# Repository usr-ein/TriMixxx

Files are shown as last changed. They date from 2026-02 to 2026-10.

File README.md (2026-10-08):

# TriMixxx

A custom DJ media player — a CDJ-style deck — built from scratch around a Raspberry Pi, designed to run [Mixxx](https://mixxx.org/) DJ software. It reuses an original Pioneer CDJ's buttons and jog wheel behind custom PCBs and a 3D-printed chassis for an authentic DJ feel, and reads Rekordbox-formatted USB sticks — no laptop required.

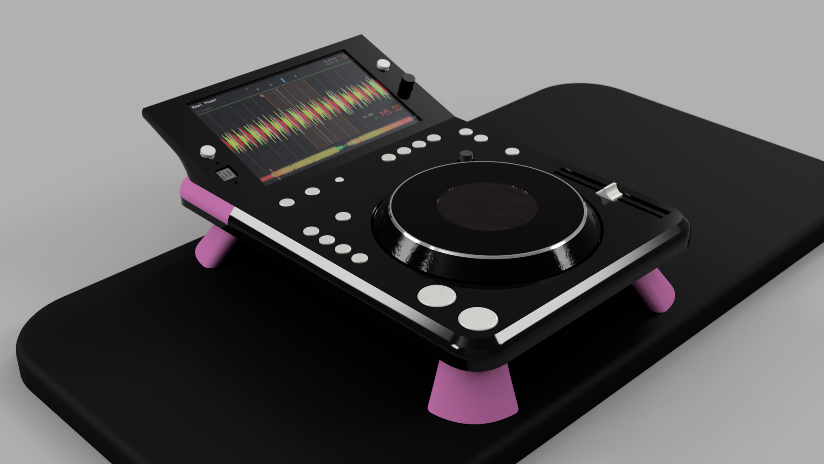
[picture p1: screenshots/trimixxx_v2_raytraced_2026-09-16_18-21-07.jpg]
TriMixxx V2 — raytraced render of the chassis

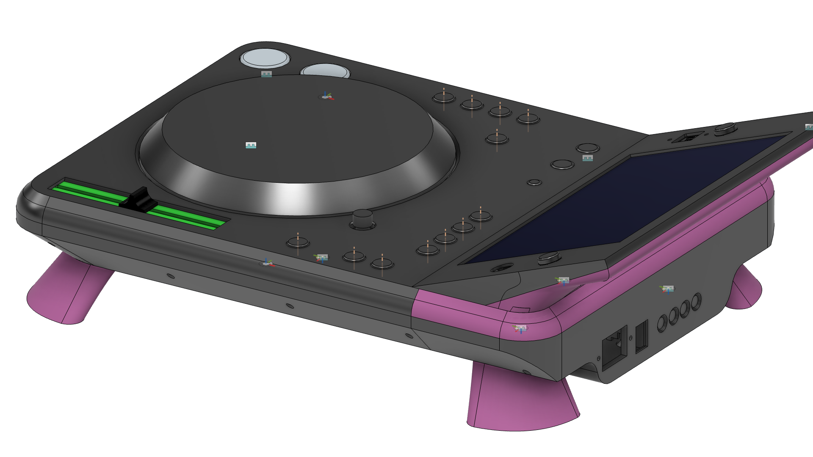
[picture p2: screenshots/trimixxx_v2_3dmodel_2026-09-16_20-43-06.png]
TriMixxx V2 — the Fusion 360 model behind it

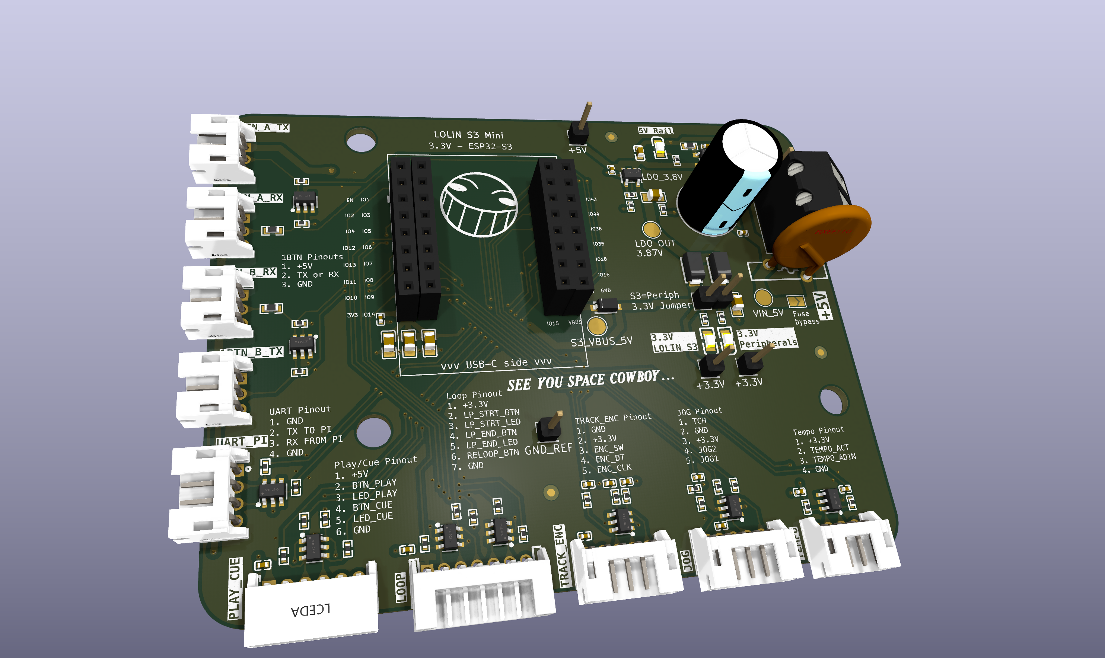
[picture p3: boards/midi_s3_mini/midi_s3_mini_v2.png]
midi_s3_mini v2 — the controller board inside


### The screen

The 1024×600 touchscreen runs a purpose-built Mixxx skin (`mixxx_config/TriMixxx_skin`). There is no mouse and no laptop: every control is either on the deck or under a thumb, so the UI is built around big targets and the browse encoder rather than around pointer precision.

| Playing | Browsing |
|---|---|
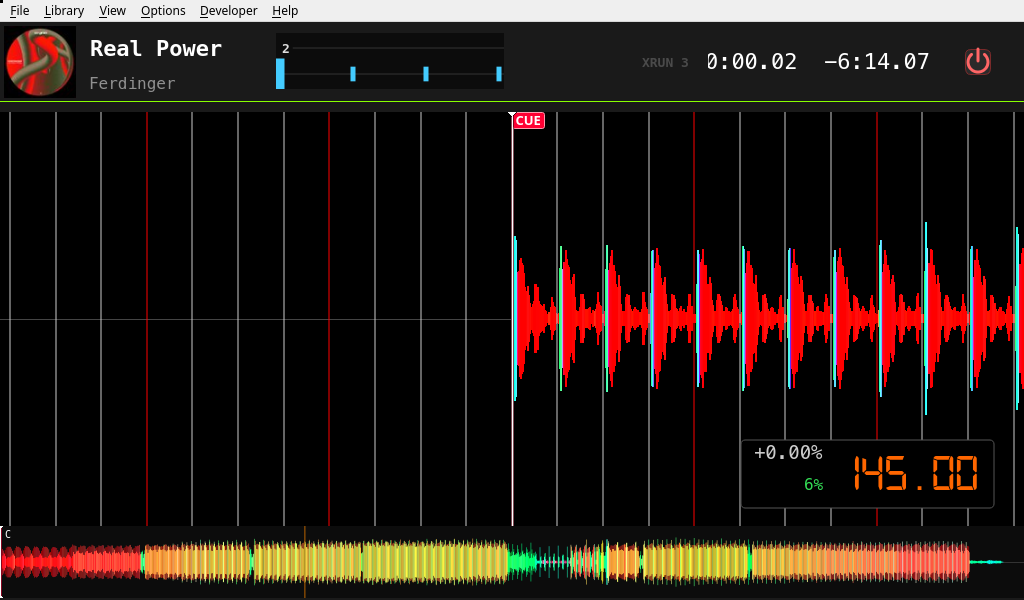
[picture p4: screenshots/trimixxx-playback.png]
Playback view
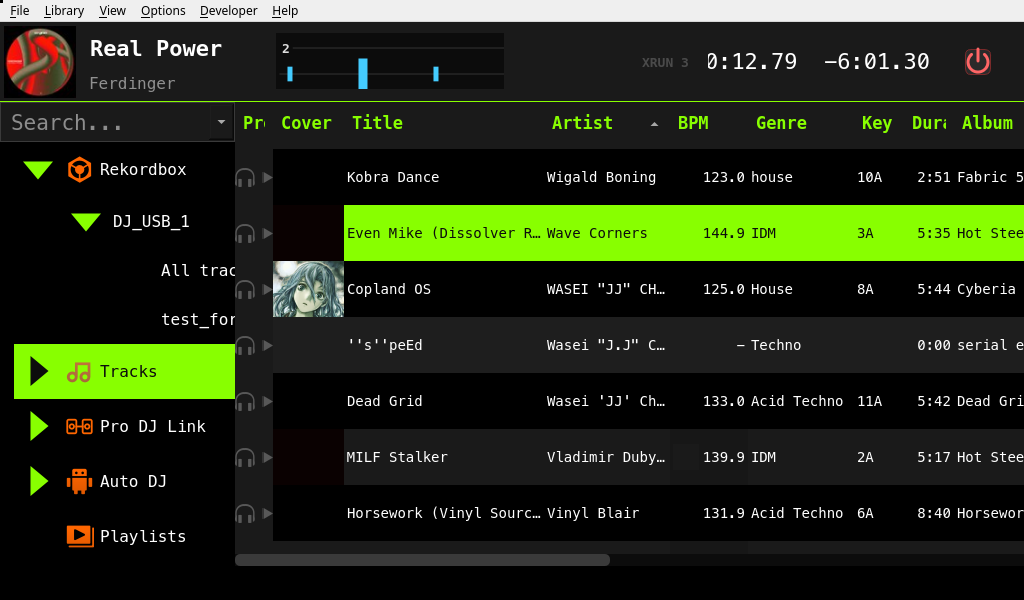
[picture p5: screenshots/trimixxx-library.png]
Library view
|  |  |
| Scrolling waveform with the beat grid, red downbeats anchored on the intro cue, and the whole-track overview underneath. Tempo and pitch sit bottom-right; the header carries artwork, title/artist, the phase meter, elapsed/remaining and the underrun counter. | Rekordbox USBs, the local collection and the Pro DJ Link players lead the menu — the three a deck actually reaches for. The left column sizes itself to its content and follows the selection, and neither pane has a scrollbar: the encoder scrolls them. |

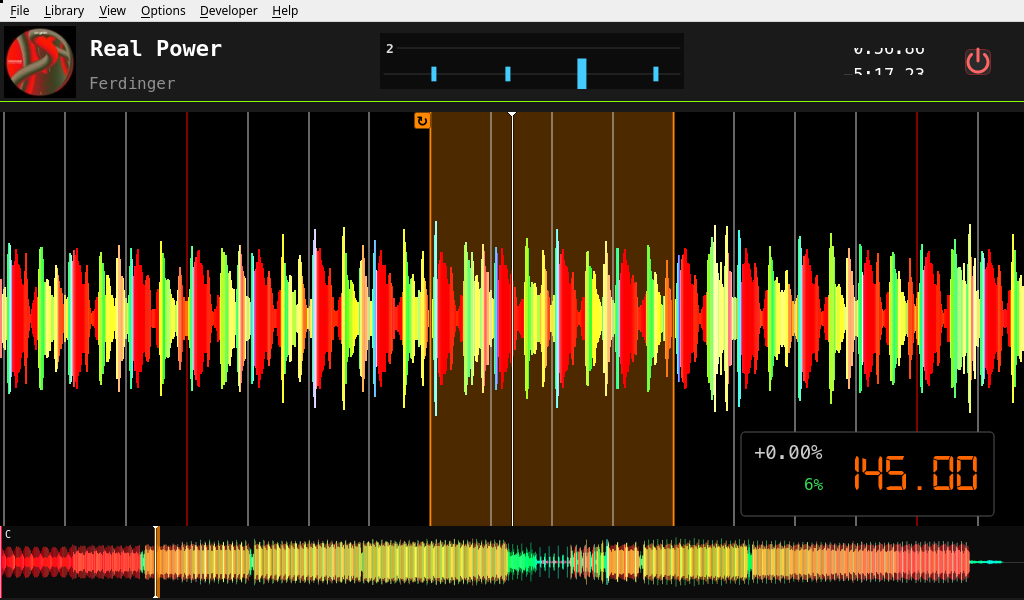
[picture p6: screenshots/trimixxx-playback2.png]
Loop over the waveform


An active loop, set from the deck's hardware loop-in/out buttons, drawn as an amber window over the waveform. Nothing sits below it — the transport, hotcues, loop sizing and tempo range are all physical controls, so the screen gives that space back to the waveform.

## What is this?

TriMixxx replaces the internals of a Pioneer CDJ with modern, open-source-friendly hardware while keeping the physical controls that DJs know and love. Plug in a Rekordbox-formatted USB stick, and you're ready to mix.

Where the CDJ's original main board did everything, TriMixxx today is a **small distributed system**: a Raspberry Pi runs a patched Mixxx behind a custom CDJ-style skin, an ESP32-S3 acts as the controller brain that reads every physical control and speaks MIDI, and a swarm of tiny satellite boards handle the buttons and the LED rings. They all talk over plain TTL UART.

It is a working deck, not a plan: the Pi boots straight into Mixxx, the USB stick automounts, the S3's controls drive it, and Mixxx's feedback drives the LEDs back. Alongside that, `prolinks-compat/` has reverse-engineered Pioneer's ProLink protocol far enough that a real CDJ-2000NXS browses and plays tracks served by this project.

## How we got here (a short history)

This project has been through several complete redesigns. It's worth keeping the lineage straight:

1. **One board to rule them all.** The first idea was a single monolithic PCB carrying *everything*: a Raspberry Pi CM5, a TI PCM5242 I²S DAC with RCA + headphone outputs, USB-C PD power (CH224K + SY8368AQQC buck), dual micro-HDMI, the USB stick ports, and an **ATmega32U4** presenting the CDJ's buttons/jog/fader to the Pi as a USB-MIDI device — all on one board. It was fully routed (`screenshots/CDJ-MainBoard-v1_fully_routed.png`, and the `*_2026-02-17.png` schematic captures) but never became the working unit; cramming compute, audio, power, and a controller onto one board made every revision expensive and every mistake fatal.

2. **Breaking it apart.** The controller was split out onto its own board. `boards/midi-laser-pcb` was the first standalone MIDI-controller PCB — it was fabricated, then abandoned in favour of a cleaner design.

3. **Where it is now.** `boards/midi_s3_mini` is the current controller board (fabricated), hosting a **LOLIN S3 Mini (ESP32-S3)**. The audio DAC and power delivery are no longer TriMixxx's job — a Raspberry Pi handles Mixxx and audio directly, and the S3 is purely the controller brain. The controls are spread across small purpose-built satellite boards, all of them already fabricated.

The old monolithic design is preserved in this README's history and in `screenshots/` as a record of the road not taken.

## Current architecture

```mermaid
flowchart LR
    subgraph PiBox["Raspberry Pi (deck)"]
        Mixxx["Mixxx (patched fork)<br/>+ TriMixxx skin"]
        Tty["ttymidi<br/>trimixxx-bridge.service"]
        Daemon["trimixxx-launchd<br/>(launch manager +<br/>SysEx to the OS)"]
        Usb["dj-usb automount<br/>/media/DJ_USB_*"]
        Doom["Doom (1993)<br/>hold PLAY at boot"]
        Keys["trimixxx-deckkeys<br/>MIDI -> /dev/uinput"]
    end

    S3["midi_s3_mini<br/>LOLIN S3 Mini / ESP32-S3<br/>(controller brain)"]
    RingA["OneButton ring A<br/>CH32V003 nodes<br/>button + 2xWS2812 each"]
    RingB["OneButton ring B<br/>CH32V003 nodes"]
    PlayCue["play_cue_btn<br/>Play / Cue + LEDs"]
    Loop["loop_btn<br/>Loop In/Out/Reloop + LEDs"]
    Jog["Jog wheel<br/>quadrature + touch"]
    CDJ["Real CDJs<br/>(ProLink, Ethernet)"]

    Mixxx <--> Tty
    Mixxx <-->|SysEx| Daemon
    Usb --> Daemon
    Daemon -->|"picks the boot mode"| Mixxx
    Daemon -->|"picks the boot mode"| Doom
    Daemon --> Keys
    Tty -->|"deck buttons"| Daemon
    Tty -->|"deck buttons"| Keys
    Keys -->|"virtual keyboard + mouse"| Doom
    Tty <-->|"UART - raw MIDI - 3.3V"| S3
    S3 <-->|"UART1 - OneButton ring - 5V"| RingA
    S3 <-->|"UART2 - OneButton ring - 5V"| RingB
    S3 --> PlayCue
    S3 --> Loop
    Jog --> S3
    Mixxx -.->|"prolinks-compat (research)"| CDJ
```

- **Raspberry Pi 4B (4 GB)** runs Mixxx — specifically [our own fork](https://github.com/usr-ein/mixxx) (the `mixxx/` submodule), branched off the 2.5.6 tag and carrying deck-specific patches. [`ttymidi`](https://github.com/usr-ein/ttymidi) turns the UART link into an ALSA MIDI device, so Mixxx sees TriMixxx as a standard MIDI controller. That link is 3.3 V on both ends (Pi GPIO ↔ S3), so no level shifting is needed.
- **midi_s3_mini (ESP32-S3)** is the controller brain. It reads every physical control, translates it to MIDI for the Pi, and drives LEDs from the MIDI feedback Mixxx sends back. It runs `firmwares/trimixxx-midi`.
- **Two OneButton rings** hang off the S3, one per UART (A on UART1, B on UART2). Each is a daisy chain of up to 50 CH32V003 nodes, every node carrying one button and two WS2812 LEDs. Nodes enumerate themselves at boot, so a ring self-sizes to however many boards are actually populated (7 and 6 today). See [The OneButton Protocol](#the-onebutton-protocol) below.
- **play_cue_btn** and **loop_btn** are dumb button+LED satellite boards (no MCU) wired to the S3.
- The **jog wheel** (optical quadrature encoder + capacitive touch) wires directly into the S3, decoded by the ESP32's hardware pulse counter (PCNT).

### Signal chain: pressing Play

A worked example of what happens end-to-end, from copper to Mixxx. Every other button on the deck follows the same path.

**Press.** The switch closes and shorts the on-board 100 nF debounce cap to ground, so the GPIO (held high by the S3's internal pull-up) falls low over the RC's time constant — the buttons are active-low. `buttonPollTask` on core 1 samples the pin every `BTN_POLL_MS` = 2 ms and needs `DEBOUNCE` = 3 consecutive stable samples before it accepts the edge, so the RC's slow ramp and any contact bounce are both ignored (~6 ms to accept). Polling is deliberate here rather than an edge interrupt, which slow RC edges tend to upset on the ESP32. On accepting the edge, `poll()` updates the debounced `level` and sets a **sticky press latch**, so the press can't be missed even if the main loop stalls. The main loop (`CTRL_POLL_MS` = 2 ms) calls `playCue.pressed()`, which consumes the latch, and `btnToNote()` hands it to `PiLink`, which writes a Note-On (note `0x3C`, velocity 127) to UART0 at 115200 baud. `ttymidi` on the Pi turns those raw MIDI bytes into an ALSA MIDI event; Mixxx matches `0x3C` in `TriMixxx.midi.xml` and calls `TriMixxx.play`, which toggles the deck's `play` control.

**Held.** Nothing repeats. The sticky latch fires exactly once per press; `btnToNote` keeps a `pending` flag so it knows a Note-Off is still owed. Meanwhile Mixxx sends `play_indicator` back on the same note `0x3C` — `pi.poll()` runs every main-loop pass (no 2 ms gate, for the lowest LED latency) and drives the button's LED from that feedback, so the LED reflects Mixxx's actual state rather than the button's.

**Release.** The switch opens, the pull-up recharges the cap through the RC, and the pin rises. The poll task sees 3 stable high samples, clears `level`, and the next main-loop pass sees `pending && !held` and sends the Note-Off. Mixxx's `TriMixxx.play` ignores value 0, so the release is a no-op there — it just keeps the On/Off pairing well-formed on the wire.

### MIDI map

All MIDI addresses live in one place — `firmwares/trimixxx-midi/lib/PiLink/MidiMap.hpp` — and the Mixxx mapping (`mixxx_config/TriMixxx.midi.xml`) matches them exactly. One deck (v1) → MIDI channel 1.

| Control | MIDI | Mixxx |
|---|---|---|
| Ring A pads (node *i*) | Note `0x00 + i` | Tempo range, keylock, 8/4-beat loops, loop double/halve, back |
| Ring B pads (node *i*) | Note `0x43 + i` | Hotcues 1–4, slip, key-sync indicator |
| Play / Cue | Notes `0x3C` / `0x3D` | `play` (toggle) / `cue_default` |
| Loop In / Out / Reloop | Notes `0x3E` / `0x3F` / `0x40` | `loop_in` / `loop_out` / `reloop_toggle` |
| Track encoder | Note `0x41` (press) + CC `0x10` (relative: 1=up, 127=down) | Browse + load |
| Jog wheel | Note `0x42` (touch/scratch) + CC `0x11` (relative ticks) | Scratch when touched, pitch bend otherwise |
| Tempo fader | CC `0x12` MSB + CC `0x32` LSB (14-bit absolute 0..16383, 8192 = center) | `rate` |

Both pad ranges reserve 50 notes even though fewer nodes are populated today, so growing a ring never renumbers anything.

The tempo fader follows the standard MIDI 14-bit convention — the LSB rides on `MSB + 32` (18 + 32 = 50 = `0x32`) — and Mixxx binds the pair to `[Channel1] rate` with `<fourteen-bit-msb/>` / `<fourteen-bit-lsb/>`. The extra resolution is worth the second CC: a single 7-bit CC would quantise the whole pitch range to 128 steps. The fader is read ratiometrically (wiper minus a live center-tap reference) so the center detent lands on 8192 without calibration.

LED feedback comes back on the same notes. A Note-On velocity only sets *white* brightness, so full RGB travels as SysEx instead — `F0 7D <cmd> <node> <colour nibbles> F7`, with each 8-bit channel split into two data bytes so a 7-bit SysEx payload can still express 0..255 per channel (`0x01` = ring A, `0x03` = ring B). `0x02` reboots the S3, and requires the magic `"RST"` so a stray SysEx can't reset the deck mid-set.

## Boards

All KiCad projects live under `boards/`. Every board below has been fabricated.

| Board | Role | MCU | Status |
|---|---|---|---|
| `midi_s3_mini` | Controller brain: reads all controls, MIDI bridge to the Pi, drives LEDs, jog-wheel input | LOLIN S3 Mini (ESP32-S3) | **Current** |
| `one_button` | Ring node: one button + 2× WS2812, cut-through UART relay. Every node is identical. | CH32V003F4U6 | **Current** |
| `play_cue_btn` | Play + Cue buttons with LEDs (driven by the S3) | none | **Current** |
| `loop_btn` | Loop In/Out/Reloop buttons with LEDs (driven by the S3) | none | **Current** |
| `midi-laser-pcb` | First standalone MIDI-controller board | — | Fabricated, **abandoned** (superseded by `midi_s3_mini`) |

## Firmwares

| Firmware | Runs on | What it is |
|---|---|---|
| `trimixxx-midi` | midi_s3_mini (ESP32-S3) | The master. PlatformIO/Arduino. Reads both OneButton rings + jog wheel + deck controls and bridges them to the Pi as MIDI. Master of both rings. |
| `onebutton` | one_button ring nodes (CH32V003) | Bare-metal [ch32fun](https://github.com/cnlohr/ch32fun). `onebutton_node` (the identical binary every ring node runs) and `onebutton_selftest` (single-board bring-up). |
| `swio-adapter` | A spare Pro Micro | Turns an Arduino into a `minichlink` SWIO programmer for flashing the CH32V003 nodes — no dedicated programmer needed. Git submodule. |
| `ArduinoMIDI` | (historical) | Early ATmega-based MIDI + jog-wheel test sketches from the monolithic-board era. |

Every driver in `trimixxx-midi` is written and live: both rings, jog wheel, tempo fader, track encoder, play/cue board and loop board. A single `DECK_DEBUG` switch at the top of `main.cpp` swaps the MIDI loop for each module's own self-test.

## The OneButton Protocol

The button rings run a purpose-built **cut-through UART ring protocol**. A single fixed-length frame, authored by the S3 master, circulates once around the ring and returns carrying every node's button state; LED colours travel outward on the same frame. Each node forwards bytes as they arrive, editing only the bytes in its own slot, so latency scales as `frame_time + N·byte_time` rather than `N·frame_time`. Node addresses are assigned positionally at boot, so all nodes run an identical binary with no per-unit configuration.

Full wire format, timing, and failure model: **[`firmwares/onebutton/onebutton-protocol.md`](firmwares/onebutton/onebutton-protocol.md)**.

## The Pi side

The deck's software is split into four pieces, each with its own README:

| Piece | What it is |
|---|---|
| `mixxx/` (submodule) | **Our Mixxx fork.** Forked at 2.5.6, carrying deck patches: downbeat highlighting in the waveform (`DownbeatColor` skin node), Rekordbox beat-grid phase preserved via the intro cue, and a `[Rekordbox], refresh` control so a stick mounted mid-set can be picked up from a script. Built for arm64 in Docker and installed over SSH. |
| `mixxx_config/` | Everything under `~/.mixxx`: the controller mapping (`TriMixxx.midi.xml` + `.scripts.js`), the `PiMidiDaemon` mapping, `soundconfig.xml`, and `TriMixxx_skin/` — a single-deck CDJ-style skin for the 1024×600 touchscreen. Its deploy step, `pi-qemu/deploy/005_config.sh`, validates every XML *before* anything leaves the machine, because Qt silently falls back to the default skin on a malformed one. |
| `pi_config/` | The system side: `trimixxx-bridge.service` (ttymidi, ordered before Mixxx so the MIDI port exists when Mixxx enumerates devices), `cpu-governor.service` (the `performance` governor — `ondemand` was the measured cause of xruns while scratching), the session entry points (`bash_profile`, `xinitrc`) that start whichever app the launch manager chose, and `dj-usb/` (udev + systemd read-only automount of DJ sticks). |
| `trimixxx-launcher/` | Two small Go daemons. **`trimixxx-launchd`** does the things Mixxx cannot — its script engine has no file, process or network access, so **MIDI is the only channel out**, and the daemon takes SysEx commands (shutdown, reboot, switch mode) and reports events back (a DJ stick was mounted). It is also the **launch manager**: it reads the deck's own buttons at boot and decides what the deck becomes. **`trimixxx-deckkeys`** replays the deck's MIDI into `/dev/uinput` as a virtual keyboard and mouse. Both ship as fully static musl binaries, so there is nothing to install on the Pi. |
| `doom/` | **The deck plays DOOM (1993).** Hold PLAY while it boots. The jog wheel turns, the tempo fader is the throttle, ring A is the seven weapons. Doom itself is a stock `chocolate-doom` — the controls arrive as a virtual keyboard and mouse, so there is no engine fork here to maintain. |

## ProLink compatibility

`prolinks-compat/` reverse-engineers Pioneer's proprietary **CDJ ProLink** Ethernet protocol so TriMixxx can share libraries with real CDJs on the same network. It is a substantial subproject in its own right — a Python proof-of-concept plus a written specification — and both directions now work against real hardware (two CDJ-2000NXS):

- **Consume:** discover players passively, then pull a deck's `export.pdb` over NFS and list its tracks. The fetched database is byte-identical to the same file read off the physically ejected stick.
- **Serve:** a real CDJ-2000NXS sees us on its LINK screen, browses all eleven categories with drill-downs, sorting, search and harmonic key matching, and **loads and plays tracks** (MP3, AAC, WAV, AIFF) with artwork, hot cues and both waveforms. The last browse session was 568 requests with zero errors.

The protocol as observed is written up in [`prolinks-compat/docs/PROTOCOL.md`](prolinks-compat/docs/PROTOCOL.md), with the evidence behind every claim in `docs/FINDINGS.md` and current state in `STATUS.md`. The end goal is to port the validated approach into Mixxx (C++/Qt) and upstream it.

## Chassis

Designed in Fusion 360 to fit the original CDJ form factor — a custom top panel with cutouts for the jog wheel, buttons, and connectors, plus a bottom tray. `ref_sizes/` holds the measured references (CDJ-1000MK3 / 2000NXS2 / 3000 dimensions, jog wheel, screen) the design is built from.

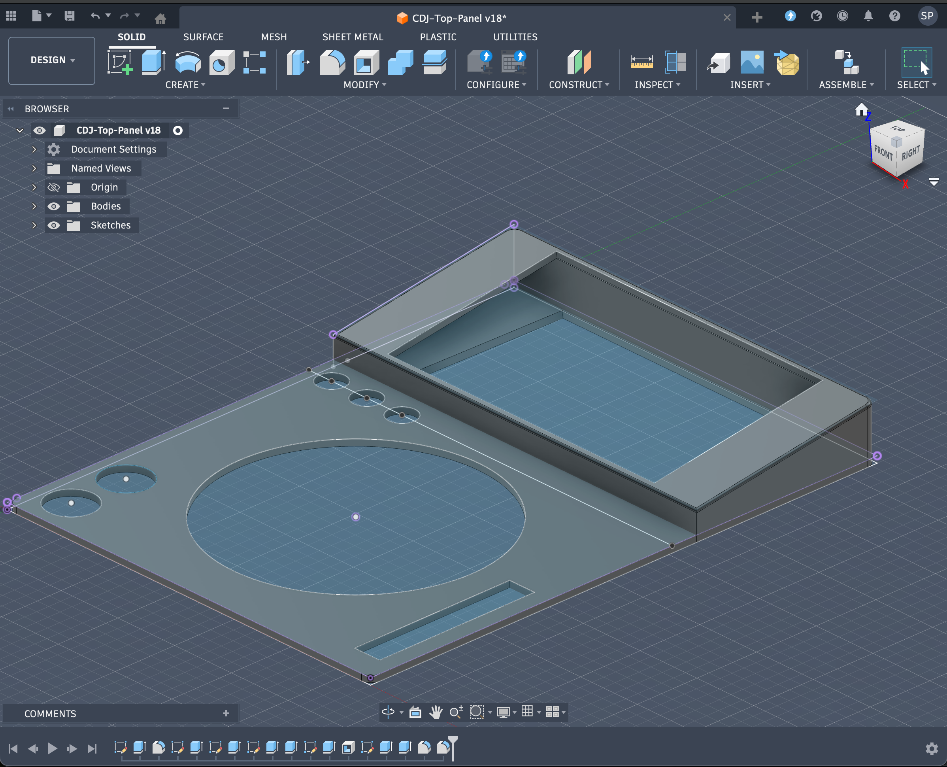
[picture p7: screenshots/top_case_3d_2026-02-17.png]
Top case 3D render


## Repository structure

```
boards/                     KiCad PCB projects
├── midi_s3_mini/               Current controller board (ESP32-S3)
├── one_button/                 OneButton ring node (CH32V003)
├── play_cue_btn/               Play + Cue buttons
├── loop_btn/                   Loop buttons
└── midi-laser-pcb/             Abandoned first controller board

firmwares/                  Embedded firmware
├── trimixxx-midi/              S3 master (PlatformIO / Arduino)
├── onebutton/                  Ring node + selftest (ch32fun)
├── swio-adapter/               CH32V003 SWIO programmer (submodule)
└── ArduinoMIDI/                Historical ATmega sketches

mixxx/                      Our Mixxx fork -- the build the deck runs (submodule)
mixxx_config/               ~/.mixxx: mapping, scripts, skin, sound config
pi_config/                  Pi system config: systemd units, udev, USB automount
trimixxx-launcher/          Go daemons: boot-mode launch manager, SysEx <-> OS,
                            and the MIDI -> virtual keyboard/mouse bridge
doom/                       DOOM (1993) on the deck: WAD, engine config, wrapper

prolinks-compat/            Pioneer ProLink protocol research + Python PoC
ch32fun/                    ch32fun toolkit (submodule)
handmade_pcb/               Hand-etched PCB experiments
datasheet/                  Datasheets for the parts used
ref_sizes/                  Measured CDJ dimensions the chassis is built from
screenshots/                Renders + schematics (incl. the monolithic-board history)
```

## Tools used

- **KiCad** — schematic capture and PCB layout
- **PlatformIO** + **Arduino** — ESP32-S3 firmware
- **ch32fun** — bare-metal CH32V003 firmware and `minichlink` flashing
- **Fusion 360** — mechanical design
- **JLCPCB** — PCB fabrication and assembly
- **Go**, **Python** (`uv`) — Pi daemon and ProLink proof-of-concept

## Trademarks and affiliation

TriMixxx is an independent project with **no affiliation with, sponsorship by, or endorsement from AlphaTheta Corporation** (formerly Pioneer DJ) or the Mixxx project.

**CDJ**, **rekordbox**, **Pro DJ Link**, **DJM**, **NXS/nexus** and **Pioneer DJ** are trademarks of AlphaTheta Corporation. They appear here only to refer to that company's own products — which hardware this project interoperates with, which protocol it speaks, and which units the chassis was measured against. **Mixxx** is the name of the independent open-source project at [mixxx.org](https://mixxx.org/); "TriMixxx" is this project's own name and is not a Mixxx project product.

The ProLink work in `prolinks-compat/` is reverse engineering for **interoperability**, from observation of network traffic between devices the author owns. Protocol facts are not copyrightable, and no code from any reference implementation is copied — see `prolinks-compat/research/10` for the working discipline.

## License

Copyright (C) 2026 Samuel Prevost and contributors.

TriMixxx is free software: you can redistribute it and/or modify it under the terms of the **GNU General Public License version 3** or (at your option) any later version. The full text is in [`LICENSE`](LICENSE). This covers everything in the repository — firmware, host software, hardware sources and documentation alike — except:

- **`prolinks-compat/`**, which is **GPLv2-or-later** on purpose, so it stays compatible with Mixxx and can be upstreamed. GPLv2-or-later code may be used under GPLv3, so this is compatible with the rest of the project; see `prolinks-compat/LICENSE`.
- **Submodules** (`mixxx/`, `ch32fun/`, `firmwares/swio-adapter/`, `mixxx_config/ttymidi/`, the Keebio libraries), which keep their own upstream licenses.

---

## Appendix: the monolithic board (historical)

The original single-board design is no longer built, but its details are recorded here for posterity. It centred on a **Raspberry Pi CM5** (dual DF40 100-pin connectors), a **TI PCM5242** I²S DAC feeding RCA + 6.35 mm + 3.5 mm outputs, an **ATmega32U4** USB-MIDI controller reading all the CDJ controls, USB-C PD power (**CH224K** negotiating 20 V @ 3 A, **SY8368AQQC** buck to 5 V, **AP2112K** LDOs), dual micro-HDMI, gigabit Ethernet, and the USB stick ports (**HD3SS3220**/**HD3SS3212** muxing, **USBLC6-2SC6** ESD protection) — roughly 160 components on one PCB.

### Schematics

| Sheet | File |
|---|---|
| Audio outputs (DAC, RCA, headphones) | `screenshots/audio_2026-02-17.png` |
| MIDI / ATmega controller | `screenshots/midi_arduino_2026-02-17.png` |
| Power delivery (USB-C PD, buck, LDOs) | `screenshots/power_delivery_2026-02-17.png` |
| USB ports (mux, ESD) | `screenshots/usb_2026-02-17.png` |
| Fully routed PCB | `screenshots/CDJ-MainBoard-v1_fully_routed.png` |

### SPICE simulations

- DAC output (PCM5242): `screenshots/dac_spice.png`
- Buck converter (SY8368AQQC): `screenshots/buck_converter_spice.png`

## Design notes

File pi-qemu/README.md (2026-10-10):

# pi-qemu: the TriMixxx tool

`pi-qemu` is the one tool for TriMixxx decks, emulated and real:

- **Emulated decks.** It runs a deck's SD card on an emulated Raspberry Pi 4
  (QEMU's `raspi4b`, accelerated by Apple's Hypervisor framework), booting the
  real Raspberry Pi OS card with the real deck software: Mixxx, ttymidi, the
  launcher and the panel session. You get the Pi's 1280x800 screen in a window
  (click and drag like the touchscreen), and a control panel standing in for
  the deck's S3 board. The panel sends MIDI to the Pi's UART exactly as the
  real S3 does.
- **Any deck.** It drives a deck from the command line, emulated or real: its
  controls, its touchscreen, its screen, Mixxx's recorder, a shell. Scripts
  and AI agents use the same commands.
- **Deploying.** It puts the repo's code onto a deck, step by numbered step
  (`deploy/NNN_*.sh`).
- **Cards and releases.** It builds a deck's card from stock Raspberry Pi OS,
  and the locked A/B release card with its updates over the air.

The emulated deck is called **trimixxx0**: a virtual trimixxx2, wired by
`mixxx_config/units/trimixxx0.json`. Why things are built the way they are is
in [PLAN.md](PLAN.md).

```sh
pi-qemu help                  # the groups: deck, link, image, release, worktree
pi-qemu deck                  # a group's verbs
pi-qemu deck up --help        # one verb, in full
```

Every verb that acts on a deck names it, as its **TARGET**: an emulated
deck's NAME (`pi-qemu deck list`), or `--host ALIAS` for a real deck by its
ssh alias. There is no default deck: nothing reaches a real deck unless it is
named.

A real deck on the Mac's switch is reached over Ethernet too, much faster
than over Wi-Fi: `pi-qemu deck alias --host trimixxx-pi` writes
`trimixxx-pi-eth` into `~/.ssh/config`, by its eth0's IPv6 link-local
address through the Mac's wired interface, and `--host trimixxx-pi-eth`
then takes that link.

## What is in here

| Path | What it is |
|---|---|
| `build.sh` | builds the pinned, patched QEMU and `pi-qemu`, and puts `pi-qemu` on PATH |
| `app/` | `pi-qemu` itself (C++/Qt), one directory per part under `app/src/`: `board/` (the emulated Pi: the firmware step, QEMU, USB sticks, its link, its control socket), `s3/` (the deck's controller: MIDI both ways, the wiring), `ui/` (the windows), `decks/` (a deck to act on, emulated or real), `pipeline/` (deploying, image builds, releases), `cdj/` (emulated CDJs), `worktree/`, `cli/` (the command line), `util/`; and `tests/` (ctest) |
| `app/icons/` | its icon: `trimixxx.svg`, and the `.ico` compiled in, made from it by `make-ico.py` |
| `qemu/trimixxx-patches.py` | our patches to QEMU, applied by `build.sh` |
| `deploy/` | the deploy steps, `NNN_name.sh` and `NNN_name.pi.sh`, and their contract, `lib.sh` |
| `image/` | the stock card's pin (`stock.env`), its first-boot seed (`user-data.in`, `network-config`), and `secrets.env` (gitignored; `secrets.example.env` is the template) |
| `release/` | the release container (`Dockerfile`, `container.sh`) and the release card's parts |
| `.cache/` (gitignored) | images, built cards, the golden snapshot, decks' identities, USB stick images |

## Setting up a laptop

On an Apple Silicon Mac:

```sh
brew install qemu mtools cmake ninja qt python@3.12 dtc   # QEMU's deps, mtools for FAT, Qt for the app
pi-qemu/build.sh             # ~10 min the first time: QEMU 11.1.0 + patches, dtmerge, then pi-qemu
cp pi-qemu/image/secrets.example.env pi-qemu/image/secrets.env   # then set SAM1902_PASSWORD
```

`build.sh` puts `pi-qemu` on PATH as `~/.local/bin/pi-qemu` (from the main
checkout; a worktree's own build is run by its path). `build.sh app` builds
`pi-qemu` alone, with its tests.

You also need Docker Desktop running (the deck's arm64 binaries are Docker
builds) and the ssh key the cards trust: `~/.ssh/no_pass/rsa_sam`, else
`~/.ssh/with_pass/rsa_sam` (in the agent: `ssh-add`), or `SSH_KEY=` pointing
at another one. Its public half goes onto the card at build time.

Then build the card. Most of the time goes to apt and the Docker builds of
the deck's binaries; the base stage is cached for later runs:

```sh
pi-qemu image build              # -> pi-qemu/.cache/build/trimixxx0.img (+ the golden snapshot)
```

A window shows the build as it goes: its steps, a progress bar and the log
(`pi-qemu build-log pi-qemu/.cache/build/trimixxx0.log`, the log it writes).
`release build` opens one too, for the whole release. `--no-window` (or
`BUILD_WINDOW=0`) opens none.

## Running your deck

Your own deck is an emulated deck like any other, with windows:

```sh
pi-qemu deck up sam --window     # restored from the golden snapshot in ~3 s
pi-qemu deck ssh sam
```

Two windows open: the Pi's screen and the control panel. Log in on the
console as `sam1902` with the password from `image/secrets.env`, or use
`deck ssh`. `deck up sam --from CARD` boots a card of your own instead.

**Sound is off unless you ask for it.** `pi-qemu deck up sam --window --
--audio speakers` plays the deck's output on the Mac. `-- --audio
wav:/abs/path/out.wav` records it to a file instead, which is how to check
audio without hearing it. Whatever follows `--` goes to `pi-qemu run`, the
board itself (`pi-qemu run --help` lists its options):

| Option | |
|---|---|
| `--audio none\|speakers\|wav:FILE` | the deck's sound output (default none: silent) |
| `--display window\|vnc\|none` | the Pi's screen; screenshots work in every mode |
| `--stick FILE.img` | a USB stick image plugged in from power-on |
| `--deck NAME` | whose wiring the panel follows (`mixxx_config/units/NAME.json`) |
| `--ssh PORT` | the Pi's ssh on 127.0.0.1:PORT (default: a free port) |
| `--link NET` | eth0 on the link NET, shared with other boards (`deck up --link` sets it, and `--name`, `--mac`) |

### The panel

- **Controls tab**: the deck's controls, laid out as on trimixxx2.
  - **Pads:** loop and loop-length pads across the top; SLIP, SORT and the four
    hot cues left of the platter; CUE and PLAY / PAUSE under them.
  - **Right of the platter:** BACK, the browse encoder (drag up or down to turn,
    click to push), TEMPO RANGE, MASTER TEMPO and the tempo fader.
  - **Jog wheel:** drag the inner disc to scratch (touch), drag the rim to
    bend, or scroll on it to nudge.
  - **Pad behaviour:** shift-click a pad to latch it down. The lamps and pads
    light from what Mixxx sends back.
- **S3, power, USB sticks tab**:
  - the S3 link light;
  - Power on, and Pull the plug (no shutdown, like the mains switch);
  - the sound mode;
  - every USB storage device on the Mac, and every image and `.stick` file
    in `.cache/sticks/`, each with Insert / Unplug (two slots, read-only).

### Driving it from the command line

Everything the panel does, `pi-qemu deck` does too, on any deck: an emulated
one through its virtual S3, a real one (`--host ALIAS`) straight into the MIDI
port Mixxx opened for the deck's controller. The bytes are the same either
way, on the deck's wiring, so they run the real mapping and scripts.

```sh
pi-qemu deck press sam play          # press and release (80 ms; `press sam cue 500` holds it)
pi-qemu deck down sam cue; pi-qemu deck up sam cue
pi-qemu deck jog sam 3240            # a quarter turn clockwise (12960 ticks per turn)
pi-qemu deck touch sam on            # the platter's touch sensor, for scratching
pi-qemu deck browse sam -3           # the track encoder; + is up
pi-qemu deck tempo sam center        # the fader, 0..16383; 8192 (center) is the middle
pi-qemu deck midi sam 90 3C 7F       # raw bytes, as the S3's
pi-qemu deck shot sam shot.png       # the screen: QEMU's own (emulated), scrot (real)
pi-qemu deck tap sam 640 400         # the touchscreen, with xdotool: also longpress, swipe, flick, key, where
pi-qemu deck record sam 10 mix.wav   # Mixxx's own recording of its main mix, fetched
```

Control names: `tempo-range keylock loop8 loop4 loop-double loop-halve back
hotcue1..4 slip sort play cue loop-in loop-out reloop push jog-touch`. They
follow the deck's wiring, so `press sam hotcue1` sends whatever note
trimixxx0's hot cue 1 is on.

An emulated deck also has its board:

```sh
pi-qemu deck leds sam                # what the deck's lights show now, as JSON
pi-qemu deck stick sam list          # stick sam insert SAM3 | stick sam unplug SAM3
pi-qemu deck status sam              # the Pi, the S3 link, its wiring, its ports
pi-qemu deck power sam off           # pull the plug; power sam on
pi-qemu deck save sam FILE           # the whole machine to FILE, then off
pi-qemu deck console sam 'ip -br a'  # over the serial console, when ssh is down
```

### Where things are

An emulated deck lives in `~/.pi-qemu/instances/NAME/` (kept short on
purpose: macOS caps unix socket paths at 104 bytes): `card.img`, `state`
while it is suspended, `ssh_config` and `bin/` (plain `ssh`/`scp` reaching it
as NAME and as `deck`: `eval "$(pi-qemu deck env NAME)"`), `pi-qemu.log`, and
the board's run directory, `card.run/`:
- `qemu.cmd`: the exact QEMU command, to rerun by hand;
- `qemu.log`, and `qemu.pid` while it runs;
- `console.log`: the Pi's serial console, from the first kernel line;
- `ssh.port`;
- the sockets `control.sock` (what `pi-qemu deck` talks to), `console.sock`
  (the Pi's console: `nc -U console.sock`), `qmp.sock` and `qmp-fd.sock`
  (QEMU's monitor) and `s3.sock` (the S3's UART).

A deck on a link also has `link` in its directory (the link's name), and its
socket on the link is `~/.pi-qemu/links/NET/NAME.sock`.

Inside the Pi:
- Mixxx logs to `/tmp/mixxx/mixxx.log` and `/tmp/mixxx/stderr.log`; the
  previous run's are kept as `.1`;
- its settings are in `~/.mixxx/`;
- the launcher's log is `journalctl -u trimixxx-launchd`.

## Several decks at once

Emulated decks run side by side, for people, agents and tests. Each one has
its own copy of the card, ssh port, ssh alias and control socket. They are
headless and silent unless asked.

```sh
pi-qemu deck up mine                 # restored from the golden snapshot in ~3 s
pi-qemu deck ssh mine 'pgrep -a mixxx'
pi-qemu deck deploy mine config      # this checkout's code onto it; waits for the new Mixxx
pi-qemu deck ready mine              # wait until Mixxx runs, its sound and controller open
pi-qemu deck stop mine               # suspend: saved, next `up` ~3 s
pi-qemu deck rm mine                 # gone, card and all
pi-qemu deck list
```

`up --window` shows its screen and panel. `up --boot` boots it instead of
restoring it (~7 s to ssh). `up --fresh` starts again from the golden
snapshot, and `up --from CARD` boots a card of your own, of any size: the
instance's copy is rounded up to the power of two QEMU's SD card needs, and
stays sparse. `down` powers it off cleanly, `kill` pulls the plug (its QEMU
too, even if pi-qemu was killed outright).

The emulated board starts as a Pi 4 does, measured on a real one
(PLAN.md, phase 1):
- **The boot partition.** `autoboot.txt` picks it, with `[tryboot]` on a
  trial. With no `autoboot.txt`, it's the first FAT partition holding a
  `start.elf`. A guest's `reboot N` asks for a partition.
- **A trial (tryboot).** It's armed by
  `sudo systemctl reboot --reboot-argument="0 tryboot"` or
  `sudo vcmailbox 0x00038064 4 0 1`, used once, and forgotten at a power-off.
  A guest reboot pauses QEMU so pi-qemu can read it.
- **`config.txt`.** It takes `[boot_partition=N]`, `[partition=N]` and
  `[tryboot]`.
- **`/proc/device-tree/chosen/bootloader`** has the real firmware's values:
  `partition`, `tryboot`, and the rest.
- **`kernel_watchdog_timeout`** leaves the watchdog running, so a start that
  hangs before systemd resets the board.

Each emulated deck takes 2 GB of RAM; four at once is about the limit on a
16 GB Mac.

## Decks on one network: Pro DJ Link

Decks started on the same **link** have their eth0s on one network, as the
players in a booth share a switch. They see each other over Pro DJ Link,
browse each other's media, and load and play each other's tracks. A deck on
no link (the default) has its eth0 on a cable to an empty switch, so other
people's and agents' decks never meet yours.

```sh
pi-qemu deck up a --link booth --window    # a: player 4 on link booth
pi-qemu deck up b --link booth --window    # b: player 3 (it saw a holding 4)
pi-qemu deck stick a insert SANDISK-E02C   # a rekordbox stick into deck a...
pi-qemu deck press b push                  # ...is a source in b's library: "4 <its label>"
pi-qemu link devices booth                 # who announces what, heard from the Mac
```

- **On a link, each deck is a device of its own.** Its eth0 MAC comes from
  its NAME (`02:54:4d:..`), so it gets its own link-local address and claims
  its own player number, as a real deck does. `up` waits for that number and
  says it: `b: player 3 at 169.254.237.243, 02:54:4d:f0:62:70 on link booth`.
- **A restored deck is a clone until then.** Every deck wakes from the golden
  snapshot with the same MAC, address and player number. So it wakes with its
  cable out, takes its own MAC, waits for Mixxx to let go of the golden
  deck's address, and only then is plugged in: nothing on the link ever hears
  the clone. A booted deck (`--boot`, `--from`) has its own MAC from the start,
  through the device tree, and after every reboot.
- **The link stays with the deck** through `stop` and `up`, until
  `up NAME --link OTHER` (or `--link none`) on a stopped deck.
- **Decks can start together** (`deck up a --link booth & deck up b --link booth &`).
  Restored decks take turns on a link: each is plugged in and claims its
  number only once the one before it has (`b: waiting for the deck before
  it...`). A Mixxx whose Pro DJ Link library is new enough also settles two
  players claiming one number at the same moment by address (lib/prolink).
- **A deck that comes up unbrowsable gets its Mixxx restarted once.** An
  observer (a player number outside 1-4, as 7) can be neither browsed nor
  browse; a Pro DJ Link library from before its rebind fix could end up one
  when its address changed. `up` says so when it happens.
- `deck link NAME` says what the deck announces and who else is on its
  link. `deck link NAME unplug` pulls its cable (frames stop, and the Pi sees
  its link go down), and `plug` puts it back.

From the Mac, without touching any deck:

```sh
pi-qemu link list                       # every link, and the decks on it
pi-qemu link devices booth              # the players announcing themselves: number, name, address, MAC, deck
pi-qemu link capture booth booth.pcap   # every frame into a pcap until ^C, for Wireshark or `prolink pcap`
```

**How it works** (`app/src/board/link.*`). A link is a directory,
`~/.pi-qemu/links/NET/`, with one Unix datagram socket per deck on it,
`NAME.sock`. Each deck's QEMU gets one end of a socketpair as GENET's network
(`-netdev dgram,local.type=fd`); the deck's `pi-qemu run` holds the other end
and forwards: the frames its Pi sends go to the other decks' sockets, and
theirs to its Pi. It learns which deck has which MAC, as a switch does, and
floods broadcasts and unknown MACs. A deck never hears its own frames back,
and nothing leaves the Mac: the sockets are files, not ports. QEMU's own
multicast hub (`-netdev dgram` to a group) cannot send on macOS: it binds the
group's address, which BSD refuses to send from.

## Emulated CDJs

A CDJ-2000NXS on Pioneer's own firmware (1.44), emulated by the
`cdj2000-emulator` submodule and joining the decks' links. ProLink can then
be debugged without the booth: a TriMixxx deck with "real" CDJs, and the
CDJs with each other. `docs/cdj-emulator.md` says why it is built this way.

Once per Mac, and once per checkout:

```sh
pi-qemu cdj build                              # this checkout's emulator: ~1.5 min the first time
pi-qemu cdj firmware ~/Downloads/C2KNXS.UPD    # Pioneer's updater, extracted outside every checkout
```

- **The firmware** is Pioneer's, given to the NXS's owners: never in a
  repository. `firmware` checks every CRC and checksum, and writes what the
  emulator boots into `~/.pi-qemu/cdj/firmware/nxs/`.
- **`build`** fetches QEMU once, at the revision the emulator's patches
  take, into `~/.pi-qemu/cdj/`, and builds it into the submodule's ignored
  `build/`. It also builds the GUI core and a venv for the emulator's tools.
  In a worktree, the submodule is the main checkout's, which
  `pi-qemu worktree prepare` borrows.

A CDJ, and a booth:

```sh
pi-qemu deck up d --link booth
pi-qemu cdj up a --link booth          # ~25 s: "a: player 1 at 169.254.x.y, 02:43:44:.. on link booth"
pi-qemu cdj up b --link booth          # player 2: the NXS numbers itself AUTO
pi-qemu link devices booth 10          # 1 a, 2 b, 4 d
pi-qemu cdj shot a a.png               # its 480x234 screen
pi-qemu cdj press a link               # a panel key: play, cue, link, usb, sd, enter, back, menu, ...
pi-qemu cdj rotary a 2                 # the browse encoder
pi-qemu cdj window a                   # its screen and panel, lit as its firmware lights it
pi-qemu cdj lamps a                    # those lamps, by name: {"PLAY_PAUSE": "blink", "MASTER": "3", ...}
pi-qemu cdj status a                   # the emulator's own: the browser's last reply, the frame, ...
pi-qemu cdj rm a
```

- **A CDJ is booted, never restored.** Its player screen is up in about
  8 s, and `up` waits for it, then on a link for its first keep-alive. One
  with no player screen in 120 s is stopped, its logs left in
  `~/.pi-qemu/cdj/NAME/` until `cdj rm`.
- **On a link it is a member of its own,** as a deck is. Its MAC comes from
  its name, `02:43:44:..`, and the NXS takes its link-local address from
  the MAC's last two bytes.
- **Give `link devices` 10 s with a CDJ on the link.** A CDJ re-claims its
  number every few seconds with a TriMixxx deck present, as a real one did
  in `mixxx/lib/prolink/captures/S10-serve-to-cdj`, so its keep-alives come
  up to ~5 s apart.
- **Media:** `--sd IMG` / `--usb IMG` mount a FAT32 image, and its writes are
  thrown away. `--test-track` makes a card with a 10 s WAV on it. To make
  an image from a rekordbox stick, copy the stick to a folder first (never
  hand the emulator the stick itself: a CDJ writes its history to it), then
  `python -m tools.cdj_main.make_sd_image FOLDER IMG --size 4G` in
  `cdj2000-emulator/` with its venv (`.venv/bin/python`): a few seconds.
- **Playing a track: `--dsp-model`.** By default the CDJ runs Pioneer's DSP
  code, interpreted, which cannot decode in real time: a loaded track does
  not play. `--dsp-model` runs the emulator's behavioural DSP instead. It
  executes none of the DSP's code and makes no sound, and keeps the track's
  position on the CDJ's clock, so a track plays in real time and its beat
  packets come at its tempo.
- **Its window** (`cdj window NAME`, or `cdj up NAME --window`): its
  screen, live, in a schematic of the NXS's top panel, in the deck panel's
  look.
  - **Every key `cdj press` knows is a pad** in its place. A click holds it
    for as long as the mouse is down, and at least as long as a `press`.
    Shift-click latches it.
  - **The selector:** drag or scroll it to turn it, click it to push.
    Keyboard: space is PLAY, C CUE, up and down turn the selector, return
    pushes it, backspace is BACK.
  - **The TEMPO fader:** drag it; minus is at the top, as on the deck, and
    a double-click puts it back on its centre. The CDJ's own screen shows
    the tempo it took.
  - **The DIRECTION lever and the SD lid** are switches: a click flips them.
    They, and the fader, start as the CDJ has them.
  - **The pads light as the CDJ's firmware lights its lamps:** what MAIN
    sends the panel, which the emulator decodes (`cdj lamps`). The sources,
    the browse keys, SYNC, MASTER and LOOP MODE glow dimly while available.
  - **Not here:** the jog, which is not emulated (only its touch is).
  - **Closing it leaves the CDJ running.** The CDJ stopped, it closes, and
    it lets go of any key it held down.
  - **A key left down** (a window that crashed, or was killed with -9):
    open the window again and click the key once.
  - **A window and the command line share the CDJ:** the emulator's control
    channel takes several connections at once.
- **Its state** is in `~/.pi-qemu/cdj/NAME/`: `cdj.json`, the `cdj run`
  behind it (`pid`, `pi-qemu.log`), its socket on the link (`link.sock`),
  the emulator's run directory (`run/`, the last one kept as `run.prev`),
  and its window's `window.pid` and `window.log` while one is open.
- **Real time.** A CDJ runs at a real one's speed by the wall clock: its
  start-up, keep-alives (every 2.0 s) and status packets keep a real NXS's
  timing (`docs/cdj-emulator.md`, "Real time"). With every core of the Mac
  busy, its keep-alives slip to 2.1-3.2 s while that lasts.
- **Limits.** A CDJ takes about two cores (one with `--dsp-model`). Two
  CDJs and a deck take about five of a twelve-core Mac. There is no audio
  and no jog, and a CDJ stops after a day.

**How it joins a link** (`app/src/board/streamport.*`). `cdj up` starts
`pi-qemu cdj run` detached; it is the emulator's parent.
- It holds the CDJ's member on the link, through the same `Link` as a
  deck's.
- It listens on `link.sock` for the emulator's NIC: a QEMU stream netdev,
  `nxs_vm --link-hub unix:...`, whose frames are each a 32-bit length and
  then the frame.
- It moves them between that stream and `Link`'s datagram end.
- When the emulator exits, `cdj run` leaves the link.

## Deploying

`pi-qemu deck deploy TARGET [STEP...]` puts this checkout's code onto a deck,
emulated or real, by the numbered steps in `deploy/`, all of them in order
when none are named:

| Step | What |
|---|---|
| `000_base.pi.sh` | pi_config/fresh-install.md 1–2: boot flags, ssh, background load, packages, autologin |
| `001_ttymidi.sh` | the serial<->MIDI bridge (`mixxx_config/ttymidi`), built in Docker |
| `002_system.sh` | `pi_config`: systemd units, session, splash, eth0, the Wi-Fi fallback, dj-usb |
| `003_launcher.sh` | `trimixxx-launcher`: boot modes, SysEx daemon, deck keys, built in Docker |
| `004_mixxx.sh` | the Mixxx fork, built in Docker, over apt's binary |
| `005_config.sh` | `mixxx_config`: mapping, skin, fonts, mixxx.cfg, this deck's wiring |
| `006_library.sh` | Mixxx's music library directory, once |
| `007_doom.sh` | Doom |

A step is named as `mixxx`, `004` or `004_mixxx`, and a new step is the next
number. `deploy/lib.sh` has their contract:
- a `.sh` step runs on the Mac and reaches the deck as `ssh deck`; a `.pi.sh`
  step runs on the deck, as root;
- each is idempotent: run again, it changes nothing where nothing changed
  (a binary that is the same is left alone);
- its exit status says what follows: a step that changed the boot flags has
  the deck reboot before the next one; one that restarted the MIDI bridge or
  the launcher has the session restarted at the end, since Mixxx opens their
  ports only at its start. After a session restart, `deploy` waits until
  Mixxx is ready.

Steps that build in Docker need ~6 GB free on its disk: `deploy` checks
first, and leaves freeing space to you.

## Cards and releases

`pi-qemu image build [DECK]` makes a deck's card from the stock image
(`image/stock.env`):
1. seeds cloud-init: user, key, password hash, hostname (`image/user-data.in`,
   `network-config`);
2. boots it as an emulated deck of its own, `build-DECK` (`deck ssh build-DECK`
   reaches it while it builds);
3. runs every deploy step over it;
4. seals it into `.cache/build/DECK.img`, and for trimixxx0 refreshes the
   golden snapshot.

Everything up to and including `000_base` is cached in `.cache/base/` while
its inputs stay the same (`--rebuild-base` forces it).

The cards the decks run from, read-only and updated A/B over the network,
come from such a build (PLAN.md Part 1, and [rauc-pi-4-setup.md](rauc-pi-4-setup.md)):

```sh
pi-qemu release build                # HEAD's pi/vX.Y.Z tag -> release/out/X.Y.Z/: the card, the bundle
pi-qemu release card trimixxx2       # trimixxx2's card: the release card with its identity on p7
pi-qemu deck ship --host trimixxx-pi-2   # the update onto a deck running a release card
pi-qemu deck prepare --host trimixxx-pi-2 trimixxx2   # before a deck's first release card
```

## Git worktrees

Several agents (or people) can work at once, each in a git worktree of the
repo, each deploying its own code to its own emulated deck. The root
`CLAUDE.md` is the workflow agents follow. Behind it:

- **`pi-qemu worktree prepare`** sets up the worktree's submodules, which
  start as empty directories. `mixxx/` (and its `lib/prolink`) and
  `mixxx_config/ttymidi` become linked worktrees of your main checkout's
  submodule repositories, detached at the commits the worktree's branch
  records. So does `cdj2000-emulator/`, the emulated CDJs', when the branch
  records it and the main checkout has it
  (`git submodule update --init cdj2000-emulator` there gives it one). It takes seconds and downloads nothing. A branch made in a
  worktree's `mixxx/` is a branch of your main `mixxx/` at once, so merging it
  there is enough. `git submodule update` would instead clone a private copy
  that is deleted with the worktree.
- **Every checkout builds Mixxx in its own Docker build tree** (keyed by
  `mixxx/checkout-id.sh`). A tree builds from its own copy of the sources,
  which `mixxx/tree-sync.sh` updates by content before each build. ninja then
  recompiles exactly what changed since that tree's last build, whatever git
  did to the files' dates. A worktree's first build starts from a copy of the
  main checkout's tree.
  - A worktree's first Mixxx deploy takes about 75 s, later ones about 45 s.
  - Builds queue on the shared compiler cache, so only one Mixxx compiles at a
    time: two agents deploying at once measured 87 s and 138 s.
  - Each tree takes about 4 GB of Docker's disk.
- **`pi-qemu worktree release`**, before removing a worktree, empties its
  Docker build trees and removes its submodule worktrees. Until then git
  refuses to remove a worktree with checked-out submodules, short of
  `--force`, which leaves the build trees behind. `release` refuses itself if
  they hold uncommitted changes, or commits no branch has.
  - A submodule that is a clone of its own, as `git submodule update` makes,
    is taken back too, once its origin has all of its commits and it holds
    no stash.
  - Its git directory is in the worktree's `modules/`, which `release`
    removes, since git will not remove a worktree with it.
  - `release` also refuses while a CDJ runs from the worktree's emulator:
    `cdj rm` it first.
  `pi-qemu worktree status` shows what a worktree has checked out.

pi-qemu acts on the checkout it runs in: `deck deploy` from a worktree
deploys that worktree's code, and runs `prepare` itself. The built QEMU, the
caches, the golden snapshot and the releases are the main checkout's,
whichever checkout pi-qemu runs in.

## Snapshots

`pi-qemu deck save NAME FILE` pauses the Pi, writes the whole machine (RAM and
every device) to FILE, and stops it. `pi-qemu run --restore FILE CARD` brings
that machine back in about 3 seconds, Mixxx already running. Rules:

- **The card must be the one it was saved with, unchanged.** After the
  restore, the card moves on and the snapshot no longer fits it.
  `deck up` and `deck stop` do this for you: a saved machine is used once,
  and is gone the moment it starts.
- **The same devices.** No USB sticks inserted when saving (`save` refuses),
  and the same `--net` mode. `--audio` and `--display` may differ.
- **Same Mac architecture.** Some devices are saved in host byte order.
- The Pi wakes up with the clock it was saved with. `deck up` sets it to
  now; by hand, use `ssh ... "sudo date -u -s @$(date -u +%s)"`.

The **golden snapshot** (`.cache/golden/trimixxx0.img` + `.state`) is the
built card, booted until Mixxx has its sound device open, then saved. Every
new emulated deck starts from it. `image build trimixxx0` refreshes it at the
end of the build; `deck golden [CARD]` makes it from any card.

Making QEMU's `raspi4b` savable took patches 8–13 in
`qemu/trimixxx-patches.py`. The USB sound card and USB network adapter had no
saved state. The PCIe root port and GENET silently had none, so a restored Pi
lost its USB controller. USB devices forgot their configuration, and xHCI
without MSI-X could not be loaded. Each patch says why.

Patches 14–16 made the emulated SD card fast. It moved one byte per call
through the card model and one 512-byte block per image access, which gave
about 4 MB/s. It now reads at ~800 MB/s and writes at ~400 MB/s, which is
what took a boot from ~50 s to ~5 s. No real card is that fast. The emulator
is for testing the software, not the deck's timing.

## Workflows

### Test a Mixxx change on the emulated deck

```sh
pi-qemu deck up mix
pi-qemu deck deploy mix mixxx         # Docker arm64 build, swaps /usr/bin/mixxx, waits for the new Mixxx
pi-qemu deck ssh mix 'tail -50 /tmp/mixxx/mixxx.log'
pi-qemu deck shot mix /tmp/after.png
```

The build goes by content. Every checkout has its own build tree in Docker's
cache, with its own copy of the sources, and recompiles exactly the files
whose content changed since that tree's last build. `tree-sync: N change(s)`
in the output says how many. A changed file or two deploys in about 45 s.
The main checkout's first build in this layout compiles everything (~25 min
at the 4 jobs Docker's memory allows); after that, builds only redo what
changed.

### Test a config, skin or mapping change

```sh
pi-qemu deck deploy mix config        # mapping, skin, fonts, mixxx.cfg; ~10 s with the restart
pi-qemu deck press mix hotcue1
pi-qemu deck leds mix
pi-qemu deck ssh mix 'sudo grep ^0: /proc/tty/driver/ttyAMA'   # rx: bytes the S3 sent
```

`deploy mix system` (pi_config: systemd units, session, splash),
`launcher` and `ttymidi` work the same way, on a real deck too
(`--host ALIAS`).

### Play a track from a USB stick

```sh
pi-qemu deck stick mix list          # images in .cache/sticks/ and the Mac's USB disks
pi-qemu deck stick mix insert SAM3   # SAM3.img: a rekordbox export, read-only
pi-qemu deck press mix push          # the encoder push opens the library...
pi-qemu deck browse mix 2; pi-qemu deck press mix push   # ...then moves and activates
pi-qemu deck shot mix pick.png       # see where you are
pi-qemu deck press mix play; pi-qemu deck leds mix       # "play": true
```

An image of a real stick, with the same layout as the original (MBR, FAT32),
as `.cache/sticks/SAM3.img` was made:

```sh
cd pi-qemu/.cache/sticks
hdiutil create -srcfolder /Volumes/SAM3 -volname SAM3 -fs FAT32 -layout MBRSPUD -format UDTO -size 256m SAM3
mv SAM3.cdr SAM3.img
```

### A folder as a stick, with nothing copied

A folder on the Mac goes in as a FAT32 stick made up on the fly: a copy of
a DJ's stick on an external drive, say, however big. Nothing is copied and
the folder is only ever read. pi-qemu builds the stick's directories and FATs
in memory when it goes in, then hands the Pi each file's bytes as it reads
them, through QEMU's NBD client (`app/src/board/fatvolume.*`, `nbdserver.*`).
The Pi sees a real USB disk, so udev, dj-usb and Mixxx's own checks all run
as they would on the deck.

```sh
pi-qemu deck stick mix insert /Volumes/Drive/DJ-stick-copy   # a folder: MBR, FAT32, sized to fit
pi-qemu deck stick mix insert SANDISK                        # .cache/sticks/SANDISK.stick
```

A `.stick` file (JSON) says how the stick was laid out. Every key but
`folder` is optional, and relative paths are from the `.stick` file:

```json
{
  "folder": "/Volumes/BIGBOY2/TriMixxx-USB-dumps/SanDisk-E02C-5D1B/files",
  "superfloppy": true,
  "size": 123048296448,
  "volumeStart": "/Volumes/BIGBOY2/TriMixxx-USB-dumps/SanDisk-E02C-5D1B/sda-first-31MiB-bootsector-and-FATs.raw",
  "bytesPerSecond": 3700000
}
```

| Key | What it does |
|---|---|
| `superfloppy` | no partition table: the filesystem starts at sector 0, as some sticks have it |
| `partitionStart` | where the FAT32 partition starts, in sectors (default 2048) |
| `size` | the disk's size in bytes (default: what the files need, plus a quarter) |
| `volumeStart` | a raw copy of a real stick's filesystem start (`{"file": F, "offset": N}`, or just `F`): its reserved sectors are served as they were (boot code, serial, label, dirty flag), and the FATs, FSInfo and directories are laid out to match |
| `mbr` | a real stick's first sector, partition table included |
| `label`, `serial` | the volume label, and the serial blkid reports as the UUID (`"E02C-5D1B"`) |
| `clusterKiB` | the cluster size (default: mkfs.fat's for the size) |
| `bytesPerSecond` | reads no faster than this, like a slow stick (a USB 2 Cruzer Blade: `3700000`); see "A slow stick" |
| `readsPerSecond` | and no more reads a second than this, small or large (what makes a cheap stick's small reads slow too) |

Names go onto the stick NFC, as rekordbox's sticks have them: macOS hands a
folder's accented names back decomposed, and serving those as they come would
make a stick no deck has ever seen. A file of 4 GiB or more, or two names that
differ only in case, cannot be on a FAT32 stick, and the insert says so.

### A slow stick, and what the deck reads off it

Every stick reads through a QEMU throttle group of its own, so any stick --
a folder, an image, the Mac's own -- can be made as slow as a real one, and
its speed changed while it is in:

```sh
pi-qemu deck stick mix speed SANDISK 4M        # 4 MB/s, a cheap USB 2 stick
pi-qemu deck stick mix speed SANDISK 4M/300    # ...and 300 reads a second
pi-qemu deck stick mix speed SANDISK full      # as fast as it goes
pi-qemu deck stick mix list                    # an inserted stick shows its speed
```

A speed set before the stick goes in applies from its first read; one set
while it is in takes effect at once (QMP `qom-set` on its group's `limits`).
Sticks really do vary that much: a Cruzer Blade gave 3.7 MB/s, a SanDisk 3.2
on USB 3 well over 100.

For a folder stick, pi-qemu also counts what the Pi reads, file by file:
what a browse reads, what a load reads, and what was read that nobody asked
for:

```sh
pi-qemu deck stick mix reads SANDISK           # since it went in, or the last reset
pi-qemu deck stick mix reads SANDISK reset     # the same, then start counting again
```

```text
139.3 MB in 3612 reads over 46.4 s (3.0 MB/s on average), from 1102 files and regions
   80.4 MB     643 reads  /Contents/Zoe/UnknownAlbum/Zoe - Transient Shift.wav
   58.3 MB     466 reads  /Contents/FAÏG/South West EP/FAÏG - South West EP - 03 Deep Within.aiff
    0.3 MB     598 reads  FAT
```

### Check the audio without hearing it

```sh
pi-qemu deck record mix 10 /tmp/mix.wav    # Mixxx's main mix, recorded by Mixxx; make it play first
pi-qemu deck up snd -- --audio wav:/tmp/out.wav    # or everything the sound card plays, for a new deck
python3 - <<'EOF'
import wave, struct
w = wave.open('/tmp/out.wav'); n = w.getnframes(); d = w.readframes(n)
s = struct.unpack('<%dh' % (n * w.getnchannels()), d)
print('seconds', n / w.getframerate(), 'peak', max(map(abs, s)))
EOF
```

A tone that does not need Mixxx: stop the session with
`sudo systemctl stop getty@tty1` (that also frees the sound card), then run
`timeout 3 speaker-test -D plughw:0,0 -c 1 -r 44100 -t sine -f 440`. That is
one tone on both channels; `-c 2` plays left, then right. To bring Mixxx back:
`sudo systemctl start getty@tty1`.

### The deck will not come up

```sh
cat ~/.pi-qemu/instances/NAME/card.run/console.log    # the boot, from the first kernel line
pi-qemu deck console NAME 'systemctl --failed' 'journalctl -b -p err | tail'
pi-qemu deck shot NAME now.png
```

If ssh hangs as soon as QEMU starts, a Mac firewall (Little Snitch, or macOS's
own with stealth mode) may be holding QEMU's network sockets. Allow
`qemu-system-aarch64`.

### Rebuild the card after changing the deck's setup

```sh
pi-qemu image build                   # reuses the cached base; refreshes the golden snapshot
```

Running decks keep their own cards; `deck up NAME --fresh` takes the new one.

## Troubleshooting

- **`... has a passphrase and is not in the ssh agent`**: `ssh-add` the key
  pi-qemu names (after every reboot of the Mac).
- **`QLocalServer::listen: Name error`**: a unix socket path longer than 104
  bytes. Use a shorter card path; instances live in `~/.pi-qemu` for this reason.
- **The window does not take your keys**: click into it. A window opened from a
  background process may not get focus.
- **Docker "no space left"**: check with `docker run --rm --pull never debian:trixie df -h /`.
  `docker buildx prune -f --all --filter type=regular --filter until=90m` frees
  space and keeps the compile caches.
- **A restore fails with "Unknown section" or similar**: the snapshot was made
  by a QEMU built from different patches. Remake it with `pi-qemu deck golden`.
- **`deploy` says Docker's disk is full**: see `docker system df`. Unused
  images (`docker image prune -a`) are usually most of it.

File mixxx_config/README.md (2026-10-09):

# TriMixxx S3 — Mixxx controller mapping

Everything that lives under `~/.mixxx` on the deck. The S3 firmware sends raw MIDI
over UART → `ttymidi` on the Pi → ALSA → Mixxx sees a standard MIDI device. These
files map that device to Mixxx controls. Addresses match the firmware's
[`lib/PiLink/MidiMap.hpp`](../firmwares/trimixxx-midi/lib/PiLink/MidiMap.hpp) exactly — **change both together.**

The system side (systemd units, udev, USB automount) is in
[`../pi_config`](../pi_config); the config deploy step
([`../pi-qemu/deploy/005_config.sh`](../pi-qemu/deploy/005_config.sh)) touches
only `~/.mixxx`, the per-user font directory `~/.local/share/fonts` and every
deck's rendering for a release card (`/usr/share/trimixxx/decks`), and restarts
Mixxx, so a mapping tweak can never disturb the deck's system config.

## Files
- `TriMixxx.midi.xml` — the deck mapping (inputs, LED outputs).
- `TriMixxx.scripts.js` — scripting for the jog (scratch/bend), the browse
  encoder, play toggle, the ring buttons and their RGB LED indicators, and the
  startup rainbow-wave animation.
- `PiMidiDaemon.midi.xml` / `PiMidiDaemon.scripts.js` — the mapping for
  [`../trimixxx-launcher`](../trimixxx-launcher), a second MIDI device. Turns the
  skin's POWER menu into a shutdown SysEx, Diagnostics' RESTART INTO (a release
  card's other A/B slot, as a trial) into a slot-switch SysEx, and the daemon's
  USB-mount events into a Rekordbox device rescan. The **device is still named
  `pi-midi-daemon`** even though the daemon behind it was renamed: `mixxx.cfg`
  binds mappings by device name, so renaming the port would orphan this one.
- `TriMixxx_skin/` — single-deck CDJ-style skin for the 1024×600 touchscreen.
- `fonts/` — MesloLGL Nerd Font (Regular + Bold), installed to the deck's
  `~/.local/share/fonts` by the config step. Both `mixxx.cfg` (`[Library] Font`) and
  the skin's stylesheet name this family, and Qt resolves families through
  fontconfig *by name*, so a missing font is never an error — it just silently
  falls back and the deck comes up looking subtly wrong. Only the two weights the
  skin uses are shipped; italic is synthesised. See the note in `style.qss`
  before swapping it: **every** Meslo variant is monospace, the `Mono`/`Propo`
  suffix only spaces the icon glyphs, so no Nerd Font spelling will make titles
  narrower — that needs a different family.

  Meslo is a *terminal* font (~13k codepoints), so it has no CJK, Arabic, Hebrew,
  Indic scripts or emoji. Those are handled by the Noto fallback chain in
  [`../pi_config/60-trimixxx-fonts.conf`](../pi_config), which is also what
  installs them — the deck needs **both** deploy steps, `config` and `system`,
  for a track title in Japanese to render.
- `soundconfig.xml` — audio device + buffer size. Mixxx keeps sound hardware in
  its own file, *not* `mixxx.cfg`. Deployed by the config step; see the buffer
  note below.
- `mixxx.cfg` — the rest of the Mixxx preferences as deployed. The fork never
  writes it back (no save on exit, nor from Preferences), so this file *is* the
  deck's settings: a change made in Preferences on the deck lasts until Mixxx
  exits, and a lasting one is made here and uploaded. Keep its `[Config]
  Version` at the fork's (2.5.6): an older one makes Mixxx treat every start as
  an upgrade, since the bumped version is never saved.
- `../pi-qemu/deploy/005_config.sh` — the config deploy step, which puts all of
  the above on the deck (`pi-qemu deck deploy TARGET config`). **Validates every
  XML before anything leaves this machine**: Qt rejects a malformed skin silently
  and boots the default one instead, with nothing in the log.
- `serial_midi_bridge.py` — bridge/monitor the S3's UART on a Mac (or over SSH on
  the Pi) without ttymidi. `led_test.py` — send the LED feedback Mixxx would send,
  straight down the serial line, to test the return path with Mixxx out of the way.
- `ttymidi/` — our ttymidi fork (submodule); the binary `trimixxx-bridge.service`
  runs.

## Install
Copy the mappings into Mixxx's controller mapping folder, then pick **TriMixxx S3**
under Preferences → Controllers for the MIDI device (and `pi-midi-daemon` for its
own port, if that daemon is running).
- Linux: `~/.mixxx/controllers/`
- macOS: `~/Library/Containers/org.mixxx.mixxx/Data/Library/Application Support/Mixxx/controllers/`
- Windows: `%USERPROFILE%\Mixxx\controllers\`

On the deck itself, the config step does all of this:
`pi-qemu deck deploy --host trimixxx-pi config`, or
`pi-qemu deck deploy NAME config` on an emulated deck. Requires Mixxx **2.4+**
(the deck runs [our 2.5.6 fork](../mixxx)). One deck = `[Channel1]`.

## Control map
| Control | MIDI | Mixxx |
|---|---|---|
| Play | note `0x3C` | `play` (toggle); LED ← `play_indicator` |
| Cue | note `0x3D` | `cue_default` (momentary); LED ← `cue_indicator` |
| Loop in / out | notes `0x3E` / `0x3F` | `loop_in` / `loop_out`; both LEDs ← `loop_enabled` |
| Reloop | note `0x40` | `reloop_toggle` (no LED) |
| Track encoder | CC `0x10` + note `0x41` | browse library; push = open / `GoToItem` / `LoadSelectedTrack` (see below) |
| Jog | CC `0x11` + note `0x42` | scratch when touched, pitch bend otherwise |
| Tempo | CC `0x12`/`0x32` (14-bit) | `rate` |

### Ring A (notes `0x00`…, 7 buttons populated)
| # | Note | Mixxx |
|---|---|---|
| A1 | `0x00` | `TriMixxx.tempoRange` — cycle ±6 / ±10 / ±16 / Wide; LED colour keyed to the range |
| A2 | `0x01` | `TriMixxx.keylock` — master tempo |
| A3 | `0x02` | `beatloop_8_toggle` |
| A4 | `0x03` | `beatloop_4_toggle` |
| A5 | `0x04` | `loop_double` |
| A6 | `0x05` | `loop_halve` |
| A7 | `0x06` | `TriMixxx.back` — library view / focus |

### Ring B (notes `0x43`…, 6 buttons populated)
| # | Note | Mixxx |
|---|---|---|
| B1–B4 | `0x43`–`0x46` | `hotcue_1..4_activate`, on both edges (release ends the preview when paused) |
| B5 | `0x47` | `TriMixxx.slip` — flashes while slip is on |
| B6 | `0x48` | `TriMixxx.sortKey` — SORT over the library, KEY SYNC over the deck (see below) |

Both pad ranges reserve 50 notes in `MidiMap.hpp` even though fewer nodes are
populated, so adding a board never renumbers anything. `TriMixxx.RING_A_N` /
`RING_B_N` at the top of the script are the counts actually wired today.

### KEY SYNC (B6, over the deck)
Pitches this deck into a key compatible with the **track** the CDJ holding
tempo master has loaded, as rekordbox analysed it -- not as that CDJ is heard:
its own pitch fader and master tempo are not on the wire, and are ignored. The
key this deck plays is `[Channel1],key` in the header, beside the artist.

The rules are Mixxx's, in [`keysync.h`](../mixxx/src/network/prolink/keysync.h),
and the pad only mirrors them:

- **Dark and dead** unless another player holds tempo master *and* we can resolve
  what key its track is in. That key is not on the wire — a status packet gives a
  player, a slot and a rekordbox id, and the key comes from this deck's own copy
  of that medium's database, ingested when the medium appeared.
- **Dim purple** once both hold: pressing it now engages.
- **Bright** while engaged. What it captured is a *key*, not a deck, so the master
  moving, loading something else or going away changes nothing — and it never
  releases itself, because dropping the sync under a playing track would re-pitch
  it mid-mix. Pressing it again releases it, always. A new key needs off, then on.

Engaging turns master tempo (A2, keylock) on: a latched key would otherwise
move with every tempo change from the moment it was set. Turning master tempo
off afterwards keeps the semitone shift, and the key then also moves with the
tempo fader, as it does with master tempo off; turning it back on keeps it too.
The shift is an offset (`pitch_adjust`), so releasing leaves nothing behind
whatever the fader is doing.

Only a rekordbox-analysed track has a key here: an unanalysed file on the
master is not looked up, and KEY SYNC stays dark rather than guess.

The shift lands on the tonic, the fourth or the fifth (`shortestStepsToCompatibleKey`,
the same as Mixxx's own `sync_key`), so it never asks for more than two semitones,
and it is re-applied from the new track's own key on every load.

`mixxx.cfg` has `[Controls] SpeedAutoReset 0`. Mixxx's default (1) resets the
pitch on every load, after the new key is set; the fork re-applies the shift
after that reset, so either setting works, but at 0 nothing undoes it even for
a moment, and nothing else on this deck moves `pitch_adjust`.

### SYNC's phase trim (`[ProLink] phase_trim_ms`)
SYNC, the phase meter and the beats this deck sends compare phases *as heard*:
the fork moves the engine's position to the sample the DAC is playing, using
the latency Mixxx knows about. What it cannot know -- the USB codec, and a
CDJ's own gap between its beat packet and its sound -- is this trim, in
milliseconds, positive when this deck is heard later than the CDJ. It is a
persistent control read from `mixxx.cfg`, 0 when absent:

```
[ProLink]
phase_trim_ms 0
```

To measure it: CDJ master playing a track with a hard kick, this deck playing
the same or a similar track with SYNC lit, both outputs recorded on the two
channels of one interface. The gap between the two kicks, TriMixxx's minus
the CDJ's, is the trim to add to the current value. One measurement per rig
(deck hardware, sound card and buffer size); re-measure after changing the
buffer in `soundconfig.xml`.

## The screen has no buttons except POWER
Everything the skin used to put under the waveform — LIBRARY/DECK, the ±6/±10/±16/
WIDE tempo-range pads, LOOP ÷2 / ×2 — is on the hardware (ring A1, A5, A6 and the
encoder push), so the bar is gone and the waveform takes its 130 px. The jog TOUCH
indicator went with it; it was a bring-up aid for "did note `0x42` reach Mixxx",
and the waveform answers that now. POWER moved into the header, because it is the
**only** way to shut the deck down from the UI — there is no hardware equivalent.

### Library menu
Menu order is `Library::Library()` in [our fork](../mixxx/src/library/library.cpp),
not the skin: `SidebarModel` renders features in `addFeature()` order. Rekordbox,
Tracks and Players lead; everything else follows. iTunes and Serato are switched
off in `mixxx.cfg` (`ShowITunesLibrary` / `ShowSeratoLibrary`), which needs no
rebuild. Startup selection is pinned to Tracks so a boot doesn't open on
Rekordbox's "plug in a prepared device" page.

Encoder push in the left pane sends `[Library],GoToItem`, which expands an entry
that has children (Rekordbox → its USBs, Players → the CDJs on the network) and
keeps focus there, and only jumps to the track list on a leaf or on Tracks. The
bottom 56 px of the library view is a dead strip: the panel's last row sits behind
the bezel, so the last menu entry and last track row were untappable without it.

### Ring LEDs are SysEx, not `<output>`
A Mixxx `<output>` can only emit a 3-byte message, and a Note-On velocity sets
white brightness only. Colour therefore goes out as SysEx from the script —
`F0 7D <cmd> <node> <colour nibbles> F7`, `0x01` for ring A and `0x03` for ring B,
each 8-bit channel split into two data bytes so a 7-bit payload still carries
0..255. `TriMixxx.ringLed()` is the one place that formats it; `TriMixxx.led()` /
`dim()` normalise the palette so entries only need correct hue *ratios*.

### A deck wired in a different order (`units/`)
Ring pads are numbered by their place in the daisy chain, and PLAY/CUE by the
GPIO they land on, so a deck wired differently sends the right MIDI for the
wrong button. Such a deck gets a `units/<hostname>.json`: `buttons` says which
note each control actually arrives on, `lights` which note — or ring node — its
LED actually answers to, both keyed by the canonical note from `MidiMap.hpp`;
`jogReversed` flips a jog encoder wired the other way round (scratch and bend
both); `"bezel": false` is a panel that sits flush, with no lip to keep clear;
`"accent": "#rrggbb"` is the deck's own accent colour.

`bezel` is the skin's `[TriMixxx],bezel` attribute (default 1), which
`apply.py` writes into a staged copy of the skin. With it off, the deck view's
`DeckBezelPad`/`BevelPad` strips go, and so does the browser's own
(`deckbezel.h` in the fork, read when it is built). The skin's minimum sizes
are the 1024×600 layout and its maximum heights are open, so a taller logical
screen is filled rather than letterboxed — on trimixxx2 (1024×640 at 1.25) the
waveform takes the difference.

`accent` is the colour of whatever is selected, where you are and what is live:
the selected row, the breadcrumb, the header rule, the key, BPM and remaining
time, SYNC, the Diagnostics headings. The skin ships Trimixxx1's lime,
`#88ff00`, and a deck with no `accent` keeps it. With one, `apply.py` replaces
every `#88ff00` in the staged `style.qss` and SVGs, and sets the skin's
`[TriMixxx],accent` attribute — the colour as an integer, `8978176` for the
lime — which the fork's self-painting widgets read through `deckaccent.h`.
So in those files the accent is spelled exactly `#88ff00`, and nothing else
may be. `skin.xml`'s own colours are not touched: the waveform's three bands
(blue, yellow, white) are the same on every deck. A deck uploaded with a Mixxx
build from before `deckaccent.h` gets the new stylesheet but keeps a lime
selection and breadcrumb until the fork is rebuilt.
The config step looks the deck's hostname up, and if there is a file, runs
`units/apply.py` on the way out: it renumbers the XML's note bindings and
outputs (nothing else in the file changes), and fills the script's
`// @unit-wiring` line, which `ringLed()` and the hot-cue handler consult. The
files here stay canonical; a deck with no unit file gets them untouched.
`pi-qemu deck press` (and `down`, `up`) reads the same file, so its named
controls still press the control they name.

The remap is Mixxx's alone. The launcher's boot gestures and Doom
(`trimixxx-deckkeys`) read the same MIDI with the canonical table, so on a
remapped deck they see its wiring as it is.

`trimixxx2.json` is the first: an eighth pad sits third in ring A — unbound,
no function yet — pushing the loop pads and BACK one node down, hot cues 1–4
arrive reversed, the jog turns the other way, the panel is flush, and its
accent is pink, `#FF7092`.

Overall ring brightness is `TriMixxx.RING_LEVEL` (0.8), applied in `ringLed()`
to every level the script sets — indicators, SORT/KEY SYNC, hot cues, the boot
sweep — so dimming the rings is one number. It is *perceived* brightness: the
LEDs are linear in duty and nothing on the way corrects for gamma, so it goes
out as `RING_LEVEL ^ 2.2` (0.8 → 61 % duty). Plain 0.8 of the duty cycle looked
like no change at all. `BRIGHTNESS` is only the plain indicators' level relative
to full.

## Decisions you may want to change
- **Ring button assignments** are just the tables above — repurpose freely
  (hotcues, beatjump, …); the pads are physically identical.
- **Tempo direction:** the fader is inverted in firmware; if pitch runs the wrong
  way, flip `[Channel1] rate_dir` in Mixxx (or `invert` in the firmware ctor).
- **Jog feel:** `JOG_TICKS_REV` (12960) mirrors `JogWheel::TICKS_PER_REV`;
  `JOG_BEND_SENSITIVITY` (0.3) damps pitch bend only — scratch stays 1:1. The
  scratch `alpha`/`beta`/`rpm` in `jogTouch()` are the usual starting values.
- **Loudness normalization is off** (`[ReplayGain] ReplayGainEnabled 0`), so every
  track plays at the level it was mastered at, like a CDJ. It used to be on with
  the analyser off (`ReplayGainAnalyserEnabled 0`), and that combination
  normalizes nothing: a track with no ReplayGain value gets
  `InitialDefaultBoost` (−6 dB) in `EnginePregain::process()`, and with no
  analyser only files carrying ReplayGain tags ever have one — rekordbox exports
  generally do not. So every track played at half amplitude, which is why the
  line level read low. The UCA222's line out tops out at 2 dBV (≈1.26 V RMS),
  already ~4 dB under a typical CD player's 2 V, so the deck has no level to
  spare; make up the rest with the mixer's channel trim, not with gain past unity
  in Mixxx, which only clips loud masters. Turning it back on is only worth it
  with the analyser on too. The deck's own trim is **Diagnostics → Adjust →
  Output** (±6 dB, `[Master],gain`): below unity it is free, above it is exactly
  that gain past unity, and the Clipping row under it says when it bites. It
  lives in `~/.mixxx/trimixxx-levels`, so this script's `mixxx.cfg` copy does not
  reset it.
- **The waveform's height follows the track's gain, so `[Waveform] VisualGain_0`
  is 0.5.** The RGB renderer (`WaveformType 10`) scales by `total_gain` × 2 ×
  `VisualGain_0` (the ×2 is Mixxx's own "compensation",
  `WaveformWidgetRenderer::getGain`). With normalization on, an untagged track
  had a `total_gain` of 0.5 (the −6 dB default boost), so full scale landed
  exactly on the waveform's edge. Turning it off made that 1.0 and drew every
  track twice as tall, loud parts off the screen; 0.5 puts full scale back on
  the edge. The deck's Output trim is `[Master],gain` and does not move it.
  That is the stock, mixed view; the stacked one below sets its own scale.
- **Both waveforms are three bands as stacked bars.** Highs white at the
  centre, mids yellow on top of them, bass blue outermost, each as thick as
  there is of it, so all three always show. The scrolling waveform is the
  fork's `<SignalStacked>` mode of that RGB renderer (colours from the skin's
  `SignalRGB*Color` nodes): smoothed across a few pixels, and scaled to the
  track's own deepest stack, which fills 90 % of the height, so it never
  clips whatever the master's level — the gains above do not apply to it. The
  overview under it is Mixxx's Filtered overview (`WaveformOverviewType 0`;
  2.5 ignores a skin `Type` node) with the same `<SignalStacked>`, its colours
  the `Signal*Color` nodes, normalized by `OverviewNormalized`. Beat and
  downbeat lines are 3 px wide (the fork's `<BeatWidth>`; stock draws a
  one-pixel hairline).
- **Audio buffer — `latency="3"` in `soundconfig.xml` can cause crackling.**
  It's set low on purpose, for responsiveness. **If crackling is really a
  problem, put it back to `4`** — that's the known-good value and the only
  change needed.

  `latency` is an index, not milliseconds: `frames = bit_ceil(samplerate_khz)
  << (latency-1)`, so at 44.1 kHz `3` = 256 frames = 5.8 ms and `4` = 512 =
  11.6 ms. It's worth more than plain output latency because Mixxx filters the
  `jog` pitch-bend control through a 25-tap moving average whose taps are
  *buffers*, not ms (`ratecontrol.cpp`) — so bend smear is 25 × buffer: ~145 ms
  at `3` vs ~290 ms at `4`. **Scratch does not go through that filter** and
  barely notices the buffer, so this only buys bend responsiveness.

  The trade is real and measured: `3` produced 12 genuine DAC underruns
  (`underflowHappened code: 6`) during 13 s of scratching, where `4` produced
  none under identical conditions. Scratching is the load that breaks it — idle
  is always clean. Two gotchas when checking this yourself: Mixxx only logs
  underruns when launched with `--developer` (`~/.xinitrc`), and that flag locks
  inside the audio callback so it can *cause* dropouts — take it back off
  afterwards. The skin's XRUN readout won't settle it either: it counts every
  underflow source, including the harmless network device (codes 24/25), and it
  read "low" at `3` while PortAudio was dropping buffers. Only code `6` means
  the DAC.

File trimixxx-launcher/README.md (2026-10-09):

# trimixxx-launcher

**Decides what the deck is at boot, and does the system-level things Mixxx
cannot do itself.**

```
boot ─▶ ttymidi ─▶ trimixxx-launchd ─▶ /run/trimixxx/mode ─▶ getty@tty1 ─┬─▶ Mixxx
             │            │                                             ├─▶ Doom
        deck MIDI ────────┤                                             └─▶ debug console
                          │
                          └─▶ trimixxx-deckkeys ─▶ /dev/uinput ─▶ a keyboard + a mouse
```

Two binaries:

| | |
| --- | --- |
| **`trimixxx-launchd`** | the launch manager and the SysEx daemon. Root, systemd, one instance. |
| **`trimixxx-deckkeys`** | turns the deck's MIDI into a virtual keyboard and mouse. Started by `launchd`, only for the modes that need it. |

> Previously `pi-midi-daemon`. The binary and the unit were renamed; the
> **virtual MIDI port is still called `pi-midi-daemon`**, because Mixxx keys its
> controller bindings off the device name (`mixxx_config/mixxx.cfg`) and
> renaming it would silently orphan the mapping.

## Why one daemon does both

Mixxx has no way to touch the operating system. Its controller scripts run in a
bare `QJSEngine` whose entire API is control values, timers and MIDI I/O — no
file, process, shell or network access — and skins are only XML/QSS. **MIDI is
the one channel out of Mixxx**, and SysEx is the only MIDI message that carries
an arbitrary payload. So this daemon opens a virtual MIDI port, Mixxx enables it
as an ordinary controller, and asks for system actions by sending SysEx to it.

The launch-manager half arrived almost for free. Choosing the boot mode means
*reading a button on the deck*, which is MIDI; acting on it means starting things
as root; and this unit's readiness gate is already what releases `getty@tty1`,
hence the session, hence the app. It was one step away from being the launch
manager, so it is.

## Modes

| Mode | Boot gesture | What runs |
| --- | --- | --- |
| `mixxx` | *nothing* — the default | X → Mixxx, as always |
| `doom` | **hold PLAY** from power-on | X → `trimixxx-doom` ([`../doom`](../doom)) |
| `debug` | **hold CUE** from power-on | a text console on tty1, **no X** |

**Hold the button from power-on and let go when the play/cue LEDs start
blinking.** The blinking is the window opening — on a unit whose screen is still
black, it is the only feedback there is. The chosen button then flashes to
acknowledge.

### Why it watches for the *release*

The obvious implementation — "is the button down?" — cannot work, and the reason
is worth writing down.

The firmware sends a Note-On when a button becomes held, *including* one already
held when the S3 boots (its debounced level starts `false`, so a button held at
power-on reads as a fresh press). But the S3 is up about half a second after
power-on and this daemon about twenty seconds after that. **That Note-On is long
gone**: ttymidi did not exist to carry it, nothing retransmits, and the firmware
has no "report current button state" SysEx to ask with.

What survives is the **release**. A button held through the whole boot sends its
Note-Off the moment the finger lifts — and a Note-Off with no Note-On before it
means exactly one thing: *this was already down when I started listening*. So
either edge selects: a lone Note-Off is the hold, a Note-On is someone pressing
during the window. Nobody touches the deck at boot otherwise, so nothing is
ambiguous.

Cost: `--select-window` (3 s) on every boot. Adding a state-report command to the
firmware would remove it — that is the upgrade path, and it needs a reflash.

### `/run/trimixxx/mode`

One file, one meaning: *the mode the deck should be in*. It is the state **and**
the request channel, for anything that can write a file:

```sh
ssh trimixxx-pi 'echo doom  | sudo tee /run/trimixxx/mode'   # switch now
ssh trimixxx-pi 'echo mixxx | sudo tee /run/trimixxx/mode'   # and back
```

`launchd` polls it once a second and makes reality match: it starts or stops
`deckkeys`, and restarts `getty@tty1` **only if something is definitely running
the wrong app**. "Nothing is running" means a session is already in flight — the
normal case when Doom has just exited and handed the mode back — and restarting
on top of that would kill the session that is already doing the right thing.

It lives on **tmpfs on purpose**: a wedged Doom, a debug screen someone walked
away from, a botched experiment — none of them survive a power cycle. There is no
persistent default mode, and there should not be one.

## Ways out, in order of increasing desperation

The deck has no keyboard. Every one of these works from the deck itself, and each
is independent of the ones above it.

1. **Quit the app normally.** Doom: Esc → Quit Game → y, all on the ring pads.
2. **Panic chord — hold LOOP IN + LOOP OUT together for 2 s.** Strafe left and
   strafe right at once: the one combination nobody holds by accident, because
   they cancel out. `launchd` sees it straight off the MIDI, whatever is on
   screen, and puts the deck back into Mixxx. Ignored in Mixxx mode, where those
   are real loop buttons.
3. **ssh**, and write the mode file. Which is why —
4. **Power cycle.** tmpfs. You get Mixxx.

### ssh and wifi come up first, always

`trimixxx-launchd.service` is ordered `After=` `NetworkManager.service`,
`network-online.target` and `ssh.service`. By the time anything in the launcher
can go wrong, **the deck is already reachable**, and it stays reachable whatever
the launcher then does.

Ordering *only* — deliberately no `Requires=`/`BindsTo=` and no
`Wants=network-online.target`. At a gig there is no wifi, and a deck that will
not boot without one is a deck that does not boot. Nothing blocks on the network
either: measured on the deck, `NetworkManager-wait-online` reaches
`network-online.target` in ~8 s and `ssh.service` is listening in ~213 ms, both
well before this unit's own dependencies (ttymidi, sound) are done — so the
ordering is free and waiting on top of it would buy nothing.

The other half of the same promise is the **failsafe default**: if `launchd`
fails outright, its readiness gates give up (bounded at 30 s and 25 s) and
`getty@tty1` is released anyway; with no mode file, `~/.bash_profile` and
`~/.xinitrc` both fall through to Mixxx. A launch manager that cannot answer must
not be able to stop the deck from being a deck.

## Wire format

```
F0 7D <opcode> [args] F7
```

- `7D` is the SysEx manufacturer ID the MIDI spec **reserves for non-commercial /
  educational use**, so it can never collide with a real vendor's messages.
- Messages with any other manufacturer ID are ignored, as are unknown opcodes.
- The `F0`/`F7` framing is optional — the daemon accepts the body either way,
  since drivers differ on whether they hand it over.

Opcodes are blocked by direction and by kind, so a MIDI dump reads unambiguously.

**`0x0x` — commands, Mixxx → daemon** (do this to the machine):

| Opcode | Action | Runs |
| --- | --- | --- |
| `0x00` | `ping` | nothing (logs only) |
| `0x01` | `shutdown` | `systemctl poweroff` |
| `0x02` | `reboot` | `systemctl reboot` |
| `0x03` + `"SLOT"` | `switch-slot` | `rauc status mark-active other`, then `systemctl reboot` |

`ping` exists to prove the whole Mixxx→daemon path works without powering the
deck off.

`switch-slot` is Diagnostics' RESTART on a release card: the deck restarts
into its other A/B slot as a trial (`F0 7D 03 53 4C 4F 54 F7`). RAUC has the
backend arm the firmware's tryboot for that slot
(`pi_config/rauc/rpi-tryboot set-primary`), and the health check
(`pi_config/trimixxx-health`) keeps it if the deck comes up with a network and
ssh, or falls back to the slot committed before. A step that fails ends the
action, so on a dev card, which has no RAUC, nothing reboots. It carries magic,
as the mode commands below do, because it changes what the deck boots.

**`0x1x` — events, daemon → Mixxx** (this happened):

| Opcode | Event | Meaning |
| --- | --- | --- |
| `0x10` | `usb-mounted` | a DJ stick appeared at `/media/DJ_USB_*` |
| `0x11` | `usb-unmounted`| one went away (unmounted, or yanked) |

Events carry **no payload** — which slot it was is not something Mixxx needs; it
just rescans. Both must match `PiMidiDaemon.scripts.js`.

**`0x2x` — mode commands, Mixxx → daemon** (be something else):

| Message | Mode |
| --- | --- |
| `F0 7D 20 4D 49 58 F7` (`"MIX"`) | back to Mixxx |
| `F0 7D 21 44 4F 4F 4D F7` (`"DOOM"`) | Doom |
| `F0 7D 22 44 42 47 F7` (`"DBG"`) | the debug console |

Each carries **magic**, following the firmware's own precedent for its reset
command (`F0 7D 02 52 53 54 F7`, `"RST"`): a stray or corrupt SysEx must not be
able to drop a live set into Doom. A bare `F0 7D 21 F7` does nothing.

### Security

The daemon runs as **root**, because performing privileged system actions is its
entire purpose; doing it directly avoids a `sudoers` rule.

What keeps that safe is that **the opcode only selects an entry from a fixed
table in `sysex.go`**. No byte from the MIDI stream is ever interpolated into a
command, and nothing is passed through a shell (`exec.Command`, not `sh -c`);
argument bytes are only ever compared against a constant. There is deliberately
no "run this string" opcode, and there must never be one.

**The trust boundary is the MIDI port itself**: anything that can send SysEx to
`pi-midi-daemon` can power the machine off. On a single-user appliance that is
acceptable — it is equivalent to having a power button.

## trimixxx-deckkeys

Reads the deck's MIDI and replays it into the kernel through `/dev/uinput` as a
**virtual USB keyboard and mouse**. Everything above the kernel — X, the console,
SDL — then sees ordinary input, which is what lets an **unmodified** Doom be
played on a DJ deck. See [`../doom`](../doom) for the full story and the control
chart.

```sh
trimixxx-deckkeys --map doom --print-map      # the chart, from the real table
trimixxx-deckkeys --map doom --dry-run        # log the keys instead of typing
```

| Flag | |
| --- | --- |
| `--map doom\|console` | which table to run |
| `--jog-scale 1.8` | mouse pixels per jog tick — the turn speed (tuned on the deck, 6 → 3.6 → 1.8) |
| `--jog-invert` | on by default: the wheel's quadrature counts the opposite way round from mouse X, so without it left turns right |
| `--fader-deadzone 0.15` | fader travel around centre that means "stand still" |
| `--fader-run 0.60` | travel past which walking becomes running |
| `--fader-invert` | swap which end of the fader walks forward |
| `--lights` | on by default: colour the deck's buttons to show what they do |
| `--dry-run` | no `/dev/uinput`, no root; prints what it would press |

`--dry-run` is also the way to see what the deck is sending on a *live* deck: it
creates no input devices, so a second instance can be run alongside the real one
as a passive probe without touching the game.

`launchd` starts exactly one instance, only for `doom` and `debug`, and stops it
with SIGTERM so it can release every held key on the way out — a stuck Ctrl would
outlive the process and there is no keyboard on the deck to undo it with.
**Never in Mixxx mode**: Mixxx speaks MIDI itself, and a virtual keyboard typing
Doom keys at a live set would be a disaster.

The mapping tables live in `internal/keymap/` and have tests: every bound note
must be a control the firmware actually sends, and every emittable key must be
declared to the uinput device (the kernel silently drops undeclared codes, which
looks exactly like a broken mapping).

## Watching for DJ sticks

`../pi_config/dj-usb` mounts sticks read-only at `/media/DJ_USB_1` / `DJ_USB_2`.
The daemon polls that glob (`--usb-glob`, `--usb-poll`) and reports each
mountpoint appearing and disappearing exactly once.

**Why polling and not inotify/udev**, which looks like the obvious answer:
`dj-usb` does `mkdir` and only *then* `mount`, so inotify's `IN_CREATE` fires on
an empty, not-yet-mounted directory — Mixxx would rescan nothing and miss the
stick. inotify cannot see the mount itself at all. So instead of watching the
directory, the daemon tests whether the path is *really a mounted filesystem*
(comparing its `st_dev` against its parent's) on a timer. That is true regardless
of how the mount got there, needs no extra dependency, and a couple of seconds of
latency is nothing for a library refresh.

Mounts that already exist at startup are treated as the baseline and reported to
nobody: this unit starts before Mixxx, so an event fired then would go nowhere.

## Layout

```
cmd/launchd/      the daemon: mode selection, mode switching, SysEx, USB events
cmd/deckkeys/     the MIDI -> uinput bridge
internal/midimap  transcription of the firmware's MidiMap.hpp -- the addresses
internal/deck     the link to ttymidi's ALSA port: events out, LEDs in
internal/uinput   virtual input devices; raw ioctls, no cgo
internal/keymap   what each control does in each mode (doom.go, console.go)
```

Listening to the deck *alongside Mixxx* works because ttymidi creates its ports
`SND_SEQ_PORT_CAP_SUBS_READ`/`SUBS_WRITE` — subscribable, not exclusive. Neither
side knows the other is there.

## Build

**Ship builds are fully static** — the same trick as the `ttymidi` fork: Alpine +
musl inside Docker, linked static (musl + ALSA + libstdc++), so the binaries run
on Raspberry Pi OS with **no runtime dependencies at all**.

```bash
make docker-arm      # -> dist/trimixxx-launchd, dist/trimixxx-deckkeys
```

```
dist/trimixxx-launchd:  ELF 64-bit LSB executable, ARM aarch64, statically linked, stripped
dist/trimixxx-deckkeys: ELF 64-bit LSB executable, ARM aarch64, statically linked, stripped
```

Three things this build has to get right:

- **Alpine ships no static `libasound.a`** (same trap ttymidi hit), so alsa-lib
  is compiled from source with `--enable-static`.
- **cgo must be told to link statically** (`-linkmode external -extldflags
  "-static"`); a plain `go build` with cgo is dynamic.
- **rtmidi is C++** — it's vendored inside gomidi, so `librtmidi-dev` is never
  needed, but the image does need `g++` and a static `libstdc++`.

`uinput` adds nothing to any of that: it is raw ioctls against `/dev/uinput`, so
the bridge needs no library at all — which is why the syscall numbers are
precomputed in `internal/uinput` rather than pulled in through cgo.

The Dockerfile asserts `readelf -d` finds no `NEEDED` entries in either binary,
so a build that would need a runtime loader fails rather than shipping.

Target arch defaults to `linux/arm64`; for a 32-bit Pi OS use
`make docker-arm ARM_PLATFORM=linux/arm/v7`.

For hacking on this machine, `make all` does native **dynamic** builds, which do
need cgo + ALSA headers (`libasound2-dev`, build-time only). `make test` runs the
protocol, mapping and gesture tests and needs neither. `make chart` prints both
control charts.

## Install

```bash
pi-qemu deck deploy TARGET launcher   # docker-arm + scp + enable/restart the service
```

TARGET is an emulated deck's name, or `--host ALIAS` for a real one. The step is
[`../pi-qemu/deploy/003_launcher.sh`](../pi-qemu/deploy/003_launcher.sh).
This also **removes the old `pi-midi-daemon` service** if it is still installed —
two daemons fighting over the same virtual port name would be a confusing way to
spend an evening.

The session side (`~/.bash_profile`, `~/.xinitrc`, the debug console stub) is
installed by the `system` deploy step
([`../pi-qemu/deploy/002_system.sh`](../pi-qemu/deploy/002_system.sh)); Doom
itself by the `doom` step (see [`../doom`](../doom)).

The unit is ordered `Before=getty@tty1.service` and holds it back through two
gates: the ALSA port really existing, and the mode having been chosen. The first
is the same gate `trimixxx-bridge.service` uses, for the same reason — **Mixxx
enumerates MIDI devices once at startup**, so a port that appears late is one
Mixxx never lists. The second is what makes the boot gesture work at all.

## Mixxx side

In **Preferences → Controllers**, `pi-midi-daemon` appears as a MIDI device.
Enable it and load its mapping. That mapping is what turns a Mixxx control into a
SysEx command — an `<output>` can only emit 3-byte messages, so the SysEx is sent
from a small script via `midi.sendSysexMsg()`, which is legal there because the
script is bound to *this* controller's port. (A controller script can only send
to its own device's port, which is exactly why this daemon gets its own mapping
rather than being driven from `TriMixxx.scripts.js`.)

Adding a **DOOM button** to the skin is the same shape as the existing power
menu: a skin control, a `makeConnection`, and `midi.sendSysexMsg([0xF0, 0x7D,
0x21, 0x44, 0x4F, 0x4F, 0x4D, 0xF7])`. Not wired up — the boot gesture and the
mode file are enough to use it.

## Testing

Run it without touching the machine:

```bash
./trimixxx-launchd --dry-run             # logs actions instead of running them
./trimixxx-launchd --mode doom           # skip the gesture, force a mode
./trimixxx-launchd --select-window 10s   # a longer window to fumble in
./trimixxx-launchd --usb-glob '/tmp/usbtest/DJ_USB_*' --usb-poll 500ms
```

The USB one is how to exercise the events without a stick: point the glob at a
scratch directory and mount anything there (`hdiutil attach` on macOS, `mount -o
loop` on Linux). Creating the directory alone must *not* fire an event — only a
real mount does.

Then send it a command by hand (alsa-utils):

```bash
aseqsend -p pi-midi-daemon F0 7D 00 F7                # ping
aseqsend -p pi-midi-daemon F0 7D 01 F7                # shutdown
aseqsend -p pi-midi-daemon F0 7D 21 44 4F 4F 4D F7    # go to Doom
```

And to watch what the deck itself is sending — which is what the boot gesture
reads:

```bash
aseqdump -p TriMixxx
```

`journalctl -u trimixxx-launchd -f` shows the decision, the mode, and everything
`deckkeys` logs.

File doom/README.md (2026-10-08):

# doom — the deck plays DOOM (1993)

**Hold PLAY while the deck boots, and it comes up as Doom instead of Mixxx.**

The jog wheel turns. The tempo fader is the throttle. The seven pads of ring A
are the seven weapons. Ring B is the menu. Play is fire.

```
hold PLAY at power-on ──▶ launchd ──▶ /run/trimixxx/mode = doom ──▶ ~/.xinitrc ──▶ chocolate-doom
                                          │
                                          └─▶ trimixxx-deckkeys --map doom
                                                    │
                          deck MIDI ────────────────┴──▶ /dev/uinput ──▶ a keyboard + a mouse
```

## How this works at all

Doom is **unmodified** — a stock, packaged `chocolate-doom`. There is no engine
fork in this repo, no MIDI support in the game, no patched input layer.

The trick is one level down: [`trimixxx-deckkeys`](../trimixxx-launcher) reads
the deck's MIDI (the same ALSA stream Mixxx normally uses) and replays it into
the kernel through `/dev/uinput` as a **virtual USB keyboard and mouse**. From
Doom's point of view, somebody is playing on ordinary hardware.

Three things fall out of that, all of them the reason it was done this way:

- **Nothing to maintain.** The engine is `apt install`. The mapping is a Go
  table ([`internal/keymap/doom.go`](../trimixxx-launcher/internal/keymap/doom.go)),
  so changing what a pad does is a table edit, not a port.
- **The jog wheel can be an analogue turn axis.** No keyboard can express "turn
  seven degrees"; a mouse can, and a jog wheel *is* a rotary control. This is
  the one input on the deck that is better than a real keyboard.
- **The same device serves the rescue console.** The deck has no keyboard port.
  A virtual keyboard driven from its own buttons is what makes a debug screen
  usable at all — see `--map console`.

## Controls

`trimixxx-deckkeys --map doom --print-map` prints this from the actual table, so
it can never quietly drift from what the deck does:

| Deck control | Sends | Light | Does |
| --- | --- | --- | --- |
| **jog wheel — touch it** | ctrl | — | **fire** |
| **jog wheel — turn it** | mouse X | — | **turn** |
| **tempo fader** | ↑ / ↓ / +shift | — | stand still, walk, run — forward and back |
| **play** | `]` | lit | next weapon |
| **cue** | space | lit | use / open door |
| loop in / loop out | `,` / `.` | lit | strafe left / right |
| reloop | shift | *no LED* | run (hold) |
| track encoder | ↑ / ↓ | — | menu up / down |
| encoder press | enter | — | select |
| ring A, pads 1–7 | 1–7 | 7 colours | fist, pistol, shotgun, chaingun, rockets, plasma, BFG |
| **ring B, pad 1** | ↓ | **red** | **walk backward** / menu down |
| **ring B, pad 2** | ↑ | **green** | **walk forward** / menu up |
| ring B, pad 3 | esc | yellow | menu / back |
| ring B, pads 4–5 | ← → | blue / cyan | menu left / right, turn |
| ring B, pad 6 | y | white | confirm quit |

**Fire is the jog wheel's touch sensor.** Rest a hand on the platter and the gun
goes off — the same hand that aims is the one that shoots, which means you
cannot turn without firing. That is the point, not an oversight.

**Red walks backward, green walks forward**, on two adjacent ring B pads,
because that is what those colours mean everywhere else. It costs nothing to
honour: Doom's walk-forward/back and its menu cursor are the *same two keys*, so
one pad is both "walk forward" and "menu up" with no ambiguity.

Ring A has exactly seven populated nodes and Doom has exactly seven weapons.
Ring B has six, and a menu needs exactly Esc, four cursors and a confirm. That
is a coincidence, and it was too good to waste.

**The tempo fader as a throttle** is the other one worth explaining: a
centre-detented linear fader is already a forward/back speed lever. Past the
deadzone it walks, past 60 % of travel it runs. The deadzone is not optional —
the fader is a bare pot on an ADC and its centre wanders by a few counts, which
without it would mean drifting into a wall while standing still.

**Weapon cycling is PLAY, and it taps `]` rather than a digit.** That is a fix
rather than a preference: a digit selects one specific weapon, and selecting a
weapon you do not own does nothing at all — so at the start of E1M1, where five
of the seven are missing, cycling the digits produced no visible change and the
control felt dead. (A passive `--dry-run` probe on the live deck confirmed the
MIDI was arriving and the digits were being pressed correctly the whole time;
the game was simply ignoring them.) Doom's own weapon cycling skips what you are
not carrying, so every press does something. It is the one binding here that
Chocolate Doom leaves unbound by default, which is why `default.cfg` sets
`key_prevweapon` / `key_nextweapon`.

## Lights

The deck paints itself when it becomes a Doom controller, and goes dark again
when it stops. `trimixxx-deckkeys` does it from the same table the keys come
from, repainting every few seconds.

**Why repainting, and not once at startup.** Switching modes starts the key
bridge while the *outgoing* Mixxx is still being SIGTERMed — and Mixxx's
controller script blanks every ring LED on its way out (`TriMixxx.shutdown`,
"Clear every ring button LED"). A single paint lands a second or two before
that and gets wiped, which looks exactly like a deck that never lit up. It was
this bug, and the first theory (that a 143-byte burst of SysEx was overrunning
the S3's UART) was wrong: measured on the deck, a burst lights it exactly as
well as the same messages spaced 25 ms apart. Repainting also heals an S3 that
has been reset mid-game, and costs ~155 bytes every few seconds on a link that
carries more than that from one flick of the jog wheel.

**Ring A — the weapons.** Ramped by how much they hurt, except the last three,
which take the colours the game itself uses:

| Pad | Weapon | Colour | |
| --- | --- | --- | --- |
| 1 | fist / chainsaw | white | `#FFFFFF` |
| 2 | pistol | yellow | `#FFBE00` |
| 3 | shotgun | orange | `#FF5000` |
| 4 | chaingun | red | `#FF0000` |
| 5 | rocket launcher | violet | `#A000FF` |
| 6 | plasma rifle | cyan | `#00B4FF` |
| 7 | BFG 9000 | green | `#00FF00` |

**Ring B — the menu.** One colour per direction, so a cursor key can be picked
out without counting round the ring:

| Pad | Function | Colour | |
| --- | --- | --- | --- |
| 1 | **walk backward** / menu down | red | `#FF0000` |
| 2 | **walk forward** / menu up | green | `#00FF00` |
| 3 | esc / back | yellow | `#FFBE00` |
| 4 | left / turn | blue | `#003CFF` |
| 5 | right / turn | cyan | `#00FFB4` |
| 6 | confirm quit (`y`) | white | `#FFFFFF` |

The two rings repeat white, red and green between them. They are physically
separate rings on opposite sides of the deck, so there is nothing to confuse;
*within* a ring every colour is unique, and a test enforces that.

**The single-colour lamps** — play, cue, loop in, loop out — can only be
switched on, not coloured, so they simply light to say "this one does
something". **Reloop stays dark whatever you do**: it has a button and a note
but no LED behind it on the loop board. Nothing to fix in software.

Colour travels as SysEx (`F0 7D 01 <node> …` for ring A, `03` for ring B), with
each 8-bit channel split into two nibbles because SysEx payload bytes must be
7-bit — a single byte would cap every channel at half brightness.
`trimixxx-deckkeys --lights=false` turns the whole thing off.

### Getting out

Everything below works from the deck alone, no keyboard:

- **Esc → Quit Game → y** — ring B pad 1, cursor down, encoder press, ring B pad 6.
- **Panic chord: hold LOOP IN + LOOP OUT together for 2 s.** Strafe left and
  strafe right at once — the one combination nobody holds by accident, because
  they cancel out. The launch manager sees it directly off the MIDI and puts the
  deck back into Mixxx.
- **Power cycle.** The mode lives on tmpfs, so a reboot is always Mixxx.

When Doom exits normally, `~/.xinitrc` starts Mixxx in the same session — Doom
is a one-shot, and cannot loop.

## Install

```sh
./fetch-wad.sh                                # downloads doom1.wad (shareware) into ./wad/
pi-qemu deck deploy --host trimixxx-pi doom   # engine + WAD + launcher + configs, onto trimixxx-pi
pi-qemu deck deploy NAME doom                 # onto an emulated deck instead
```

Then, from anywhere:

```sh
ssh trimixxx-pi 'echo doom | sudo tee /run/trimixxx/mode'   # switch now
ssh trimixxx-pi 'DISPLAY=:0 trimixxx-doom'                  # just look at it
```

### The WAD

`doom1.wad`, the **shareware episode** — which is what "can it run Doom?" has
always meant, and what everyone plays: E1M1, Hangar, that riff. It is not
committed here (4 MB of someone else's game), and `fetch-wad.sh` verifies what
it downloads: the `IWAD` magic always, and the published v1.9 hashes as a
warning if they do not match, since any of the six shareware releases plays.

| | |
| --- | --- |
| size | 4 196 020 bytes |
| md5 | `f0cefca49926d00903cf57551d901abe` |
| sha256 | `1d7d43be501e67d927e415e0b8f3e29c3bf33075e859721816f652a526cac771` |

The shareware episode has been freely redistributable since 1993 — that was the
entire point of shareware. The **full** `doom.wad` is not; if you own it:

```sh
./fetch-wad.sh --from ~/games/doom.wad
```

Chocolate Doom takes any IWAD, so Doom II and Ultimate Doom work the same way.

### Sound

SFX work out of the box, into the UCA222 (Mixxx is not running in this mode, so
the card is free). **Music ships off**, deliberately: the config value that
selects OPL emulation versus native MIDI has moved between Chocolate Doom
builds, and guessing wrong is either silence or an error at startup. One command
fixes it properly, and writes the right number into the same file:

```sh
chocolate-doom-setup     # Configure Sound -> Music: OPL (Adlib)
```

OPL is the authentic 1993 sound and needs no soundfont or extra packages.

## Files

| File | What |
| --- | --- |
| `fetch-wad.sh` | downloads and verifies `doom1.wad` into `wad/` (gitignored) |
| `../pi-qemu/deploy/007_doom.sh` | the `doom` deploy step: engine + WAD + launcher + configs onto the Pi |
| `trimixxx-doom` | the wrapper `~/.xinitrc` runs; finds the WAD, sets SDL up, execs the engine |
| `default.cfg` | Chocolate Doom's vanilla settings — **no `key_*` lines, on purpose** |
| `chocolate-doom.cfg` | fullscreen, aspect, mouse grab, no joystick |

**Why `default.cfg` binds no keys.** The deck's virtual keyboard is mapped onto
the keys Doom *already* binds by default. Key values in that file are Doom's own
internal codes — not Linux key codes, not ASCII — so hand-authoring them is the
easiest way in this whole feature to end up with a deck that presses nothing.
Bind to the defaults and there is nothing to get wrong; the mapping lives in
`doom.go`, which has tests.

## Status

Confirmed on the deck: Chocolate Doom **3.1.0** from apt, the WAD, the boot
gesture, the virtual keyboard and mouse under X, the jog wheel as the turn axis,
sound levels into the UCA222, and the lights — all 13 pads in colour and the 4
lamps. Tuned there too — `--jog-scale` is **1.8** px/tick (6 was far too fast to
aim with, and 3.6 still was) and `--jog-invert` is **on**, because the wheel's
quadrature counts the opposite way round from mouse X and without it left turns
right.

Still untested on hardware:

- `key_nextweapon` actually cycling from PLAY.
- Fire on the jog touch sensor.
- Which end of the tempo fader feels like "forward" (`--fader-invert` swaps it).

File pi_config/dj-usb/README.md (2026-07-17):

# DJ USB
This is installed on the Pi and lets us plug and yank USB sticks freely, safely, with no corruption of the stick's memory ever.

Mounts DJ sticks READ-ONLY at /media/DJ_USB_1 / /media/DJ_USB_2. Driven by
99-dj-usb.rules -> dj-usb@.service; not meant to be run by hand except to
debug.

Read-only is the whole safety model: with no writes there are no dirty pages,
so a stick can be yanked mid-set without corrupting a DJ's library. Mixxx
tolerates this -- its Rekordbox importer opens export.pdb and the ANLZ files
with std::ifstream::binary and parks everything it reads in Mixxx's own
database, never on the device.

The slot path matters and is not cosmetic. Mixxx's RekordboxFeature scans
/media, /media/$USER and /run/media/$USER, takes their IMMEDIATE children
only, and tests <child>/PIONEER/rekordbox/export.pdb. So /media/DJ_USB_1 is
found and /media/usb/DJ_USB_1 would not be.

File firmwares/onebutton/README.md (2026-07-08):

# OneButton firmware (CH32V003)

Two firmwares for the OneButton ring board (`../../boards/one_button/`):

| Project | What it is |
|---|---|
| `onebutton_node/` | Ring node: cut-through UART relay + 2× WS2812 + button. Every node runs this identical binary. |
| `onebutton_selftest/` | Single-board bring-up test. Flash this first to prove a board (LEDs, button, SWIO). |

Both are bare-metal [ch32fun](https://github.com/cnlohr/ch32fun) projects. ch32fun
is a **git submodule** at the repo root (`../../ch32fun`), pinned to a known commit —
the stock ch32fun tree is not committed into this repo, only a pointer to it.

## One-time setup on a new machine

1. **Get the submodules** (ch32fun + the SWIO adapter). Either clone with
   `git clone --recursive`, or in an existing clone run:
   ```sh
   git submodule update --init
   ```
   (If you forget, `make` auto-runs `git submodule update --init ch32fun` for you.)

2. **Install the RISC-V toolchain** — the xPack `riscv-none-elf-gcc` (bundles
   newlib; ch32fun auto-detects it). On macOS (Apple Silicon):
   ```sh
   ver=15.2.0-1
   curl -fL "https://github.com/xpack-dev-tools/riscv-none-elf-gcc-xpack/releases/download/v$ver/xpack-riscv-none-elf-gcc-$ver-darwin-arm64.tar.gz" \
     | tar -xz -C "$HOME/opt"
   # add to PATH (put this in your shell config):
   export PATH="$HOME/opt/xpack-riscv-none-elf-gcc-$ver/bin:$PATH"
   ```
   Linux/Windows: grab the matching asset from the
   [xPack releases](https://github.com/xpack-dev-tools/riscv-none-elf-gcc-xpack/releases).
   > Homebrew's `riscv64-elf-gcc` will **not** work — it ships no C library.

## Build

```sh
cd onebutton_node        # or onebutton_selftest
make                     # -> onebutton_node.bin  (build only, no flash)
make clean
```

## Flash (Pro Micro + Ardulink, no dedicated programmer)

The SWIO adapter firmware lives in `../swio-adapter/` (flash it onto a Pro Micro
first — see that folder's README). Then wire adapter → target and flash:

```
Pro Micro pin 8 (PB4) --[1k]--> CH32V003 SWIO
Pro Micro pin 9 (PB5) ---------> CH32V003 VDD
GND -------> GND
```
```sh
cd onebutton_node
../../../ch32fun/minichlink/minichlink -c /dev/cu.usbmodemXXXX -w onebutton_node.bin flash -b
```
`ls /dev/cu.*` to find the port. `minichlink` builds itself on first use. Every
ring node gets the same `onebutton_node.bin`.

## Notes

- `-march=rv32ec_zicsr` in both Makefiles: the node uses CSR instructions
  (`csrci/csrsi mstatus`), which modern GCC gates behind the `zicsr` extension.
  Kept in both Makefiles so the build pipelines are identical.
- The watchdog (`iwdg_init()`) resets the chip if you pause on a SWIO
  breakpoint — comment it out for single-step debugging.

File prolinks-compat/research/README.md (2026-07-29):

# ProLink protocol research

> **These are pre-hardware documents.** They are the literature review that
> started the project, written from published reverse-engineering work before a
> single packet had been captured from the author's own CDJs. They remain useful
> for context and for the many claims we have never tested — but a great deal
> has since been confirmed, and a good deal corrected, on real hardware.
>
> | | |
> |---|---|
> | **`docs/PROTOCOL.md`** | The current specification. **Implement from this.** |
> | `docs/FINDINGS.md` | How we know: every finding with its evidence, in the order learned, including the ones that turned out wrong. |
> | `research/00`–`09` (here) | The literature review. Where it disagrees with `PROTOCOL.md`, it is wrong. |
> | `research/10` | The approved Mixxx build plan (Phase B), still current. |

Research documentation for **prolinks-compat** — making the TriMiXxX unit (Mixxx
on a Raspberry Pi) interoperate with Pioneer CDJs over the Pro DJ Link / ProLink
Ethernet protocol. See `../CLAUDE.md` for the mission.

These docs synthesize the open-source reverse-engineering literature (chiefly
Deep-Symmetry/dysentery, plus prolink-connect and python-prodj-link) into a single
implementation-ready spec. Source repos live, git-ignored, in `ref-repos/`.

## Read in order

| Doc | Topic | Serves objective |
|---|---|---|
| [00-references.md](00-references.md) | The reference projects, what each is good for, and how the literature is biased toward *clients*. | — |
| [01-protocol-overview.md](01-protocol-overview.md) | Architecture, network topology (auto-IP), the full **port map**, the `Qspt1WmJOL` magic header, device-number conventions. | both |
| [02-device-discovery-and-keepalive.md](02-device-discovery-and-keepalive.md) | UDP 50000: announcement, the **device-number claim handshake**, keep-alive cadence, impersonation fields. | be seen |
| [03-status-and-beat-sync.md](03-status-and-beat-sync.md) | UDP 50002 status + 50001 beat: play state, tempo, sync/master handoff, on-air, mixer integration. | be seen / see others |
| [04-metadata-dbserver-protocol.md](04-metadata-dbserver-protocol.md) | TCP **remotedb/dbserver**: port discovery (12523), message wire format, menu requests, binary responses (art/waveform/cues). | **see + serve libraries** |
| [05-rekordbox-pdb-and-analysis.md](05-rekordbox-pdb-and-analysis.md) | The on-media **`export.pdb` (DeviceSQL)** and **ANLZ** analysis file formats. | see + serve libraries |
| [06-nfs-file-access.md](06-nfs-file-access.md) | The **NFS/RPC** path: portmap/mount/nfs to pull `export.pdb`, ANLZ, art, audio directly. | see + serve libraries |
| [07-appearing-as-a-legit-cdj.md](07-appearing-as-a-legit-cdj.md) | **Synthesis & strategy**: the Virtual CDJ approach, the device-number tradeoff, the consume-vs-serve asymmetry, a prioritized capability checklist, and the open questions to resolve with hardware captures. | both |
| [08-python-poc-plan.md](08-python-poc-plan.md) | Phase-2 build plan: package layout + testable milestones M0–M5. *(superseded by doc 10)* | both |
| [09-mixxx-integration-notes.md](09-mixxx-integration-notes.md) | Phase-3 notes for porting into Mixxx and upstreaming. *(licensing section corrected by doc 10)* | both |
| **[10-mixxx-prolink-implementation-plan.md](10-mixxx-prolink-implementation-plan.md)** | **The approved build plan.** Decisions taken, licensing rules, the Python PoC milestones M0–M11 and their hardware experiments, and the full Mixxx C++ design (module layout, threading, sidebar tree, track caching, registration touchpoints, risks). | both |

## TL;DR for the impatient

- **The network**: link-local Ethernet (169.254.x.x auto-IP). Every DJ Link packet
  starts with the 10-byte magic `51 73 70 74 31 57 6d 4a 4f 4c` ("Qspt1WmJOL").
- **Ports**: UDP **50000** discovery/keep-alive, **50001** beat, **50002** status;
  TCP **12523** to discover the dynamic **dbserver** port; UDP **111** portmap →
  dynamic **mount/NFS** ports. (Doc 01 has the full table.)
- **Being accepted is cheap**: there is no authentication. Broadcast a CDJ-style
  keep-alive every ~1.5 s after winning the device-number claim handshake.
- **Consuming libraries (objective 1) is well-trodden** — clone what
  python-prodj-link/prolink-connect already do: query dbserver and/or download &
  parse `export.pdb` over NFS.
- **Serving our library (objective 2) is greenfield** — no open-source project
  implements the CDJ-impersonating *server*. It requires standing up dbserver
  and/or NFS-v2 servers and generating a valid `export.pdb`/ANLZ from Mixxx's
  library, and must be validated with packet captures from the two CDJ-2000NXS.

## Conventions in these docs

- Facts are tagged **(confirmed)** (verified against hardware per the sources),
  **(inferred)** (deduced from client code/captures), or
  **(untested-needs-capture)** (must be checked on the real NXS units).
- Non-obvious facts cite their source inline, e.g. `(startup.adoc)` or
  `(prolink-connect remotedb/index.ts)`.

## Top open questions to resolve with hardware captures

1. ~~**Does an NXS LINK-browse drive the dbserver menu protocol, pull `export.pdb`
   over NFS, or both?**~~ **Answered from the literature.** dysentery
   `menus.adoc:19`: requesting the root menu "is what a player will do when you use
   the *Link* button to connect to media mounted on another player." Corroborated by
   `missing.adoc:14-18` (a booting CDJ opens two TCP connections to its peer: 12523
   for port discovery, then 1051 for the Link Info track data). **LINK-browse is
   dbserver.** NFS is a parallel surface that no CDJ *client* is known to use — it is
   how open-source tools bypass the dbserver's player-number limits.
   **Reframed, and now the more important question:** *how do the audio bytes travel
   when a CDJ actually loads and plays a track off another player's USB?* dbserver
   serves metadata, waveforms and cues, not audio. NFS is the only file-transfer
   surface the CDJs expose, so it is the strong candidate — but no source here states
   it. This gates whether TriMiXxX can be *played from*, not merely *browsed*.
2. **Does a CDJ-2000NXS serve NFS at all?** Doc 06 §1's "confirmed" rests on an
   **XDJ** capture, not an NXS (a 2012 unit). This is the go/no-go gate for the whole
   chosen transport — see doc 10, experiment E4.
3. Byte-faithful NXS keep-alive/status fields — exact name casing (`CDJ-2000nexus`
   is inferred), packet sizes.
4. What advertisement makes an NXS offer *us* as a LINK source.
5. Whether an NXS accepts a foreign-generated pdb/ANLZ tree over NFS.

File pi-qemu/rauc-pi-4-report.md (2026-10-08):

# TriMixxx A/B updates: the report, for builders

The Markdown form of the visual report (`rauc-pi-4-report.html`). It's written
for an agent that builds the system: every diagram is here as text (Mermaid),
with the rendered figure beside it for people.

| File | Role |
|---|---|
| `PLAN.md` | **What to do, in order**: phases, tasks, tests, stop points. Start there |
| this file | **How the system works**: the report's ten sections, in text |
| `rauc-pi-4-setup.md` | **Design and evidence**: every configuration file, the research, the sources |
| `rauc-pi-4-report.html`, `rauc-pi-4-figures/` | The visual report and its figures |

Built and tested through phase 5 (2026-10-08): the card, the updates, and the
fault table, on the emulated deck and on trimixxx3, the bench Pi. The decks
come next.
Where this file and `PLAN.md` differ, `PLAN.md` wins.

---

## Vocabulary

| Term | Meaning |
|---|---|
| **Slot A / slot B** | One complete copy of the system: a FAT boot partition plus a SquashFS system partition. A = p2 + p5, B = p3 + p6 |
| **bootsel** | p1, a small FAT partition holding only `autoboot.txt`, the file that picks the slot. No firmware may live there: then a damaged `autoboot.txt` still starts A (measured) |
| **Committed slot** | The slot named by `[all] boot_partition` in `autoboot.txt`; it starts by default |
| **Trial start** | One start of the other slot, made by the firmware's one-shot **tryboot** flag |
| **Commit** | Rewriting `autoboot.txt` so the slot that passed its trial becomes the default |
| **RAUC** | The A/B updater (Debian `rauc` + `rauc-service`, 1.13). Installs bundles into the idle slot |
| **Bundle** | `trimixxx-<v>.raucb`: a signed file holding `boot.vfat` and `rootfs.squashfs` |
| **rpi-tryboot** | Our RAUC custom bootloader backend (~100 lines of shell, adapted from Rtone's) |
| **Health check** | Our systemd unit that, on a trial start, runs `rauc status mark-good` if the deck can take the next release (it's on a network and sshd runs), or `mark-bad` |
| **Identity unit** | Our systemd unit that applies the deck's name, wiring and accent from `/data` |
| **Dev deck** | The writable emulated deck (`pi-qemu image build`'s card) used for feature work, as today |
| **A/B deck** | An emulated deck booted from a release card image, used for update work |
| **trimixxx3** | The spare Pi 4, used as the bench deck |

---

## 1. The card

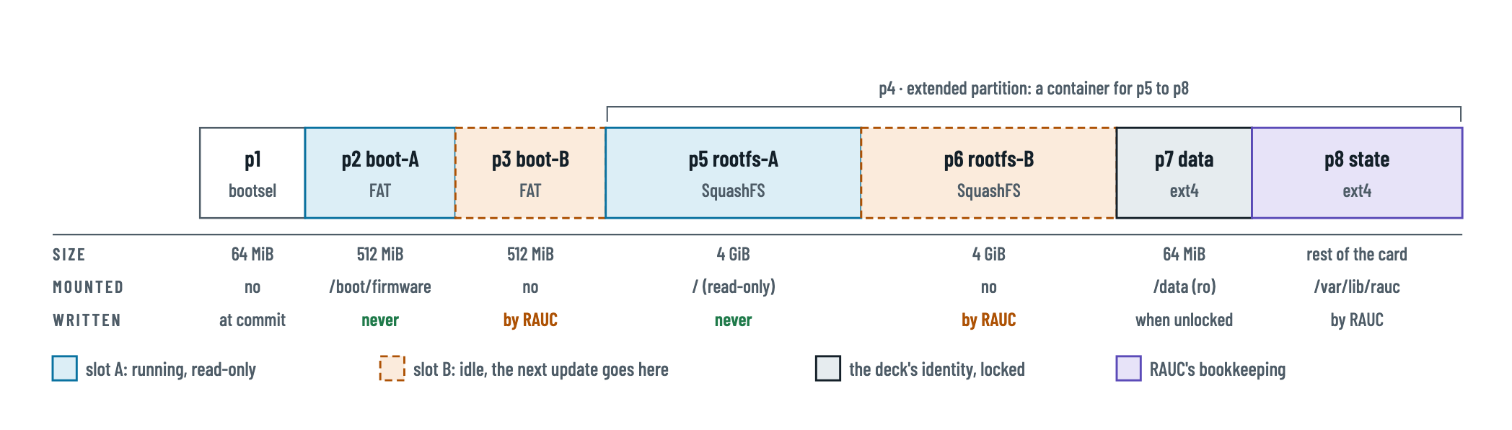
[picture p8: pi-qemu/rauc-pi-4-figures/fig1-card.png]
Figure 1: the card


```text
MBR, fixed disk signature 0x5d0bc1ec (<id> = 5d0bc1ec)
| p1 bootsel | p2 boot-A | p3 boot-B | p4 extended ───────────────────────────────────────────── |
| FAT32      | FAT32     | FAT32     | p5 rootfs-A  | p6 rootfs-B  | p7 data     | p8 state       |
| 64 MiB     | 512 MiB   | 512 MiB   | SquashFS 4G  | SquashFS 4G  | ext4 64 MiB | ext4, the rest |
```

| # | Holds | Mounted (slot A running) | Written |
|---|---|---|---|
| p1 bootsel | `autoboot.txt` | no | only at commit, by the backend |
| p2 boot-A | firmware, kernel, initramfs, DTBs, overlays, `config.txt`, `cmdline-a.txt`, `cmdline-b.txt` | `/boot/firmware`, read-only | **never** while A runs |
| p3 boot-B | the same files | no | by RAUC (idle slot) |
| p5 rootfs-A | the system, SquashFS | `/`, under the RAM layer | **never** while A runs |
| p6 rootfs-B | the next system | no | by RAUC (idle slot) |
| p7 data | deck name, Wi-Fi keyfiles, ssh host keys | `/data`, read-only | only when unlocked by hand |
| p8 state | RAUC's data directory, bundles | `/var/lib/rauc`, read-write | by RAUC |

- The image ends at about 13 GiB, so it fits any card of 16 GB or more; the
  rest of a bigger card stays unused.
- Only the **emulator's** card file must be a power of two; it is rounded up
  as a sparse file.

---
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

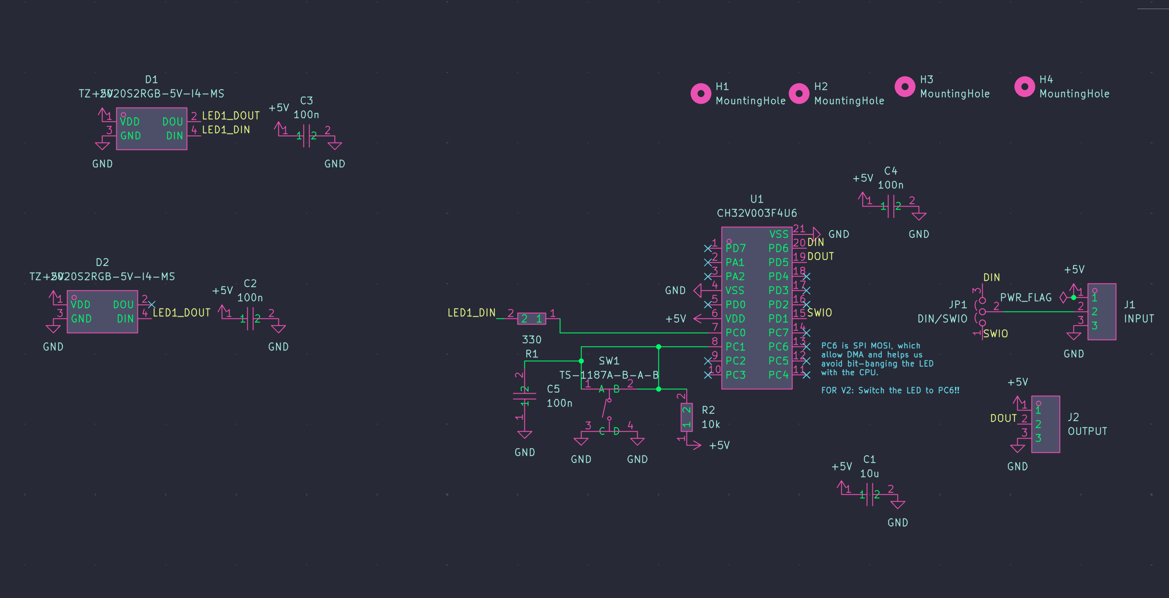
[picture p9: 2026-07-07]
boards/one_button/v1_schematic.png

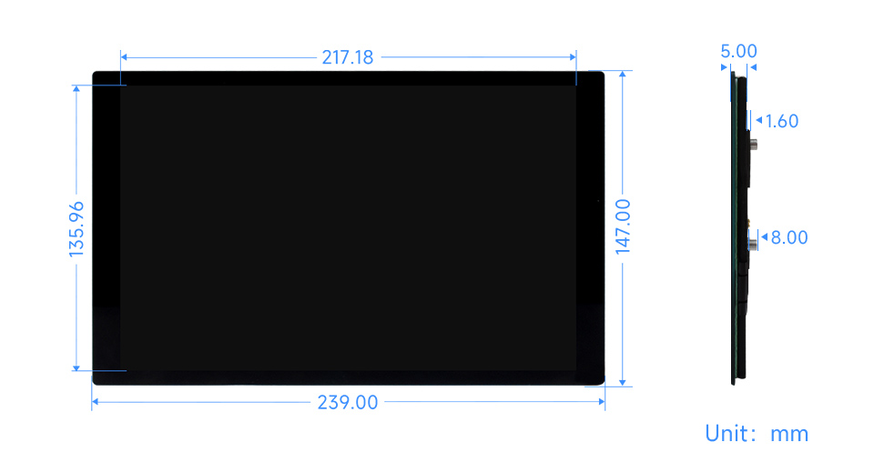
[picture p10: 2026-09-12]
ref_sizes/10.1inch-DSI-LCD-C-details-size.jpg

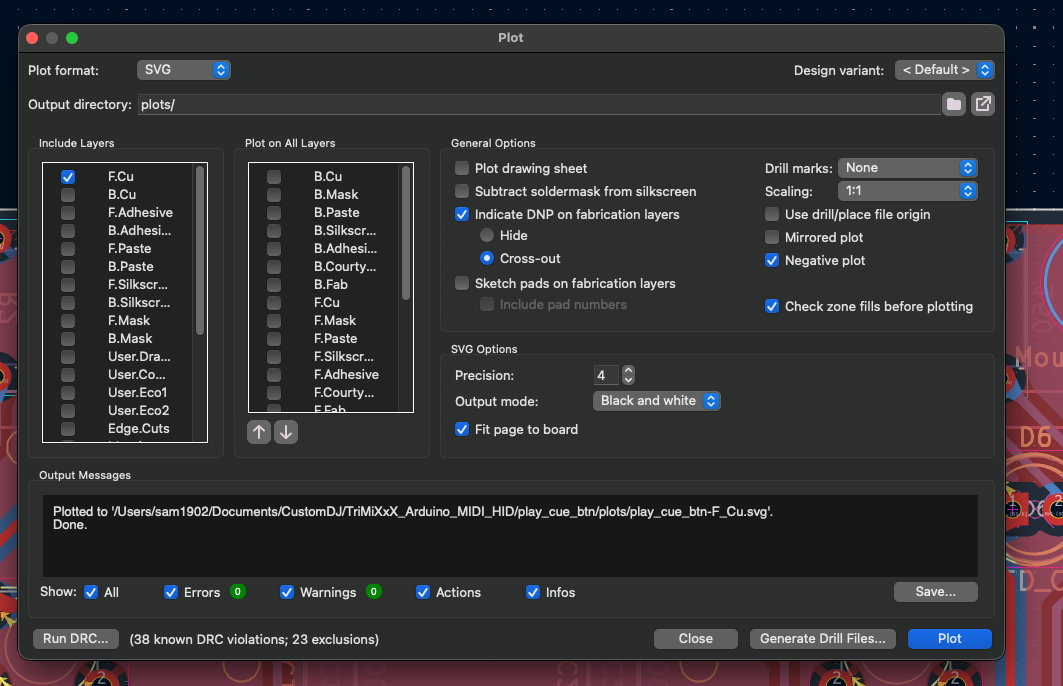
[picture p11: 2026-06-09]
handmade_pcb/export_kicad10_f_cu.png

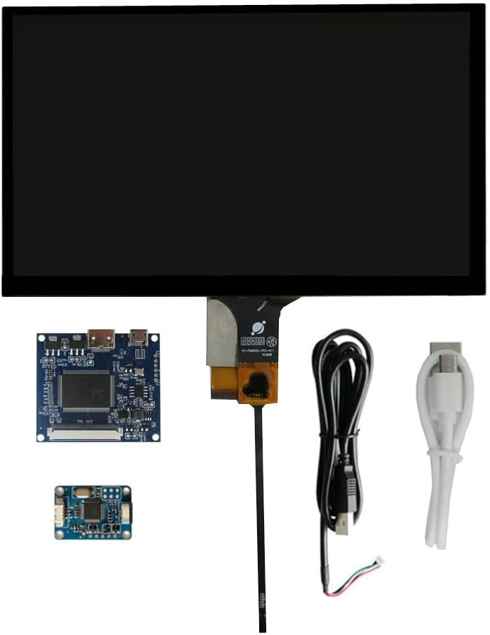
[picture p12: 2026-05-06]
ref_sizes/screen.raw.jpg

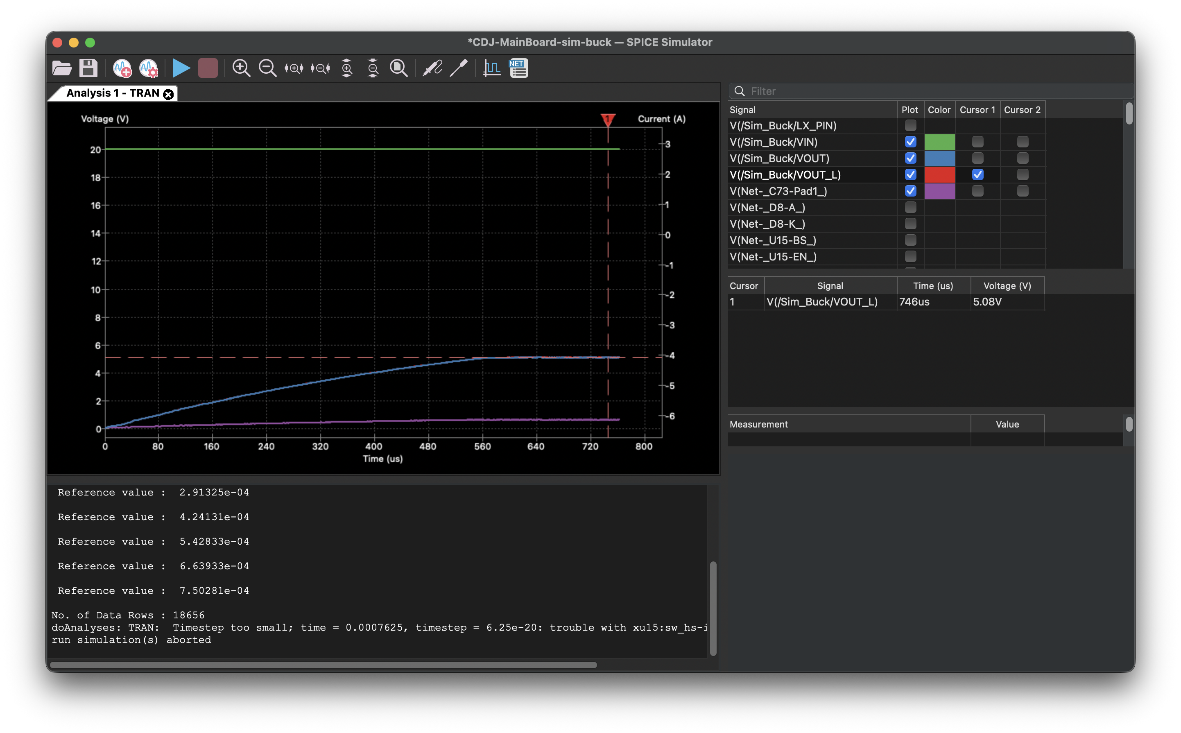
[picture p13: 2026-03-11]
screenshots/buck_converter_spice.png

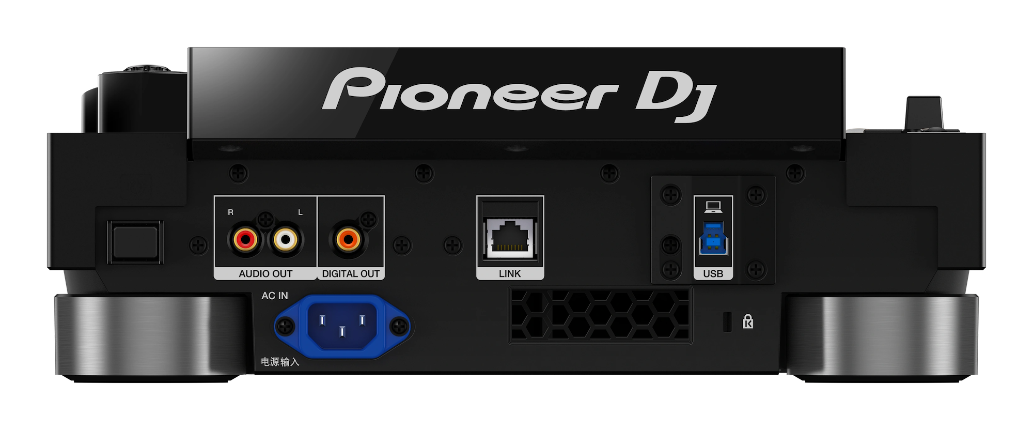
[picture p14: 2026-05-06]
ref_sizes/CDJ-3000_rear.png

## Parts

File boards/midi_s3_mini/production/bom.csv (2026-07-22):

Designator | Footprint | Quantity | Value | LCSC Part #
C1, C10, C13, C15, C19, C2, C21, C4, C5, C6, C7, C8, C9 | C0402 | 13 | 100n | C307331
C16, C17, C18 | C0805 | 3 | 22uF 25V | C45783
C20 | C0805 | 1 | 4.7uF ±10% 25V | C1779
C3 | C0402 | 1 | 10nF ±10% 50V | C15195
C_LDO_IN1 | C0603 | 1 | 1uF ±10% 50V | C15849
C_LDO_OUT1 | C0805 | 1 | 2.2uF ±10% 50V | C377773
D1 | SMB_L4.6-W3.6-LS5.3-BI | 1 | P6SMB6.8CA | C78395
D2 | SOD-123_L2.7-W1.6-LS3.7-RD-1 | 1 | B5819W_C8598 | C8598
D3, D4 | SMA_L4.2-W2.6-LS5.0-RD_1 | 2 | SS14 | C2480
LED_3V3_PERI1 | LED0805-R-RD | 1 | Yellow | C2296
LED_3V3_S1 | LED0805-R-RD | 1 | Green | C2297
LED_5V1 | LED0805-RD | 1 | Red | C84256
Q1 | SOT-23_L2.9-W1.3-P1.90-LS2.4-BR | 1 | AO3401A | C15127
R1, R10, R11, R12, R13, R14, R15, R16, R18, R19, R2, R20, R21, R22, R23, R24, R25, R26, R7, R8, R9 | R0402 | 21 | 1KΩ ±1% | C11702
R17 | R0402 | 1 | 10KΩ ±1% | C25744
R3, R5 | R0603 | 2 | 1.8KΩ ±1% | C4177
R30, R4, R6 | R0402 | 3 | 3.3KΩ ±1% | C25890
R31 | R0603 | 1 | 100KΩ ±1% | C25803
R32 | R0402 | 1 | 47KΩ ±1% | C25792
R33 | R0402 | 1 | 1Ω ±1% | C25086
R34 | R0402 | 1 | 22KΩ ±1% | C25768
R35 | R0402 | 1 | 470Ω ±1% | C25117
R36 | R0402 | 1 | 1.5KΩ ±1% | C25867
TVS1, TVS2, TVS3, TVS4, TVS5, TVS6, TVS7, TVS8, TVS9 | SOT-23-6_L2.9-W1.6-P0.95-LS2.8-BL | 9 | SRV05-4 | C558418
U2 | SOT-23-5_L3.0-W1.7-P0.95-LS2.8-TL | 1 | SPX3819M5-L/TR | C9056

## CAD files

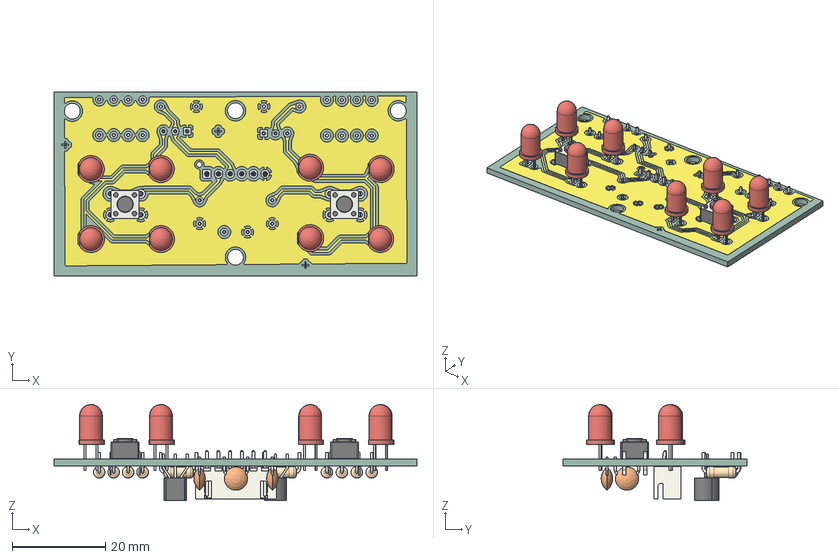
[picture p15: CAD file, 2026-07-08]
boards/loop_btn/.step
77.8 x 39.4 x 20.6 mm
LED_D5.0mm x 8
SW_PUSH_6mm_H4.3mm x 2
R_Axial_DIN0207_L6.3mm_D2.5mm_P7.62mm_Horizontal x 10
TO-92_Inline_Wide x 2
C_Disc_D5.0mm_W2.5mm_P5.00mm x 3
JST_XH_B6B-XH-A_1x06_P2.50mm_Vertical
play_cue_btn_copper
play_cue_btn_pad
play_cue_btn_PCB

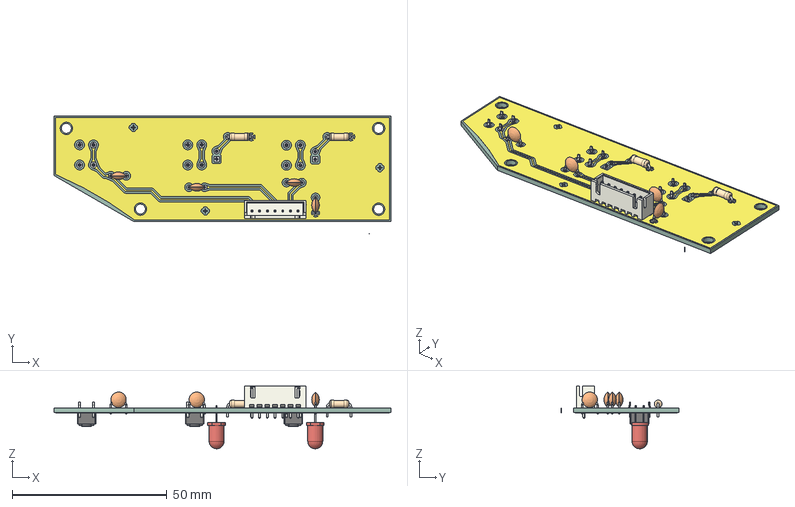
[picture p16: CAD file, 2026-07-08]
boards/loop_btn/plots/loop_btn.step
109.0 x 38.1 x 20.3 mm
C_Disc_D5.0mm_W2.5mm_P5.00mm x 4
R_Axial_DIN0207_L6.3mm_D2.5mm_P7.62mm_Horizontal x 2
JST_XH_B7B-XH-A_1x07_P2.50mm_Vertical
SW_PUSH_6mm_H4.3mm x 3
LED_D5.0mm x 2
loop_btn_copper
loop_btn_pad
loop_btn_PCB_1
loop_btn_PCB_2

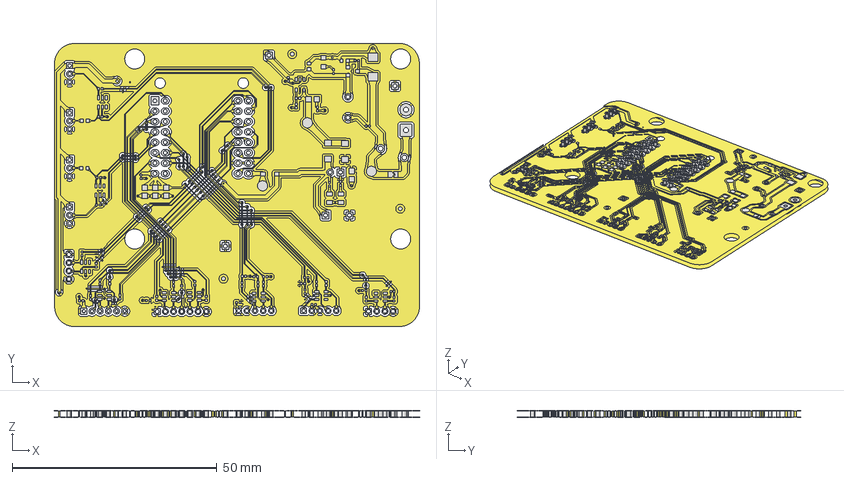
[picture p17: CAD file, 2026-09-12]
boards/midi_s3_mini/midi_s3_mini_v2.step
89.2 x 69.2 x 1.59 mm
midi_s3_mini_copper
midi_s3_mini_pad
midi_s3_mini_via

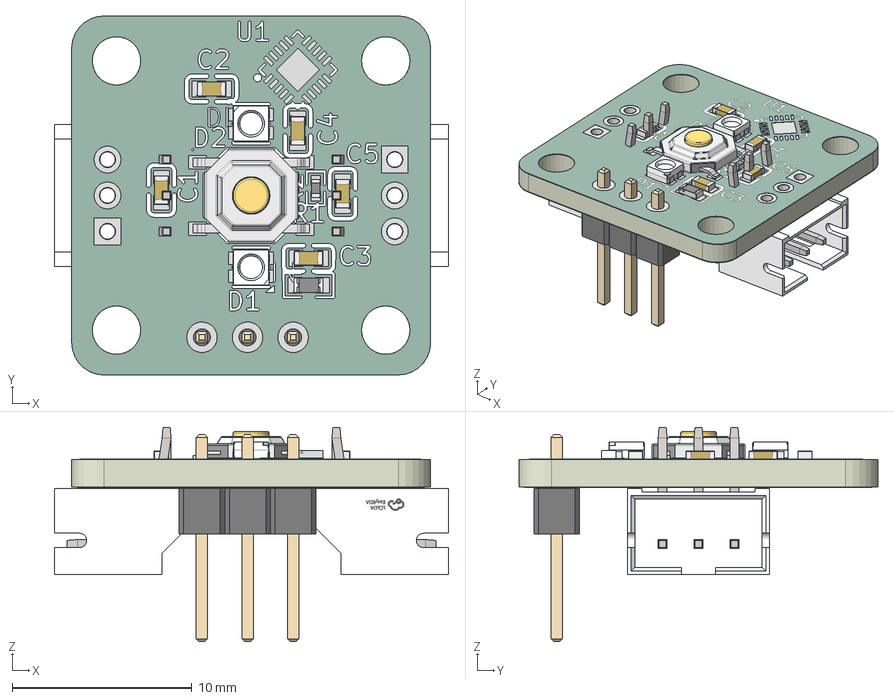
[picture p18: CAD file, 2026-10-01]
boards/one_button/OneButtonV1_angled.step
22.0 x 20.0 x 11.9 mm
C0603_L1.6-W0.8-H0.8 x 5
SW-SMD_4P-L5.1-W5.1-P3.70-LS6.5-TL_H1.5
LED-SMD_4P-L2.0-W2.0_FZ_2020 x 2
R0402_L1.0-W0.5-H0.4
R0603
CONN-TH_3P-P2.00_S3B-PH-K-S-LF-SN x 2
PinHeader_1x03_P2.54mm_Vertical
OneButton_copper
OneButton_pad
OneButton_via
OneButton_silkscreen x 2
OneButton_soldermask x 2
OneButton_PCB

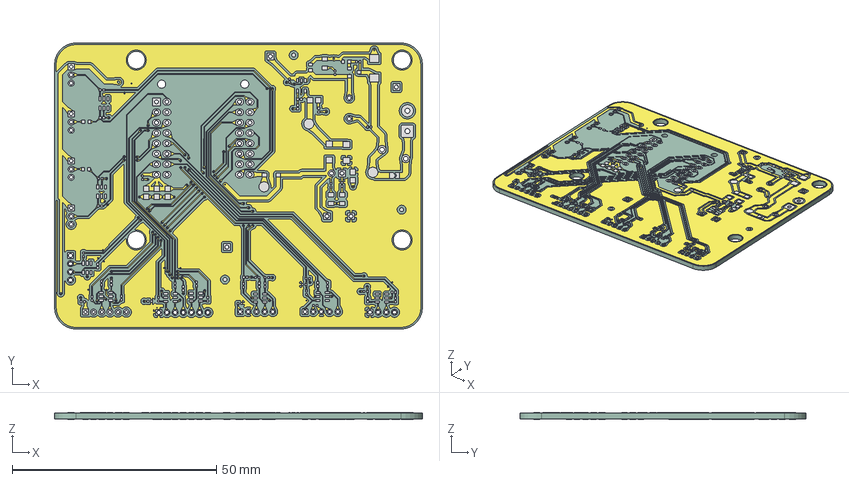
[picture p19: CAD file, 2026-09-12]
boards/midi_s3_mini/midi_s3_mini_v2_board_only.step
90.0 x 70.0 x 1.59 mm
midi_s3_mini_copper
midi_s3_mini_pad
midi_s3_mini_via
midi_s3_mini_PCB

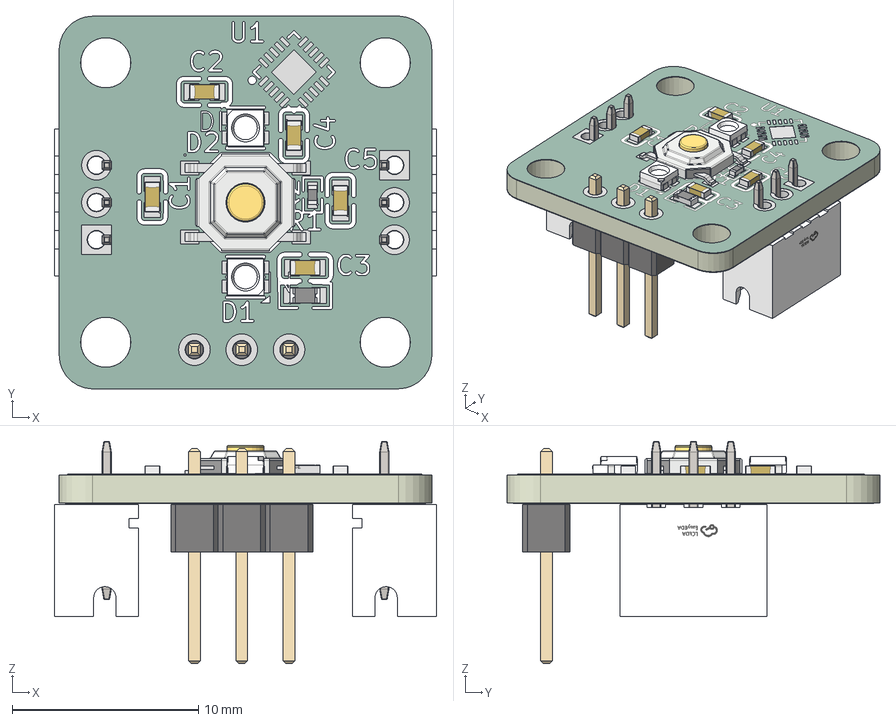
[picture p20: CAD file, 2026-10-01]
boards/one_button/OneButtonV1.step
20.5 x 20.0 x 11.9 mm
C0603_L1.6-W0.8-H0.8 x 5
SW-SMD_4P-L5.1-W5.1-P3.70-LS6.5-TL_H1.5
LED-SMD_4P-L2.0-W2.0_FZ_2020 x 2
R0402_L1.0-W0.5-H0.4
R0603
CONN-TH_B3B-PH-K-S x 2
PinHeader_1x03_P2.54mm_Vertical
OneButton_copper
OneButton_pad
OneButton_via
OneButton_silkscreen x 2
OneButton_soldermask x 2
OneButton_PCB

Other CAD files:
boards/play_cue_btn/play_cue_btn.step
CDJ-Bottom-Tray.f3d
CDJ-Top-Panel_v17.f3d

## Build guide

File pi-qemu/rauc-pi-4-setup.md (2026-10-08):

# TriMixxx updates: RAUC and tryboot on the Pi 4

The plan for how the decks run a locked system and take updates over the air,
and how that is developed and rehearsed on the emulated deck. Written on
2026-10-07, and built since: `PLAN.md` has each phase's results.

- **Decisions are settled** (§1).
- **The design is §2 to §9.** Appendices A to C hold the research behind it,
  and sources are at the end. Anything not checked yet is marked
  **unverified**.
- **The work itself** (tasks, files, tests, stop points) is in `PLAN.md`.
  `rauc-pi-4-report.md` explains the system with diagrams.
- Where this differs from `PLAN.md` (D7, D8, §7, §9 and phases P4–P6), this
  file wins.

---

## 1. Decisions

| Decision | Why (details) |
|---|---|
| **RAUC installs updates** | The standard embedded Linux A/B updater, packaged in Debian. It handles checking, writing and bookkeeping, so we don't reinvent them (App. B) |
| **The Pi firmware's own tryboot chooses the slot, not U-Boot** | Firmware, device tree and `config.txt` get A/B protection too. No writes at every boot, the watchdog covers start-up, nothing added to boot time, stock Pi OS boot chain (App. C.2) |
| **System slots are SquashFS** | Can't be modified while running, even by root |
| **The dev card in pi-qemu stays writable** | ext4, today's 2-partition card, for experiments |
| **One image for every deck** | At least four decks: trimixxx1, trimixxx2, trimixxx3 (the spare Pi 4, used as the bench), and more later |
| **Per-deck identity lives on a separate partition** | Name, Wi-Fi and ssh host keys. Written once, read-only until deliberately unlocked |
| **Writes are discarded at every start** | Their RAM use is bounded (§3.3) |
| **Updates are signed** | RAUC requires it. It costs one self-signed key, made once (App. B.6) |

---

## 2. The system at a glance

1. **Two copies of the system on the SD card.** Each copy is a slot: a FAT
   boot partition (firmware, kernel, initramfs, `config.txt`) plus a SquashFS
   system partition.
2. **The Pi firmware picks the slot** through `autoboot.txt` on a small first
   partition. A new slot is started once on trial with the firmware's one-shot
   tryboot flag. Any restart after a failed trial goes back to the old slot.
3. **One boot image serves both slots.** Its `config.txt` picks the right
   kernel command line with Raspberry Pi's `[boot_partition=N]` filter.
4. **RAUC installs updates** (`apt install rauc rauc-service`, 1.13 in trixie).
   It checks the bundle, writes the idle slot and records what it installed.
5. **A health check commits.** Once the deck is up, a systemd unit runs `rauc
   status mark-good` if the deck can take the next release: it's on a network
   and sshd runs. That makes the new slot the default.
6. **The running system is read-only.** SquashFS cannot be written, and
   Debian's `overlayroot` puts a RAM layer on top that is gone at the next
   start.
7. **Per-deck identity** (name, Wi-Fi, ssh host keys) lives on a small
   read-only `/data` partition that updates never touch.
8. **pi-qemu learns tryboot.** It already plays the Pi firmware's part, so the
   same card and bundle are rehearsed on an emulated deck before trimixxx3,
   then the real decks.

**What we write ourselves** (§6 has the full table):

| Custom piece | Why no standard part covers it |
|---|---|
| RAUC bootloader backend for tryboot, ~100 lines of shell adapted from Rtone's LGPL script | RAUC 1.13 has no Raspberry Pi firmware backend. The upstream one (rauc PR #1599) isn't merged. RAUC's documented custom-backend interface is the intended extension point |
| Health check unit that calls `rauc status mark-good` | RAUC documents this pattern; what counts as healthy is deck-specific |
| Identity unit: hostname and per-deck Mixxx config | No standard tool selects per-device application config |
| Tryboot in pi-qemu: C++ firmware step, one QEMU mailbox patch | QEMU runs no Pi firmware. pi-qemu is the firmware, so it implements tryboot |
| One `pi-qemu release build`: a Dockerfile, `genimage.cfg`, a RAUC manifest | Declarative files that drive standard image tools |

---

## 3. Design

### 3.1 Card layout

MBR with a fixed disk signature, `0x5d0bc1ec` (the first 32 bits of
sha256("trimixxx"), set in `release/container.sh`), so `<id>` below is `5d0bc1ec`:

| # | Label | FS | Size | Holds | Mounted | Written |
|---|---|---|---|---|---|---|
| p1 | bootsel | FAT32 | 64 MiB | `autoboot.txt` only, and never any `start*.elf`: then a missing, empty or garbled `autoboot.txt` starts p2 (measured, PLAN.md T6c and T7) | not mounted (the backend mounts it to commit) | at commit: one small file |
| p2 | boot-A | FAT32 | 512 MiB | firmware, kernel, initramfs, DTBs, overlays, `config.txt`, `cmdline-a.txt`, `cmdline-b.txt` | the running slot read-only at `/boot/firmware` | by RAUC, idle slot only |
| p3 | boot-B | FAT32 | 512 MiB | the same files | | |
| p4 | (extended) | | | container for 5–8 | | |
| p5 | rootfs-A | SquashFS (raw) | 4 GiB | the whole system, zstd-compressed (about 1–1.5 GB today, estimated) | `/`, underneath the RAM layer | by RAUC, idle slot only |
| p6 | rootfs-B | SquashFS (raw) | 4 GiB | | | |
| p7 | data | ext4 | 64 MiB | identity: deck name, Wi-Fi (NetworkManager keyfiles), ssh host keys | `/data`, read-only | when unlocked by hand (`mount -o remount,rw /data`) |
| p8 | state | ext4 | 4 GiB: a bundle (about 1.1 GB) and RAUC's status. The card image ends here, at about 13 GiB, so it flashes in minutes; a bigger card's rest stays unused | RAUC's data directory, downloaded bundles | `/var/lib/rauc`, read-write | by RAUC only |

**Why each partition exists:**
- **p1 on its own:** the file that decides which slot starts is never written
  by an install. Raspberry Pi's own example uses the same arrangement.
- **p8:** RAUC needs a writable directory outside the slots (App. B.7). Keeping
  RAUC's bookkeeping apart from `/data` lets `/data` stay read-only. It's also
  where bundles land.
- **Card size:** real cards can be any size of 16 GB or more: the image ends
  at about 13 GiB, and the rest of a bigger card stays unused. The decks'
  32 GB cards and trimixxx3's 64 GB one take the same image. **The
  power-of-two rule is only for the emulator's card file.**
  pi-qemu rounds the file up as a sparse file (§4.2), which costs no disk
  space.

### 3.2 Boot: one boot image for both slots

`config.txt` is the deck's current file, plus:

```
[boot_partition=2]
cmdline=cmdline-a.txt
[boot_partition=3]
cmdline=cmdline-b.txt
[all]
# The firmware arms the hardware watchdog, and Pi OS's initramfs then keeps
# it armed (App. A.4): a trial that hangs anywhere resets. Value to tune.
kernel_watchdog_timeout=60
```

`cmdline-a.txt` is one line. `cmdline-b.txt` is the same with `-06`,
`rauc.slot=B` and `-03`:

```
console=tty1 root=PARTUUID=<id>-05 rootfstype=squashfs rootwait panic=10 cfg80211.ieee80211_regdom=NL overlayroot=tmpfs:recurse=0 rauc.slot=A systemd.mount-extra=PARTUUID=<id>-02:/boot/firmware:vfat:ro
```

Each part of that line comes from a standard component:
- `root=PARTUUID=…`: the kernel.
- `panic=10`: the kernel, and initramfs-tools, which mounts the root on Pi
  OS. On a failure either one reboots after 10 s, instead of hanging or
  opening a shell, and a reboot ends the trial. initramfs-tools waits up to
  30 s for a missing root by itself. No `rootdelay=`: initramfs-tools sleeps
  that long on every start before it looks for the root (phase 4 found 20 s
  added to each boot). `rootwait` is stock Pi OS's, and only applies when the
  kernel mounts the root itself.
- `cfg80211.ieee80211_regdom=NL`: the Wi-Fi country, the Netherlands (Sam,
  2026-10-08), set the way raspi-config sets it on Pi OS. Without one, Wi-Fi
  runs on the restrictive world default.
- `overlayroot=…`: Debian's overlayroot (§3.3). With `recurse=0` it rewrites
  only `/` and leaves `/data` and `/var/lib/rauc` as plain mounts (its
  script, and the release card in pi-qemu: phase 3).
- `rauc.slot=`: RAUC (App. B.4).
- `systemd.mount-extra=`: systemd ≥ 254 (trixie has 257) mounts the slot's own
  boot partition, by PARTUUID like `root=`, with no fstab logic. Checked on
  phase 1's card in pi-qemu.

`autoboot.txt` on p1 is Raspberry Pi's documented example (App. A.2). The
backend always writes it whole, never edits it:

```
[all]
tryboot_a_b=1
boot_partition=2
[tryboot]
boot_partition=3
```

Committing slot B means writing it again with 2 and 3 swapped.

### 3.3 Read-only system, and a bounded RAM layer

**The read-only system**
- The system slot is SquashFS: read-only by construction, even for root.
- Debian's `overlayroot` puts a tmpfs on top. It's the same package and flag
  `raspi-config` uses for its overlay mode on trixie. Everything written lands
  in RAM and is gone at the next start.
- `/etc/initramfs-tools/modules` lists `squashfs` and `overlay`.

**The RAM layer is bounded** with no extra work:
- **The kernel caps it.** overlayroot mounts its tmpfs without a size, and the
  kernel caps such a tmpfs at **half the RAM** (overlayroot's docs: "can grow
  to 1/2 available memory"). That's 2 GB on a 4 GB deck. Beyond that, writes
  fail with "no space"; nothing crashes.
- **zram swap** (2 GiB, already set up by `pi_config/trimixxx-swap-sizes.conf`)
  can compress cold pages from that tmpfs. The release keeps zram only: a swap
  file can't live on a read-only root.

**The writers that would fill it:**

| Writer | Cap |
|---|---|
| Mixxx logs | `/tmp/mixxx`, 2 × 32 MiB |
| journald | Volatile already, capped at 10 % of `/run` by default |
| Core dumps | None: Pi OS lite has no `systemd-coredump`, and the core size limit is 0 |
| Mixxx library and analysis (`~/.mixxx`) | **Measured** (phase 3): about 130 KiB per analysed track, so about 10 MB over a 4-hour set of 80 tracks |
| Mixxx's track cache, tier 1 (`/tmp/trimixxx/cache`) | Copies of the loaded tracks, in `/tmp`'s own tmpfs, not this layer. Bounded by the fork: two thirds of a budget it measures from `/tmp`'s free space (371 MB on the 2 GB emulated board). Evicting drops a copy whose stick is still plugged in |
| Its tier 2 (`~/.cache/Mixxx/trimixxx/tracks`) | In this layer on a release card. Only a copy whose stick was pulled spills there, so at most what tier 1 held; wiped at every start |

**Measured on the emulated release deck** (2 GB board, 10 tracks of five
minutes): the layer grew from 3.7 MB to 5.0 MB, tier 1 to 70 MB, and nothing
spilled. Half the RAM is a generous bound: no tighter cap is needed.

**Only if the measurement calls for it:**
- Set a tighter cap with one `remount,size=` mount option.
- Or move the layer to disk with overlayroot's documented `crypt:` mode. It
  formats a partition afresh at every start, so it uses no RAM, but costs a
  few seconds per start.

### 3.4 One image for every deck

There is nothing per-deck in the system slots. A deck learns who it is as it
starts:

| What | Where | Mechanism |
|---|---|---|
| Wi-Fi | `/data/NetworkManager/` | Standard NetworkManager keyfiles. The identity unit copies them into `/run/NetworkManager/system-connections/`, NetworkManager's own volatile directory, so NetworkManager isn't reconfigured and the dev card (no `/data`) keeps its network. Keyfiles, not netplan: Pi OS's NetworkManager rewrites netplan's profiles into ones that match every NIC (phase 1, PLAN.md §2.1). Changing Wi-Fi means unlocking `/data` |
| ssh host keys | `/data/ssh/` | Standard OpenSSH host keys, copied by the identity unit into `/etc/ssh/` (in RAM) before sshd starts. The deck's own, taken from its system before its first card (`pi-qemu deck prepare`, §5.1), else made on the Mac with its card; kept either way, so `known_hosts` survives reflashing |
| Deck name → hostname, wiring, accent | `/data/trimixxx.conf`, one line: the deck's name | The identity unit (§6) sets the hostname and links that deck's pre-rendered Mixxx files into place. `units/apply.py` runs at build time for every deck, instead of at deploy time for one |
| The deck's screen (DSI panel or HDMI) | `config.txt` | `[0x<serial>]` sections built from each deck's `units/<deck>.json`, which gains a `serial` (`release/boot/deck-sections.py`). Checked on trimixxx3: the firmware reads its own section and skips another board's (PLAN.md §7). Alternative: the board's own EEPROM `[config.txt]` section (App. A.3) |
| machine-id | none | systemd's standard behaviour on a read-only root: a new one at each start. NetworkManager uses `dhcp-client-id=mac`, so the router keeps giving the same address |

### 3.5 RAUC configuration, the backend and the health check

`/etc/rauc/system.conf`, the same on every deck:

```ini
[system]
compatible=trimixxx-pi4
bootloader=custom
data-directory=/var/lib/rauc

[keyring]
path=/etc/rauc/keyring.pem

[handlers]
bootloader-custom-backend=/usr/lib/rauc/rpi-tryboot

[slot.rootfs.0]
device=/dev/mmcblk0p5
type=raw
bootname=A

[slot.boot.0]
device=/dev/mmcblk0p2
type=vfat
parent=rootfs.0

[slot.rootfs.1]
device=/dev/mmcblk0p6
type=raw
bootname=B

[slot.boot.1]
device=/dev/mmcblk0p3
type=vfat
parent=rootfs.1
```

The bundle manifest:

```ini
[update]
compatible=trimixxx-pi4
version=1.0.1
build=<git describe>

[bundle]
format=plain

[image.rootfs]
filename=rootfs.squashfs

[image.boot]
filename=boot.vfat
```

**Why `plain` bundles first:**
- They work with RAUC 1.13 on any kernel (App. B.4).
- They need neither NBD nor a Range-capable server. The bundle is copied to
  `/var/lib/rauc` and installed from there.

Moving to `verity` (streaming, and later adaptive updates that download only
what changed) is one manifest line, once RAUC ≥ 1.15.1 is in the image.

**The backend, `/usr/lib/rauc/rpi-tryboot`**, starts from Rtone's script, with
these changes:
- `autoboot.txt` lives on p1, not on the boot slot. The script mounts p1 to
  write it.
- It writes the whole file, as the rauc #1599 reviewers asked, then `fsync`,
  rename, and a sync of the directory. A copy goes first to the state
  partition, whose ext4 has a journal.
- On a normal (non-trial) start, the health unit has it check `autoboot.txt`
  (`rpi-tryboot repair`), as Raspberry Pi's engineer recommends. An invalid
  file is rewritten from the copy, and if that commits B, the deck reboots
  into B. A file edited by hand to commit the slot running is kept: that's
  the fix for a committed slot that keeps restarting (PLAN.md §5.4, F10).

| RAUC calls | When | The backend |
|---|---|---|
| `get-primary` | `rauc status` | prints the bootname of `[all] boot_partition` (2 → A, 3 → B) |
| `set-state X bad` | start of `rauc install` | nothing to undo: `[all]` still names the old slot |
| `set-primary X` | end of `rauc install`, or `mark-active` | writes `autoboot.txt` with `[tryboot] boot_partition=` X's boot partition, then arms the flag (`vcmailbox 0x00038064 4 0 1`), so **the next reboot is X's trial** |
| `set-state X good` | `rauc status mark-good` | if X is running on trial, commits: `[all]` becomes X, `[tryboot]` the other slot. Otherwise nothing |
| `get-state X` | `rauc status` | `good` for the running slot, `bad` for the other, as in Rtone's script |
| `get-current` | 1.13 never calls it, since `rauc.slot=` is on the cmdline | bootname from `/chosen/bootloader/partition` |

**The health check, `trimixxx-health.service`**
- Runs at every start of a release card. On a trial (the device tree's
  `tryboot` is 1, as Home Assistant OS checks it), it decides the trial. On a
  normal start it runs `rpi-tryboot repair`, and the reconcile after a
  boot-watchdog fallback (PLAN.md §5.2).
- Starts after NetworkManager and ssh, per the never-lock-the-deck-out rule.
- On a trial it asks one thing (Sam, 2026-10-08): can the deck take the next
  release? Within 150 s (counted on `/proc/uptime`, since NTP jumps the clock
  at start):
  - NetworkManager is in any connected state: `connected` on home Wi-Fi,
    `connected (local only)` on the Ethernet cable's link-local profile or
    the deck's own hotspot;
  - `ssh.service` is active.

  Mixxx, the MIDI bridge, the sound and the S3 aren't checked: whatever else
  a release breaks, the next one fixes over the air.
- On success it runs `rauc status mark-good`. If RAUC can't, the trial fails
  too: RAUC is what installs the next release.
- Every decision also goes to `/var/lib/rauc/trimixxx-health.log`, so the
  reason a trial failed survives the reboot that ends it.
- On failure it runs `rauc status mark-bad` and exits 1, and
  `FailureAction=reboot` brings back the committed slot. `TimeoutStartSec=180`
  is the backstop.

**Covered without code:**
- Kernel panics, and an initramfs that gives up: `panic=10`.
- Hangs: the firmware and kernel watchdog, plus the `RuntimeWatchdogSec=1min`
  that Raspberry Pi OS already sets (checked on the release).
- Power cuts: the trial flag dies with the power.

---

## 4. Local development in QEMU

### 4.1 Two emulated decks, one build

| Emulated deck | Card | Use |
|---|---|---|
| **Dev deck** (today's trimixxx0) | `pi-qemu image build` card: 2 partitions, ext4, writable | Feature work: `pi-qemu deck deploy NAME mixxx\|config\|system…` in seconds. Unchanged |
| **A/B deck** (new) | `trimixxx-<v>.img` from `pi-qemu release build`: the 8-partition card, locked | Update work: RAUC, the backend, the health check, rollback, fault injection |

**They run the same system.** Everything the release needs is installed by
the normal build, so the dev deck carries it too:
- overlayroot;
- RAUC and its configuration;
- the backend;
- the health and identity units;
- the fstab entries for `/data` and `/var/lib/rauc` (`nofail`).

All of it stays idle on the dev card, for three reasons:
- the command line has no `overlayroot=`;
- `/data` and `/var/lib/rauc` don't exist there;
- `rauc.service` is D-Bus activated and nothing calls it.

The release only seals the system: it leaves out trimixxx0's identity. **What
you test is what ships.**

### 4.2 What pi-qemu needs

pi-qemu is the Pi firmware for the emulated deck. Each change below copies a
documented firmware behaviour, so nothing invented reaches the card.

1. **Understand `[boot_partition=N]` and `[partition=N]` in `config.txt`.**
   `filterMatches()` knows only `[all]`, `[pi4]`, `[board-type]` and
   `[tryboot]` today.
2. **Honour tryboot:**
   - a one-shot flag, cleared after use;
   - it selects `autoboot.txt`'s `[tryboot]` section, and `[tryboot]` in
     `config.txt`;
   - without `tryboot_a_b=1`, read `tryboot.txt` instead of `config.txt`;
   - honour `reboot N`, the partition the kernel writes to the watchdog's
     `PM_RSTS` register.

   Today `Machine::powerOn()` always passes `tryboot = false`.
3. **Add a QEMU patch** in `trimixxx-patches.py`:
   - Implement the firmware messages SET_REBOOT_FLAGS (`0x00038064`) and
     GET_REBOOT_FLAGS (`0x00030064`). Today they fall through to
     "unimplemented".
   - The flags survive the guest's reset, and are readable over QMP with
     `PM_RSTS`.
   - pi-qemu then runs QEMU with `-action reboot=shutdown,shutdown=pause`
     instead of `-no-reboot`, reads both values at each reboot, and starts the
     board again.

   This is `PLAN.md`'s Q2. It makes `vcmailbox` and a reboot to `"0 tryboot"`
   behave as on a Pi. On trixie that reboot is
   `systemctl reboot --reboot-argument="0 tryboot"`.
4. **Write `/chosen/bootloader/{tryboot,partition,boot-mode,pm_rsts,capabilities}`**
   into the device tree, as the firmware does. The backend and the health
   check read them. Today pi-qemu writes none, and
   `/proc/device-tree/chosen/bootloader` doesn't exist on trimixxx0.
5. **Fall back like `PARTITION_WALK`.** If `autoboot.txt` is missing or
   invalid, boot the first FAT partition that holds `start4.elf`. Today it
   boots the first FAT partition.
6. **Accept cards of any size.** Round the card up to the next power of two as
   a sparse copy (an APFS clone, then `truncate`), so a release card boots as
   it is.

`pi-qemu deck up NAME --from trimixxx-<v>.img` already boots any card. A golden
snapshot of the A/B card can come later, if quick restores matter there.

### 4.3 The update-work loop

```
git tag -m "TriMixxx 1.0.0" pi/v1.0.0 && pi-qemu release build   # card + bundle (§5.2), version 1.0.0
pi-qemu release card trimixxx0 --version 1.0.0    # the emulated deck's identity
pi-qemu deck up ab --from pi-qemu/release/out/1.0.0/trimixxx0-1.0.0.img
pi-qemu release build --rehearsal 1.0.1           # the change under test, untagged
pi-qemu deck ship ab --version 1.0.1              # install, then a trial start of B;
                                                  # B committed once the health check passed
```

`pi-qemu deck ship` streams the bundle into the deck's `/var/lib/rauc` over
ssh, installs it, reboots, and prints what the deck then runs. It takes an
emulated deck by its name, `ab` here, and a real one as `--host ALIAS`.

The fault matrix to run before the bench or any deck sees a change.
`pi-qemu release faults --version 1.0.1` builds its broken releases from the
release under test. All of it passed on 2026-10-08 (PLAN.md §5.4, F1 to F11):

| Fault | How, in the emulator | Expected |
|---|---|---|
| Plug pulled during the install | power off without a sync, from the deck, while RAUC copies the root image | A starts; RAUC records B's write as `pending`, and B as bad |
| Plug pulled after install, before reboot | `pi-qemu deck kill`, then `deck up` | A starts: the flag dies with the power |
| The trial can't take the next release | `-nonet` (NetworkManager masked) and `-nossh` (sshd masked) | trial → mark-bad → restart → A |
| Kernel panic on the trial | `-noinitramfs` | `panic=10` → restart → A |
| The initramfs gives up | `-panic`: `break=premount` | initramfs-tools' `panic=10` → restart → A |
| Hang on the trial | `-hang`: `break=premount` without `panic=10` | watchdog → restart → A |
| Plug pulled during the commit | a damaged `autoboot.txt` | A damaged `autoboot.txt` starts A (measured, PLAN.md T6c and T7). The backend's `repair` restores its copy, and reboots into B if B was committed (PLAN.md §5.2) |
| Rollback | `rauc status mark-active other`, then reboot | trial of the old version → commit |
| The committed slot hangs | the `-hang` command line on the committed slot | it keeps restarting (T9). Fixed on the Mac by committing the other slot in `autoboot.txt`, which `repair` keeps |

### 4.4 What QEMU cannot prove

Anything that depends on the real `start4.elf`, EEPROM or SD card:
- that a Pi 4's firmware honours `[boot_partition=N]`;
- what it does with a corrupt `autoboot.txt`;
- EEPROM versions and settings;
- real watchdog timing;
- an SD card losing power mid-write.

**That's what trimixxx3 is for** (§7). pi-qemu's tryboot is checked against
what trimixxx3 shows, not the other way round.

---

## 5. Shipping to units

### 5.1 Once per deck: commissioning

1. **Prepare it, on the system it runs today:**
   `pi-qemu deck prepare --host <ssh alias> <deck> --eeprom` (PLAN.md §7).
   - The bootloader must be from 2022-12 or later. `--eeprom` updates it to
     the newest image the deck's `rpi-eeprom` has, with the boot watchdog
     (`BOOT_WATCHDOG_TIMEOUT=45`, `BOOT_WATCHDOG_PARTITION=2`), and checks
     both after the reboot that flashes it.
   - The board's serial goes into `units/<deck>.json`, for its own section of
     the release's `config.txt` (§3.4).
   - Its ssh host keys become its identity's, and its boot files, EEPROM
     config and network profiles are kept on the Mac for reference.
2. **Build the release** after that, from a commit tagged `pi/vX.Y.Z`: the
   serials are written into its `config.txt`.
3. **Make the deck's card:** `pi-qemu release card <deck>`. That's the
   release's card image with this deck's `/data` filled in:
   - its name;
   - the home Wi-Fi (from `image/secrets.env`) and its own hotspot, as
     NetworkManager keyfiles;
   - its ssh host keys: the deck's own, kept by step 1, else new ones made on
     the Mac.

   The secrets stay on the Mac in a gitignored directory. Only this file
   carries them; bundles never do.
4. **Flash it once**, with Raspberry Pi Imager ("Use custom") or `dd`
   (PLAN.md §2.2), and start the deck. It runs slot A, committed.

### 5.2 Every release

1. **Tag the commit** `pi/v1.0.1`, then run `pi-qemu release build`: the
   version is the tag's. It refuses a dirty tree, and runs:
   - `pi-qemu image build trimixxx-release`, the dev card's own build, at that
     commit, giving the writable card with everything installed;
   - **one Docker container**, pinned by a `Dockerfile`: debian:trixie with
     genimage, rauc, squashfs-tools, dosfstools, mtools and e2fsprogs. It runs
     privileged to loop-mount that card read-only, then runs `genimage` with
     **one `genimage.cfg`**.

   genimage produces:
   - `rootfs.squashfs`: the system tree minus a checked-in exclude list (the
     emulated deck's hostname, host keys and `pi-qemu-home` network profile);
   - `boot.vfat`: the boot files plus `config.txt`, `cmdline-a.txt` and
     `cmdline-b.txt`, all checked in;
   - `bootsel.vfat`: `autoboot.txt`;
   - `trimixxx-<v>.img`: the 8-partition card with its fixed disk signature.
     B and `/data` are left empty; `pi-qemu release card` fills `/data` per
     deck;
   - `trimixxx-<v>.raucb`: built with genimage's `rauc` image type, or
     `rauc bundle`, from the manifest in §3.5 and the self-signed key.

   Everything lands in `out/<v>/` with a manifest (commit, checksums,
   `dpkg -l`). Every release is kept.
2. **Rehearse in QEMU:** §4.3, against the previous release's card.
3. **Bench:** the same commands against trimixxx3, watching the bootloader on
   its serial line.
4. **Ship:** the same commands against each deck. `pi-qemu deck ship --host
   trimixxx2 --version 1.0.1` runs these:
   ```
   ssh trimixxx2 'sudo sh -c "cat > /var/lib/rauc/trimixxx-1.0.1.raucb"' < out/1.0.1/trimixxx-1.0.1.raucb
   ssh trimixxx2 sudo rauc install /var/lib/rauc/trimixxx-1.0.1.raucb   # then deletes the bundle
   ssh trimixxx2 sudo reboot
   ssh trimixxx2 rauc status          # once it's back: the new slot on trial, then committed
   ```
   The bundle goes straight to the state partition, through `sudo`: `/tmp`
   is RAM, and a bundle is over a gigabyte.
5. **Roll back** with `ssh <deck> sudo rauc status mark-active other` and a
   reboot. The previous version gets a trial like any update. Older versions
   are just older bundles.

**What makes it repeatable:**
- Releases come only from a clean, tagged commit.
- The inputs are pinned: the Pi OS image by checksum, QEMU, the Docker images.
- apt moves, so the manifest records every installed package.
- Every version's files are kept.

**What makes it safe:**
- The running slot is never written.
- A new slot becomes the default only after it has started and passed the
  health check.
- Every failure path (§4.3) ends on the old slot, without anyone touching the
  deck.

---

## 6. Standard parts, and why each custom one exists

| Job | Standard part | Custom? | Why, and how it goes away |
|---|---|---|---|
| Choose the slot, trial start, fall back | Pi firmware: `autoboot.txt`, tryboot (Raspberry Pi docs) | no | — |
| Command line per slot | `config.txt` `[boot_partition=N]` (Raspberry Pi docs) | no | Removes the install hook other setups need |
| Check, install and record updates | RAUC 1.13 (Debian) | no | — |
| Connect RAUC to the Pi firmware | RAUC's custom backend interface | **yes, ~100 lines, adapted from Rtone (LGPL)** | RAUC 1.13 has no Pi firmware backend. Deleted once RAUC with `bootloader=raspberrypi` (PR #1599, aimed at 1.17) is in the image |
| Confirm a boot | `rauc status mark-good` from a systemd unit (RAUC's documented pattern) | **the checks only** | What "healthy" means is deck-specific: the checks `pi-qemu deck ready` makes today |
| Read-only system, RAM layer | SquashFS + Debian `overlayroot` (what `raspi-config` uses) + `/etc/initramfs-tools/modules` | no | — |
| Resets on hangs and panics | Firmware `kernel_watchdog_timeout`, systemd `RuntimeWatchdogSec`, kernel `panic=` | no (settings) | — |
| Mount the running boot slot | systemd `systemd.mount-extra=` | no (setting) | — |
| Wi-Fi, ssh keys, the `/data` lock | Standard NetworkManager keyfiles and OpenSSH host keys (copied into RAM by the identity unit), an fstab `ro` mount, `mount -o remount` | no (formats and settings) | — |
| Who this deck is | — | **yes, one small unit** | Choosing per-device app config (hostname, wiring, accent) has no standard tool. It's the one TriMixxx-specific step at start |
| Build card images and bundles | genimage + mksquashfs + `rauc bundle` (Debian) | **one `genimage.cfg`, one `Dockerfile`, one manifest, `pi-qemu release build`** | Declarative files. The script that runs them is `release/container.sh`, in the release container |
| Build the system itself | `pi-qemu image build` + the deploy steps (`deploy/NNN_*.sh`) | existing | Unchanged: it already builds the dev card |
| A/B in the emulator | pi-qemu (our firmware emulation) + QEMU | **yes, C++ and one QEMU patch** | QEMU has no Pi firmware, and pi-qemu exists to be it. Everything it does copies documented firmware behaviour |
| Ship | `ssh`, `rauc install`, `reboot` | no | `pi-qemu deck ship` only runs those commands |

**New files, in all**
- On the deck:
  - `/etc/rauc/system.conf`;
  - the backend;
  - the health unit and its check;
  - the identity unit;
  - a few drop-ins and settings (`coredump.conf`, initramfs modules, swap,
    the fstab lines for `/data` and `/var/lib/rauc`);
  - two command lines and an `autoboot.txt`.
- On the Mac:
  - a `Dockerfile`;
  - `genimage.cfg`;
  - a manifest template;
  - an exclude list;
  - three pi-qemu commands, `release build`, `release card` and `deck ship`,
    with their container half, `release/container.sh`.
- In pi-qemu: the changes in §4.2.

No deploy steps are added. The existing ones stay the dev loop's tools.

---

## 7. The bench deck: trimixxx3

trimixxx3 is a bare Pi 4 with an SD card, standing in for a future deck.

**Hardware**
- **A USB-serial adapter** on GPIO 14/15 and GND, with the EEPROM's
  `BOOT_UART=1`. It shows every decision the bootloader makes, which is what
  to watch when A/B misbehaves. There is no S3 sharing the UART.
- **An HDMI screen.** Its `config.txt` section picks HDMI instead of the DSI
  panel, which also tests the per-deck screen mechanism.
- **Wi-Fi** comes from its `/data` (§5.1). On the decks, eth0 is the CDJ port,
  link-local only.

**First, check the firmware facts, before any RAUC work.** A small card with
three FAT partitions, Pi OS boot files and `autoboot.txt` is enough. It takes
an afternoon and settles every unverified point the design rests on:

| Check | Expected |
|---|---|
| `[boot_partition=N]` picks the command line on a Pi 4 | p2 → `cmdline-a.txt`, p3 → `cmdline-b.txt` |
| `reboot '0 tryboot'` and `vcmailbox 0x00038064 4 0 1` | next start on p3; `/proc/device-tree/chosen/bootloader/tryboot` = 1; any later reboot → p2 |
| Power-off after arming | p2 |
| `autoboot.txt` deleted, then truncated | p2. **Measured:** p2, because partition 0 is the first FAT partition with firmware, not because of the partition walk. So p1 must hold none (T6b, T6c, T7) |
| `kernel_watchdog_timeout` and a hang in the initramfs | reset, then p2 |
| `kernel_watchdog_partition` or EEPROM `BOOT_WATCHDOG_PARTITION`, then a hang on the **committed** slot | Does the reset start the other slot? If it does, tryboot covers U-Boot's one real advantage (App. C.2). **Measured:** not for a hang in Linux (T9); the EEPROM's does for a failure before Linux, to a fixed partition (T10) |

The results go back into this file and into pi-qemu's emulation (§4.2).

---

## 8. Phases

The tasks, commands, tests and stop points for each phase are in `PLAN.md`.

| # | Phase | Delivers | Done when |
|---|---|---|---|
| 1 | Firmware checks on trimixxx3 (§7) | The results table above, filled in | Every **unverified** firmware point in App. A has a measured answer |
| 2 | Tryboot in pi-qemu (§4.2) | QEMU reboot-flags patch; firmware step: filters, tryboot, `/chosen/bootloader`, partition walk, any-size cards | Phase 1's card boots in pi-qemu, and the same checks give the same results as on trimixxx3 |
| 3 | A locked card (§3, §5) | overlayroot, initramfs modules, `/data` and state mounts, the identity unit, the boot splash's slot label (`A`/`B`, `trial`, the version); `Dockerfile`, `genimage.cfg`, exclude list, `pi-qemu release build` and `release card` | A tag produces a card that boots locked in QEMU, and the RAM layer's growth over a set's worth of tracks is measured (§3.3) |
| 4 | RAUC on the deck (§3.5) | Signing key, `system.conf`, the backend, the health check, the bundle in `release build`, `deck ship` | The whole fault matrix (§4.3) passes in QEMU |
| 5 | trimixxx3 end to end | Its card, two shipped releases | The fault matrix passes on hardware |
| 6 | The decks | Each deck commissioned and reflashed once (§5.1) | Every deck has taken one release over the air |

---

## 9. Open questions

- **Where per-deck screen settings live:**
  - `[0x<serial>]` sections in `config.txt`: in git, recommended;
  - or each board's EEPROM `[config.txt]` section: kept with the hardware,
    outside git.
- **When to move to verity bundles and streaming.** That needs RAUC ≥ 1.15.1
  in the image, from Debian forky, a backport, or waiting for 1.17, which may
  also bring the native Pi backend.
- **Can a privileged Docker container on macOS loop-mount the card?** If not,
  the build VM streams its sealed root out as a tar over ssh, and `mksquashfs
  -tar` reads it.
- **Must `autoboot.txt` still fit in 512 bytes?** That limit was dropped from
  the docs in 2026-09. Ours is about 60 bytes either way.
- **Should the dev card boot from SquashFS later?** Not for now: Sam wants it
  writable.
- **Should the decks set the EEPROM's boot watchdog?** **Decided: yes** (Sam,
  2026-10-08), with `BOOT_WATCHDOG_TIMEOUT=45` and `BOOT_WATCHDOG_PARTITION=2`,
  and a reconcile step in the backend for the fallback (PLAN.md §5.2). On trimixxx3,
  `BOOT_WATCHDOG_TIMEOUT=45` with `BOOT_WATCHDOG_PARTITION=3` turned a
  corrupt `start4.elf` on p2 into a start of p3 (PLAN.md T10). But the
  partition is fixed, so it only helps while A is the committed slot.
  **Unverified:** whether a conditional EEPROM section can point it at the
  other slot. The kernel-stage equivalent, `kernel_watchdog_partition`,
  didn't switch slots (T9).

---

## Appendix A. How a Pi 4 does A/B natively (research)

### A.1 The start-up chain
The Boot ROM starts the bootloader in the SPI EEPROM on the board, which then:
1. reads `autoboot.txt` from the first FAT partition;
2. loads `start4.elf` from the chosen boot partition.

`start4.elf` reads `config.txt`, then loads the kernel, device tree, overlays,
initramfs and command line.

There is no BIOS and no GRUB. `config.txt` does the job of `grub.cfg`, and
`cmdline.txt` holds the kernel line.

### A.2 The pieces Raspberry Pi documents for A/B

**`autoboot.txt`**, on the first FAT partition
- Holds `boot_partition=N`, `tryboot_a_b=1` and a `[tryboot]` section. Only the
  `[all]`, `[none]` and `[tryboot]` filters are allowed.
- With `tryboot_a_b=1`, the tryboot partition starts with its normal
  `config.txt`; without it, `tryboot.txt` is read.
- Raspberry Pi's example is the file in §3.2. If the trial passes, swapping
  the two numbers commits it. If it fails, "a standard reboot clears the
  tryboot flag, reverting to the default partition".

**The tryboot flag**
- Set by `sudo reboot '0 tryboot'`, which on trixie is
  `sudo systemctl reboot --reboot-argument="0 tryboot"` (measured). "All
  Raspberry Pi models support tryboot".
  On a Pi 4 rev 1.0/1.1 "the EEPROM must not be write protected".
- The kernel can also arm it without restarting: `vcmailbox 0x00038064 4 0 1`,
  the SET_REBOOT_FLAGS firmware message, sent through `/dev/vcio`.
- It survives a reboot but **not a power-off**. A power cut always returns to
  the committed slot.

**`[boot_partition=N]` in `config.txt`**
- It "can be used to select alternate OS files (for example, `cmdline.txt`) to
  be loaded, depending on which partition `config.txt` was loaded from".
- Raspberry Pi's example is the A/B case:
  `[boot_partition=2] cmdline=cmdline_rootfs_a.txt`, and the same for B.
- So one boot image works in either slot.

**What the OS can read.** The result is under
`/proc/device-tree/chosen/bootloader/`, as 32-bit big-endian values:
- `tryboot`: 1 during a trial;
- `partition`: the boot partition used;
- `boot-mode` and `pm_rsts`;
- `capabilities`: bit 2 is TRYBOOT_A_B, bit 3 is TRYBOOT.

**`sudo reboot N`** starts partition N once. The `[partition=N]` filter
matches it.

### A.3 Bootloader (EEPROM) versions for the Pi 4

| Feature | Since |
|---|---|
| tryboot | 2020-10-28 (beta) |
| `[tryboot]` filter and `tryboot_a_b` | 2022-10-18 beta, default since 2022-12-01 |
| Fix: tryboot flag lost with secure boot | 2024-04-15 |
| `[boot_partition=N]` in `config.txt` | start4.elf from about 2025-03 (rpi-update); trixie's firmware is newer. **Verified on a Pi 4** (trimixxx3, 2026-10-08): p2 → `cmdline-a.txt`, p3 → `cmdline-b.txt` |
| `PARTITION_WALK` (missing or invalid boot partition → try the next) | 2025-02-11, on by default since 2025-08-13 |
| `BOOT_WATCHDOG_TIMEOUT` / `BOOT_WATCHDOG_PARTITION` | 2025-07-03 |
| Current default release | 2026-09-23 |

One meta-rauc contributor saw the tryboot flag fail with a 2021-04 bootloader
and work with a 2023-01 one. That's why every deck gets the current bootloader
before its first flash (§5.1).

**Measured on trimixxx3** (PLAN.md §2.3, 2026-10-08):
- **A hung trial falls back.** With `kernel_watchdog_timeout=60`, the firmware
  passes `watchdog.open_timeout=60`, Pi OS's `rpi_wd` keeps the watchdog
  armed, and a trial stuck in the initramfs was reset to A (T8). After a
  commit, the same hang just restarts the committed slot (T9).
- **A 2021-04-29 bootloader starts slot B.** It reads `autoboot.txt` but not
  its sections, so the last `boot_partition=` (3, from `[tryboot]`) wins. A
  release card on such a board would start its empty slot B. Updating the
  bootloader first (§5.1) is a hard requirement, not a precaution.
- **Updated to 2026-05-17**, every A/B rule behaved as documented: `[all]`
  gives p2, `[tryboot]` gives p3 for one start, and the device tree's
  `partition` and `tryboot` say which.
- **Arming:** `vcmailbox 0x00038064 4 0 1` works, and `0x00030064` reads it
  back. On trixie, systemd 257 refuses `reboot '0 tryboot'` ("Too many
  arguments"). The form is `systemctl reboot --reboot-argument="0 tryboot"`.

**EEPROM settings for development**
- `BOOT_UART=1` logs the bootloader's decisions on GPIO 14/15.
- `uart_2ndstage=1` in `config.txt` makes `start4.elf` log too.
- An EEPROM `[config.txt]` section is appended in memory to every
  `config.txt`, which gives per-board settings independent of the slots.
  **Unverified** on our boards.

### A.4 Pitfalls others hit

- **The commit is a FAT write**, and FAT has no journal.
  - Raspberry Pi's engineer recommends keeping a journal on the data
    partition, and checking `autoboot.txt` at start.
  - Others write a new file, `fsync` it, then rename.
  - If `autoboot.txt` is missing or invalid, the firmware uses partition 0,
    the first FAT partition holding a `start.elf`. With no firmware on p1,
    that's p2, so the deck still starts (measured, PLAN.md T6c and T7).
    `PARTITION_WALK` isn't involved; it only applies to a requested partition.
    With firmware files on p1 but no `start4.elf`, the deck stays dark (T6b).
  - It starts p2 whichever slot was committed, which is why the backend
    keeps a copy of `autoboot.txt` on the state partition (PLAN.md §5.2).
  - If `autoboot.txt` is **valid** but names an unbootable partition, nothing
    recovers it. So only a slot that has already started is ever committed.
- **GPT on a Pi 4.** Choosing a boot partition other than the first "never
  worked with GPT on Pi4" until a February 2025 fix, and one project still saw
  it fail in June 2026. **Use MBR**, with the FAT partitions first and
  contiguous.
- **`rpi-eeprom-update`** stages files on `/boot/firmware`, which is now the
  active slot. A `recovery.bin` on p2 broke booting (rpi-eeprom #499). Mask the
  service in the release image and update EEPROMs deliberately (§5.1).
  - The Pi 4's ROM runs `recovery.bin` from p1.
  - On an A/B card, stage the update there:
    `mount /dev/mmcblk0p1 /mnt; BOOTFS=/mnt rpi-eeprom-update -a`.
    That's measured on trimixxx3.
  - Then `BOOTFS=/mnt rpi-eeprom-update -r` clears the leftovers.
- **Pi OS's initramfs disarms the hardware watchdog** (`rpi_wd`) unless
  `kernel_watchdog_timeout` is set in `config.txt`. Set it, so that a trial
  that hangs early still resets.
- **A SquashFS root on Pi OS needs the initramfs to load `squashfs`**, which
  the Pi kernel builds as a module. List it in `/etc/initramfs-tools/modules`,
  the documented place.
- **Pi OS's first boot rewrites the disk ID** (`set_partuuid`, triggered by
  `resize` on the command line), which breaks `PARTUUID=` roots. The release
  command line must not carry `resize`, and the card image uses a fixed disk
  signature.
- **`config.txt` filters of different kinds are ANDed.** End each block with
  `[all]`.

---

## Appendix B. RAUC (research)

### B.1 What it is
RAUC is a client on the device plus a host tool. On the device it:
- receives a signed **bundle**;
- checks it;
- writes the images into the **inactive slot group**;
- records what it installed;
- asks a **bootloader backend** to boot the new group next.

`rauc status mark-good` then confirms the boot. RAUC is maintained by
Pengutronix, packaged by Debian, and used by Home Assistant OS, among others.

### B.2 Debian trixie packaging
- **`rauc` 1.13-3+deb13u1** contains `/usr/bin/rauc`, built with GPT and HTTP
  streaming support.
- **`rauc-service`** contains `rauc.service`
  (`ExecStart=/usr/bin/rauc --mount=/run/rauc/mnt service`). It is D-Bus
  activated, not enabled, and ships with its D-Bus activation and policy
  files.
- **No mark-good unit ships**, from Debian or upstream. Upstream only
  documents an example.
- **No `system.conf` ships.** We provide `/etc/rauc/system.conf`. The search
  path is `/etc/rauc`, then `/run/rauc`, then `/usr/lib/rauc`.
- Debian sid/forky have 1.15.2. There is no trixie backport.

### B.3 Kernel support
The Pi OS kernel (`bcm2711_defconfig`, rpi-6.18.y) has:
- `BLK_DEV_LOOP=y`;
- `SQUASHFS=m`, with XZ, ZSTD and LZO but not LZ4;
- `MD=y`, `BLK_DEV_DM=m`, `DM_VERITY=m`, `DM_CRYPT=m`;
- `BLK_DEV_NBD=m`;
- `OVERLAY_FS=m`, `ZRAM=m`, `BCM2835_WDT=y`.

That covers every RAUC bundle format (plain, verity, crypt), and HTTP
streaming, which needs NBD. Whether `nbd` loads on its own is **unverified**;
list it in `/etc/modules-load.d/` if streaming is used.

### B.4 Version traps in 1.13
- **Detecting the booted slot.** 1.13 uses `rauc.slot=` on the kernel command
  line first, then `root=`, and only then the backend's `get-current`. 1.15
  puts the backend first. So each slot's command line carries `rauc.slot=A`
  or `B`, which wins in every version.
- **dm-verity on Linux 6.19+.** RAUC 1.13 expects a status string that Linux
  6.19 changed, so verity installs fail; 1.15.1 fixed it. Pi OS ships 6.18
  today. Plain bundles don't use dm-verity.

### B.5 What the custom backend sees
RAUC 1.13 runs the backend executable with:
- `get-primary`
- `set-primary <bootname>`
- `get-state <bootname>`
- `set-state <bootname> good|bad`
- `get-current`

The `get-*` calls print their answer to stdout; the `set-*` calls are judged
on their exit code.

| RAUC action | Backend calls |
|---|---|
| `rauc install` | `set-state <target> bad` before writing, `set-primary <target>` after |
| `rauc status mark-good` | `set-state <booted> good` |
| `rauc status mark-bad` | `set-state <booted> bad` |
| `rauc status mark-active <slot>` | `set-primary <slot>` |
| `rauc status` | `get-primary`, plus `get-state` for every slot with a bootname |

- **Where bootnames go.** Only slots **without** `parent=` may have a
  bootname. So the rootfs slots carry `bootname=A|B`, and the FAT boot slots
  are their children (`parent=rootfs.N`); RAUC writes each pair together.
- **One-shot trial bootloaders aren't covered by the docs.** The closest model
  is the EFI backend: "primary" means boot next time only (`BootNext`), and
  "good" makes it permanent. That is exactly tryboot plus a commit.

### B.6 Bundles and signing
- **Manifest sections:**
  - `[update]`: `compatible=`, `version=`, `build=`;
  - `[bundle]`: `format=plain|verity|crypt`;
  - `[image.<class>]`: `filename=`.
- **Signing is mandatory.** "For development purpose a self-signed certificate
  might be sufficient". One `openssl req -x509` key pair, made once, is a
  documented setup.
- **`rauc bundle --cert --key <dir> <out.raucb>` runs unprivileged.** It needs
  only `mksquashfs`, its own dm-verity code and OpenSSL, so it works in a plain
  Docker container. Two limits:
  - in 1.13 the input directory may hold only plain files, no
    subdirectories;
  - RAUC hard-links files into a work directory, so stage them inside the
    container rather than on a macOS bind mount.
- **The file extension picks how an image is written** (1.13):
  - `.squashfs` → `type=raw` slot: block copy;
  - `.vfat` or `.img` → `type=vfat` slot: block copy, size-checked;
  - `.tar*` → vfat or ext4 slot: mkfs, then unpack.
- Identical images are skipped (`install-same=true` by default).

### B.7 Status and data directory
- RAUC records installs in `<data-directory>/central.raucs`. It must be
  **writable during an install**, or "the installation will be aborted".
- At service start RAUC also writes the boot ID; if that fails, it only warns.
- The data directory "must be located on a non-redundant filesystem which is
  not overwritten during updates". It also holds the data for adaptive
  updates.
- For read-only slots, RAUC's FAQ says to "use `type=raw` … and use a shared
  data directory on a separate non-redundant partition".

### B.8 Streaming, or installing from a file
- **Streaming** (`rauc install https://…`) needs:
  - verity bundles;
  - NBD in the kernel;
  - a server that supports HTTP Range requests (Python's `http.server`
    doesn't).

  Debian's build streams every http(s) URL; there is no download fallback.
- **From a file:** copy the bundle to the deck and run `rauc install
  /path/x.raucb`. The bundle is loop-mounted, not unpacked, so it needs only
  its own size in space.

---

## Appendix C. Other integrations, and U-Boot vs tryboot (research)

### C.1 How others do it

| Project | Bootloader | Layout | Notes |
|---|---|---|---|
| **meta-rauc-raspberrypi** (Yocto, RAUC's community layer) | U-Boot, "for demo purpose only" | p1 shared FAT, p2/p3 ext4 rootfs, data | Boot counting in `boot.scr`. Draft **PR #181** moves it to tryboot with our layout: p1 `autoboot.txt`, p2/p3 boot, p5/p6 rootfs, `[boot_partition=N] cmdline=…` |
| **Rtone/raspberrypi-firmware-rauc-bootloader-backend** | Pi firmware tryboot | boot slots are children of rootfs slots | Bash, LGPL-2.1, used "on several dozens remote devices". `set-primary` arms the flag with `vcmailbox`; mark-good swaps `autoboot.txt`; it detects a trial from the device tree. **The basis of our backend** |
| **rauc PR #1599** (native `bootloader=raspberrypi`) | Pi firmware tryboot | — | Open, milestone v1.17. Reviewers asked for fixes, among them generating `autoboot.txt` from scratch. **When it ships, our backend is deleted** |
| **geekdojo/rasputin-os** (Buildroot, AGPL) | Pi firmware tryboot | MBR: p1 selector, p2/p3 FAT boot, p4 extended, p5/p6 SquashFS raw slots, p7 persistent | Nearly our layout: fixed disk signature, `rauc.slot=` on the cmdline, a data directory |
| **Home Assistant OS** | U-Boot on Pi 4, tryboot on Pi 5 | — | Arms the trial with `echo "0 tryboot" > /run/systemd/reboot-param`, so any `systemctl reboot` becomes a trial. Detects it with `cmp -s -n 4 …/chosen/bootloader/tryboot /dev/zero` |
| **rpi-image-gen `image-rota`** (Raspberry Pi's own) | Pi firmware tryboot | GPT: autoboot, boot_a/b, system_a/b (erofs), persistent | A slot mapper (udev + initramfs) gives a slot-agnostic `root=`. The updater is Raspberry Pi Connect OTA (experimental), **not RAUC**. Uses GPT, which App. A.4 advises against on a Pi 4 |

### C.2 U-Boot or the Pi's own tryboot? → tryboot

**What U-Boot would look like on the decks**, based on RAUC's demo layer
(meta-rauc-raspberrypi):
- U-Boot replaces no Pi boot stage. The firmware still runs, reads
  `config.txt` and loads U-Boot as if it were the kernel
  (`kernel=u-boot.bin`).
- One shared FAT partition holds the firmware, `config.txt`, the device tree,
  U-Boot, its boot script and its environment (`uboot.env`).
- The boot script counts attempts per slot (`BOOT_A_LEFT=3`). On **every
  boot** it decrements the count and runs `saveenv`, then loads the kernel
  from the chosen rootfs, using the device tree the firmware already loaded
  (`${fdt_addr}`).
- RAUC drives it with its built-in `bootloader=uboot` backend, through
  `fw_setenv`.
- U-Boot itself is packaged in Debian trixie (`u-boot-rpi` 2025.01, with an
  `rpi_4` build).

| | Pi firmware tryboot | U-Boot | What it means for the decks |
|---|---|---|---|
| **What updates A/B** | Everything: firmware, kernel, device tree and overlays, `config.txt`, cmdline, initramfs, rootfs | Rootfs and kernel. Firmware, device tree, overlays, `config.txt` and U-Boot stay single-copy | The deck's risky boot settings (the S3's UART, the DSI panel, the watchdog) live in `config.txt` and overlays. With U-Boot they'd be updated **without** a fallback |
| **Attempts** | One per trial; a power-off cancels it | Several (3 in the demo), counted across power cycles | Minor: a cancelled trial only means installing again |
| **Fallback after commit** | None: "The firmware cannot fallback to the other slot if the primary slot gets unbootable" (Rtone) | Yes: the counters keep running, so a slot that breaks later falls back | **U-Boot's real advantage.** It matters if a committed slot breaks later, from SD corruption or a fault that only shows on a later boot |
| **Writes at every boot** | None; one FAT write per commit | `saveenv` to a non-redundant `uboot.env` on FAT at every boot. A redundant environment on a raw partition fixes that, with more setup | The decks were hardened to stop routine card writes |
| **Watchdog during boot** | The firmware arms it (`kernel_watchdog_timeout`; EEPROM boot watchdog on Pi 4 since 2025-07) | "U-Boot does not currently support the watchdog timer for the Raspberry Pi family … must boot … in less than apx. 16 seconds" (br2rauc) | With tryboot, a hang during start-up resets |
| **Boot time** | Nothing added | A stage after the firmware: about +0.5–1.5 s tuned, +3–5 s with defaults, 10–15 s in a known countdown bug (forum and IPFire reports; no controlled Pi 4 benchmark found) | The decks count seconds (splash at ~8 s) |
| **Pi OS fit** | Stock boot chain | Adds U-Boot, its script, environment and tools, none of which Pi OS uses | Sam prefers stock Pi OS |
| **RAUC integration** | Custom backend (~100 lines) now; native backend in review (rauc #1599) | Built-in backend, plus a ~45-line U-Boot boot script and `fw_env.config` | About the same amount of our own code |
| **pi-qemu** | Already plays the firmware; tryboot is our own C++ (§4.2) | U-Boot would have to run on QEMU's raspi4b. **Unverified** | Only tryboot is sure to be testable in the emulator |
| **Direction** | Raspberry Pi docs ("for fail-safe OS updates"), rpi-image-gen, Ubuntu 25.10, HAOS on Pi 5 since 2024, meta-rauc PR #181, RAUC #1599 | HAOS on Pi 2/3/4 (one boot flow across all its boards), br2rauc, meta-rauc today (a "demo") | HAOS's reason doesn't apply: the decks are one board type |

**Device tree experience.** edi-pi (Matthias Lüscher) used U-Boot first. The
firmware "loads the device tree binary and modifies it", which made a robust
kernel and device tree update hard. After moving to tryboot, they update the
kernel, the device tree with its overlays, `start4.elf`, `config.txt` and
`cmdline.txt` safely: "the boot happens without U-Boot".

**What tryboot costs us.** If a committed slot later becomes unbootable, the
deck doesn't heal itself. The mitigations:
- commit only once a real start has shown the deck can take the next release
  (§3.5), so a release that breaks something else is fixed by the next one;
- the firmware's watchdog-partition options don't send a reset to the other
  slot (measured, PLAN.md T9). The EEPROM's boot watchdog does, for a failure
  before Linux starts (T10), and the health check then commits A;
- otherwise, a hand on a Mac: commit the other slot in `autoboot.txt`, which
  the deck keeps (PLAN.md §5.4, F10).

**Reconsider U-Boot if:**
- decks must heal themselves unattended from a slot that breaks after commit,
  and the firmware's watchdog options don't do it;
- or several board types need one boot flow, as for HAOS.

---

## Sources

**Raspberry Pi**
- `config.txt` (autoboot.txt, `[tryboot]`, `[boot_partition=N]`, `[partition=N]`, `cmdline`): https://www.raspberrypi.com/documentation/computers/config_txt.html
- Bootloader, tryboot, models, EEPROM write-protect: https://www.raspberrypi.com/documentation/computers/raspberry-pi.html
- EEPROM release notes (Pi 4): https://github.com/raspberrypi/rpi-eeprom/blob/master/firmware-2711/release-notes.md
- GPT and boot partitions on a Pi 4: https://github.com/raspberrypi/rpi-eeprom/issues/654
- `recovery.bin` on a boot slot: https://github.com/raspberrypi/rpi-eeprom/issues/499
- `boot_partition` in start4.elf: https://github.com/raspberrypi/firmware/issues/1940
- Pi OS kernel config: https://github.com/raspberrypi/linux/blob/rpi-6.18.y/arch/arm64/configs/bcm2711_defconfig
- rpi-image-gen (`image-rota`): https://github.com/raspberrypi/rpi-image-gen

**RAUC**
- Docs: https://rauc.readthedocs.io/en/latest/ and https://rauc.readthedocs.io/en/v1.13/. The pages used:
  - basic: bundles, signing, streaming;
  - integration: system.conf, slot detection, custom backend, systemd, kernel
    options;
  - reference: system.conf keys, slot types, manifest, handlers, slot status;
  - advanced: PKI, adaptive updates;
  - faq;
  - changes.
- Native Pi backend (open): https://github.com/rauc/rauc/pull/1599
- meta-rauc-raspberrypi: https://github.com/rauc/meta-rauc-community/tree/master/meta-rauc-raspberrypi
- Its tryboot draft: https://github.com/rauc/meta-rauc-community/pull/181

**Integrations**
- Rtone backend: https://github.com/Rtone/raspberrypi-firmware-rauc-bootloader-backend
- rasputin-os: https://github.com/geekdojo/rasputin-os
- Home Assistant OS, Pi 5 tryboot: https://github.com/home-assistant/operating-system/blob/dev/buildroot-external/board/raspberrypi/rpi5-64/rootfs-overlay/usr/lib/rauc/rpi-tryboot.sh
- Bootlin, RAUC on a Pi 5: https://bootlin.com/blog/safe-updates-using-rauc-on-raspberry-pi-5/

**U-Boot or tryboot**
- br2rauc (U-Boot; no Pi watchdog in U-Boot): https://github.com/cdsteinkuehler/br2rauc
- meta-rauc's U-Boot boot script: https://github.com/rauc/meta-rauc-community/blob/master/meta-rauc-raspberrypi/recipes-bsp/rpi-u-boot-scr/files/boot.cmd.in
- edi-pi, from U-Boot to tryboot:
  - https://github.com/lueschem/edi-pi/issues/23
  - https://www.get-edi.io/Debian-Bullseye-Upgrade-for-the-Raspberry-Pi/
- Ubuntu 25.10, A/B boot with tryboot: https://discourse.ubuntu.com/t/call-for-testing-a-b-boot-on-raspberry-pi/64173
- Home Assistant OS, Pi 5:
  - https://github.com/home-assistant/operating-system/pull/2914
  - https://github.com/home-assistant/operating-system/discussions/2844
  - https://github.com/home-assistant/operating-system/pull/3842 (a stuck-bootloader bug)
- U-Boot boot time on a Pi 4 (reports, not benchmarks):
  - https://forums.raspberrypi.com/viewtopic.php?t=277010
  - https://community.ipfire.org/t/raspberry-pi-4-2s-u-boot-timeout-takes-15s/10822
- U-Boot in Debian: https://packages.debian.org/trixie/u-boot-rpi

**Debian**
- https://packages.debian.org/trixie/rauc
- https://packages.debian.org/trixie/arm64/rauc-service/filelist

**Checked in this repo and on the emulated deck** (trixie, 2026-09-15 image)
- `raspi-config`'s overlay code (`overlayroot=tmpfs`) and its Pi 5-only "AB
  Firmware" option.
- `overlayroot.conf`: tmpfs, `device:` and `crypt:` modes.
- Package versions available: overlayroot 0.18, rauc 1.13.
- The hardware watchdog (`RuntimeWatchdogSec=1min`), the `/tmp` and `/run`
  sizes, and `~/.mixxx` at 964 KB.
- `pi-qemu/app/src/firmware.cpp` and `machine.cpp`: no tryboot, and the
  filters they handle.
- QEMU's `bcm2835_property.c` (no reboot-flags message) and
  `bcm2835_powermgt.c` (keeps `RSTS`).

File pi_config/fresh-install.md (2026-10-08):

# Fresh install — from Raspberry Pi OS Lite to a working deck

The order to bring a deck Pi up from a freshly flashed card, written while doing
it for **trimixxx2** (started 2026-10-01). Trimixxx1 was away and unreachable,
so everything here comes from this repo and from the new unit itself — which is
also how the state that only ever lived on Trimixxx1 was found. It is listed at
the end.

Generic Raspberry Pi setup first, TriMixxx after. Each step records what was
done on trimixxx2 and what it showed.

`[x]` done on trimixxx2 · `[ ]` to do · `[~]` skipped or deferred, with why

> **There is no default deck.** Every `pi-qemu` command here names its deck: a
> real one is `--host` and its ssh alias, `--host trimixxx-pi-2` for trimixxx2
> and `--host trimixxx-pi` for Trimixxx1. The commands below say
> `trimixxx-pi-2`, the deck this was written on. On a new deck, use its own
> alias. `pi-qemu help` lists the commands.
>
> `pi-qemu deck deploy --host ALIAS` runs every deploy step, in this document's
> order: `base` (most of §1–2), `ttymidi` (§3.1), `system` (§3.2), `launcher`
> (§3.3), `mixxx`, `config` and `library` (§3.4), then `doom` (§3.5). Naming
> steps after the alias runs only those. Passwordless sudo (§1.1) comes first,
> by hand. trimixxx2 was set up with the scripts these steps replaced; §6 names
> them.

## Where it stands

Hardware finished and the case closed (panel, touch and the S3 all wired).
**The deck runs**: the TriMixxx skin on the panel, the controller live over the
UART both ways, the UCA222 at full output. Done: §1, §2, §3.0–3.6 (bar the
UCA222's MONITOR switch, hardware). The deploy-script fixes it took are in §6.
Since 2026-10-01 the splash comes up much sooner after power-on (§1.4) and the
button lights go off at shutdown (`trimixxx-lights-off`, see the README).

Since then: normalization is off (+6 dB on every track, §3.6), and this deck's
different button wiring is remapped in Mixxx (§3.4).

**Left:**
1. Pad-by-pad check of the remap, by hand (§3.4).
2. Reseed the effects rack, which is empty (§3.4).
3. The final check (§4); several of its items need hands on the deck.

## 0. Starting point

Raspberry Pi OS Lite, trixie, flashed with Raspberry Pi Imager (user `sam1902`,
hostname `trimixxx2`, home wifi, ssh key), then `apt update && apt upgrade`.
Nothing else. What the fresh image looked like:

| | |
|---|---|
| Board | Pi 4 Model B **Rev 1.5**, 4 GB |
| OS / kernel | Debian 13 trixie, `6.18.50+rpt-rpi-v8` aarch64 |
| Card | 29 GB root (Trimixxx1: 58 GB) |
| `/tmp` | tmpfs, 1.9 GB — stock, same as Trimixxx1 |
| Swap | 2 GB zram via `rpi-swap` — stock, same as Trimixxx1 |
| Boot | 49.5 s to the end of userspace, **26 s of it cloud-init** |
| Sound cards | 0 bcm2835 Headphones · 1–2 vc4hdmi · **3 UCA222** (`CODEC`, PCM2902) |
| UART | no `/dev/serial0`; serial console still on the kernel command line |
| sudo | **not** passwordless: `(ALL : ALL) ALL` |
| ssh | key login works (Imager); password login still on |
| Wi-Fi power save | on |

## 1. Generic Raspberry Pi setup

### 1.1 Access
- [x] **ssh key login.** Done at flash time; `ssh trimixxx-pi-2` works with the
      key `~/.ssh/config` names.
- [x] **Passwordless sudo.** Every deploy step runs `sudo` on the deck over ssh
      with no terminal, so a password prompt is a hard failure, and Raspberry
      Pi OS no longer ships the old `010_pi-nopasswd`. Installed
      `/etc/sudoers.d/010_sam1902-nopasswd` (`sam1902 ALL=(ALL) NOPASSWD: ALL`),
      checked with `visudo -cf` before it went in. The same line was also added
      to `/etc/sudoers` (line 48) by hand; either one alone is enough.
- [ ] **`PasswordAuthentication no` for sshd** — no longer optional once the
      Wi-Fi fallback is in (§3.8): its password is in the repo, so anyone at a
      venue can join the deck's hotspot, and with password logins on, the
      login password is all that stands between them and a passwordless sudo.
      `authorized_keys` holds two keys, and key login works. A drop-in,
      `/etc/ssh/sshd_config.d/100-custom-sshd.conf`, was written by hand on
      2026-10-01 but says `PasswordAuthentication yes`, so nothing changed and
      sshd was not restarted. When it says `no`, it wins: sshd keeps the first
      value it reads, and `100-…` sorts before cloud-init's `50-…`, which also
      says `yes`. Validate with `sudo sshd -t`, check `sudo sshd -T | grep
      passwordauthentication`, restart, and prove a NEW key login works before
      closing the old session. The base step now writes `05-trimixxx.conf`
      saying `no`, which sorts before both; it applies from sshd's next start.

### 1.2 Firmware
- [x] **Bootloader EEPROM: network install off** (and with it, the update to
      2026-09-23; the 2026-01-09 image was no longer on disk to keep). Stock Pi 4
      EEPROMs set `NET_INSTALL_AT_POWER_ON=1`, which on every **cold** boot
      shows a "hold SHIFT for network install" screen — on HDMI only, so the
      panel just stays black — and it was most of the black screen at power-on:
      the SD card was first touched **8.15 s** after power came up. Done with:
      ```sh
      sudo rpi-eeprom-config > /tmp/boot.conf    # then edit it to read:
      # NET_INSTALL_AT_POWER_ON=0
      # NET_INSTALL_ENABLED=0     <- also skips the ~1 s USB keyboard probe
      sudo rpi-eeprom-config --apply /tmp/boot.conf && sudo reboot
      ```
      The other lines (`BOOT_UART=0`, `WAKE_ON_GPIO=1`, `POWER_OFF_ON_HALT=0`)
      stay as they were. The flash happens on that reboot, from `recovery.bin` on
      the boot partition, which stays there until the flash succeeds — a power cut
      mid-flash just means it flashes again on the next boot. Keyboard detection
      at boot is also known to leave some already-connected USB devices stuck
      ([rpi-eeprom#834](https://github.com/raspberrypi/rpi-eeprom/issues/834));
      the UCA222 is one of those. Check: `vcgencmd bootloader_config`.

### 1.3 Boot flags — `/boot/firmware/config.txt`, `cmdline.txt`
Originals kept as `config.txt.pre-trimixxx` and `cmdline.txt.pre-trimixxx`
next to them. Three stock lines changed in place, and one block appended at the
end of `config.txt`:

```
dtparam=audio=on          ->  dtparam=audio=off
display_auto_detect=1     ->  display_auto_detect=0
dtoverlay=vc4-kms-v3d     ->  dtoverlay=vc4-kms-v3d,noaudio
camera_auto_detect=1      ->  camera_auto_detect=0     (§1.4, boot speed)

[all]
enable_uart=1
dtoverlay=disable-bt
dtoverlay=vc4-kms-dsi-waveshare-panel,10_1_inch
disable_splash=1
```

and in `cmdline.txt`, `console=serial0,115200 ` removed (it stays one line).
- [x] **UART for ttymidi:** `enable_uart=1` + `dtoverlay=disable-bt`, so
      `/dev/serial0` is the full PL011 (`ttyAMA0`) on GPIO14/15, whose baud does
      not drift with the core clock. Bluetooth goes; the deck has no use for it.
- [x] **Serial console off:** `console=serial0,115200` removed from
      `cmdline.txt`, which would otherwise fight ttymidi for the port.
- [x] **One sound card:** `dtparam=audio=off` and `dtoverlay=vc4-kms-v3d,noaudio`
      (HDMI *video* stays). The UCA222 becomes card 0, as on Trimixxx1 —
      `soundconfig.xml` says `hw:0,0`, although Mixxx matches on the device name
      when only one device has it.
- [x] **The panel:** `dtoverlay=vc4-kms-dsi-waveshare-panel,10_1_inch` — Waveshare
      10.1" DSI LCD (C), 1280×800, Goodix touch over I2C0 *through the DSI
      ribbon*; the GPIO header only powers it (5V/GND). Wiring the panel's
      SDA/SCL to GPIO2/3 instead needs `,i2c1` on the overlay.
      `display_auto_detect=0`: Waveshare panels answer on the official Touch
      Display's I2C address, and auto-detect would load the wrong overlay on top.
- [x] `disable_splash=1` — no rainbow square; the deck's own splash follows.
- [x] Console blanking: `consoleblank` is already 0 on this kernel. Nothing to add.
- [x] Verified on the first boot with the panel: `/dev/serial0` → `ttyAMA0`;
      `aplay -l` lists only `CODEC`, as card 0; `DSI-1` connected, HDMI not;
      `/dev/fb0` 1280×800, 16 bpp, stride 2560; backlight `10-0045` at 255/255;
      `Goodix-TS 10-0014: ID 9271` registered as an input device.

### 1.4 Boot time and background load
- [x] **cloud-init off**, now that Imager's first boot is done:
      `sudo touch /etc/cloud/cloud-init.disabled`. The 26 s was first-boot
      provisioning; on later boots it was ~2 s, and it orders itself before
      `systemd-user-sessions`, which the tty1 autologin — hence Mixxx — waits on.
      Wifi is unaffected: the connections live in `/etc/netplan` (NetworkManager's
      own `90-NM-*.yaml`). `cloud-init status` → `disabled`; ssh came back.
- [x] `sudo systemctl disable --now bluetooth` — no controller left after
      `disable-bt`.
- [x] `sudo systemctl disable --now apt-daily.timer apt-daily-upgrade.timer
      man-db.timer` — no background apt or man-db runs mid-set competing with
      the audio thread for CPU and card IO. Update by hand instead.
- [x] **Wi-Fi power save off:** `/etc/NetworkManager/conf.d/wifi-powersave-off.conf`
      with `[connection]` / `wifi.powersave = 2`, and live with
      `sudo iw dev wlan0 set power_save off` (no reconnect). Still off after the
      reboot.
- [x] Reboot: whole boot **15.3 s** (22.9 s before this section, 49.5 s fresh).
      `getty@tty1` starts at 13.0 s, behind `NetworkManager.service`, which takes
      7.8 s to start — where most of what is left goes.

#### Splash as soon as possible after power-on
The panel used to stay black for ~20 s after power-on before the TriMixxx logo.
Where that went, and what was done (times from power-on unless said otherwise):

| Stage | Was | Fix |
|---|---|---|
| Bootloader's network-install screen, cold boots only | 8.15 s | EEPROM, §1.2 |
| Firmware reads the 12.5 MB initramfs (SD at ~10.6 MB/s) | 1.18 s | kept — see below |
| Firmware reads and un-gzips the kernel | ~2.3 s | — (an uncompressed one reads no faster) |
| systemd generators: `rpi-swap` runs Perl (`ack`) twice | 1.37 s | swap sizes pinned |
| vc4 waits for the panel's drivers from the root fs; panel up at 6.15 s kernel time | | panel drivers in the initramfs |

- [x] **Panel drivers in the initramfs.** Raspberry Pi's initramfs already
      carries vc4 and starts the display there, but vc4 binds the panel and both
      HDMI ports as one unit, and the DSI panel's driver and the I2C mux in front
      of it were not in it — so the panel waited for the root filesystem.
      The system step adds `i2c_mux_pinctrl` and `panel_waveshare_dsi` to
      `/etc/initramfs-tools/modules`, the standard place, which every kernel
      update re-reads, and rebuilds with `sudo update-initramfs -u -k "$(uname -r)"`
      (that also copies it to `/boot/firmware/initramfs8`). The panel now comes
      up at **1.66 s** kernel time, showing the boot log until the logo.
- [x] **The initramfs stays.** Booting without one (`auto_initramfs=0`) was tried
      and works — this kernel has the SD and ext4 drivers built in — and is
      ~1.5 s faster to the logo, but it was **reverted**: with the kernel mounting
      root itself, root shows as `/dev/root`, and `update-initramfs` (with
      `MODULES=dep`) then fails with *failed to determine device for /*. Every
      kernel update runs it, so the next `apt upgrade` would have ended in a
      dpkg error; and Raspberry Pi OS ships with the initramfs on, so nothing
      stops a future kernel from moving those drivers into modules, which would
      leave a deck without one unbootable. Not worth a second.
- [x] `camera_auto_detect=0` — no camera; spares the firmware probing for one.
- [x] **Swap sizes pinned:** the system step installs `trimixxx-swap-sizes.conf`
      into `/etc/rpi/swap.conf.d/` (2048 MiB zram, 2048 MiB file — what
      rpi-swap was computing anyway). Checked: the generator writes
      byte-identical units. Generators 1.37 s → 0.70 s, and no unit starts
      before they finish.
- [x] Result, cold boot (2026-10-02, `rsts` 0x1000), firmware clock from
      power-on: SD card first read at **2.8 s** (8.15 s before), kernel starts at
      **8.2 s** (14.0 s), panel shows the boot log at ~9.9 s (kernel 1.66 s; was
      ~20 s) and the logo at ~13.1 s (kernel 4.84 s; was ~20.5 s). The logo waits
      for systemd, because the splash is a systemd service. Counted by hand from
      the power going on: ~8 s to the splash.
- **Trying a boot change safely** on a deck you cannot get a keyboard into — how
  all of the above was tested: put the candidate in `/boot/firmware/tryboot.txt`
  (an initramfs as `initramfs <file> followkernel` with `auto_initramfs=0`; and
  `cmdline=cmdline.tryboot.txt` pointing at a copy of `cmdline.txt` that adds
  `rootwait=20 panic=10`, so a root that never mounts reboots by itself), then
  `sudo reboot '0 tryboot'`. Only that one boot uses it; any reboot or power
  cycle after returns to `config.txt`. `/proc/device-tree/chosen/bootloader/tryboot`
  reads 1 during the test.
- Measuring: `sudo vclog --msg` is the firmware's own log, stamped in ms from
  power-on (`arasan_emmc_open` = SD first touched, `Starting ARM` = kernel
  starts). After that, use `dmesg` — the splash writes
  `trimixxx-splash: up on vt7` there. Do **not** use journal times this early:
  journald is not up yet and stamps lines when it reads them, seconds late.
  `rsts` in `/proc/device-tree/chosen/bootloader/` says which kind of boot it
  was: `0x1000` power-on, `0x20` reboot.

### 1.5 Card wear
- [x] **log2ram:** `sudo apt install log2ram` — Debian trixie packages it now
      (1.7.2), no third-party repo, no other packages pulled in. `/var/log` (576 K
      at the time) moves to a 128 M tmpfs and syncs to the card daily
      (`log2ram-daily.timer`) and at shutdown. Trimixxx1 ran it. Active after the
      reboot: `findmnt /var/log` → `log2ram tmpfs`.
- [~] Cap journald to fit in log2ram's RAM disk — not needed here: this image
      has no `/var/log/journal`, so the journal is volatile and already lives in
      `/run`, not in `/var/log`.
- [x] **Mixxx's logs off the card** (2026-10-02). They were the card's one
      steady writer, not `/var/log`: with Mixxx idle, 33 writes a minute, and
      112,546 of the 113,212 lines in a session's `mixxx.log` were a single
      `--developer` message. log2ram does not cover `~/.mixxx`. `xinitrc` now
      runs Mixxx without `--developer` and puts both logs in `/tmp/mixxx`
      (tmpfs) — `mixxx.log` through the fork's `--log-path`. They no longer
      survive a reboot.
- [x] **Mixxx never writes `mixxx.cfg`** (fork, 2026-10-02): it used to save
      it on exit by deleting the old file and renaming the new one in, with no
      fsync, so a power cut within ~30 s of quitting could leave it empty.
      The config step is now the only thing that writes it.

### 1.6 Real-time audio — only if needed
- [ ] If the first Mixxx run logs that it could not get real-time priority:
      `/etc/security/limits.d/95-audio.conf` with `@audio - rtprio 95` and
      `@audio - memlock unlimited`. Not known whether Trimixxx1 had it.

## 2. Display, touch, X

- [x] **Packages**, run in a transient systemd unit so a dropped ssh cannot
      leave dpkg half-done: `xserver-xorg xinit x11-xserver-utils xinput
      libgl1-mesa-dri mesa-utils unclutter picom matchbox-window-manager scrot
      xdotool evtest libinput-tools mixxx`. That is 337 packages with recommends,
      and no PipeWire, PulseAudio or display manager among them (any of those
      would take the UCA222 away from Mixxx). Recommends also brought
      `gnome-keyring` and `gcr-ssh-agent`: socket-activated user units that
      `startx` never wakes. `scrot` / `xdotool` are for `pi-qemu deck shot` and
      its touch verbs (`deck tap`, `swipe`, ...); `evtest` / `libinput-tools` /
      `mesa-utils` are for checking the panel.
- [x] **`xinitrc`, two fixes** (this repo, §6): the DSI panel is the primary
      output, an HDMI monitor mirrors it scaled to fit (debugging), and the
      touchscreen is pinned to the panel; and `mkdir -p ~/.mixxx` before the
      Mixxx loop. Its `awk` parsing was checked against sample `xrandr` /
      `xinput` output under the Pi's own `mawk`.
- [x] Session files onto the Pi: `~/.xinitrc`, `~/.bash_profile`,
      `/usr/local/bin/trimixxx-debug` — the session part of what was then
      `pi_config/upload.sh`, run on its own so the panel could be tested before
      the rest of the deck existed. The system step installs them now.
      There was no previous `~/.bash_profile`, and `~/.profile` has no `startx`.
- [x] **Console autologin on tty1:** `sudo raspi-config nonint do_boot_behaviour B2`
      — writes `getty@tty1.service.d/autologin.conf`
      (`agetty --autologin sam1902`). The base step does this now; Trimixxx1
      had it done by hand. Until the rest of the deck is installed, the session
      starts stock Mixxx 2.5.0 with its first-run dialogs — enough to test touch.
- [x] Powered off to wire the panel (2026-10-01).
- [x] Verified with the panel attached: `xrandr` shows `DSI-1` 1280×800 at
      60 Hz, primary; the touchscreen's coordinate matrix is the identity (the X
      screen is exactly the panel); touch confirmed working by hand; `glxinfo -B`
      → `V3D 4.2.14.0`, direct rendering, OpenGL 3.1 Mesa 26.2.2. Stock Mixxx came
      up on it, showing its first-run "Choose music library directory" dialog.
- [ ] **Orientation**, once it is in the chassis: if it mounts upside down,
      `rotation=180` on the panel overlay, plus the touch `invx`/`invy` the
      overlay README describes — re-check after.
- [x] **DECIDED — scale Mixxx to fit the panel** (`xinitrc`, §6). The skin is
      pinned to 1024×600: every top-level group in `skin.xml` has Minimum =
      Maximum `1024,600`, so on this panel it would sit top-left with a 256 px
      band to the right and 200 px below. `xinitrc` now exports
      `QT_SCALE_FACTOR` = the smaller of panel-width/1024 and panel-height/600,
      only when that is not 1: **1.25** here, giving a 1024×640 logical screen —
      the skin fills the width and leaves 40 logical (50 real) px at the bottom.
      Nothing changes on a 1024×600 panel. The variable overrides `mixxx.cfg`'s
      `ScaleFactor` (`adjustScaleFactor()` in `mixxx/src/main.cpp`), so one
      shared `mixxx.cfg` still serves both decks. Text stays sharp, bitmap art is
      resampled, and the GL waveforms draw ~56 % more pixels — watch the frame
      rate and temperature. Options not taken: also letting the skin's height
      stretch into the last 40 px (a skin change, possible later); scaling in X
      (`xrandr --scale-from 1024x600`: a 6.7 % vertical stretch, soft, a GPU
      transform every frame); a native 1280×800 layout (the most work).

## 3. TriMixxx

### 3.0 On the Mac
`pi-qemu` on PATH (`pi-qemu/build.sh` puts it there), Docker Desktop running
(all Pi binaries are arm64 builds in Docker), `uv`, and `rsvg-convert`
(`brew install librsvg`) for the splash.
- [x] Built while the Pi was off, so the deploys below hit a warm cache:
      `ttymidi`, `trimixxx-launchd` and `trimixxx-deckkeys` (static arm64), and
      the Mixxx fork at HEAD `08174e6` (12 min). The `mixxx/dist/mixxx` on disk
      predated that commit. Each deploy rebuilds anyway, from that cache.

### 3.1 ttymidi — before the system step
- [x] `pi-qemu deck deploy --host trimixxx-pi-2 ttymidi`
      → `/usr/local/bin/ttymidi`, `ttymidi --version` → `42175e8`.

  First because the system step enables and *restarts*
  `trimixxx-bridge.service`, which needs this binary. The system step checks
  for it and stops before changing anything if it is missing (§6). On trimixxx2
  this was ttymidi's `make install-remote`, which needed `SERVICE=` (empty) on
  a fresh unit: it ended with `systemctl try-restart trimixxx-bridge.service`,
  which exits 5 for a unit that does not exist yet, so `make` reported a
  failure after the binary was in fact installed. The ttymidi step restarts the
  bridge only if it runs.

### 3.2 The deck's system (`pi_config/`)
- [x] `pi-qemu deck deploy --host trimixxx-pi-2 system`. On trimixxx2 this was
      `pi_config/upload.sh`: exit 0, end to end, its first complete run since
      2026-08-01. Fixed before first use here (§6):
  - **It did not parse.** An apostrophe in an `echo` inside a single-quoted
    `ssh '…'` block closed the quote, so every run since that line went in died
    after `~/.xinitrc` — the `.bash_profile`, getty drop-in, splash, eth0 and
    dj-usb sections never ran from it.
  - **eth0 with no cable** no longer fails the run: the profile is still set to
    link-local, and NetworkManager brings it up when something is plugged in.

  What it did: governor `performance` (1.8 GHz, §3.7); `trimixxx-bridge` active
  with the `TriMixxx` ALSA client; `ip_unprivileged_port_start` = 111; the Noto
  chain resolves (Noto Sans → CJK JP → Symbols 2 → Color Emoji → DejaVu); the
  session files, now with the scale factor; the getty stop drop-in; the splash;
  eth0 `auto` → `link-local` (no cable yet, wlan0 untouched); dj-usb.
- [x] **The splash is rendered for whatever `/dev/fb0` is at the time** — with an
      HDMI monitor attached, the monitor's geometry, which the boot-time check
      then refuses (by design). Rendered here with only the panel attached:
      1280×800, 16 bpp, stride 2560, 2 048 000 bytes, matching. Deploy the
      system step again if the panel or its mode changes.
- [x] **The UART link to the S3, both ways.** Pi → S3: three Note On/Off pairs
      for the PLAY LED went out — `tx` in `/proc/tty/driver/ttyAMA` went 0 → 18
      bytes — and after the move the PLAY LED was seen blinking at boot, which
      is the launch manager opening its boot-gesture window over the same path.
      S3 → Pi: `aseqdump -p TriMixxx` showed PLAY (note 60, `0x3C`), CUE (61,
      `0x3D`) and the jog (CC 17, relative ±1) while they were pressed; `rx`
      went 6 → 647 bytes. Note that ttymidi has *two* ports named `TriMixxx`:
      port 0 is read-only, so `aseqsend -p TriMixxx` goes nowhere; the writable
      one is `128:1` (`aseqsend -p 128:1 90 3C 7F`). `aseqdump -p TriMixxx`
      listens on port 0, which is the right one.

### 3.3 Launch manager
- [x] `pi-qemu deck deploy --host trimixxx-pi-2 launcher` — active, both
      readiness gates passed (`pi-midi-daemon` port, mode file), mode `mixxx`.

### 3.4 Mixxx
- [x] `apt install mixxx` (2.5.0+dfsg, trixie) — for its libraries and
      `/usr/share/mixxx`. Only the binary gets replaced.
- [x] `pi-qemu deck deploy --host trimixxx-pi-2 mixxx` — builds the fork and
      swaps `/usr/bin/mixxx` (24 MB), keeping apt's as `/usr/bin/mixxx.apt`
      (17 MB). The `ldd` check found nothing missing. The running Mixxx has
      `QT_SCALE_FACTOR=1.25` in its environment, from `xinitrc`.
- [x] **Once, before the first config deploy:**
      `ssh trimixxx-pi-2 'sudo systemctl stop getty@tty1 && rm -f ~/.mixxx/effects.xml && mkdir -p ~/Music'`.
      Stock Mixxx ran at the first boots and writes its own `effects.xml` *on
      exit* — so stop the session first, or it writes it straight back.
      `mixxx_config/upload.sh` then seeded the TriMixxx chain only when the
      deck had none, so it would otherwise have kept the stock rack, and the
      effect-pedal return would have been silent. `~/Music` is for the next
      point. On trimixxx2 there turned out to be no `effects.xml` to remove:
      Mixxx had never got past its first-run dialog, so it never wrote one.
      Keep the step anyway — it costs nothing.
- [x] `pi-qemu deck deploy --host trimixxx-pi-2 config` — now creates
      `~/.mixxx/skins` and `~/.mixxx/controllers` itself (§6). Every XML
      validated; the shipped `effects.xml` was seeded.
- [x] **Answer "Choose music library directory" once, by touch: Choose → `Music`.**
      Done by hand; the `directories` table now holds `/home/sam1902/Music`.
      Mixxx then came up with the TriMixxx skin, scaled to the panel's width; the
      TriMixxx controller opened for input and output with its script; the
      UCA222 opened as `hw:0,0` at 44.1 kHz, 256 frames (5.8 ms).
      Mixxx shows that dialog at every start for as long as its database has no
      music directory (`loadRootDirs().isEmpty()` in `coreservices.cpp`) —
      Cancel just brings it back next boot. It is database state, not
      `mixxx.cfg`, which is why Trimixxx1 never shows it. On the fresh image
      `~/Music` did not exist, which is why "Choose" was greyed out. The library
      step now does both (`pi-qemu deck deploy --host trimixxx-pi-2 library`):
      it makes `~/Music`, and puts it in the `directories` table if that is
      empty.
- [ ] Check Preferences → Controllers: **TriMixxx** and **pi-midi-daemon** both
      enabled with their mappings. `mixxx.cfg` binds them by device name, so the
      config step should already have done it.
- [x] **This deck's button wiring** (`mixxx_config/units/trimixxx2.json`). BACK
      seemed dead: pressing every control in order with `aseqdump -p TriMixxx`
      running showed ring A has an **eighth pad, third in its chain** (note
      `0x02`, no function yet), which pushes 8-beat, 4-beat, ×2, ÷2 and BACK one
      node down (`0x03`–`0x07`) — so ÷2 was opening the library and BACK sent a
      note nothing listened to — and **hot cues 1–4 arrive reversed**
      (`0x46`…`0x43`). Tempo range, keylock, slip, sort, loop in/out, reloop and
      the encoder are standard; PLAY/CUE too (the capture had them the other way
      round — taken as pressed in the other order). Fixed in Mixxx, not the S3:
      the config step renumbers the mapping from that file for this deck alone
      (`units/apply.py`, see `mixxx_config/README.md`), the ring LEDs follow,
      and Mixxx logs `TriMixxx: buttons and lights remapped for trimixxx2`.
      BACK on its new note opens the library. Note the encoder push over the
      deck is the FX mute, by design — BACK opens the library.
- [ ] By hand on the deck, now remapped: BACK opens the library and a hold
      (0.6 s) returns to the deck; 8/4-beat loops, ×2/÷2 and hot cues 1–4 do
      what they say (needs a track loaded); each pad's light sits on its own
      pad; the eighth pad does nothing.
- [x] **The jog is wired the other way round** on this deck: `"jogReversed":
      true` in the same unit file; `TriMixxx.jog` flips the tick before scratch
      and bend alike. Checked in node (one tick: −0.3 standard, +0.3 here) and
      deployed.
- [x] **Ring LEDs 20 % dimmer** — `TriMixxx.RING_LEVEL = 0.8`, applied in
      `ringLed()`/`ringLedPair()` to everything, so SORT/KEY SYNC (which set
      their own levels, up to 1.0) and the boot sweep dim with the rest and the
      tuned ratios hold. First as 0.8 of the duty cycle, which looked like no
      change: the WS2812s are linear and nothing between Mixxx and them corrects
      for gamma, so 80 % duty reads as ~10 % dimmer. Now gamma-corrected, 0.8²·²
      = 61 % duty (full white 255 → 156). Shared: Trimixxx1 gets it on its next
      config deploy.
- [x] **No bezel strips on this deck** — `"bezel": false` in the unit file. The
      panel sits flush, so the strips Trimixxx1 needs (deck view 36 px top /
      14 px bottom; browser 36 top, 56 bottom, 16 left; rack 56 bottom) were
      dead bands here, plus 20 px of letterbox top and bottom because the skin
      was pinned to 600 high in a 640-high screen. Skin: a `[TriMixxx],bezel`
      attribute the strips follow, and open maximum heights (minimums kept, so a
      600-high screen lays out as before). Fork: `deckbezel.h`, read by
      `WDeckBrowser` and `WDeckRack` when built. Checked by screenshot: deck
      view, browser and Effects page all edge to edge; the waveform grew from
      414 to 488 logical px. Needs the fork rebuilt — `mixxx/dist/mixxx`
      `760d69ef…`, from uncommitted fork sources as of this writing.
- [ ] **Docker's disk is full.** `mixxx/upload.sh`'s rebuild of that same
      binary failed with `No space left on device`; it was installed by hand
      from the earlier, identical build instead (the post-build half of
      `upload.sh`: `ldd` check, swap, session restart). `docker system df`: 28 GB
      of build cache (19 GB reclaimable), 11 GB of images (10 GB reclaimable).
      Pruning the build cache costs the next Mixxx build its ccache — one cold
      ~12 min build.
- [~] **Known limit of a Mixxx-only remap:** the launch manager and Doom
      (`trimixxx-deckkeys`) read the same MIDI with the canonical table. PLAY,
      CUE and LOOP IN/OUT are standard here, so the boot gestures and the panic
      chord work; in Doom, ring A's pads from the third on and ring B's hot-cue
      pads land as wired, and the jog turns the other way.
- [ ] **The effects rack is empty.** The seeded `effects.xml` carries a reverb
      on the pedal bus (EffectUnit2, WET), but the deck's file now holds an
      empty WET chain, and the Effects page shows "EMPTY RACK". Most likely
      emptied by the button test — BACK re-opened the library on the Effects
      page, where pads and the encoder edit the rack. To reseed:
      `ssh trimixxx-pi-2 'sudo systemctl stop getty@tty1 && rm ~/.mixxx/effects.xml'`
      then `pi-qemu deck deploy --host trimixxx-pi-2 config`.

### 3.5 Doom
- [x] `pi-qemu deck deploy --host trimixxx-pi-2 doom` (the WAD is already in
      `doom/wad/`) — Chocolate Doom 3.1.0, 17 packages. Among them are
      `libpulse0` and `libpipewire-0.3`, the client libraries SDL2 links
      against; the PulseAudio and PipeWire *servers* are only suggested and are
      not installed.

### 3.6 Audio levels
- [x] **UCA222 output to 0 dB.** It came up at −20 dB (108/128). Anything under
      unity throws away 16-bit resolution:
      `amixer -c CODEC sset PCM 0dB && sudo alsactl store` → 128/128, 0.00 dB,
      saved in `/var/lib/alsa/asound.state`, which is not versioned (see
      README, "Not yet versioned here").
- [ ] **UCA222 MONITOR switch OFF** — hardware. Left on, it feeds the input
      straight back into the output (`worklog/effect-pedal`).
- [x] **DECIDED — normalization off** (`ReplayGainEnabled 0` in the shared
      `mixxx.cfg`, live on trimixxx2, and on Trimixxx1 since its config upload
      of 2026-10-03). Why, from the investigation:
- **Every track played 6 dB down, on both decks.** Trimixxx1's
      line level was reported as "a bit low". The hardware is already at its
      ceiling: `PCM` 128/128 is the codec's maximum (0 dB, no positive gain),
      Mixxx opens `hw:0,0` with no ALSA software volume in between, and the
      UCA222's line out tops out at **2 dBV (≈1.26 V RMS)** per its manual
      (`datasheet/UCA222-User-Manual.pdf`) — a CD player's line out is
      typically ~2 V RMS (+6 dBV), so ~4 dB more. But `mixxx.cfg` has
      `[ReplayGain] ReplayGainEnabled 1` with `ReplayGainAnalyserEnabled 0` and
      `InitialDefaultBoost -6`: in `EnginePregain::process()` a track with no
      ReplayGain value gets `[ReplayGain],DefaultBoost`, i.e. −6 dB, and with the
      analyser off no track ever gets a value unless its file carries ReplayGain
      tags (rekordbox exports generally do not). So everything plays at half
      amplitude, and nothing is actually being normalised. Options:
  - `ReplayGainEnabled 0` — every track at unity, like a CDJ: +6 dB across the
    board. A loud master's own peaks then reach the DAC as mastered; EQ boosts
    can clip, as on any player at unity.
  - `InitialDefaultBoost 0` — the same for untagged files, but files that carry
    ReplayGain tags would still be normalised down (typically 6–10 dB for modern
    masters), so tagged and untagged tracks would play at different levels.
  - The remaining ~4 dB below a CD player is the UCA222's analog ceiling: the
    mixer's channel trim, or a hotter DAC. Software gain past unity (pregain or
    main gain) only clips loud masters.
- [x] **Diagnostics → Adjust** (fork, `DeckLevels`), the page's first section:
      the output trim — `[Master],gain`, ±6 dB in 0.5 dB steps, with a
      Clipping row beside it for when above unity starts to bite — and the
      panel's brightness, 10–100 % in 5 % steps through
      `/sys/class/backlight/10-0045/brightness`. That file is group `video`
      (Raspberry Pi OS's `60-backlight.rules`) and `sam1902` is in `video`, so
      there is nothing to install. Both are kept in `~/.mixxx/trimixxx-levels`
      and put back when the skin loads. Seen on trimixxx2's panel 2026-10-03
      through `deck-poke` / `deck-shot`: press to adjust, turn, press on to
      brightness, BACK out of adjusting, BACK held mid-adjust, and a restart
      restoring both. Left at 0 dB / 100 % with no levels file.

### 3.7 Per-unit differences
- **CPU clock.** A Rev 1.5 board with `arm_boost=1` runs to 1.8 GHz, so the
  `performance` governor pins 1.8 GHz — measured, `scaling_cur_freq` 1800000 —
  not the 1.5 GHz that `cpu-governor.service`'s comment measured on Trimixxx1.
  In the closed case: 47 °C idle on `ondemand`, 53.5 °C minutes after the
  switch. Trimixxx1 idled at 71 °C in its chassis. Check `vcgencmd
  measure_temp` and `get_throttled` under a real set; `arm_boost=0` is the
  fallback.
- **Pro DJ Link.** The fork claims a free player number by watching the network
  (`virtual_cdj.rs`), so two decks on one network do not need different
  settings.
- **Panel.** See the skin decision in §2.

### 3.8 Reaching the deck at a venue
No home Wi-Fi there, and last-minute fixes still have to be possible.
- [x] **ssh over Ethernet already works.** sshd listens on every interface
      (`0.0.0.0:22`, `[::]:22`), eth0 included. On the CDJs' switch eth0 holds a
      169.254 link-local address; a laptop on the same switch gives itself one
      too, then `ssh sam1902@trimixxx2.local` (avahi answers on every
      interface) or the address the Diagnostics page shows.
- [x] **Diagnostics → Network** (fork, `WDeckDiagnostics`), right under
      Identity: host and the ssh line to type; eth0's live address, or "no
      cable" / "linked, no address yet"; Wi-Fi as home network + address, or
      HOTSPOT + name + password + address, from `/run/trimixxx/wifi`. Built cold
      after the Docker prune and deployed with `mixxx/upload.sh`. Seen on the
      panel: `trimixxx2  ssh sam1902@trimixxx2.local`, `Ethernet: no cable`,
      `Wi-Fi: Odildo-3F96AC · 192.168.1.118`. The eth0-address and hotspot
      lines are still to be seen with a cable / during a fallback.
- [x] **Wi-Fi fallback** (`pi_config/wifi-fallback/`, see its README): if wlan0
      has not joined a network 45 s into a boot (30 s more if mid-connection),
      the deck brings up its own access point — SSID = hostname, password
      `trimixxx-debug-Kmj3Df` (`wifi-fallback/hotspot.env`), 2.4 GHz channel
      from the deck's unit file, `hotspotChannel` (Trimixxx1 6, the default;
      trimixxx2 7), the deck at 10.42.0.1. Once per boot, never undone; a
      reboot retries home. shellcheck clean. Installed inert (`autoconnect=no`
      profile, unit enabled not started, wlan0 and the default route checked
      unchanged). Tested:
      - at home it does nothing but record `mode=client` (started by hand, then
        on a real boot): 39 ms to start, not on Mixxx's critical chain — getty
        at 16.4 s is NetworkManager's 7.8 s plus the launcher's 3.3 s gesture
        window, as before;
      - the one-off test boot (`echo 300 | sudo tee
        /var/lib/trimixxx/wifi-fallback-test`, reboot): `trimixxx2` appeared,
        a phone joined with the password, and ssh over it worked. Rebooted by
        hand mid-hold: a normal boot, flag gone, home Wi-Fi back, wlan0's
        runtime autoconnect back on.
      The test boot's own log is gone — journald is volatile on this image (no
      `/var/log/journal`), so nothing survives a reboot. Make the journal
      persistent first if a fallback ever needs post-mortem reading.
- [x] The rescue console (hold CUE at boot) prints `/run/trimixxx/wifi` too, so
      the hotspot's name and password are on screen when Mixxx is what broke.
- [x] **A USB keyboard gets a shell, two ways, no network needed.**
  - Any time: Ctrl+Alt+F2 → a password login on tty2 (logind's on-demand
    gettys, `NAutoVTs` default 6; X allows VT switching). Ctrl+Alt+F1 back to
    Mixxx. If X is hung, Alt+SysRq+R first (`kernel.sysrq` 438 allows it;
    Alt+SysRq+B reboots on the spot). `sam1902` has a password, set at flash.
  - The rescue console: a shell already logged in, no X. **It could not have
    worked before this**: it opened `bash --login`, which re-reads
    `~/.bash_profile`, which on tty1 with the mode still `debug` ran the console
    again — inside itself, without end, until sam1902 ran out of processes (and
    then even ssh as sam1902 cannot fork). Now `bash -i`, plus a
    `TRIMIXXX_RESCUE` guard in `~/.bash_profile`. Tested by writing the mode
    file (`echo debug | sudo tee /run/trimixxx/mode`, the launcher restarts the
    session) with a root timer as backstop: exactly one level (login shell →
    `trimixxx-debug` → `bash -i`), the banner and a prompt on tty1; hanging the
    shell up ran the real hand-back — mode `mixxx`, X and Mixxx back, the
    deck-keys bridge stopped. The CUE gesture itself is still to be tried by
    hand.
  - **No keyboard at all: the touchscreen.** The rescue console starts X with
    the shell in an `xterm` on the left half and `matchbox-keyboard` on the
    right (`rescue-session`, `rescue-keyboard.xml`; `xterm` +
    `matchbox-keyboard`, no recommends: 5 small packages). Focus is pinned to
    the terminal, since with no window manager X would hand it to whatever the
    finger last touched; the keyboard types through XTEST. If X does not come
    up, the bare console takes over (a marker file tells "left" from "never
    started"; seen working when the keyboard was failing). What it took:
    this build segfaults on *any* layout argument, so ours is
    `~/.matchbox/keyboard.xml`, the default name; the stock layouts have no
    digits, Tab, Ctrl or arrows; its labels need DejaVu Sans (one font, no
    fallback — boxes otherwise) and two-unit keys for words; its colours are
    compiled in, so picom (xrender) inverts the window to dark; and it keeps a
    2:1 shape, 640×320 at the top of the right half, which is fine. Typing by
    touch confirmed on the deck.
  - **Pads at half brightness in the rescue console**: `trimixxx-deckkeys`'s
    console map lit every pad at the Doom map's levels, the whole deck at
    once. Now `RGB.Scaled(0.5)` on every ring pad of that map — half the duty
    cycle, half the current — and Doom unchanged (`trimixxx-launcher`,
    `internal/keymap`). The lamps (play, cue, loop) are on/off only.

## 4. Final check, after a cold boot
- [ ] `systemctl --failed` is empty; `systemd-analyze critical-chain getty@tty1.service`
- [ ] `grep -E 'TriMixxx|pi-midi-daemon' /proc/asound/seq/clients` — both ports
- [ ] `cat /run/trimixxx/mode` → `mixxx`
- [ ] Mixxx: the UCA222 opened, both controllers loaded (`/tmp/mixxx/mixxx.log`)
- [ ] `pi-qemu deck shot --host trimixxx-pi-2 deck.png` shows the TriMixxx skin;
      `deck tap` and `deck press` (the same `--host`) move it
- [ ] A rekordbox stick mounts at `/media/DJ_USB_1` and shows in the library
- [ ] `ip -4 addr show eth0` → `169.254.x.x` with a CDJ attached; players appear
- [ ] Boot gestures: hold PLAY → Doom, hold CUE → debug console; the panic chord
- [ ] POWER menu shuts the deck down cleanly
- [ ] Temperature after half an hour of playing

## 5. State that only existed on Trimixxx1
Not in the repo, so not copied. Recreate it or accept the loss:
- **Its `config.txt`.** Probably a DSI overlay for its 1024×600 panel: the splash
  notes record a 720×576 firmware framebuffer before vc4 takes over, which is
  what the firmware falls back to with no HDMI display.
- `/var/lib/alsa/asound.state` (§3.6).
- `~/.mixxx/mixxxdb.sqlite`: library, analysis, playlists — and any tracks
  stored on its card under `~/Music`.
- Its `effects.xml` as last left at the mixer; trimixxx2 starts from the shipped
  seed.
- Anything installed or scheduled by hand. No systemd timers or cron jobs are
  versioned anywhere in the repo, so any it had lived only on that card.

## 6. Repo fixes made during this install
Found by running the deploy path against a blank unit. Uncommitted as of this
writing.
- `pi_config/upload.sh` — **did not parse** (the apostrophe in §3.2); and a
  preflight that stops before changing anything if ttymidi is not installed.
- `pi_config/prolink-eth0.sh` — no cable in eth0 sets the profile and reports
  "comes up when plugged in" instead of failing.
- `mixxx_config/upload.sh` — creates `~/.mixxx/skins` and `~/.mixxx/controllers`
  before copying into them.
- `pi_config/xinitrc` — DSI panel primary, HDMI mirrored, touch pinned to the
  panel; `QT_SCALE_FACTOR` fitted to the panel (1.25 on 1280×800, nothing on
  1024×600, §2); `mkdir -p ~/.mixxx` before the Mixxx loop, without which a
  fresh unit never starts Mixxx: the shell opens the `2>>~/.mixxx/stderr.log`
  redirect before `mixxx` and fails on the missing directory.
- Not changed, worked around: `mixxx_config/ttymidi/Makefile`'s
  `install-remote` fails on a unit without the bridge unit yet — pass
  `SERVICE=` (§3.1). The fix belongs in the ttymidi submodule. The target has
  gone since, and the ttymidi step restarts the bridge only if it runs.
- `mixxx_config/mixxx.cfg` — `ReplayGainEnabled 0` (§3.6); the reason is in
  `mixxx_config/README.md`, since Mixxx rewrites `mixxx.cfg` and drops comments.
- Per-deck wiring (§3.4): `mixxx_config/units/trimixxx2.json` and
  `units/apply.py`; `mixxx_config/upload.sh` stages the mapping through it;
  `TriMixxx.scripts.js` gains the `// @unit-wiring` table, `ringLed()` /
  `ringLedPair()` address the physical node, and the hot-cue handler reads the
  canonical note; `pi_config/deck-poke`'s named verbs send what the deck's own
  S3 would. `mixxx_config/README.md` documents it, and its encoder row now says
  push over the deck is the FX mute. Later the same evening: `jogReversed` in
  the unit file, read by `TriMixxx.jog`; `TriMixxx.RING_LEVEL` (0.8, gamma
  corrected), the rings' overall brightness; and `"bezel"` in the unit file —
  `[TriMixxx],bezel` in `skin.xml` with open maximum heights, `apply.py` and
  `upload.sh` staging the skin, and in the `mixxx/` submodule
  `src/widget/deck/deckbezel.h` plus `WDeckBrowser`/`WDeckRack` reading it.
- Reaching the deck at a venue (§3.8): `pi_config/wifi-fallback/` (script,
  unit, installer, README), hooked into `pi_config/upload.sh`;
  `pi_config/trimixxx-debug` prints the fallback's decision; in the `mixxx/`
  submodule, `WDeckDiagnostics` gains the Network section.
- The rescue console's shell (§3.8): `pi_config/trimixxx-debug` opens `bash -i`
  instead of `bash --login`, which recursed without end, and `pi_config/bash_profile`
  stands down under `TRIMIXXX_RESCUE`.
- The touch rescue console (§3.8): `pi_config/rescue-session` and
  `pi_config/rescue-keyboard.xml`, `trimixxx-debug` trying them first, and
  `pi_config/upload.sh` installing them with their two packages; in
  `trimixxx-launcher`, the console map's pads at half brightness.

Since then, `pi-qemu` has replaced the scripts named here and in §3:

| Then | Now |
|---|---|
| `pi_config/upload.sh`, with `prolink-eth0.sh`, `splash-install.sh`, `wifi-fallback/install.sh` and `dj-usb/install.sh` | the system step, `pi-qemu/deploy/002_system.sh` |
| ttymidi's and the launcher's `make install-remote` | the ttymidi and launcher steps (`001`, `003`) |
| `mixxx/upload.sh` | the mixxx step (`004`) |
| `mixxx_config/upload.sh` | the config step (`005`) |
| `doom/install.sh` | the doom step (`007`) |
| `pi_config/deck-shot`, `deck-poke`, `deck-record` | `pi-qemu deck shot`; `deck tap`, `swipe`, `press`, `browse`, `midi`; `deck record` |

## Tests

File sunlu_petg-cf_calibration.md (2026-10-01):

# SUNLU PETG-CF Calibration on H2D

## Nozzle 0.4mm

temp: 250 to 255C. Pick 255C

27.26mm first defect --> max vol flow of 18.61 mm3/s

-10% safety max vol flow is `0.9*18.61 = 16.75` mm3/s

Flow Dynamics Calibration factor (K factor) is 0.023

Flow ratio calibration #1 --> 0.95
Flow ratio calibration #2 --> 0.95

## Nozzle 0.8mm

255C as well (not retested)

- First kinda defects at >8mm3/s flow, but even at 14mm3/s it was still very good, so I'm redoing a test up to 40mm3/s
- Second test, from 12 to 40mm3/s: even 40.7mm3/s is perfect.

Flow Dynamics Calibration factor (K factor) is 0.01

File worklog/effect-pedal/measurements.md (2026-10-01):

# Phase 0 measurements

> **The pedal bus these were taken for was removed on 2026-10-01.** The numbers
> are the deck's codec and the round trip through the Xone, and still hold for
> that hardware.

Everything measured on the deck itself, at the ALSA layer, so none of it depends
on Mixxx's config being right. Recorded 2026-08-11.

Reproduce any of these with:

```sh
arecord -D hw:0,0 -c2 -f S16_LE -r44100 -d10 /tmp/x.wav
```

and the analysis snippets below. All figures are dBFS relative to 16-bit full
scale; the card is a **TI PCM2902** (`08bb:2902`), fixed-gain ADC, no capture
volume control anywhere in ALSA.

## Rig

```
CDJ ──> Xone:92 CH n ──(AUX 2, PRE-fade)──> TriMixxx codec IN
TriMixxx codec OUT ──> Xone:92 CH m        (that channel's AUX 2 send at zero)
```

Both machines on the same mains. 50 Hz country.

## 1. Converter baseline — nothing connected

The control for everything below.

| | L | R |
|---|---|---|
| Peak | −78.3 dBFS | −78.3 dBFS |
| RMS | −90.7 dBFS | −90.7 dBFS |
| Non-zero samples | 59% | 59% |

−90.7 dBFS RMS is essentially the theoretical dither floor of a 16-bit
converter, so the ADC is working and clean rather than muted. This is the number
every later noise measurement is compared against.

## 2. Signal level — CDJ playing, AUX 2 send up

| | L | R |
|---|---|---|
| Peak | −15.2 dBFS | −15.3 dBFS |
| RMS | −26.1 dBFS | −26.2 dBFS |
| DC offset | −0.6 LSB | −0.6 LSB |

- **Crest factor 10.9 dB** — normal for a mastered club track.
- **Channel balance within 0.1 dB** — both legs of the cable are good.
- **DC offset is nil**, so the codec's input coupling is fine.
- **L/R correlation 0.603.** The discriminating number: a mono source duplicated
  to both channels would read 1.000 and a dead channel near 0. The Xone's aux
  bus is stereo end to end and nothing is collapsing it.

### Calibration, settled

Three positions of the same send pot, one CDJ playing:

| Send pot | Peak | RMS | Crest |
|---|---|---|---|
| Middle | −15.2 dBFS | −26.1 dBFS | 10.9 dB |
| Fully clockwise (+6 dB) | **−0.33 dBFS** | −8.9 dBFS | 8.6 dB |
| ~1 o'clock | **−12.8 dBFS** | −21.2 dBFS | 8.5 dB |

**Settled at ~1 o'clock, −12.8 dBFS peak.** Fully clockwise was 0.33 dB from
full scale — not clipping (zero samples at FS, no flat-topped runs) but with no
headroom whatsoever, and a track mastered a decibel louder would have clipped
into a converter that has no gain control to save it.

−12.8 dBFS looks conservative for one source and is not, because **the aux bus
sums**. Two channels sending at this level peak near −7 dBFS and four could
reach full scale in the worst case, so a single channel calibrated to −9 would
leave nothing for the rest of the bus. −12.8 still gives ~77 dB SNR against the
−89.6 dBFS floor.

The crest factor briefly looked like evidence that something in the analogue
path was squashing peaks — it fell from 10.9 to 8.6 dB as the level went up, and
the RMS rose further than the peak did. It was not: the figure stayed at 8.5 dB
after backing the send off by 12.4 dB, so it tracks the passage of music in the
10-second window and nothing else. **Nothing in the path is compressing.**

Note for future calibration: the **channel VU meter is no guide here**. It shows
the pre-fader channel signal, upstream of the send pot, so it does not move when
the send does. Meter the bus with the master section's **AUX 2 switch**, which
puts the aux on the monitor meters.

## 3. Hum — everything connected and powered, all sends off, decks paused

The realistic worst case for a ground loop: both cables in place, both machines
powered from the same mains, no signal to mask anything.

| | Unconnected (control) | Connected | Δ |
|---|---|---|---|
| Broadband RMS | −90.7 dBFS | −89.6 dBFS | **+1.1 dB** |
| Peak | −78.3 dBFS | −76.3 dBFS | +2.0 dB |
| 50 Hz | −104.6 dBFS | −102.2 dBFS | +2.4 dB |
| 100 Hz | −114.5 dBFS | −105.8 dBFS | **+8.7 dB** |
| 150 Hz | −113.8 dBFS | −115.3 dBFS | −1.5 dB |
| L/R correlation | +0.246 | +0.400 | +0.154 |

Harmonic levels are Goertzel magnitudes, peak-picked over ±0.6 Hz in 0.2 Hz
steps across four one-second windows — the sweep is there because mains drifts
either side of 50 Hz and a fixed bin would under-read it.

### Reading it

**There is a mains-coupled component, and it is negligible.**

It is real: connecting the cable raised 100 Hz by 8.7 dB, and the L/R
correlation went from 0.246 to 0.400, which is what a *common-mode* source added
to both channels looks like. Independent converter noise would not correlate.

That 100 Hz is the second harmonic, and it rose far more than the 50 Hz
fundamental — the signature of full-wave rectifier ripple coupling through a
ground path, rather than magnetic pickup from a transformer, which would be
dominated by 50 Hz instead.

But the absolute levels make it a non-issue:

- Worst affected bin, 100 Hz at −105.8 dBFS, is **16 dB below the broadband
  noise floor** and would sit ~98 dB under music peaking at −8 dBFS.
- The broadband floor rose by **1.1 dB**, so the connected system is within
  about a decibel of the converter's own noise.

For scale: if the noise floor were white, a single ~1 Hz analysis bin would read
around −133 dBFS (−89.6 minus 10·log₁₀(22050)). The 100 Hz reading sits ~27 dB
above that, so it is genuinely tonal rather than noise — it is simply a tone at
a level nothing will ever hear.

**Verdict: no action. Do not chase this.** Recorded so that if hum ever does
appear — a different venue, different mains, another device sharing the earth —
there is a number to compare against rather than a guess.

### Caveats

- CDJ was *paused*, not powered off. A CDJ's own supply could contribute more
  when transports are running.
- The monitoring amplifier's state during this capture was not controlled, and
  amps are a common ground-loop partner.
- Measured at one location on one mains supply. Ground loops are a property of
  the installation, not of the equipment, so this does not transfer to a club.

## 4. Round-trip latency — 32 ms

Measured with `alsabat --roundtriplatency`, which opens playback and capture
together so the two streams share a clock — the part that makes this hard to do
with separate `aplay`/`arecord` processes. Buffer and period set to match
Mixxx's own (`-B 512 -E 256`, i.e. `latency="3"` = 256 frames) so the figure
reflects the deck's real configuration:

```sh
sudo systemctl stop getty@tty1.service
alsabat -D hw:0,0 -f S16_LE -c 2 -r 44100 -B 512 -E 256 --roundtriplatency
sudo systemctl restart getty@tty1.service
```

Path: TriMixxx codec out → Xone CH m → AUX 2 → TriMixxx codec in, with the CDJ's
send off so the bus carried only the deck. Safe to close that loop for this test
because alsabat never replays what it captures.

| Run | Result |
|---|---|
| 1 | 32 ms |
| 2 | 33 ms |
| 3 | 32 ms |

Individual probes within each run alternated between 28 ms and 34 ms. That ±3 ms
spread is one period (256 frames = 5.8 ms) of quantisation — it depends where
the impulse lands inside a buffer — so the honest figure is **32 ms ± 3**, or
about 1400 frames at 44.1 kHz.

### Where it goes, and why the 20 ms estimate was wrong

The estimate counted one buffer each way. The measurement says both directions
cost a full buffer, not a period: 512 frames out (11.6 ms) plus 512 frames in
(11.6 ms) is already 23 ms, and USB full-speed transfer plus the PCM2902's
converter group delays plus alsabat's own onset-detection bias account for the
rest. **The device is USB 1.1 full speed**, which sets a floor that no config
change reaches.

### What 32 ms changes

- **Reverb: nothing.** 32 ms reads as pre-delay, and a pre-delay that long is a
  deliberate choice in a studio, not a defect. Arguably flattering for dub-techno
  space.
- **Comb filtering is worse than estimated.** Notch spacing is `1/τ` = **31 Hz**,
  not the 50 Hz that 20 ms implied — denser and more audibly hollow. This is
  about transformative effects only (crush, filter, distortion, pitch), whose
  output stays correlated with the dry. Reverb and echo decorrelate and are
  immune.
- **Delay compensation gets harder, and has a floor.** At 128 BPM a beat is
  469 ms, so 32 ms is 6.8% of a beat — plainly audible as a late delay. Phase 4
  must subtract it. But a 1/16 note at that tempo is 29 ms, *shorter than the
  latency itself*, so short delay divisions cannot be compensated by subtraction
  at all; they would have to wrap to the following beat.

### Worth revisiting later, not now

- `latency="3"` → `2` would halve Mixxx's share (~6 ms) and, per the note in
  `mixxx_config/upload.sh`, would also cut jog-bend smear since that filter's 25
  taps are buffers rather than milliseconds. Costs xrun headroom on USB audio.
- This is alsabat's latency at Mixxx's buffer settings, not Mixxx's own. The
  definitive measurement is available once the aux input is live: close the loop
  at low gain so Mixxx regenerates, and the spacing between successive echoes in
  a capture *is* the round trip, with no synchronisation needed.

## Still outstanding
- **Sustained duplex** — 20 minutes, watching the header's underrun counter.
- **Thermals under load.** 71 °C at idle in a closed chassis, throttling around
  80–85 °C. Heat is the constraint here, not CPU, which sits at 18% of one core.

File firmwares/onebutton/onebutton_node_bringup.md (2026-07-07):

# OneButton Node Bring-Up — CH32V003 first light, Pro Micro flashing, and the all-white WS2812 saga

Validation log for a single **OneButton** ring node: a pre-assembled CH32V003F4P6
board carrying two WS2812 LEDs (data on **PC0**) and one button (**PC1**), destined
to be one of ~50 nodes in a UART cut-through ring for the TriMixxx CDJ project.

This entry covers proving **one** board end-to-end — before any ring, any second
node, or the real protocol. The goal was to remove every single-board unknown so
that the first two-board ring test only has to debug the *protocol*, not the
hardware or the LED timing.

---

## What was validated

| Item | Result | How |
|---|---|---|
| Board accepts a flash | ✅ | Full write cycle over SWIO; proves the SWIO pad, MCU solder joints, and the whole programmer chain |
| Both WS2812 LEDs light | ✅ | Colour cycle test; LED1 lighting proves data passes *through* LED0 down the chain |
| Individual addressing | ✅ | LED0 and LED1 shown different colours simultaneously |
| GRB colour order | ✅ | Red/green/blue render as intended after the RGB→GRB reorder in `ws2812_send` |
| Per-LED brightness | ✅ | Dim-grey phase (0x08) renders dim, not off, not full |
| Button reads | ✅ | PC1 as floating input; external 10k + 100nF + the pin's Schmitt trigger debounce in hardware |
| WS2812 bit timing centred | ✅ | Swept the timing to find the working window, sat in it with margin |
| Timing thermally robust | ✅ | Held glitch-free at **150 °C for 1 minute** on the mostly-zeros pattern |
| printf-over-SWIO debug link | ✅ | Works through the Pro Micro / Ardulink programmer — became the key debug tool |

**Bottom line:** the entire single-node signal chain is proven on real hardware.
The final tuned WS2812 constant is `WS0_HIGH = 8`.

---

## Setup

- **Target:** CH32V003F4P6 (48 MHz QingKe RV32EC, 16 KB flash, 2 KB RAM), whole
  ring runs at **5 V**. The '003's GPIO is 5 V-tolerant, so no level shifting on
  the SWIO or LED lines.
- **Firmware framework:** ch32fun (bare-metal, no HAL).
- **Toolchain (macOS):** `riscv-none-elf-gcc` (xPack), `libusb` (Homebrew), and
  `minichlink` built from the ch32fun repo. Firmware builds to a raw `.bin` —
  minichlink flashes `.bin`, **not** elf/hex.
- **Programmer:** no WCH-LinkE on hand yet, so an **Arduino Pro Micro** was used
  as a SWIO programmer via ch32fun's **Ardulink** backend (see struggles below).
- **Flash command:**
  ```
  minichlink -c /dev/cu.usbmodemXXXX -w firmware.bin flash -b
  ```
- **Debug channel:** `minichlink -c /dev/cu.usbmodemXXXX -T` — printf-over-SWIO,
  which (verified in the minichlink source) rides on the generic register
  read/write that Ardulink implements, so it works through the Pro Micro.

---

## Struggles (the actual story)

### 1. Flashing with a Pro Micro instead of a WCH-LinkE

The WCH-LinkE was ordered but not yet delivered, so the Pro Micro filled in. This
was not plug-and-play:

- The Ardulink **firmware** isn't in ch32fun — it lives in a separate repo
  (`gitlab.com/BlueSyncLine/arduino-ch32v003-swio`), and it's written for an
  Arduino **Uno** (ATmega328P). `ardulink.c` in ch32fun is only the *host* side.
- On the Uno, SWIO is hardcoded to **PB0**, which happens to be pin D8. But on
  the Pro Micro (ATmega32U4), **PB0 is the RX-LED / SS pin and isn't broken out**
  to a header — so the stock firmware can't drive it.
- The fix (a Pro Micro fork) changed several things:
  - SWIO moved **PB0 → PB4** (Pro Micro pin 8).
  - Host protocol moved onto **USB CDC serial** (the 32U4 has native USB) instead
    of the hardware USART.
  - **Power-control instead of reset-control**: the 32U4 doesn't auto-reset on
    DTR the way the Uno does, so the target is power-cycled via a GPIO (PB5/pin 9)
    rather than a DTR-driven RESET line.
  - It also fixed a **real latent bug** in `swio.c`: `DDR &= ~SWIO_BIT` should be
    `DDR &= ~_BV(SWIO_BIT)`. On the Uno's bit 0 this was harmless by accident; on
    any non-zero bit (like PB4) the original would have cleared the wrong pin and
    never released the line. This bug fix is *why* flashing is reliable.
- A **1 kΩ series resistor** on the SWIO line was needed for stability (a known
  Ardulink gotcha).
- **Power:** flash the board from a real 5 V rail, **not** the programmer's GPIO
  power pin — two WS2812s at full white draw ~120 mA, well over a GPIO's ~20 mA.

A successful flash was the first real win: it proves the SWIO pad, the MCU's hand
solder joints, and the entire Pro-Micro→minichlink chain all work.

### 2. The lone board "does nothing"

The **ring firmware** (`onebutton_node.c`) waits for UART frames and relays them,
so on a single board with nothing driving the ring it looks completely dead — no
LED activity. That's expected, not a fault. To make progress on a single board, a
standalone **self-test** was written (LED colour cycle + button), independent of
the ring.

### 3. All-white LEDs, and a button that "did nothing"

The self-test came up showing **constant full white** on both LEDs, and the button
appeared to do nothing. Two hypotheses:

1. **Timing** — the WS2812 bit timing is wrong (zeros read as ones).
2. **Data** — the code is actually sending 0xFF everywhere (a logic bug).

These need completely different fixes, so guessing would waste time.

**printf-over-SWIO settled it.** First, a button-only printf firmware confirmed the
button reads fine on its own — clearing it as a suspect entirely. Then the
self-test was instrumented to print the exact bytes it shifts out. The printout
showed **correct data** (`00 FF 00` for red, `08 08 08` for dim, etc.) while the
LEDs were still white. Correct data + white LEDs = **purely a timing problem**:
the "0" bits were being read as "1".

That single fact also explained the "dead" button: pressing sends magenta
(`FF 00 FF`), which differs from white only in the *green* channel being 0 — so
with zeros-read-as-ones, magenta rendered as white too. The press *was*
registering; white-to-white just isn't visible. **One root cause, both symptoms.**

### 4. The delay loop was lying — optimization-dependent timing

The original bit-timing delay was a C loop (`while (n--) nop;`). Under the build's
`-Os -flto`, the compiler is free to reshape or unroll that loop, so the actual
pulse widths bore **no relation** to the intended counts. Sub-microsecond bit-bang
delays cannot be done with a loop the optimizer is allowed to touch.

Fix, in two steps:
1. Replaced it with a **hand-written asm delay** (deterministic across builds).
2. Then with an **`.rept` nop-sled** for single-cycle (~21 ns) resolution:
   ```c
   #define NOPS_(n) __asm__ volatile (".rept " #n "\n\t nop\n\t .endr\n\t")
   #define NOPS(n)  NOPS_(n)
   ```
   The assembler's `.rept` emits exactly *n* nops at *assembly* time, so `-Os`/
   `-flto` can't retime it, and each step is one CPU cycle.

### 5. Coarse resolution → couldn't centre

With the loop, each iteration was ~3–4 cycles (~65–85 ns), but the WS2812 "0"
tolerance window is only ~150 ns wide — so a single step was nearly the whole
window. Only **two** loop values worked (`1` and `2`), both hugging the edge; there
was no reachable middle.

The nop-sled's 1-cycle steps fixed that. Sweeping `WS0_HIGH`:

- **0 … 16 → clean colour.**
- **17 → white** (the "0" crosses into being read as a "1").
- Going below 0 was impossible (0 is the floor), and 0 still worked — because
  `NOPS(0)` still leaves the pin high for the ~40–60 ns it takes the *next*
  instruction (the store that pulls it low) to run. So the low edge was never
  reached; there's enormous margin on that side.

### 6. Tuning to the safe middle (which isn't the geometric middle)

The window is **asymmetric**: the only reachable failure is the **high cliff at 17**.
And the enemy is **RC-oscillator drift** — the '003's internal oscillator slows as
it warms, which *lengthens* every pulse, pushing the effective value *up* toward
that cliff. So the right place to sit is **well below 17**, not at the midpoint of
`[0, 16]`.

Chosen: **`WS0_HIGH = 8`** — ~9 steps (~190 ns) of headroom under the cliff, while
still a clearly-long-enough "0". `WS1_HIGH` was kept generous at 30; a "1" only
fails by being too *short* (LEDs go dark) and has a huge window up to the ~50 µs
latch gap, so it needs no trimming.

### 7. Heat test — proving the margin

With `WS0_HIGH = 8` on the mostly-zeros pattern (the case nearest the cliff), the
chip was held at **150 °C for one minute** — no glitches, no stray white pixels.
That decisively proves thermal margin: 150 °C is far beyond the enclosure's
expected 40–60 °C, and it's near the chip's absolute-max junction temperature, so
it was a hard stress. Chip-to-chip RC spread across the 50 boards is expected to be
smaller than that thermal swing, so `WS0_HIGH = 8` should absorb part-to-part
variation without per-board tuning.

---

## Key learnings (transferable)

- **Never time a bit-bang with a C loop under `-O`/`-flto`.** The optimizer will
  reshape it and the timing becomes meaningless. Use an `.rept` nop-sled — it's
  resolved at assembly time, immune to the optimizer, and gives 1-cycle resolution.
- **printf-over-SWIO is the debugging keystone.** Printing the exact bytes on the
  wire instantly separated "data wrong" from "timing wrong" and pointed straight
  at the real cause. It works through the Ardulink/Pro-Micro programmer, no
  WCH-LinkE needed.
- **Tune to margin, not to "it works."** Characterise the full window, find which
  edge can actually bite (here: only the high cliff, worsened by thermal drift),
  and sit far from it — not at the geometric middle of a lopsided window.
- **One symptom, one cause.** "All white" *and* "button dead" turned out to be a
  single timing bug (magenta differs from white only in a zero channel). Look for
  the unifying cause before debugging two things.
- **Prove one board before scaling.** The standalone self-test isolated single-node
  behaviour (LEDs, button, timing) from all ring/protocol complexity, so the timing
  was nailed with nothing else in the way.
- **Ardulink on a Pro Micro needs work:** the stock firmware is Uno-only. The
  32U4 needs SWIO on PB4, USB-CDC transport, power-control instead of DTR-reset,
  and a 1 kΩ series resistor on SWIO.

---

## Final validated timing

```c
#define WS0_HIGH  8    // "0" high  -- window 0..16, cliff at 17, sit at 8 (150 C ok)
#define WS1_HIGH  30   // "1" high  -- wide margin, kept generous
#define WS0_LOW   24   // low times are non-critical
#define WS1_LOW   18

#define NOPS_(n) __asm__ volatile (".rept " #n "\n\t nop\n\t .endr\n\t")
#define NOPS(n)  NOPS_(n)
```

These constants, the `NOPS` macro, and `ws2812_send` are now ported verbatim into
`onebutton_node.c`. The **one** difference in the ring firmware: the send runs with
interrupts masked (`irq_off()/irq_on()` in `main`), because the cut-through relay
ISR is live and an interrupt mid-send would stretch a pulse. The pulse timing
itself is identical.

---

## What's next

1. **(done)** Port the validated timing into `onebutton_node.c`, keeping the
   interrupt-masking around the send.
2. **Flash two nodes** with the ring firmware.
3. **Chain them** and drive the ring with the USB-serial adapter as a stand-in
   master — send an ENUM frame, then a DATA frame.
4. **Watch the first relay hop** on the logic analyzer.

That two-board test is where the actual protocol — cut-through relay, positional
enumeration, and the circulating summation frame — finally gets exercised. The
hard, instrument-free part (proving the board and nailing the WS2812 timing by
eye) is now behind us.

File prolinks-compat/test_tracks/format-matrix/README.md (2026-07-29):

# Format coverage matrix

40 renderings of one source track — `6 SENSE - Mechanical Mania.mp3`, 7:05,
48 kHz stereo — spanning every audio format a CDJ-2000NXS claims to support.

**Each file's title tag and filename are its format**, so a track can be
identified from the deck's display alone. That is the point: two metadata
fields are still unattributed (`docs/FINDINGS.md` F31, F32) and reading them
requires knowing which file produced them.

Artist is `FORMAT TEST` on all 40 so they group together when browsing.

| Family | Variants | Rates |
|---|---|---|
| MP3 MPEG-1 | 32, 64, 128, 192, 256, 320 kbps | 44.1, 48 kHz |
| MP3 MPEG-2 | 16, 32, 64, 96, 128, 160 kbps | 22.05, 24 kHz |
| AAC (`.m4a`) | 16k/8k mono → 320k/44.1k stereo | 8–44.1 kHz |
| WAV | 16-bit, 24-bit | 44.1, 48 kHz |
| AIFF | 16-bit, 24-bit | 44.1, 48 kHz |

**MPEG-2 is at 22.05/24 kHz, not 44.1/48.** Layer III's 16–160 kbps range only
exists in the low-sampling-frequency extension; 44.1 and 48 kHz are MPEG-1 by
definition, so a "MPEG-2 at 48 kHz" file cannot be made.

AIFF needs `-write_id3v2 1`. Without it ffmpeg writes only AIFF's native
NAME/ANNO chunks, which carry the title but drop artist, BPM and key — the
files would then analyse differently from every other row purely because of the
container.

Regenerate with `tools/make-format-matrix.sh`. 1.0 GB total; the four 24-bit
lossless files are ~120 MB each.

## What to look for once rekordbox has analysed these

1. **`GET_TRACK_INFO` item 6, type `0x2f`** — carried `1` for the one MP3 we
   have ever seen. If it is a codec identifier it should differ across MP3 /
   AAC / WAV / AIFF. This is the field that most plausibly drives the
   "CDJ DOES NOT DECODE THIS FORMAT" message (F31).
2. **`GET_TRACK_INFO` item 1, type `0x04`** — also `1`, and `disc_number` was
   the only field of that track equal to 1. Every file here is disc 1, so this
   matrix cannot settle it; a track tagged disc 2 would.
3. **`PVBR`** — our `GET_VBR_INDEX` reply serves this tag, and it gates
   playback. Does rekordbox write it for CBR MP3? For AAC? For WAV and AIFF,
   which have no bitrate variation at all? If it is absent, we serve an empty
   blob and playback may fail for those formats.
4. **The metadata `bitrate` item (`0x10`)** — what does it report for 24-bit
   lossless?

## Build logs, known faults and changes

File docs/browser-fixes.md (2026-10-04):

# The Browser — fixing what the first run found

Against [`browser-status.md`](browser-status.md), from testing on the deck. Nine
items: four are bugs with a diagnosed root cause, three are missing behaviour,
two are new requirements.

Ordered by what hurts most.

---

## 1. Reading a stick takes 15 seconds and freezes the GUI

**Two causes, one fix for both.**

### The ingest never opens a transaction

`pdbingest.cpp` contains no `ScopedTransaction` — grep says zero. So SQLite
runs **every INSERT as its own transaction**: 651 tracks, plus a playlist row
each, plus one entry per playlist membership, is well over a thousand
autocommits. Each one is a journal write and an fsync to the SD card, at
roughly 10–20 ms. That is the 15 seconds, almost exactly.

Upstream's Rekordbox feature wrapped its writes in a `ScopedTransaction`; my
rewrite dropped it.

### And that is also the freeze

The database is in **rollback-journal mode** — nothing in the tree sets
`journal_mode=WAL`. In that mode a writer takes an exclusive lock and **readers
block**. A thousand short write transactions on a pooled thread means the GUI
thread's own queries — the counts on the medium menu, the model's `select()` —
are locked out over and over for the whole 15 seconds. The work is off the GUI
thread; the *lock contention* is not.

**Fix**

1. Wrap the whole of `writeMedium()` in one `ScopedTransaction`, committed at
   the end. This is the entire fix for the slowness: one transaction, one fsync.
2. Prepare the three statements once and rebind per row — already done for
   tracks, not for the per-playlist cover query in `playlistsIn()`.
3. Then measure again. If the GUI still stutters, enable
   `PRAGMA journal_mode=WAL` on the collection database, which lets readers
   carry on while the writer works. Worth doing on its own merits for a deck
   that reads a stick mid-set, but do it **second**, so the transaction fix is
   measured on its own.

**Verify:** time from insert to `Ready` in the log (`DeckIngest - wrote N
tracks`), expect well under a second for 651 tracks; and scroll the source list
while a second stick reads.

---

## 2. Sorting by Key produces nonsense (11A → 6A → 1A)

**Root cause.** The sort menu's `Key` field sorts on the `key_id` column, and
`key_id` is Mixxx's `ChromaticKey` enum — **chromatic order** (C, C♯, D, …), not
Camelot order. 11A → 6A → 1A is exactly what chromatic order looks like when
read as Camelot.

The *category* list is right, because `keyCategory()` sorts in C++ through
`camelotOrder()`. Only the track-model sort is wrong, because SQL has no idea
what a Camelot wheel is.

**Fix**

1. Move `camelotNumber()` / `camelotOrder()` out of `deckqueries.cpp`'s
   anonymous namespace into a shared `camelot.h`.
2. Add **`camelot_order INTEGER`** to `deck_library` and populate it at ingest
   from the same function. One integer per track, computed once.
3. Point the sort menu's `Key` field at `camelot_order`.
4. **The sorted column and the displayed column now differ for Key** — the info
   layout must show the `key` *text* beside each title, not the order number. So
   `WDeckSortMenu::Field` needs a `displayColumn` alongside `column`, defaulting
   to the same thing and differing only here.

**Verify:** sort by Key and read down the list — 1A, 1B, 2A … 12B. Cross-check
against the Key category list, which was already right.

---

## 3. The info panel never appears

**Not a bug — it was never built.** `browser-status.md` §3 lists it as absent.
Long-pressing SORT toggles the *row layout* to one line, which is only half of
§8.2; the panel on the right does not exist, so the visible effect is that the
artist disappears.

**Fix — build it.**

1. `WDeckInfoPanel`, 464 px on the right, shown only in info layout: artwork,
   then Artist, Album, Year, Duration, Genre, Key, Rating, Date added, Last
   played, Comment.
2. The list narrows to 560 px beside it.
3. **Any field that is the current sort key is omitted from the panel**, because
   it is already beside every title on the left.
4. Fields with no value are omitted entirely rather than shown blank.
5. It follows the selection: `DeckListView::selectionMoved` → repopulate. That
   signal already exists and is currently connected to an empty slot.

While in there, make the toggle unambiguous: it should be obvious at a glance
that the layout changed even before the panel is populated.

---

## 4. BPM buckets do not re-bucket live when the tempo range changes

**Root cause.** Nothing watches `rateRange`. The buckets are computed in
`showCategory()` and only recomputed when the level is rebuilt — which is why
leaving and re-entering works.

**Fix.** A `ControlProxy` on `[Channel1],rateRange` in `WDeckBrowser`; on
change, if the current level is the BPM category, rebuild it in place, keeping
the selection on the bucket containing the previously selected centre.

**Verify:** open BPM, press ring A1 through ±6 / ±10 / ±16 / WIDE, watch the
ranges widen without the menu closing.

---

## 5. Key colouring does not follow the loaded track

**Root cause.** `setPlayingKeyId()` is called once, from
`refreshTrackColumns()`, i.e. only when the model changes. Loading a track does
not touch it.

**Fix.** A `ControlProxy` on `[Channel1],key`; on change, update the delegate
and call `viewport()->update()` — no model rebuild, no menu redraw. Watch
`track_loaded` too, so unloading clears the reference and the colouring goes
away rather than lingering on the old key.

## 6. A matching key should be bold as well as green

**Fix.** In `TrackRowDelegate::paint()`, when `key::isCompatible()` is true, set
a bold font for the key text as well as the green pen. Restore the font
afterwards — the painter is shared with the rest of the row.

Worth pairing with 5: both are one-line changes in the same function, and both
are verified the same way.

---

## 7. Long-pressing BACK should leave the browser without unwinding it

**The requirement.** A short BACK pops one level. A **long** BACK returns to the
deck view *from wherever you are*, and re-opening the browser puts you back in
the same menu.

**Fix — in the mapping, not in C++.** `TriMixxx.scripts.js` already has the
short/long discrimination for SORT; `TriMixxx.back` gets the same timer.

- short → `[Browser],back` as now
- long → `[Master],show_library = 0`, and nothing else

No new control is needed, and the navigation stack survives untouched because
nothing tells it to unwind — the widget is simply hidden.

**One thing to check:** that the browser redraws correctly when it becomes
visible again. The stack is intact, but nothing currently runs on show, so if
the view needs a repaint or a re-select it will have to be added.

---

## 8. The breadcrumb should be clickable, and lead with a Home icon

**The requirement.** `⌂ › SAM2 › Artists › 999999999`, where each segment jumps
back to that level, and the root is an icon rather than the word SOURCES.

**Fix.** The breadcrumb is already a `QLabel`; make it rich text with one link
per level:

```
<a href="0">⌂</a> › <a href="1">SAM2</a> › <a href="2">Artists</a> › …
```

with `setTextFormat(Qt::RichText)`, `setOpenExternalLinks(false)`, and
`linkActivated` → pop the stack down to that index and rebuild. The href is the
level index, so no name matching is involved.

- The home glyph comes from the Nerd Font the skin already uses (``),
  which avoids shipping an icon for one character.
- Link colour has to be set in the HTML, because a stylesheet does not reach
  rich-text anchors.
- The current sort indicator stays where it is, right-aligned, and stays
  clickable — it already opens the sort menu.

**Touch target:** a link the height of a text line is small for a fingertip. The
breadcrumb bar is 48 px, so pad the anchors to fill it rather than leaving 20 px
of hit area in the middle.

## 9. Show the slot number beside the medium mark

**The requirement.** Which physical port a stick is in, so the wrong one does
not get yanked. Right now SAM2 is in slot 1 and SAM1 in slot 2 — exactly the
confusion this prevents.

**Fix.**

1. `MediumInfo` gains `int slot`, parsed from the mount point (`DJ_USB_1` → 1).
   Local media only; remote media have a player number instead, which the row
   already draws.
2. `MenuRow` gains the same, and `MenuRowDelegate` draws it immediately after
   the mark, before the name: `▊1  SAM2`.
3. Keep it visually distinct from a Pro DJ Link player number, since the two
   sit in the same place and mean different things — one is a port on this deck,
   the other is a device on the network. Dim for the slot, full brightness for
   the player number, or a different weight.

---

## Order of work

1. **The transaction** (§1) — biggest win, smallest change, and it makes
   everything else pleasanter to test.
2. **Camelot sort column** (§2) — schema change, so it wants to land with the
   ingest change rather than after it.
3. **Key colour live + bold** (§5, §6) — same function, minutes.
4. **BPM live re-bucket** (§4) — one ControlProxy.
5. **Long BACK** (§7) — script only, no rebuild.
6. **Slot number** (§9) — small, and it removes a real hazard.
7. **Breadcrumb links + Home** (§8).
8. **The info panel** (§3) — the largest piece, and the only one that is a
   feature rather than a fix.

§1 and §2 both touch the schema and the ingest, so build them together and
re-read both sticks once.

---

## Status — all nine implemented, none tested on hardware

Written blind: it compiles, it is deployed to neither deck nor eye. What to
check, in the order most likely to catch a mistake:

| # | Change | How to know it worked |
|---|---|---|
| 1 | One transaction around the ingest | A stick should read in **well under a second**, and the source list should stay scrollable while the second one reads. Watch for `DeckIngest - wrote N tracks` in `/tmp/mixxx/mixxx.log`. |
| 2 | `camelot_order` column, Key sorts on it | Sort by Key: 1A, 1B, 2A … 12B. **This is a schema change, so both sticks must be re-read** — they are, on every boot. |
| 3 | The info panel | Long-press SORT, or tap an already-selected track. Panel on the right, following the selection as you turn the encoder. |
| 4 | BPM re-buckets live | Open BPM, press ring A1. Ranges should widen without the menu closing. |
| 5 | Key colour follows the deck | Load a track, then browse: compatible keys go green **without** re-entering the list. |
| 6 | Matching keys bold | Same test as 5. |
| 7 | Long-press BACK | Hold BACK anywhere: straight to the waveform. Press BACK again: back in the *same* menu, not at SOURCES. |
| 8 | Clickable breadcrumb, home glyph | Tap any segment to jump back to it. The root is a house. **If the house renders as a box, the Nerd Font is not resolving that codepoint** — swap `` for a word. |
| 9 | Slot number beside the mark | `1` beside SAM2 and `2` beside SAM1, dimmer than the name. |

### Most likely to be wrong, since none of it was run

- **The breadcrumb link hit area.** Anchors are padded with `&nbsp;`, which is
  a guess at a fingertip. If segments are hard to hit, the label wants replacing
  with a widget that hit-tests properly.
- **The info panel's width against the list.** 464 + 560 = 1024 exactly, so the
  list has no margin for error; if titles look cramped, take it off the panel.
- **Last played** is now real and completely untested. The medium's half comes
  from its rekordbox history playlists (bridged through `lib/prolink`, written
  to `deck_history`); ours comes from a play logged when the loaded track passes
  half way. Check the log line `DeckIngest - wrote … N history entries`: a
  well-travelled stick should contribute far more entries than it has tracks,
  and a stick that has only ever been in a laptop will contribute **zero**,
  which is correct and looks identical to a bug.
- **The house glyph** (see 8).

### Not touched, still absent

Toasts, diagnostics, the track cache, the hover-only menu bar, and anything
ProLink. The cache remains the one omission with a live failure mode: pulling a
stick mid-track will still stop it after about fifteen seconds.

### On WAL — done, and why

Landed as its own commit, after the transaction fix, so the two are
attributable separately.

**It is not a card-wear measure**, and an earlier draft of this document said
otherwise. Both journal modes write the data twice — rollback copies the
original pages aside then writes the new ones, WAL appends to the log then
copies it into the database at the next checkpoint. A 651-track stick is about
half a megabyte of rows either way, so roughly a megabyte of card writes per
read. Twenty stick swaps a night is ~20 MB: a rounding error beside the
journald traffic `log2ram` already exists to absorb. Wear is not the axis this
turns on.

What it buys is the last of the interface hitch. One transaction took the block
from fifteen seconds to a fraction of one; WAL takes it to nothing, which
matters because plugging a stick in is exactly when you are also scrolling.

Two things to know: the mode lives in the **database file header**, so it
survives the line being deleted and reverting needs an explicit
`PRAGMA journal_mode = DELETE`; and it applies to Mixxx's whole collection
database, not just the browse tables.

**Considered and rejected:** a second database on tmpfs for the deck's tables,
ATTACHed. Zero card writes, no locks shared with Mixxx's library — but it buys
that with a second schema, a second connection lifetime, and schema-qualified
names threaded through `BaseSqlTableModel` and `BaseTrackCache`. One database
is the simpler thing; the megabyte per stick is not worth the machinery.

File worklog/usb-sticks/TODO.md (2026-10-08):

# USB sticks — open items

What is left from debugging the friends' sticks from the 2026-10-04 gig
(copies on BIGBOY2, `/Volumes/BIGBOY2/TriMixxx-USB-dumps`). Fixed so far: a
load no longer freezes the deck, only the loaded track is copied (no hover
pre-copy), the copy shares the stick with CDJs, and a streamed WAV/AIFF opens
without reading its end (fork `1e9bb12`, `d6960af`, `f61bcc8`).

Reproduce anything here on an emulated deck with the stick at a real stick's
speed: `pi-qemu deck stick NAME insert SANDISK-E02C`, then
`pi-qemu deck stick NAME speed SANDISK-E02C 4M` (a cheap USB 2 stick reads 3 to
5 MB/s), and `pi-qemu deck stick NAME reads SANDISK-E02C` for what the Pi read,
file by file.

## 1. The Pro DJ Link server reads every folder on a stick when it goes in

`Vfs::mount` (`mixxx/lib/prolink/crates/prolink/src/serve/vfs.rs`, called from
`graft()` in `serve/player.rs`) lists every directory and stats every file of
a new medium before it is served, to build the NFS tree. On the SanDisk copy
(1049 tracks, 2149 folders) that read 72 MB, almost all of it directory
clusters, and took ~30 s at 4 MB/s, ~48 s at 2 MB/s. A rekordbox stick has a
folder per track under `PIONEER/USBANLZ` plus `Contents/Artist/Album`, so it
grows with the library: about 70 MB per 1000 tracks. Meanwhile the stick is
saturated, right when a DJ starts browsing and loading, and "mounted a medium"
(when CDJs can see the stick) comes only at the end.

- **Fix:** a lazy tree. List a directory the first time a player looks into
  it (`LOOKUP` or `READDIR` on its handle). A CDJ only ever walks the paths the
  pdb gives it, so only those folders get read.
- **Watch for:** handles are hashes of paths, cut to 12 bytes by a CDJ (F28);
  the NFC/case-insensitive fallback in `lookup`; `preserve()` for a phantom
  medium; and the `files=` count in the mount log, which a lazy tree no longer
  knows up front.
- **Done when:** `stick reads` right after an insert shows no folder walk, and
  a CDJ (or a second emulated deck on the link) still browses and plays off it.

## 2. Three SoundSourceProxy tests fail in the test container

`mixxx-test` in the `unittest` Docker stage fails
`SoundSourceProxyTest.firstSoundTest`, `.freeModeGarbage` and
`.taglibStringToEnumFileType`, with or without the stick changes (checked by
reverting `f61bcc8`). They look like library versions in the container
(Debian trixie, FFmpeg 7.1.5), not deck code:

- `firstSoundTest`: the first audible frame of the M4A test files is off by
  two (1168, expected 1166).
- `freeModeGarbage`: `free_mode_garbage.mp3` will not open at all.
- `taglibStringToEnumFileType`: TagLib reports a file type Mixxx has no enum for.

- **Do:** check each against the library versions (upstream Mixxx's CI pins
  others), then fix the expectation, or skip the test in this build with the
  reason.
- **Done when:** `docker buildx build --target unittest --build-arg
  GTEST_FILTER='SoundSource*' ...` in `mixxx/` passes.

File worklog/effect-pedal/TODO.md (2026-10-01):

# Effect pedal — implementation order

> **Removed 2026-10-01.** The pedal bus and the rack it grew into are gone:
> the fork, the skin, the mapping and the config are back to how they were
> before it, and `docs/effects-prd.md` went with it. This page stays for what it
> recorded on the way — the shutdown crash, the TrackCache bisect and the
> "techno night" playlists are not about effects, and still stand.

Turning TriMixxx into the effects unit on the Xone:92's AUX 1 send/return, so
that the CDJs' audio can be reverbed/delayed/crushed by the deck and returned
**wet only** — no dry, no level jump, one hand.

Wiring, mixer behaviour and why wet-only is non-negotiable:
`docs/xone92-send-return.md`.

Ordered from *most fundamental* to *most uncertain*. Each phase is a place where
the thing can be left working and put down. Don't start a phase before the one
above it is verified on the deck rather than on the laptop.

## Where this is

| Phase | State | |
|---|---|---|
| 0 · Hardware path | **done** | PCM2902 does full duplex at 44.1 k. 32 ms round trip, −12.8 dBFS in, no hum. Two soak tests outstanding. |
| 1 · Aux reaches the mix | **done** | |
| 2 · `WetOnly` mix mode | **done** | Plus six slots, per-slot wet, and the `kNumModes` leak fixed |
| 3 · A unit on the aux | **done** | Wet-only reverb on the CDJs, surviving a reboot |
| 4 · Beat sync | **done** | Oldest playing deck wins. Latency compensation not attempted |
| 5 · The rack | **built, and tested once** | Superseded by `docs/effects-prd.md`; the test run's list is Phase 8 |
| 6 · LV2 host | not started | Survey first — it decides whether the rest is worth doing |
| 7 · Polish | not started | |
| **8 · The test run's list** | **done bar one** | Only §15.1, the deck into the send bus, is left |
| **9 · The second test run's list** | **done** | §17.1–17.4; 17.3 was a closed filter, not the master |
| 10 · The FX strip (§16) | **done** | Built and verified; focus has no timeout |

**Next action:** a test run. Every PRD item is now built. Everything below is on the deck and verified as far
as it can be without ears — the two things that need a listener are the master
rocker (does RING OUT actually ring out?) and the delay divisions at tempo.

After that, the two remaining PRD items in order: **§15.1**, the deck's own
audio into the send bus with an INPUT module, then **§16**, the FX strip on the
deck view. §16 was blocked on metering and the mute-mode toggle; both now
exist.

---

## Phase 0 — Prove the hardware path (no code)

**Software half: done, and it passes.** Measured on the deck 2026-08-11 with
Mixxx running.

The codec is a **TI PCM2902** (`08bb:2902`, "Burr-Brown from TI USB Audio
CODEC", full-speed USB, card 0). Findings:

- [x] **Stereo capture at 44.1 kHz exists** — `/proc/asound/card0/stream0`,
      Interface 2 Altset 3: `S16_LE`, 2 channels, 44100 Hz. Capture is a
      separate USB interface and endpoint (`0x84 IN`) from playback
      (`0x02 OUT`), so the two directions are independent.
- [x] **Full duplex confirmed.** `arecord -D hw:0,0 -c2 -f S16_LE -r44100 -d5`
      opened and ran to completion *while Mixxx held the playback stream*.
      Exit 0, file exactly 220500 frames = 5.000 s. No rate mismatch, no
      dropped frames. **This was risk #1 and it is cleared.**
- [x] **The ADC is alive and clean.** Nothing connected: noise floor
      −90.7 dBFS RMS, peak −78.3 dBFS, ~59% of samples non-zero. That is a real
      dither floor at the 16-bit theoretical limit, not a muted input.
      **Keep this number — it is the baseline for the hum test.**
- [x] **CPU headroom is ample.** Mixxx 18% of one core, load average 0.19 on
      four cores, zero xruns in the journal.
- [x] **16 bit only, and no capture gain control.** The card's only ALSA
      control is `PCM Playback Volume`; the PCM2902's ADC runs at fixed
      hardware gain. Input level is therefore set *entirely* by the Xone's send
      pot, with `[Auxiliary1] pregain` as the only trim after the fact.

**Deferred — needs the mixer physically connected:**

- [x] **Round-trip latency: 32 ms ± 3.** `alsabat --roundtriplatency` at the
      deck's own buffer settings, three runs. 60% above the 20 ms estimate,
      because both directions cost a full buffer rather than a period and the
      codec is USB 1.1 full speed. Method and consequences in
      `measurements.md`.
- [x] **Levels: settled at ~1 o'clock, −12.8 dBFS peak.** Fully clockwise was
      −0.33 dBFS, no headroom at all. −12.8 looks conservative for one source
      and is not: the aux bus sums, so two channels at this level already peak
      near −7.
- [x] **Hum: measured, and it's a non-issue.** Connected and powered with all
      sends off, the broadband floor rose 1.1 dB over the unconnected control
      (−90.7 → −89.6 dBFS). A mains component *is* present — 100 Hz up 8.7 dB,
      L/R correlation 0.246 → 0.400, the signature of common-mode rectifier
      ripple — but at −105.8 dBFS it sits 16 dB below the noise floor. No
      action. Full figures and method in `measurements.md`.
- [ ] Sustain: duplex for 20 minutes, watch the header's underrun counter. If
      it climbs, step `latency` to 4 and re-read the jog-bend cost noted in
      `mixxx_config/upload.sh`.
- [ ] **Thermals.** The SoC sat at **71 °C essentially idle** — warm for a Pi 4
      doing this little, and throttling starts around 80–85 °C. CPU headroom is
      not the constraint here; heat might be. Re-check under duplex + DSP in a
      closed chassis.

## Assumed values, and what they turned out to be

All measured now. Kept side by side because two of the estimates were wrong in
ways that mattered.

| Quantity | Assumed | Measured | |
|---|---|---|---|
| Round-trip latency | 20 ms | **32 ms ± 3** | Estimate was 60% low — both directions cost a full buffer, not a period, and the codec is USB 1.1 full speed |
| Send pot position | ~10–11 o'clock | **~1 o'clock → −12.8 dBFS peak** | Fully clockwise was −0.33 dBFS, no headroom at all |
| Noise floor once connected | ≤ −85 dBFS | **−89.6 dBFS** | 1.1 dB over the unconnected control; no action |
| `[Auxiliary1] pregain` | 1.0 (unity) | *unset* | Only trim available after the fixed-gain ADC |

Full method and figures in `measurements.md`. The latency being 32 rather than
20 ms tightens comb-filter notch spacing to 31 Hz (worse for transformative
effects, irrelevant to reverb and echo) and means Phase 4 cannot compensate
delay divisions shorter than 32 ms by subtraction — a 1/16 at 128 BPM is 29 ms,
shorter than the latency itself.

---

## Phase 1 — Aux input reaches the main mix, unprocessed

Pure config. Proves Mixxx's input side end to end before any engine work.

- [x] `mixxx_config/soundconfig.xml`: `<input channel="0" channel_count="2"
      index="0" type="Auxiliary"/>` inside the existing `<SoundDevice>`.
      `index="0"` is `[Auxiliary1]` — `PlayerManager::groupForAuxiliary()`
      returns `[Auxiliary{i+1}]`. Written before `<output>` to match the order
      Mixxx writes the file back in.
- [x] **`main_mix` cannot go in `mixxx.cfg`.** It is not a persisted control,
      and `EngineAux`'s constructor calls `setMainMix(false)` unconditionally
      on every start (`engineaux.cpp:24`), so a config value would be
      overwritten before anything reads it. Forced from `TriMixxx.init` in
      `TriMixxx.scripts.js` instead. **This is the failure mode that reads as
      "I configured the input and there is no sound".**
- [x] Verified: `Input channels: 2`, `1 input sound devices opened`, capture
      stream `Running`, and the Effects page reports the aux configured and on
      the main mix.
- [x] Listened. The send arrives clean.
- [ ] Re-pull `soundconfig.xml` from the deck afterwards — Mixxx rewrites it at
      startup once devices are set up.
- [ ] Confirm behaviour when the codec re-enumerates (unplug/replug): does the
      aux come back, or does Mixxx need a restart?

**Exit criterion:** the Xone's aux bus is audible through TriMixxx's output.
This is also the moment the feedback loop first becomes possible — TriMixxx's
own channel send stays at zero from here on.

---

## Phase 2 — `WetOnly` chain mix mode (the core patch)

Mixxx cannot return wet-only today. `Reverb` and `Echo` declare
`setAddDryToWet(true)` and the chain re-adds the dry at
`engineeffectchain.cpp:268`; DRY/WET at mix=1 gives `wet + dry` and DRY+WET gives
`dry + wet×mix`. Both reproduce the Boss-pedal bug in software.

- [x] `src/effects/effectchainmixmode.h` — `WetOnly = 2`, `kNumModes = 3`
- [x] `src/effects/effectchainmixmode.cpp` — the `"WET"` string in
      `toString`/`fromString`
- [x] `engineeffectchain.cpp` — `skipAddingDry` now triggers for any mode that
      isn't `DrySlashWet`, not just `DryPlusWet`
- [x] `engineeffectchain.cpp` — third branch: `out = wet × mix` via
      `copyWithRampingGain` (single source), so the wet still ramps and doesn't
      click on a fast mix move
- [x] **Empty-chain silence guard** (blocker 1 below) — handled after the
      processing block, gated on `channelStatus.enableState != Disabled` so it
      silences a routed-but-idle chain without touching channels the unit isn't
      routed to
- [x] **Built, deployed and audible.** Also since extended for the rack: six
      slots per unit, a per-slot `wet` control blended in the chain loop
      (WetOnly chains only), that value carried in `EffectPreset`, and the
      `mix_mode` toggle put back to two states so `WET` stops leaking into
      QuickEffect and Equalizer chains.
- [ ] Extend the `mixxx-test` target if there's an existing engineeffectchain
      test; otherwise assert the three modes by hand with a known buffer

### Blockers and things to check, in this phase

1. ~~**The empty-chain dry leak.**~~ **Handled, needs verifying by ear.**
   `EngineEffectChain::process()` only writes `pOut` when `processingOccured`
   and returns false otherwise, which would leave the caller holding the
   unprocessed input — the +6 dB doubling bug, armed by clearing an effect slot
   mid-set. Now guarded: in WetOnly, a routed chain that processed nothing
   clears `pOut` and reports true. Three cases to check on hardware: **(a)**
   clear the last effect slot → silence, not dry; **(b)** switch the unit off
   with `enabled` → silence, not dry; **(c)** set `group_[Auxiliary1]_enable 0`
   → dry passes again, because the unit is no longer on that channel at all.
   (c) is the one most likely to be wrong, since it depends on `Enabling` being
   the settled state for a routed-but-off channel.
2. ~~**Three-state toggle side effects.**~~ **Checked, no impact.**
   `mix_mode` is a `ControlPushButton` in TOGGLE mode sized by
   `setStates(kNumModes)` (`effectchain.cpp:86`), so 3 states changes the cycle
   for every chain type. Nothing in `mixxx_config/` references `mix_mode` at
   all — only the stock skins do, and the deck doesn't load them.
3. **`effects.xml` is not forward-compatible.** `fromString` falls back to
   `DrySlashWet` on an unrecognised string, so a preset written by the patched
   build and read by a stock Mixxx silently becomes DRY/WET — full dry into the
   mix on top of the mixer's dry. Don't let a stock binary open the deck's
   `~/.mixxx/effects.xml`.
4. **Upstreamability.** This is a genuinely general fix (every send/return user
   on every mixer has this problem). Keep the patch clean enough to offer
   upstream rather than carrying it forever.

---

## Phase 3 — Route a unit to the aux and make it sound right

- [x] EffectUnit2 dedicated to `[Auxiliary1]`, `mix_mode` WET.
- [ ] Chain `Filter (HPF) → Reverb`. HPF ~200–300 Hz on the wet keeps the effect
      obvious while removing the low-mid energy that carries perceived loudness,
      so the "no volume change" goal survives contact with a real system.
- [ ] Establish the two gestures and label them clearly:
      - `[Auxiliary1] pregain` = **send** — pre-effect, so pulling it stops
        feeding the tank and the existing tail rings out
      - `[EffectRack1_EffectUnit2] mix` = **return** — post-effect, cuts the
        tail dead
- [x] Preset shipped: `mixxx_config/effects.xml`, validated and copied by
      `upload.sh` with the same stop-first handling as `mixxx.cfg`.
- [x] Sanity tested at the mixer: reverb only, dry level unchanged, and it
      survives a reboot with no manual step.

**Exit criterion:** the original problem is solved. Everything below is
refinement.

### Done — and what actually bit us

Working on the deck, audible on the CDJ, surviving a reboot with no manual step.
None of the four things that had to be true were in the plan, and all four fail
*silently*, which is why the Effects page states each of them outright:

1. **`main_mix` cannot be configured.** Not a persisted control, and
   `EngineAux`'s constructor calls `setMainMix(false)` on every start, so
   `mixxx.cfg` is powerless. Forced from `TriMixxx.setupPedalBus()`.
2. **`StandardEffectChain` does not enable its slots.** It is the only chain
   type that doesn't — Output, QuickEffect and Equalizer all call
   `setEnabled(true)`. Upstream expects a skin to draw an enable button. Ours
   draws none, and `EffectPreset` has no `enabled` field to carry it either.
3. **An empty `<Parameters>` list is worse than useless, and self-perpetuating.**
   `loadEffectInner` clears `m_loadedParameters` then refills it *from the
   preset*, so a hand-written preset with `<Parameters/>` maps nothing — leaving
   an effect that reports `loaded = 1` with every parameter at 0. It then
   serialises an empty list again on exit, because `EffectPreset` reads
   `m_loadedParameters`. **The bad state cannot be fixed by capturing what the
   deck writes**; the load has to come from the manifest, via `loaded_effect` →
   `loadEffectWithDefaults`.
4. **`send_amount` defaults to 0** and is Linked to the *effect slot's*
   metaknob — not the chain's `super1`, which is a different control. Nothing
   drives it on its own, so a correctly loaded reverb is still silent.

Plus an ordering race worth remembering: the controller opens ~30 ms *before*
SoundManager sets up devices, so `init` runs while `[Auxiliary1]` has no input.
Across restarts, `main_mix` and `loaded` were observed flipping in opposite
directions. The setup is now idempotent and asserted three times — at init, on
`input_configured`, and on a 2 s timer — with the ready flag set from what the
control *reads back* rather than from having made the call.

**Still to do here:** the `Filter (HPF) → Reverb` chain, so the wet is
high-passed and the perceived level holds steadier.

---

## Phase 4 — Beat sync on the aux bus

Echo's `Quantize` and `Triplets` are dead on an aux: `echoeffect.cpp:135` needs
`groupFeatures.beat_length`, `EngineAux::collectFeatures` supplies only the VU
meter, so the Time knob falls through to the seconds branch at `:148`.

- [x] **Tempo source: whichever deck has been playing longest.** Not the network
      master — a master can be a deck sitting cued. Candidates are the Pro DJ
      Link players judged by `isWorthFollowing()` (the same test the phase meter
      uses, which already excludes cued, paused, searching and spun-down decks)
      and this deck's own player on the same terms. Oldest wins and keeps
      winning until it stops; entries drop the moment a deck stops, so a deck
      that pauses and restarts is correctly the youngest again. Published as
      `[EffectTempo] bpm` and `source`.
- [x] **`beat_length` injected** in `EngineAux::collectFeatures`.
- [x] **The name bar says which deck and at what tempo**, because a delay
      quantised to the wrong deck sounds exactly like a broken one. Also logged
      on change, which is how it was verified without a screen.
- [ ] **Latency compensation is not done.** The taps sit ~32 ms late. Divisions
      shorter than that cannot be compensated by subtraction at all — a 1/16 at
      128 BPM is 29 ms — so this needs wrapping to the next beat rather than
      subtracting, and has not been attempted.

**The uncertainty resolved the way the phase predicted.** Tempo was the easy
half; phase was not attempted. `beat_fraction_buffer_end` is deliberately left
unset: the phase of several decks summed by a mixer and arriving 32 ms late has
no single right answer, so none is given. Quantising the delay *length* to a
musical division is the useful part and that is what shipped.

---

## Phase 5 — The effect rack  *(superseded: see `docs/effects-prd.md`)*

The "FX tab" sketched here became a full design and a signed-off PRD, revision
3. Everything below is now specified there rather than guessed at: a horizontal
rack of drawn modules, per-unit wet with the first dry-killer locked open, a
master module pinned right and driven by the encoder, drag to scroll, hold to
reorder, drag-to-bin to remove, and racks saved as stock Mixxx chain presets.

**The engine work it rests on is done** (Phase 2). What remains is UI:

- [ ] **Move the debug status block to Diagnostics.** Aux configured, aux to
      main, aux level, unit routed, unit enabled, mix mode, effect loaded,
      effect on, slot group — plus the measured 32 ms round trip and the aux VU
      as a live bar. It is diagnostic information and belongs with the rest of
      it. The rack shows no status text.
- [ ] **Invert the browser's gesture dispatch.** `move`, `select` and `back`
      each carry a chain of `if (m_stack.last().kind == …)` — sort menu,
      diagnostics, effects — growing by three every time a page is added. The
      rack needs drag, long-press and horizontal scroll on top. A page should
      claim the gestures it wants instead of the browser knowing about each one.
- [ ] **Replace `WDeckEffects` wholesale.** It rebuilds a rich-text document
      through `setHtml` five times a second; it cannot do dragged knobs and
      cannot do drag-and-drop reordering at all. It was scaffolding and says so.
- [ ] Module chrome: cached `QPixmap` per module type, procedural, from the
      palettes sampled off the reference skins (PRD §9).
- [ ] Knobs, drag and double-tap-to-reset.
- [ ] Rack scroll, long-press reorder, bin.
- [ ] The `(+)` chooser.
- [ ] Master module + encoder + mute.
- [ ] Name bar and the rack browser.

---

## Phase 6 — LV2 host upgrade

Mixxx's LV2 backend calls `lilv_plugin_instantiate(pPlugin, sampleRate, nullptr)`
(`lv2effectprocessor.h:28`) — zero host features — so `lv2manifest.cpp:183`
correctly rejects every plugin declaring a required feature, and `:177` rejects
anything that isn't exactly 2-in/2-out. `liblilv-dev` is already a build dep
(`Dockerfile:54`), so the backend is compiled in and this is purely about what it
will accept.

- [ ] Survey first: script on the Pi that walks the installed LV2 bundles and
      reports, per plugin, audio port counts and required features — i.e. what
      Mixxx would accept today. Cheap, and it decides whether the rest is worth
      doing.
- [ ] `urid:map` / `urid:unmap` — URI↔uint32 table. Smallest change with the
      biggest unlock.
- [ ] `options` + `buf-size` — advertise sample rate and max block length
- [ ] Channel adaptation — accept mono and 1-in/2-out plugins (most classic
      reverbs are 1-in/2-out)
- [ ] Atom sequence ports — lets plugins receive host tempo, i.e. plugin delays
      that beat-sync
- [ ] `worker`/`schedule` — unlocks convolution reverb
- [ ] `state` — plugin presets

---

## Phase 7 — Polish

- [ ] Safety limiter on the wet return (the send pot has +6 dB and a feedback-y
      delay can run away)
- [ ] LED / on-screen indication that the pedal bus is live
- [ ] Document the mixer setup on the deck itself, or in the README

---

## Phase 8 — the first test run's list

From a real run with the rack in front of a mixer. Full reasoning per item in
`docs/effects-prd.md` §15; this is the order to do them in.

**Ordered by what is blocking use.** The first two make the rack behave; the
engine work after them makes it good.

- [x] **The rack empties when you leave the page.** `writeChainToEngine()` only
      writes `loaded_effect` when `module.slot != i`, and a module appended by
      the chooser already has `slot == i` — so it is drawn but never loaded, and
      `syncFromEngine()` on return finds an empty chain. One condition. **Do
      this first; it makes everything else testable.** (§15.5)
- [x] **Filters lose their wet knob.** `out = filter(in, cutoff)` and nothing
      else — the blend double-counts the passband and combs it against itself.
      Cutoff becomes a frequency in Hz, HPF cuts below and LPF above, both
      default mid-band. (§15.6)
- [x] **Saving must not ask for a name.** `savePreset()` opens a dialog; the
      deck has no keyboard. Generate the name and write the file. Then: saved
      racks appear in the list, the list scrolls, and the last one loads at
      startup. (§15.5)
- [x] **Drag keeps its grab point** rather than centring the module on the
      finger. (§15.7)
- [x] **Reorder displaces live** — neighbours slide out of the way as the held
      module crosses them, so the rack always shows the order that would
      result. (§15.8)
- [x] **Delay and Echo time in fixed divisions**, shown beside the dial:
      1/16 · 1/8 · 1/4 · 1/2 · 3/4 · 1 · 2 · 4 · 8. (§15.9)
- [x] **Makeup gain on the wet.** The chain outputs `wet × mix` with `mix`
      maxing at unity, and a reverb tail at unity is far quieter than the dry
      beside it. The master wants range above 0 dB. (§15.4)
- [x] **Master ring-out toggle.** A rocker choosing whether the master scales
      the chain's input (tails ring out) or its output (cut dead). Default ring
      out. (§15.2)

### Phase 9 — the second test run's list — **done**

Reasoning in `docs/effects-prd.md` §17.

- [x] **The rocker glitched on the way across.** It parked the stage it was
      leaving at unity *before* handing the level to the one it was arriving at,
      so for one buffer both were open and the chain ran at full wet. Reversed,
      which turns a burst into an inaudible dip.
- [x] **Mute did not survive the rocker.** Flipping while muted carried the
      zero across and left the real level stranded in `m_mutedLevel`.
- [x] **CUT "did not work at all" — it did.** An LPF three modules in was at its
      13 Hz floor and everything downstream was reverberating silence. Measured:
      −79.6 dBFS with it closed, −37.9 with it open. §15.3 metering is the fix
      for the class, and it now shows exactly where a chain dies.
- [x] **The encoder follows the last knob touched**, with a lit ring saying
      which. Press still always mutes the master.

### Found while testing, not on any list

- [x] **Mixxx segfaulted on every shutdown**, so *nothing* persisted — not the
      rack, not mixxx.cfg. One cause fixed (a destructor emitting signals back
      into the object destroying it); a second remains, recorded below.
- [x] **The rack persists itself now**, two seconds after each change, rather
      than depending on a clean exit that a booth deck rarely gets anyway.
- [x] **`deck-record`** joins `deck-shot` and `deck-poke`: one sees, one
      touches, this one listens. It records Mixxx's own main mix, which is the
      only way to hear the aux return and the chain from here.
- [x] **The build was capped and pinned.** Trixie pinned rather than read off
      the deck, build trees keyed per release, parallelism capped so a cold
      build stops OOMing.

### The FX strip on the deck view (§16)

Reaching the effects should not mean leaving the waveform. **Depends on the two
engine items below** — without metering the VU has nothing to draw, and without
the mute-mode toggle the rocker has nothing to switch — so it comes after them.

- [ ] An **FX** section down the left of the waveform on the deck view: VU,
      master knob, mute-mode rocker.
- [ ] **Touch claims the encoder** — rotate is the FX master, press is its mute,
      and the border lights while it holds focus. Touching anything else
      releases it and the encoder returns to library/zoom. The deck view needs
      its own version of the `DeckPage` claim mechanism, or the two want
      merging.
- [ ] **Decide the focus timeout** (§16). Focus takes the encoder press away
      from the library while held; a timeout gives it back on its own, no
      timeout keeps it where it was put. Better mid-transition either way is not
      obvious.
- [ ] **Factor the chrome out of `WDeckRack`** — bevel, knob, VU, engraved text
      — now that there is a second caller. Doing it earlier would have been
      guessing at what the second caller needed.

### Engine work in this phase

- [ ] **The rack must reach the deck's own audio.** Today it can effect every
      channel on the mixer except the one the deck is playing. Routing the unit
      to both channels does *not* do it — Mixxx units are per-channel and would
      process them separately, taking the deck's dry with them. Proposed: sum a
      scaled copy of the deck's post-fader audio into the aux buffer inside
      `EngineAux::process()`, before the chain, so the aux channel *becomes* the
      send bus and everything downstream is unchanged. **Check `EngineMixer`'s
      channel order first** — the deck must be processed before the aux, and the
      wrong order is a buffer one callback late, which is inaudible and still
      wrong. Two send dials in a fixed INPUT module at the far left, mirroring
      the master at the far right. (§15.1)
- [ ] **Per-slot output metering.** Nothing publishes an effect's output level;
      it has to be measured in `EngineEffectChain::process()` after each effect
      and published as a control. Feeds a VU on every module and on the master,
      drawn as a segmented ladder rather than a bar. (§15.3)

---

---

## Open questions

- Which mixer channel does TriMixxx return on? A music channel (CH 1-4) gets the
  VCF and crossfader, which the deck wants as a player; `RTN 1/2` does not.
- Does the deck's own track ever want the pedal bus? It can't — that closes the
  feedback loop. Its effects have to be internal (a second unit on
  `[Channel1]`), which means two FX controls unless the tab hides the seam.
- Is a second cheap USB DAC worth it later? It would give the wet return its own
  mixer channel and break the coupling where fading TriMixxx out also pulls the
  effect off every other channel.

---

## Open: Mixxx still segfaults at the end of shutdown

**Not the effects, but it was hiding as them.** Mixxx crashed on every
shutdown from 12 August 19:04 until 13 August, which is why the rack seemed
not to persist -- and why *nothing* persisted, mixxx.cfg included, since the
crash lands before `CoreServices::finalize()` saves anything.

One cause found and fixed: `~MediaRegistry` -> `~ProLinkNetworkService` ->
`shutdown()` -> `MediaRegistry::onDeviceLost()`, a destructor emitting a signal
back into the half-destroyed object that owns it, which ran a database query
and aborted inside malloc. See the commit for the symbolised trace.

**A second crash remains**, and it is further along:

```
  debug [Main] 87 ms deleting menubar
  Segmentation fault        (sometimes Bus error -- it alternates)
```

What is known:

- It is at `mixxxmainwindow.cpp:520`, `m_pMenuBar = nullptr` /
  `m_pMenuBar.toWeakRef()`, crashing inside
  `QtSharedPointer::ExternalRefCountData::getAndRef` -- so `m_pMenuBar` is a
  non-null dangling pointer by then. That is stock Mixxx code.
- **Not our skin.** It crashes identically with the stock Deere skin.
- **Not testable against stock Mixxx**: the apt binary exits 143 on SIGTERM
  because handling that signal is our patch, so it never enters the graceful
  path at all.
- The crash type alternating between SIGSEGV and SIGBUS at the same line says
  the heap is already corrupt before it gets there, so the cause is upstream of
  the symptom.

Persistence no longer depends on this being fixed -- the rack saves itself two
seconds after each change -- so this is a tidiness and settings-durability
issue rather than a data-loss one. **Next step if picked up:** bisect between
`94d2af3` (12 Aug 09:03, the last build known to shut down cleanly) and
`3e8022b`, or run one boot with `MALLOC_CHECK_=3` to abort at the corrupting
operation rather than at its victim.

## Open: an unreproduced bad restore

Once, a cutoff saved as 2658 Hz came back as 13 Hz after a restart. Not
reproducible since -- 4335 Hz saved and restored correctly on the same build --
and the file was verified to hold the right value before the restart. Recorded
because eager persistence makes any transient bad read *permanent*: it would
overwrite the good file two seconds later. That is why `persistSoon()` ignores
the startup read.

## Closed: playlists inside "techno night" came up empty — a stale export

Reported 14 August. **Fixed by re-syncing the stick from rekordbox**, and our
parser was never the problem.

The chase, because two of its three conclusions were wrong on the way:

1. *"It's the space in the folder name."* No. `Sssssh claps`, `breakcore start`
   and `alba franch ` (trailing space) all carried their tracks.
2. *"The export has no entries, so it isn't us."* Right about the export, and
   argued badly: the evidence offered was zero orphaned entries, which only
   shows that what we read was attributed correctly, not that we read
   everything. Establishing it properly took walking the `playlist_entries`
   chain and confirming every page in the file is visited.
3. *"The tracks are in Device Library Plus and we can't read it."* Plausible --
   the stick did carry an encrypted `exportLibrary.db` and a Plus manifest
   listing all four playlists -- and wrong. The old `export.pdb` was simply
   stale.

After a fresh sync, the same probes on the same stick:

```
id=25 parent=2 folder=false entries=0     Intro
id=26 parent=2 folder=false entries=8     tension builders
id=27 parent=2 folder=false entries=15    maintain
id=28 parent=2 folder=false entries=17    peak
id=29 parent=0 folder=false entries=13    Rally house      (was 0)
entries whose playlist_id matches no tree row: 0
```

`playlist_entries` is 6 pages, all 6 walked, chain ends where the directory says
it does, and the per-playlist counts sum exactly to the 354 rows the reader
returns. Headers declare 436 slots; the presence mask marks 354 live, which is
the same mechanism that on the older file marked *more* live than the header
counted (F47). Both directions are normal.

**`Intro` is still empty**, which now means it is empty in rekordbox rather than
lost in transit. Worth a glance next time the collection is open.

### So: no Device Library Plus work

`exportLibrary.db` is SQLCipher and we still do not read it, and on this evidence
we do not need to: rekordbox writes the classic `export.pdb` correctly when the
stick is synced. If an empty playlist ever shows up again, re-sync first --
that is one minute against a week of decryption and a licensing question.

### What the hunt left behind

- `MediaRegistry` keeps the bytes it ingested at `~/.mixxx/last-ingest.pdb`. A
  remote medium's pdb never touches the disk, so "why was this playlist empty"
  previously had no evidence to work from at all. MIDI note 0x7B re-pulls the
  database without unplugging anything.
- Three examples in `lib/prolink`: `pl_probe`, `entries_pages`, `all_pages`.
  Between them they answer the only two ways an empty playlist could be ours --
  "did we read every row" and "was every row attributed" -- and they are what
  finally settled this one in a minute rather than a day.
- A trap worth remembering: `QSqlDatabase::databaseName()` is a URL here
  (`file:/home/...`), not a path, so the first version of the pdb copy wrote to
  a mangled directory and said nothing.
- The volatile-header business (F13) showed up again unprompted: the pdb pulled
  from the CDJ and the same file read off the stick differed in 35 bytes, all of
  them the write counter and its neighbours. Worth recognising on sight.

# History

Everything below is settled and is kept for the reasons rather than the results:
each of these cost hours, and the next person to meet one of them — including
me, next month — will meet it in the same disguise.

## Risk register

Ordered by how much is lost if the answer is bad.

| # | Risk | Why it matters | When we'll know |
|---|---|---|---|
| ~~1~~ | ~~Codec isn't full-duplex~~ | **Cleared** — PCM2902 does stereo 44.1 k capture concurrently with playback | Phase 0, done |
| 2 | Duplex xruns at the current buffer | Forces higher latency, which worsens comb filtering and jog bend | Deferred — needs sustained duplex |
| 2b | **Thermal, not CPU** | 71 °C idle, throttles ~80 °C, closed chassis. CPU is at 18% and irrelevant | Under load, deferred |
| 3 | Empty-chain dry leak | Silent trap that reproduces the exact bug we're fixing, mid-set | **Guarded in Phase 2; unverified** |
| 4 | Feedback loop via TriMixxx's own aux send | Howl-around in front of a crowd; mixer-side discipline only | Phase 1 onward |
| ~~5~~ | ~~CPU headroom on the Pi 4~~ | **Cleared** — 18% of one core, load 0.19, no xruns | Phase 0, done |
| 5b | 16-bit fixed-gain ADC, no input trim | Send pot is the *only* input gain control; clipping has no software rescue | Level test, deferred |
| 6 | Comb filtering on transformative effects (crush, filter, pitch) | Their output stays correlated with the dry, and the return is ~20 ms late; reverb and echo are immune | Phase 3, by ear |
| 7 | `effects.xml` read by a stock Mixxx build | Silent downgrade to DRY/WET = full dry into the mix | Phase 2 — note it |
| 8 | Beat phase on a multi-CDJ live input may have no correct answer | Limits Phase 4 to tempo-only quantise | Phase 4 |
| 9 | LV2 ecosystem may not repay the host work | Survey before committing | Phase 6, step 1 |

---

## Resolved: the codec leaked its input to its output — it was the MONITOR switch

**Fixed by setting MONITOR to OFF on the UCA222.** The dry stopped coming back.

**The manual is wrong about this unit**, and it cost an hour, so it is worth
stating plainly. The UCA222 user guide says of the switch:

> With the MONITOR switch OFF, the headphone output receives the signal from the
> computer over the USB port (same as the RCA output jacks). With the MONITOR
> switch ON, the headphones receive the signal connected to the RCA INPUT jacks.

Headphones, in both positions. The RCA `OUTPUT` is documented throughout as
carrying the computer's audio and nothing else. On this unit it does not: with
MONITOR ON, the input reaches the **RCA outputs** as well. Every measurement
below was consistent with a hardware analog path and the reasoning was sound —
the error was trusting the manual to describe where that path went.

**Lesson for the rest of this work:** on this hardware, flip the switch and
listen before reasoning from the documentation.

What had been established, all of it still true:

- With the CDJ's channel fader **fully down** and its AUX 2 send up, the CDJ is
  audible on TriMixxx's mixer channel.
- It survives with **Mixxx stopped**, and appears during boot **before Mixxx
  starts**. Powering the Pi down kills it.
- **Nothing in software is doing it.** The capture stream reads `Status: Stop`,
  so the ADC's data never crosses USB; only `mixxx` holds the device and only
  its *playback* node; no PipeWire, PulseAudio, alsaloop or jackd is running;
  no `.asoundrc` and no `/etc/asound.conf`.
- **Nothing in the codec's declared topology is doing it either.** The USB audio
  descriptors are two disjoint chains — `[1] USB Streaming → [3] Feature Unit →
  [2] Speaker` and `[4] Analog In → [5] USB Streaming` — with no Mixer Unit and
  no Selector Unit anywhere, which are the only descriptors that could route
  capture into playback.
- The UCA222 manual is explicit that the MONITOR switch feeds the **headphones
  only**: OFF gives the phones the computer's signal, ON gives them the RCA
  input. The RCA `OUTPUT` is documented as carrying the computer's audio in both
  positions. Only the RCA jacks are in use here.

So it was analog and undocumented — which is exactly what the MONITOR switch
turned out to be, routed somewhere the manual does not admit to.

**Still unexplained, and probably nothing:** the near-mono capture measured
before the switch was found — L/R correlation 0.993 with side energy pinned at
−24.5 dB across 30 s. The ground-coupling theory would have explained it, since
a common-mode component lands identically on both channels; with that theory
gone, the likeliest remaining explanation is simply a very mono techno loop.
Settle it whenever convenient by unplugging the `AUX 2 OUT` L cable: if L drops
to the noise floor while R keeps signal, the channels are independent and it was
the music.

## Fixed: Mixxx never wrote its settings on exit

Found 2026-08-11 while checking that per-slot wet round-tripped. **It does not,
and neither does anything else**: `~/.mixxx/effects.xml` and `mixxx.cfg` were
last modified by an `scp`, not by Mixxx, across many restarts since.

What is established:

- `soundconfig.xml` **is** written, at 22:39:48, i.e. at *startup*. So Mixxx can
  write to that directory and the permissions are fine. It is specifically the
  **shutdown** save path that never runs — which is where both `mixxx.cfg` and
  `effects.xml` are written.
- The signal handler works. `PosixSignalHandler` logs `caught signal 15 -
  shutting down` on every restart, and the shutdown proceeds far enough to close
  the main window, process `QEvent::Quit` and spend 70 ms deleting the skin.
- **Not a crash.** No segfault in `dmesg` or the journal. The log simply stops,
  which is consistent with buffered Debug output being lost at exit — the deck
  runs with `--log-flush-level info`.
### Root cause: Mixxx crashes on shutdown

Found by logging the exit status from `xinitrc`, which is otherwise unknowable —
Mixxx's own log just stops at whatever was last flushed, so a clean quit and a
crash look identical from outside.

```
debug [Main] 25 ms deleting skin
malloc_consolidate(): unaligned fastbin chunk detected
Aborted
--- mixxx exited 134 at 22:50:43 ---
```

`malloc_consolidate(): unaligned fastbin chunk` is **glibc's heap-corruption
detector**, not a failed assertion. Something has written outside an allocation
or freed twice, and glibc notices during the teardown that follows skin
deletion. The process dies there — before `CoreServices::finalize()` reaches
`CLEAR_AND_CHECK_DELETED(m_pEffectsManager)` (which is what writes
`effects.xml`) and before `~CoreServices` reaches `m_pSettingsManager->save()`
(which writes `mixxx.cfg`). Hence neither file is ever written.

**Three shutdowns, three different faults: 134 (SIGABRT), 135 (SIGBUS), 139
(SIGSEGV).** Varying with allocation layout is the signature of heap corruption
rather than one consistently bad pointer.

**It is not our skin.** Swapping `ResizableSkin` to stock `LateNight` and
repeating gave 135 — still a crash on shutdown. So `WDeckBrowser`,
`WDeckEffects` and the rest of the deck's widgets are not the cause, and this
is not a regression from the effect-pedal work.

### Bisected: `TrackCache` outlives its background copies — **fixed**

`git bisect` over the 85 commits between `6b272c0` (the signal handler, the
first commit where a clean shutdown was even attempted) and `main` landed on
**`e4cbfeb` "deck: the deck plays from a copy, never from the medium"**, which
introduces `src/library/deck/trackcache.cpp`.

`TrackCache::prefetch()` hands a lambda capturing `this` to the **global** thread
pool, copies a track — seconds, for a big file — and then dereferences `this`
again to invoke a continuation that touches `m_entries` and `m_ramBytes`. The
destructor cleared a static pointer and nothing else. A copy still running when
the cache is destroyed therefore writes into freed memory, on every shutdown.

Fixed by giving it its own `QThreadPool`, drained in the destructor with
`clear()` then `waitForDone()`. That also makes it run one copy at a time, which
is what `prefetch`'s own comment already claimed ("the constraint is the USB
bus, not the CPU") but the global pool did not do.

**Verified: exit 0 and `mixxx.cfg` written**, where it was 135 and untouched.
Both settings files now persist, and `effects.xml` round-trips `WET` properly
for the first time.

### Two things learned in the process

**Old commits do not build against today's Debian.** `mixxx-test` links
`GTest::gmock`, which only main's `-DBUILD_TESTING=OFF` avoids, and
`.dockerignore` did not exist before a certain commit — without it the 9.3 GB
Rust `target/` directory ships as build context and fills Docker's VM. Both were
handled by pinning main's `Dockerfile` and `.dockerignore` on every bisect step;
they are build recipe, not product code, and holding them constant is what a
bisect wants anyway. **Keep doing that for any future bisect.**

**Restoring config while Mixxx runs no longer works.** Copying `effects.xml`
into place and then restarting lets the *running* instance write its stale
in-memory state over the restore — the exact hazard `upload.sh`'s comment
describes. It only bites now because the save works. Always stop first.

### The "second crash" does not reproduce — withdrawn

Right after the TrackCache fix, one shutdown with our skin still gave 135 while
stock LateNight gave 0, and that was written up here as a second, skin-specific
bug. It is not.

Three consecutive shutdown tests with the TriMixxx skin now give **exit 0 and
both settings files written**. The single 135 came from the one test where
config had just been restored underneath a *running* Mixxx — an instance holding
stale state that then wrote it back — so the likeliest reading is the same
corruption, or an artefact of that sequence, rather than a separate defect.

Nothing further to hunt. If it reappears the harness is still here: the exit
status logging in `xinitrc`, and `git bisect` with main's `Dockerfile` and
`.dockerignore` pinned on every step.
   damage is limited to state the DJ changes in the UI.

**This invalidates two earlier conclusions in this document.** Both were reached
by reading `effects.xml` after a restart and taking it for Mixxx's output:

1. That the WET mix mode "round-tripped through the control", proving the patch
   was live. It was my own uploaded file. The patch *is* live — the audio proves
   that — but that verification was worthless.
2. That an empty `<Parameters>` list "re-serialises the same broken state on
   exit", making it self-perpetuating. Nothing was serialised at all. The
   parameters really were zero, which the Effects page confirmed independently,
   but the mechanism was wrong.

**Consequence for the rack:** named rack presets are safe —
`EffectChainPresetManager::savePreset()` writes immediately. The *live* rack
would not survive a reboot until this is fixed.

**Unrelated, found alongside:** `~/.mixxx/stderr.log` is **346 MB** and growing.
Nothing rotates it.

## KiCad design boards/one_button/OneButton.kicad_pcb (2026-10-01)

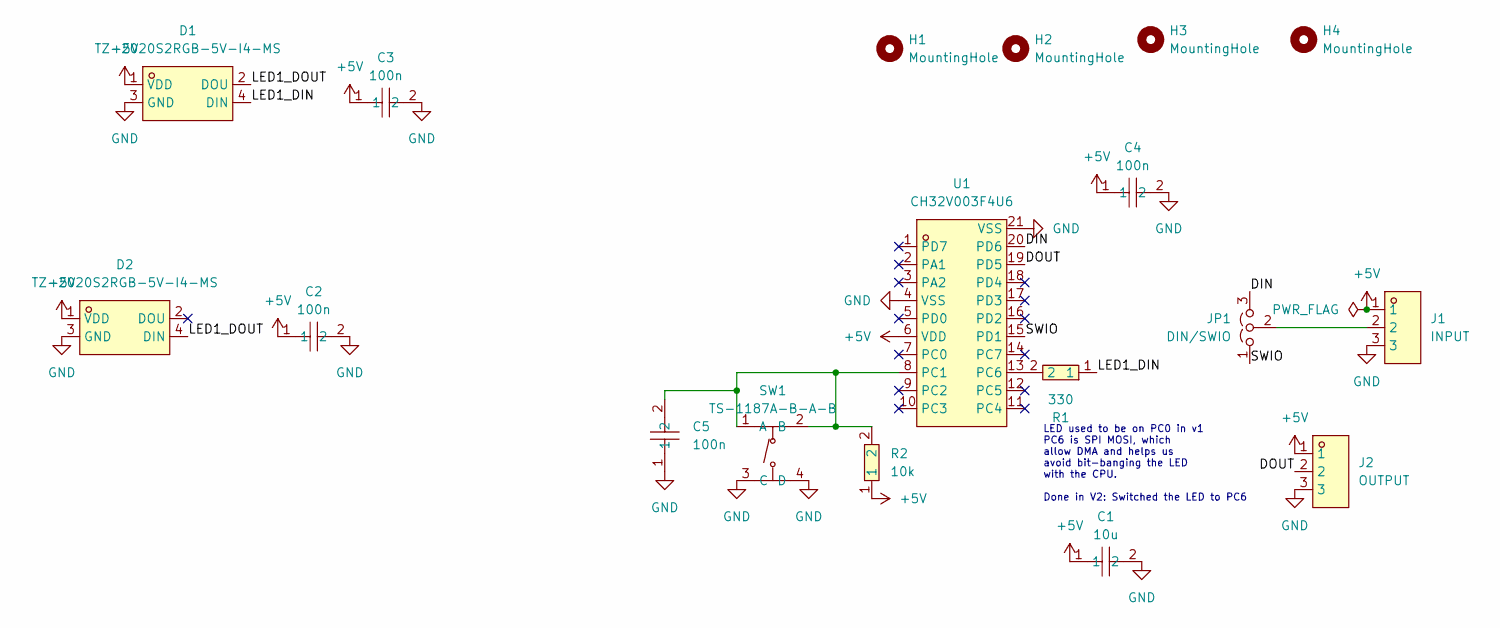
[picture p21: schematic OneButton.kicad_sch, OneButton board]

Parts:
C1: 10u; C0603; MPN CL10A106MA8NRNC; LCSC Part C96446
C2, C3, C4, C5: 100n; C0603; MPN CC0603KRX7R9BB104; LCSC Part C14663
D1, D2: TZ-2020S2RGB-5V-I4-MS; LED-SMD_4P-L2.0-W2.0_FZ_2020; MPN TZ-2020S2RGB-5V-I4-MS; LCSC Part C26159668
H1, H2, H3, H4: MountingHole; MountingHole_2.7mm_M2.5_ISO7380
J1: INPUT; CONN-TH_3P-P2.00_S3B-PH-K-S-LF-SN; MPN B3B-PH-K-S(LF)(SN); LCSC Part C131339
J2: OUTPUT; CONN-TH_3P-P2.00_S3B-PH-K-S-LF-SN; MPN B3B-PH-K-S(LF)(SN); LCSC Part C131339
JP1: DIN/SWIO; PinHeader_1x03_P2.54mm_Vertical
R1: 330; R0603; MPN 0603WAF3300T5E; LCSC Part C23138
R2: 10k; R0402; MPN 0402WGF1002TCE; LCSC Part C25744
SW1: TS-1187A-B-A-B; SW-SMD_4P-L5.1-W5.1-P3.70-LS6.5-TL_H1.5; MPN TS-1187A-B-A-B; LCSC Part C318884
U1: CH32V003F4U6; QFN-20_L3.0-W3.0-P0.40-TL-EP1.7; MPN CH32V003F4U6; LCSC Part C5299908

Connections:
+5V: C1.1, C2.1, C3.1, C4.1, D1.1 (VDD), D2.1 (VDD), J1.1, J2.1, R2.1, U1.6 (VDD)
/DIN: JP1.3 (B), U1.20 (PD6)
/DOUT: J2.2, U1.19 (PD5)
/LED1_DIN: D1.4 (DIN), R1.1
/LED1_DOUT: D1.2 (DOU), D2.4 (DIN)
/SWIO: JP1.1 (A), U1.15 (PD1)
GND: C1.2, C2.2, C3.2, C4.2, C5.1, D1.3 (GND), D2.3 (GND), J1.3, J2.3, SW1.3 (C), SW1.4 (D), U1.4 (VSS), U1.21 (VSS)
unnamed: J1.2, JP1.2 (C)
unnamed: C5.2, R2.2, SW1.1 (A), SW1.2 (B), U1.8 (PC1)
unnamed: R1.2, U1.13 (PC6)

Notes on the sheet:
LED used to be on PC0 in v1 PC6 is SPI MOSI, which allow DMA and helps us avoid bit-banging the LED with the CPU. Done in V2: Switched the LED to PC6

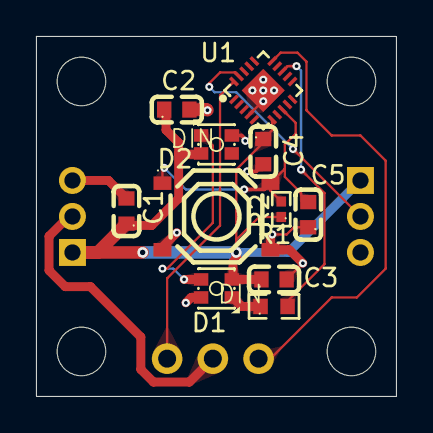
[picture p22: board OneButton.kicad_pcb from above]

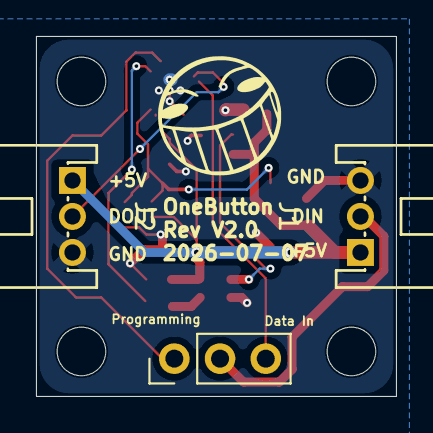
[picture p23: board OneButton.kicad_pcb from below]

Board: 2 copper layers, 20.0 x 20.0 mm, 18 parts (3 on the bottom side), 10 nets.

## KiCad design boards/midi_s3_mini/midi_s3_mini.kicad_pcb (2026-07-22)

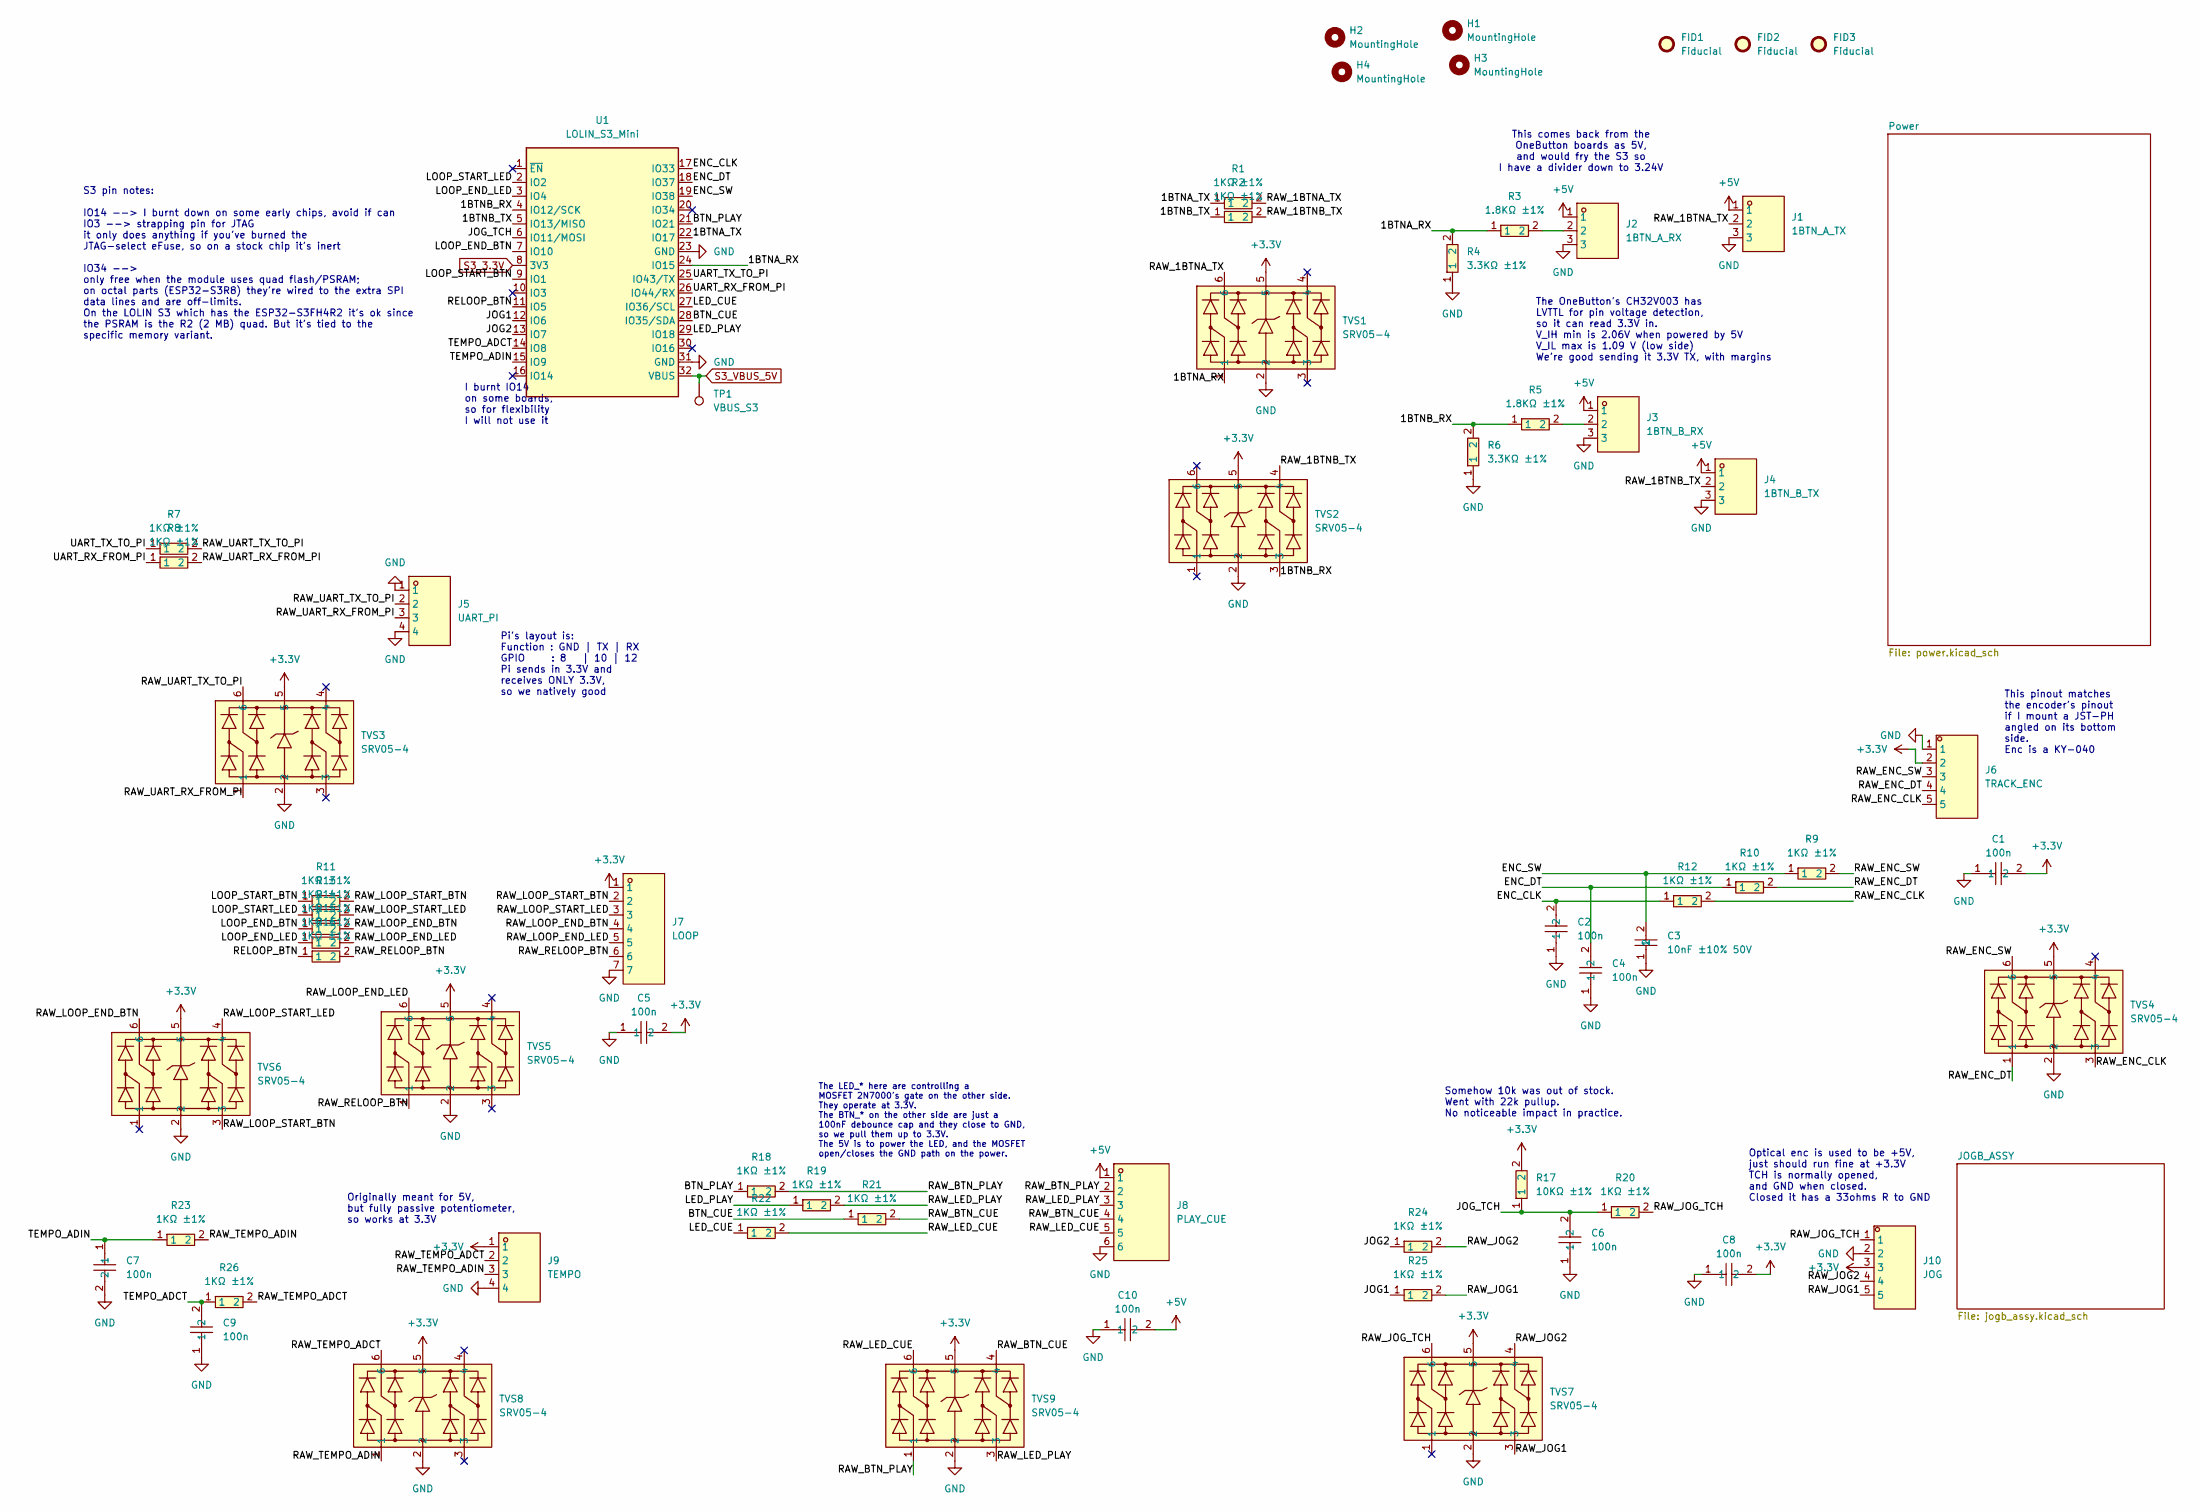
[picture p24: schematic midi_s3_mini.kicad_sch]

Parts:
C1, C2, C4, C5, C6, C7, C8, C9, C10: 100n; C0402; MPN CL05B104KB54PNC; LCSC Part C307331
C3: 10nF ±10% 50V; C0402; MPN CL05B103KB5NNNC; LCSC Part C15195
FID1, FID2, FID3: Fiducial; Fiducial_1mm_Mask2mm
H1, H2, H3, H4: MountingHole; MountingHole_4.3mm_M4_ISO7380
J1: 1BTN_A_TX; CONN-TH_3P-P2.00_S3B-PH-K-S-LF-SN; MPN S3B-PH-K-S(LF)(SN); LCSC Part C157929
J2: 1BTN_A_RX; CONN-TH_3P-P2.00_S3B-PH-K-S-LF-SN; MPN S3B-PH-K-S(LF)(SN); LCSC Part C157929
J3: 1BTN_B_RX; CONN-TH_3P-P2.00_S3B-PH-K-S-LF-SN; MPN S3B-PH-K-S(LF)(SN); LCSC Part C157929
J4: 1BTN_B_TX; CONN-TH_3P-P2.00_S3B-PH-K-S-LF-SN; MPN S3B-PH-K-S(LF)(SN); LCSC Part C157929
J5: UART_PI; CONN-TH_4P-P2.00_S4B-PH-K-S-LF-SN; MPN S4B-PH-K-S(LF)(SN); LCSC Part C157926
J6: TRACK_ENC; CONN-TH_S5B-PH-K-S-LF-SN; MPN S5B-PH-K-S(LF)(SN); LCSC Part C157923
J7: LOOP; CONN-TH_7P-P2.00_S7B-PH-K-S-LF-SN; MPN S7B-PH-K-S(LF)(SN); LCSC Part C157917
J8: PLAY_CUE; CONN-TH_6P-P2.00_S6B-PH-K-S-LF-SN; MPN S6B-PH-K-S(LF)(SN); LCSC Part C157920
J9: TEMPO; CONN-TH_4P-P2.00_S4B-PH-K-S-LF-SN; MPN S4B-PH-K-S(LF)(SN); LCSC Part C157926
J10: JOG; CONN-TH_S5B-PH-K-S-LF-SN; MPN S5B-PH-K-S(LF)(SN); LCSC Part C157923
R1, R2, R7, R8, R9, R10, R11, R12, R13, R14, R15, R16, R18, R19, R20, R21, R22, R23, R24, R25, R26: 1KΩ ±1%; R0402; MPN 0402WGF1001TCE; LCSC Part C11702
R3, R5: 1.8KΩ ±1%; R0603; MPN 0603WAF1801T5E; LCSC Part C4177
R4, R6: 3.3KΩ ±1%; R0402; MPN 0402WGF3301TCE; LCSC Part C25890
R17: 10KΩ ±1%; R0402; MPN 0402WGF1002TCE; LCSC Part C25744
TP1: VBUS_S3; TestPoint_Pad_D2.5mm
TVS1, TVS2, TVS3, TVS4, TVS5, TVS6, TVS7, TVS8, TVS9: SRV05-4; SOT-23-6_L2.9-W1.6-P0.95-LS2.8-BL; MPN SRV05-4; LCSC Part C558418
U1: LOLIN_S3_Mini

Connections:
+3.3V: C1.2, C5.2, C8.2, J6.2, J7.1, J9.1, J10.3, R17.2, TVS1.5, TVS2.5, TVS3.5, TVS4.5, TVS5.5, TVS6.5, TVS7.5, TVS8.5, TVS9.5; also elsewhere on the board
+5V: C10.2, J1.1, J2.1, J3.1, J4.1, J8.1; also elsewhere on the board
/1BTNA_RX: R3.1, R4.2, TVS1.1, U1.24 (IO15)
/1BTNA_TX: R1.1, U1.22 (IO17)
/1BTNB_RX: R5.1, R6.2, TVS2.3, U1.4 (IO12/SCK)
/1BTNB_TX: R2.1, U1.5 (IO13/MISO)
/BTN_CUE: R21.1, U1.28 (IO35/SDA)
/BTN_PLAY: R18.1, U1.21 (IO21)
/ENC_CLK: C2.2, R12.1, U1.17 (IO33)
/ENC_DT: C4.2, R10.1, U1.18 (IO37)
/ENC_SW: C3.2, R9.1, U1.19 (IO38)
/JOG1: R25.1, U1.12 (IO6)
/JOG2: R24.1, U1.13 (IO7)
/JOG_TCH: C6.2, R17.1, R20.1, U1.6 (IO11/MOSI)
/LED_CUE: R22.1, U1.27 (IO36/SCL)
/LED_PLAY: R19.1, U1.29 (IO18)
/LOOP_END_BTN: R14.1, U1.7 (IO10)
/LOOP_END_LED: R15.1, U1.3 (IO4)
/LOOP_START_BTN: R11.1, U1.9 (IO1)
/LOOP_START_LED: R13.1, U1.2 (IO2)
/RAW_1BTNA_TX: J1.2, R1.2, TVS1.6
/RAW_1BTNB_TX: J4.2, R2.2, TVS2.4
/RAW_BTN_CUE: J8.4, R21.2, TVS9.4
/RAW_BTN_PLAY: J8.2, R18.2, TVS9.1
/RAW_ENC_CLK: J6.5, R12.2, TVS4.3
/RAW_ENC_DT: J6.4, R10.2, TVS4.1
/RAW_ENC_SW: J6.3, R9.2, TVS4.6
/RAW_JOG1: J10.5, R25.2, TVS7.3
/RAW_JOG2: J10.4, R24.2, TVS7.4
/RAW_JOG_TCH: J10.1, R20.2, TVS7.6
/RAW_LED_CUE: J8.5, R22.2, TVS9.6
/RAW_LED_PLAY: J8.3, R19.2, TVS9.3
/RAW_LOOP_END_BTN: J7.4, R14.2, TVS6.6
/RAW_LOOP_END_LED: J7.5, R15.2, TVS5.6
/RAW_LOOP_START_BTN: J7.2, R11.2, TVS6.3
/RAW_LOOP_START_LED: J7.3, R13.2, TVS6.4
/RAW_RELOOP_BTN: J7.6, R16.2, TVS5.1
/RAW_TEMPO_ADCT: J9.2, R26.2, TVS8.6
/RAW_TEMPO_ADIN: J9.3, R23.2, TVS8.1
/RAW_UART_RX_FROM_PI: J5.3, R8.2, TVS3.1
/RAW_UART_TX_TO_PI: J5.2, R7.2, TVS3.6
/RELOOP_BTN: R16.1, U1.11 (IO5)
/TEMPO_ADCT: C9.2, R26.1, U1.14 (IO8)
/TEMPO_ADIN: C7.1, R23.1, U1.15 (IO9)
/UART_RX_FROM_PI: R8.1, U1.26 (IO44/RX)
/UART_TX_TO_PI: R7.1, U1.25 (IO43/TX)
GND: C1.1, C2.1, C3.1, C4.1, C5.1, C6.1, C7.2, C8.1, C9.1, C10.1, J1.3, J2.3, J3.3, J4.3, J5.1, J5.4, J6.1, J7.7, J8.6, J9.4, J10.2, R4.1, R6.1, TVS1.2, TVS2.2, TVS3.2, TVS4.2, TVS5.2, TVS6.2, TVS7.2, TVS8.2, TVS9.2, U1.23 (GND), U1.31 (GND); also elsewhere on the board
unnamed: J2.2, R3.2
unnamed: J3.2, R5.2
S3_3.3V: U1.8 (3V3); also elsewhere on the board
S3_VBUS_5V: TP1.1 (1_1), U1.32 (VBUS); also elsewhere on the board

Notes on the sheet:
I burnt IO14 on some boards, so for flexibility I will not use it
The LED_* here are controlling a MOSFET 2N7000's gate on the other side. They operate at 3.3V. The BTN_* on the other side are just a 100nF debounce cap and they close to GND, so we pull them up to 3.3V. The 5V is to power the LED, and the MOSFET open/closes the GND path on the power.
S3 pin notes: IO14 --> I burnt down on some early chips, avoid if can IO3 --> strapping pin for JTAG it only does anything if you've burned the JTAG-select eFuse, so on a stock chip it's inert IO34 --> only free when the module uses quad flash/PSRAM; on octal parts (ESP32-S3R8) they're wired to the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
Optical enc is used to be +5V, just should run fine at +3.3V TCH is normally opened, and GND when closed. Closed it has a 33ohms R to GND
The OneButton's CH32V003 has LVTTL for pin voltage detection, so it can read 3.3V in. V_IH min is 2.06V when powered by 5V V_IL max is 1.09 V (low side) We're good sending it 3.3V TX, with margins
This comes back from the OneButton boards as 5V, and would fry the S3 so I have a divider down to 3.24V
This pinout matches the encoder's pinout if I mount a JST-PH angled on its bottom side. Enc is a KY-040
Pi's layout is: Function : GND | TX | RX GPIO : 8 | 10 | 12 Pi sends in 3.3V and receives ONLY 3.3V, so we natively good
Originally meant for 5V, but fully passive potentiometer, so works at 3.3V
Somehow 10k was out of stock. Went with 22k pullup. No noticeable impact in practice.

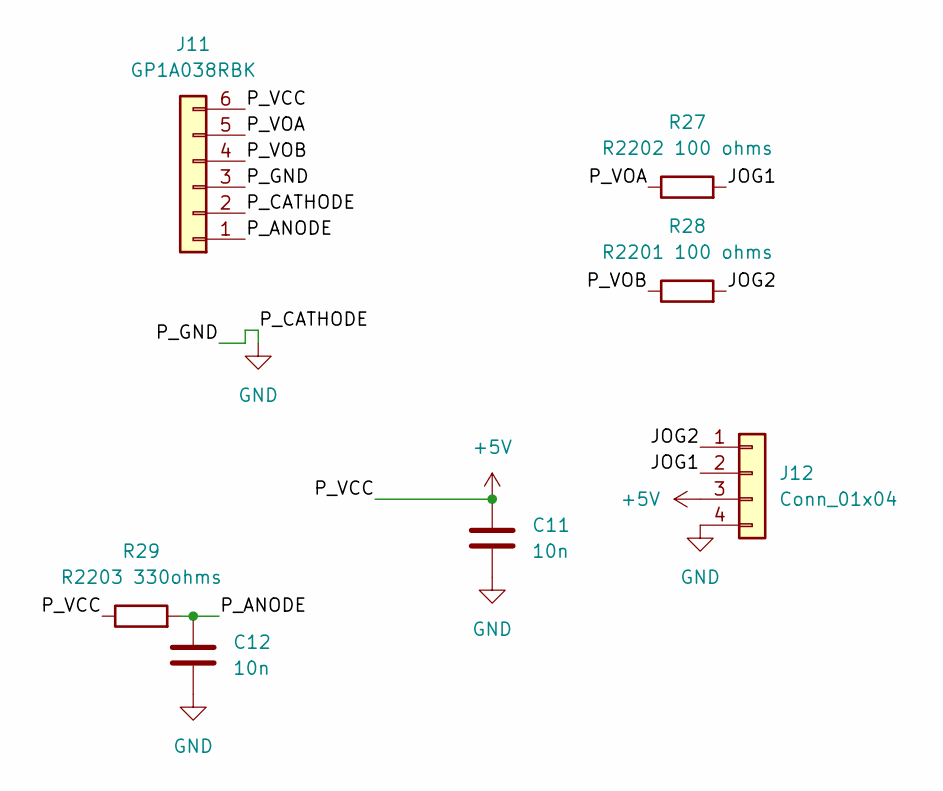
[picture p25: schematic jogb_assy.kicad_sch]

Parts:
C11, C12: 10n
J11: GP1A038RBK
J12: Conn_01x04
R27: R2202 100 ohms
R28: R2201 100 ohms
R29: R2203 330ohms

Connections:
unnamed: C11.1, J11.6, J12.3, R29.1
unnamed: C11.2, C12.2, J11.2, J11.3, J12.4
unnamed: C12.1, J11.1, R29.2
unnamed: J11.4, R28.1
unnamed: J11.5, R27.1
unnamed: J12.1, R28.2
unnamed: J12.2, R27.2

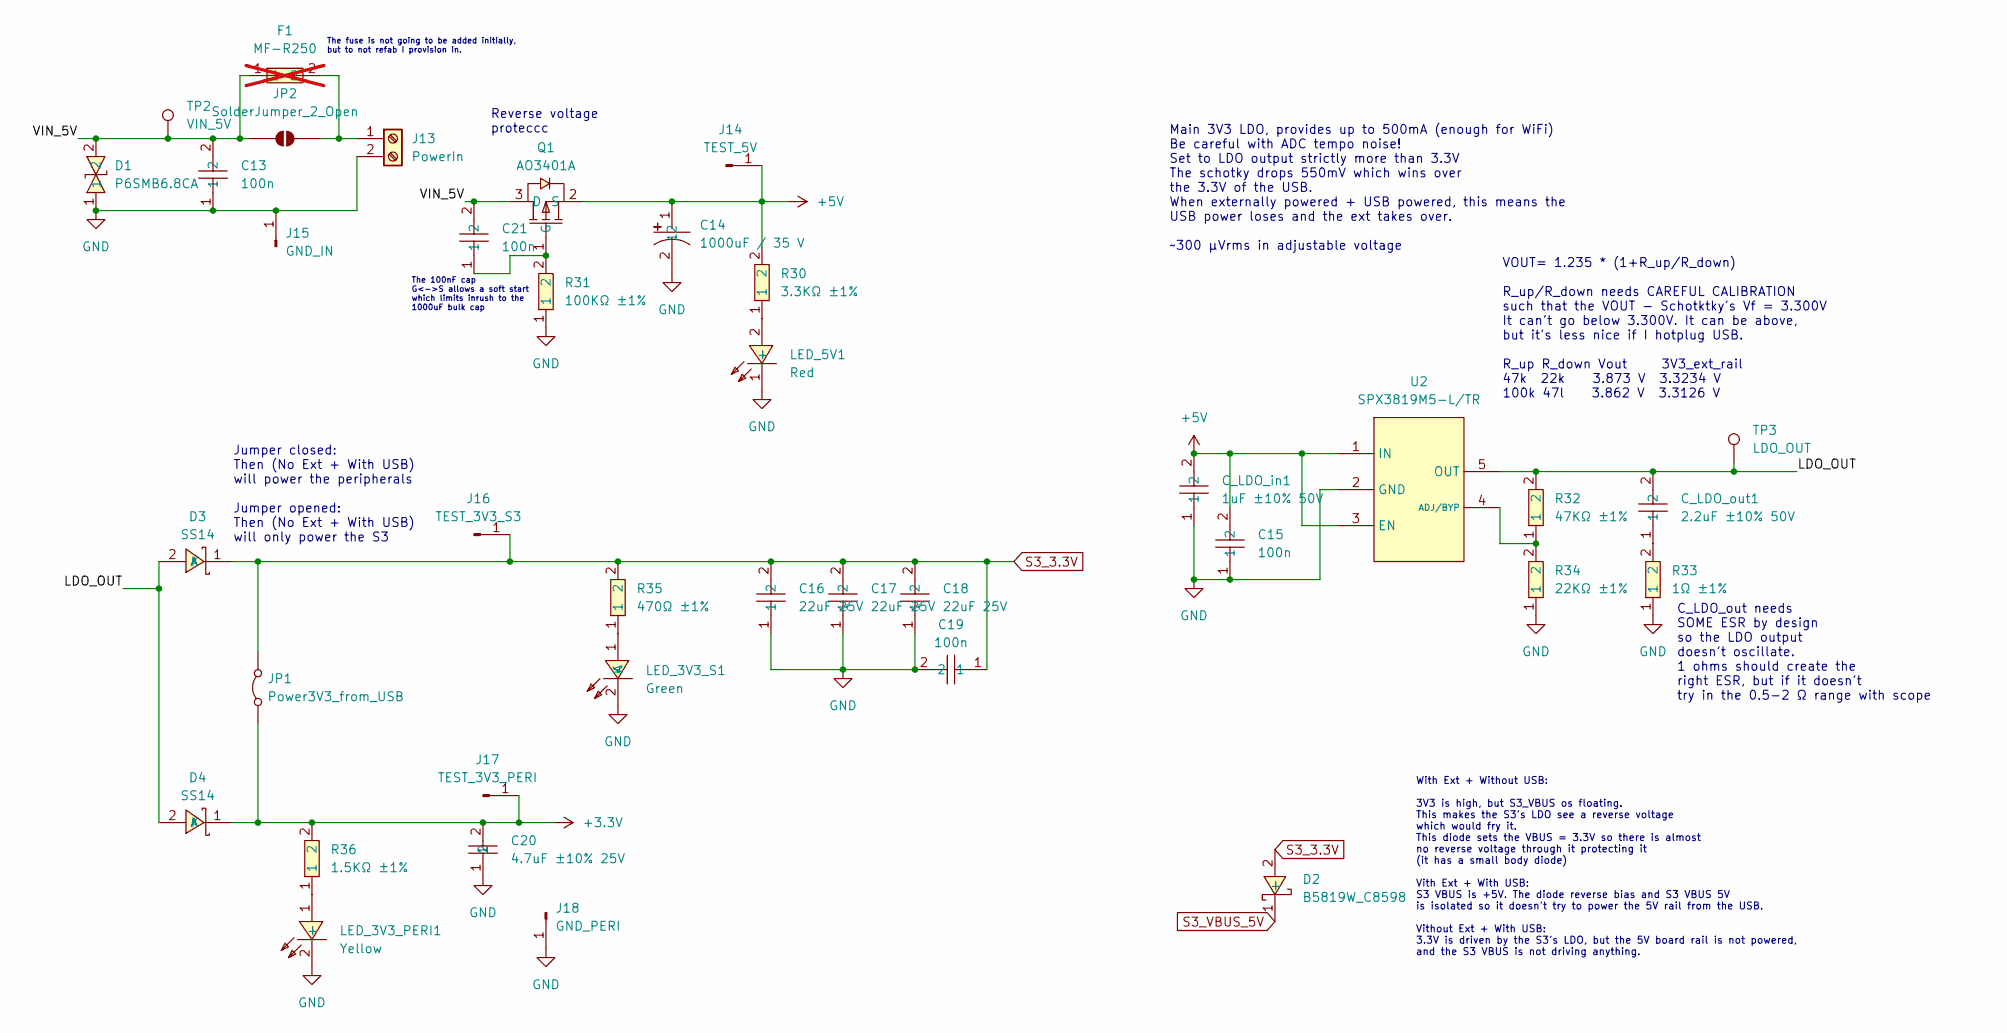
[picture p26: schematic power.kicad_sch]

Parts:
C13, C15, C19, C21: 100n; C0402; MPN CL05B104KB54PNC; LCSC Part C307331
C14: 1000uF / 35 V; CAP-TH_BD10.0-P5.00-D1.0-FD; MPN ERR1VM102G20OT; LCSC Part C398835
C16, C17, C18: 22uF 25V; C0805; MPN CL21A226MAQNNNE; LCSC Part C45783
C20: 4.7uF ±10% 25V; C0805; MPN CL21A475KAQNNNE; LCSC Part C1779
C_LDO_in1: 1uF ±10% 50V; C0603; MPN CL10A105KB8NNNC; LCSC Part C15849
C_LDO_out1: 2.2uF ±10% 50V; C0805; MPN CL21A225KBQNNNE; LCSC Part C377773
D1: P6SMB6.8CA; SMB_L4.6-W3.6-LS5.3-BI; MPN P6SMB6.8CA/TR13; LCSC Part C78395
D2: B5819W_C8598; SOD-123_L2.7-W1.6-LS3.7-RD-1; MPN B5819W SL; LCSC Part C8598
D3, D4: SS14; SMA_L4.2-W2.6-LS5.0-RD_1; MPN SS14; LCSC Part C2480
F1: MF-R250; FUSE-TH_L12.8-W3.0-P5.80-D1.2-S2.20; MPN MF-R250; LCSC Part C208486; not fitted
J13: PowerIn; Altech_AK300_1x02_P5.00mm_45-Degree
J14: TEST_5V; PinHeader_1x01_P2.54mm_Vertical
J15: GND_IN; PinHeader_1x01_P2.54mm_Vertical
J16: TEST_3V3_S3; PinHeader_1x01_P2.54mm_Vertical
J17: TEST_3V3_PERI; PinHeader_1x01_P2.54mm_Vertical
J18: GND_PERI; PinHeader_1x01_P2.54mm_Vertical
JP1: Power3V3_from_USB; PinHeader_1x02_P2.54mm_Vertical
JP2: SolderJumper_2_Open; SolderJumper-2_P1.3mm_Open_TrianglePad1.0x1.5mm
LED_3V3_PERI1: Yellow; LED0805-R-RD; MPN KT-0805黄灯; LCSC Part C2296
LED_3V3_S1: Green; LED0805-R-RD; MPN KT-0805G; LCSC Part C2297
LED_5V1: Red; LED0805-RD; MPN NCD0805R1; LCSC Part C84256
Q1: AO3401A; SOT-23_L2.9-W1.3-P1.90-LS2.4-BR; MPN AO3401A; LCSC Part C15127
R30: 3.3KΩ ±1%; R0402; MPN 0402WGF3301TCE; LCSC Part C25890
R31: 100KΩ ±1%; R0603; MPN 0603WAF1003T5E; LCSC Part C25803
R32: 47KΩ ±1%; R0402; MPN 0402WGF4702TCE; LCSC Part C25792
R33: 1Ω ±1%; R0402; MPN 0402WGF100KTCE; LCSC Part C25086
R34: 22KΩ ±1%; R0402; MPN 0402WGF2202TCE; LCSC Part C25768
R35: 470Ω ±1%; R0402; MPN 0402WGF4700TCE; LCSC Part C25117
R36: 1.5KΩ ±1%; R0402; MPN 0402WGF1501TCE; LCSC Part C25867
TP2: VIN_5V; TestPoint_Pad_D2.5mm
TP3: LDO_OUT; TestPoint_Pad_D2.5mm
U2: SPX3819M5-L/TR; SOT-23-5_L3.0-W1.7-P0.95-LS2.8-TL; MPN SPX3819M5-L/TR; LCSC Part C9056

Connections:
+3.3V: C20.2, D4.1 (K), J17.1 (Pin_1_1), JP1.1 (A), R36.2; also elsewhere on the board
+5V: C14.1, C15.2, C_LDO_in1.2, J14.1 (Pin_1_1), Q1.2 (S), R30.2, U2.1 (IN), U2.3 (EN); also elsewhere on the board
/Power/LDO_OUT: C_LDO_out1.2, D3.2 (A), D4.2 (A), R32.2, TP3.1 (1_1), U2.5 (OUT)
/Power/VIN_5V: C13.2, C21.2, D1.2, F1.1, JP2.1 (A), Q1.3 (D), TP2.1 (1_1)
GND: C13.1, C14.2, C15.1, C16.1, C17.1, C18.1, C19.2, C20.1, C_LDO_in1.1, D1.1, J13.2, J15.1 (Pin_1_1), J18.1 (Pin_1_1), LED_3V3_PERI1.2 (-), LED_3V3_S1.2 (K), LED_5V1.1 (-), R31.1, R33.1, R34.1, U2.2 (GND); also elsewhere on the board
unnamed: C_LDO_out1.1, R33.2
unnamed: F1.2, J13.1, JP2.2 (B)
unnamed: LED_3V3_PERI1.1 (+), R36.1
unnamed: LED_3V3_S1.1 (A), R35.1
unnamed: LED_5V1.2 (+), R30.1
unnamed: C21.1, Q1.1 (G), R31.2
unnamed: R32.1, R34.2, U2.4 (ADJ/BYP)
S3_3.3V: C16.2, C17.2, C18.2, C19.1, D2.2 (+), D3.1 (K), J16.1 (Pin_1_1), JP1.2 (B), R35.2; also elsewhere on the board
S3_VBUS_5V: D2.1 (-); also elsewhere on the board

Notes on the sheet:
The 100nF cap G<->S allows a soft start which limits inrush to the 1000uF bulk cap
With Ext + Without USB: 3V3 is high, but S3_VBUS os floating. This makes the S3's LDO see a reverse voltage which would fry it. This diode sets the VBUS = 3.3V so there is almost no reverse voltage through it protecting it (it has a small body diode) Vith Ext + With USB: S3 VBUS is +5V. The diode r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
Jumper closed: Then (No Ext + With USB) will power the peripherals Jumper opened: Then (No Ext + With USB) will only power the S3
VOUT= 1.235 * (1+R_up/R_down) R_up/R_down needs CAREFUL CALIBRATION such that the VOUT - Schotktky's Vf = 3.300V It can't go below 3.300V. It can be above, but it's less nice if I hotplug USB. R_up R_down Vout 3V3_ext_rail 47k 22k 3.873 V 3.3234 V 100k 47l 3.862 V 3.3126 V
C_LDO_out needs SOME ESR by design so the LDO output doesn't oscillate. 1 ohms should create the right ESR, but if it doesn't try in the 0.5-2 Ω range with scope
Reverse voltage proteccc
Main 3V3 LDO, provides up to 500mA (enough for WiFi) Be careful with ADC tempo noise! Set to LDO output strictly more than 3.3V The schotky drops 550mV which wins over the 3.3V of the USB. When externally powered + USB powered, this means the USB power loses and the ext takes over. ~300 µVrms in ad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
The fuse is not going to be added initially, but to not refab I provision in.

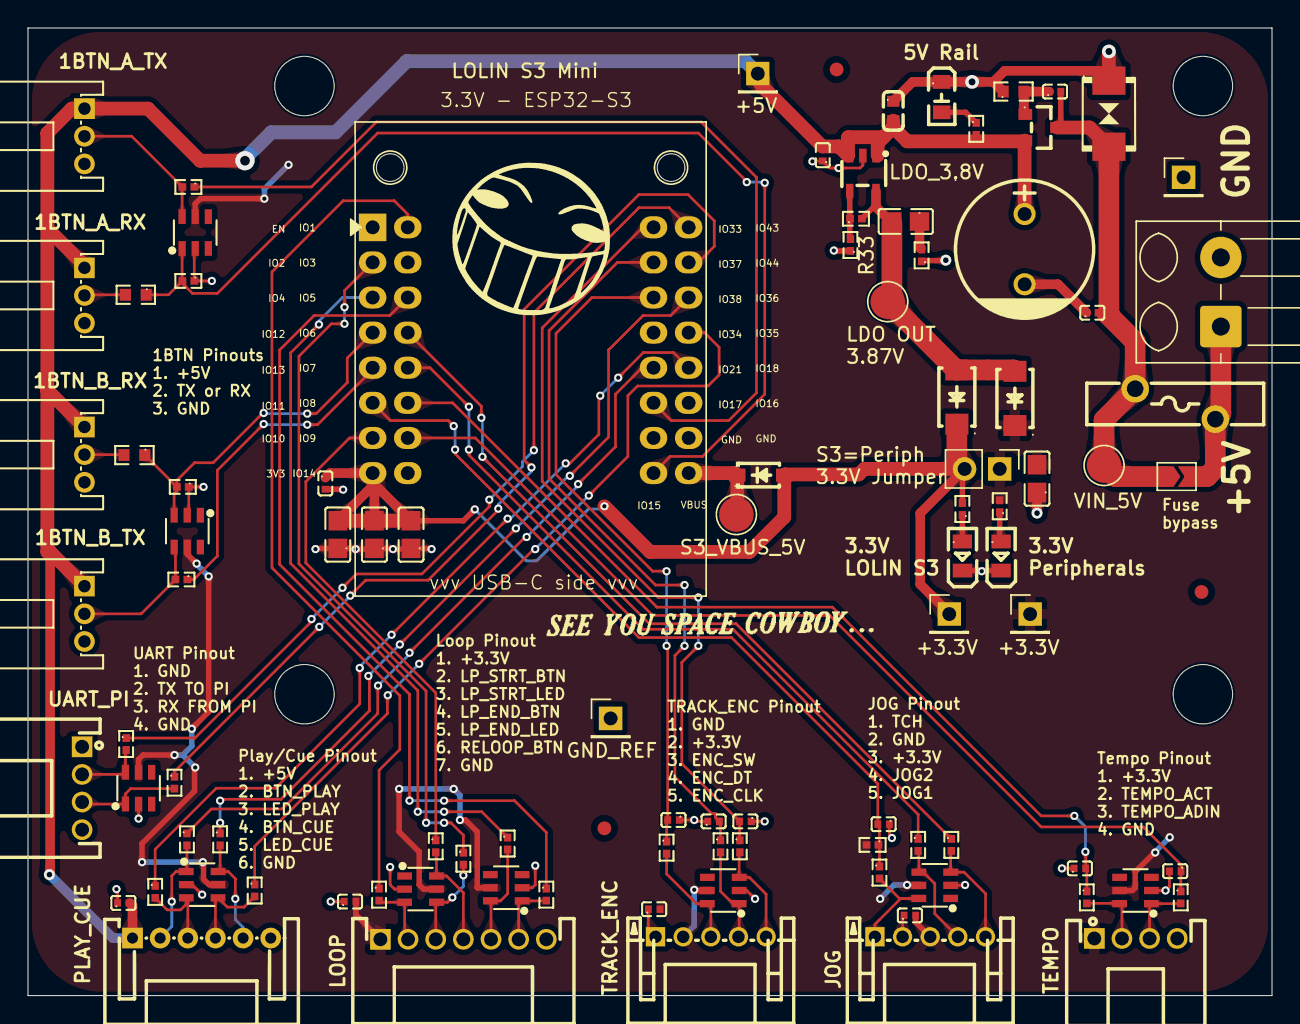
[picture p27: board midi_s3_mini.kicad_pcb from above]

Board: 2 copper layers, 90.0 x 70.0 mm, 102 parts (0 on the bottom side), 60 nets.

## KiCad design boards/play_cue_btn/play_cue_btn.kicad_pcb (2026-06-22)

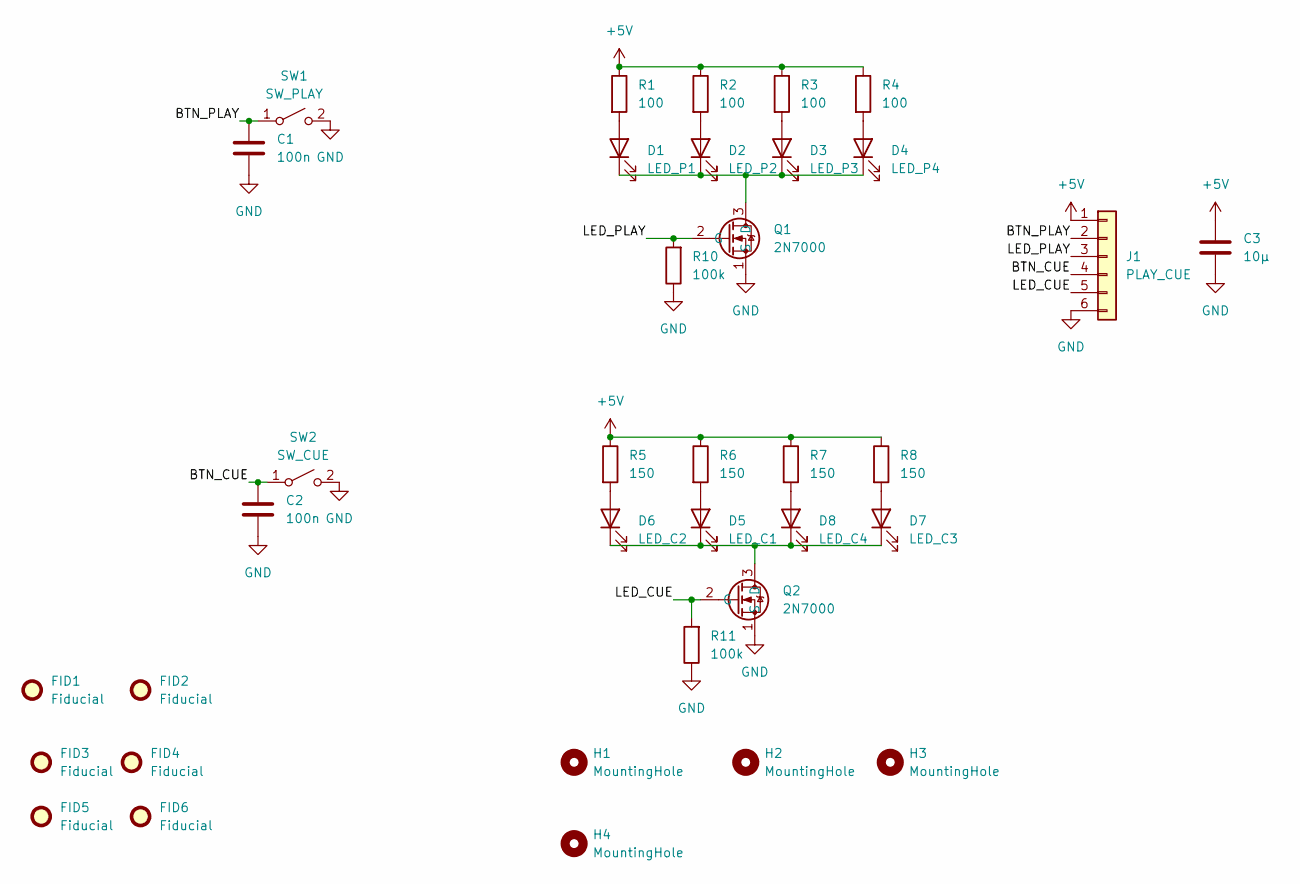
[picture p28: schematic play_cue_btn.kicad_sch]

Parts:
C1, C2: 100n; C_Disc_D5.0mm_W2.5mm_P5.00mm
C3: 10µ; C_Disc_D5.0mm_W2.5mm_P5.00mm
D1: LED_P1; LED_D5.0mm
D2: LED_P2; LED_D5.0mm
D3: LED_P3; LED_D5.0mm
D4: LED_P4; LED_D5.0mm
D5: LED_C1; LED_D5.0mm
D6: LED_C2; LED_D5.0mm
D7: LED_C3; LED_D5.0mm
D8: LED_C4; LED_D5.0mm
FID1, FID2, FID3, FID4, FID5, FID6: Fiducial; Fiducial_Cross_1.5mm_Mask2mm
H1, H2, H3, H4: MountingHole; MountingHole_3.2mm_M3
J1: PLAY_CUE; JST_PH_B6B-PH-K_1x06_P2.00mm_Vertical
Q1, Q2: 2N7000; TO-92_Inline
R1, R2, R3, R4: 100; R_Axial_DIN0207_L6.3mm_D2.5mm_P7.62mm_Horizontal
R5, R6, R7, R8: 150; R_Axial_DIN0207_L6.3mm_D2.5mm_P7.62mm_Horizontal
R10, R11: 100k; R_Axial_DIN0207_L6.3mm_D2.5mm_P7.62mm_Horizontal
SW1: SW_PLAY; SW_PUSH_6mm_H4.3mm
SW2: SW_CUE; SW_PUSH_6mm_H4.3mm

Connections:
+5V: C3.1, J1.1, R1.1, R2.1, R3.1, R4.1, R5.1, R6.1, R7.1, R8.1
/BTN_CUE: C2.1, J1.4, SW2.1 (A)
/BTN_PLAY: C1.1, J1.2, SW1.1 (A)
/LED_CUE: J1.5, Q2.2 (G), R11.2
/LED_PLAY: J1.3, Q1.2 (G), R10.2
GND: C1.2, C2.2, C3.2, J1.6, Q1.1 (S), Q2.1 (S), R10.1, R11.1, SW1.2 (B), SW2.2 (B)
unnamed: D1.2 (A), R1.2
unnamed: D1.1 (K), D2.1 (K), D3.1 (K), D4.1 (K), Q1.3 (D)
unnamed: D2.2 (A), R2.2
unnamed: D3.2 (A), R3.2
unnamed: D4.2 (A), R4.2
unnamed: D5.2 (A), R6.2
unnamed: D5.1 (K), D6.1 (K), D7.1 (K), D8.1 (K), Q2.3 (D)
unnamed: D6.2 (A), R5.2
unnamed: D7.2 (A), R8.2
unnamed: D8.2 (A), R7.2

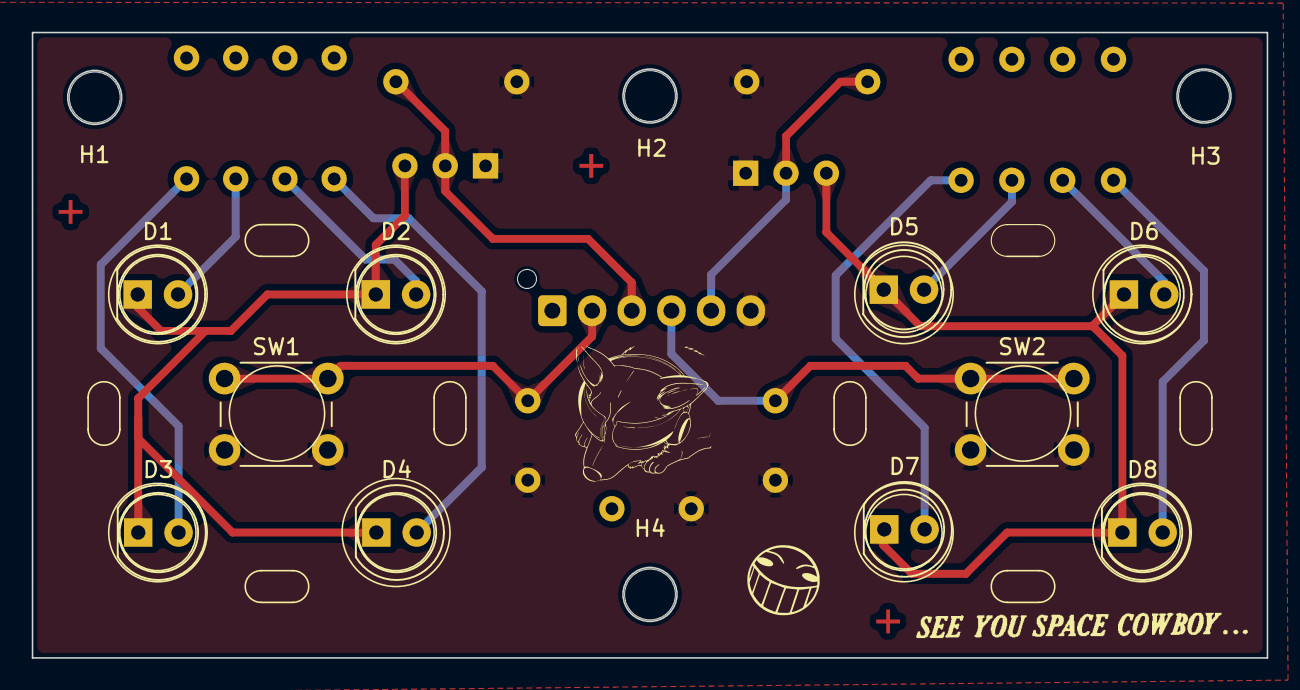
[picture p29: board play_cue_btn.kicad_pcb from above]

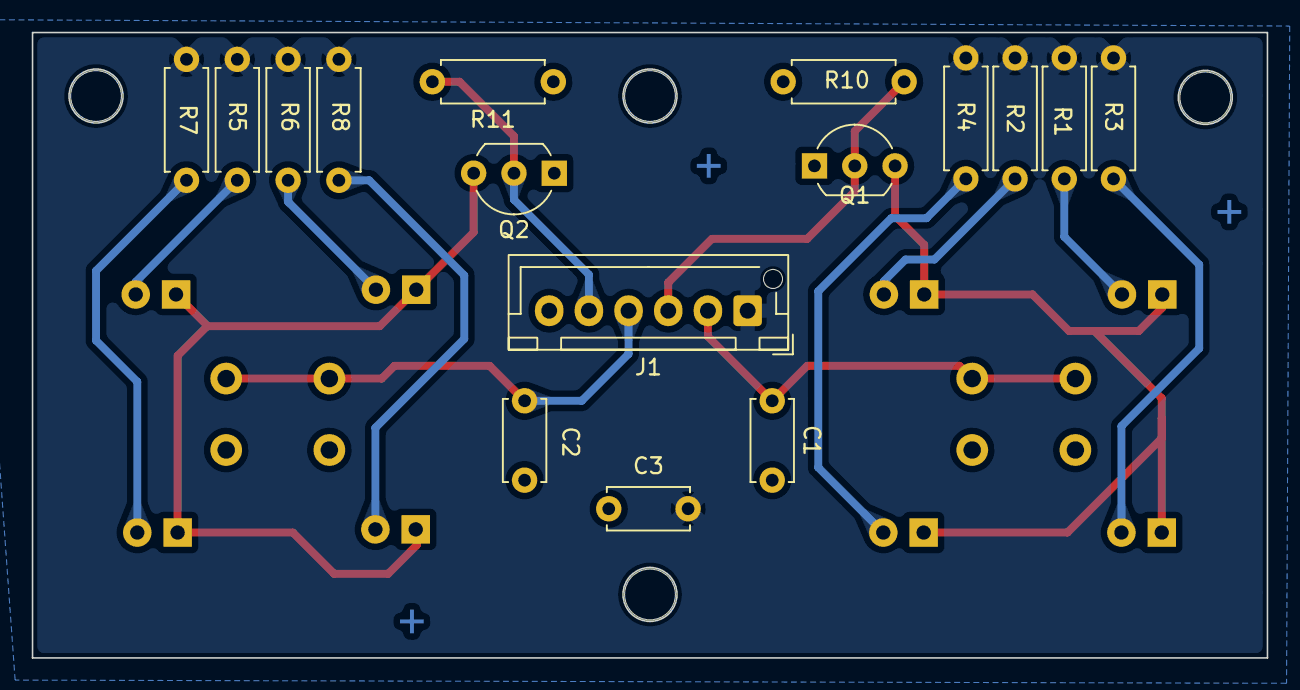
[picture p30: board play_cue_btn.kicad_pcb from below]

Board: 2 copper layers, 77.8 x 39.4 mm, 36 parts (19 on the bottom side), 16 nets.

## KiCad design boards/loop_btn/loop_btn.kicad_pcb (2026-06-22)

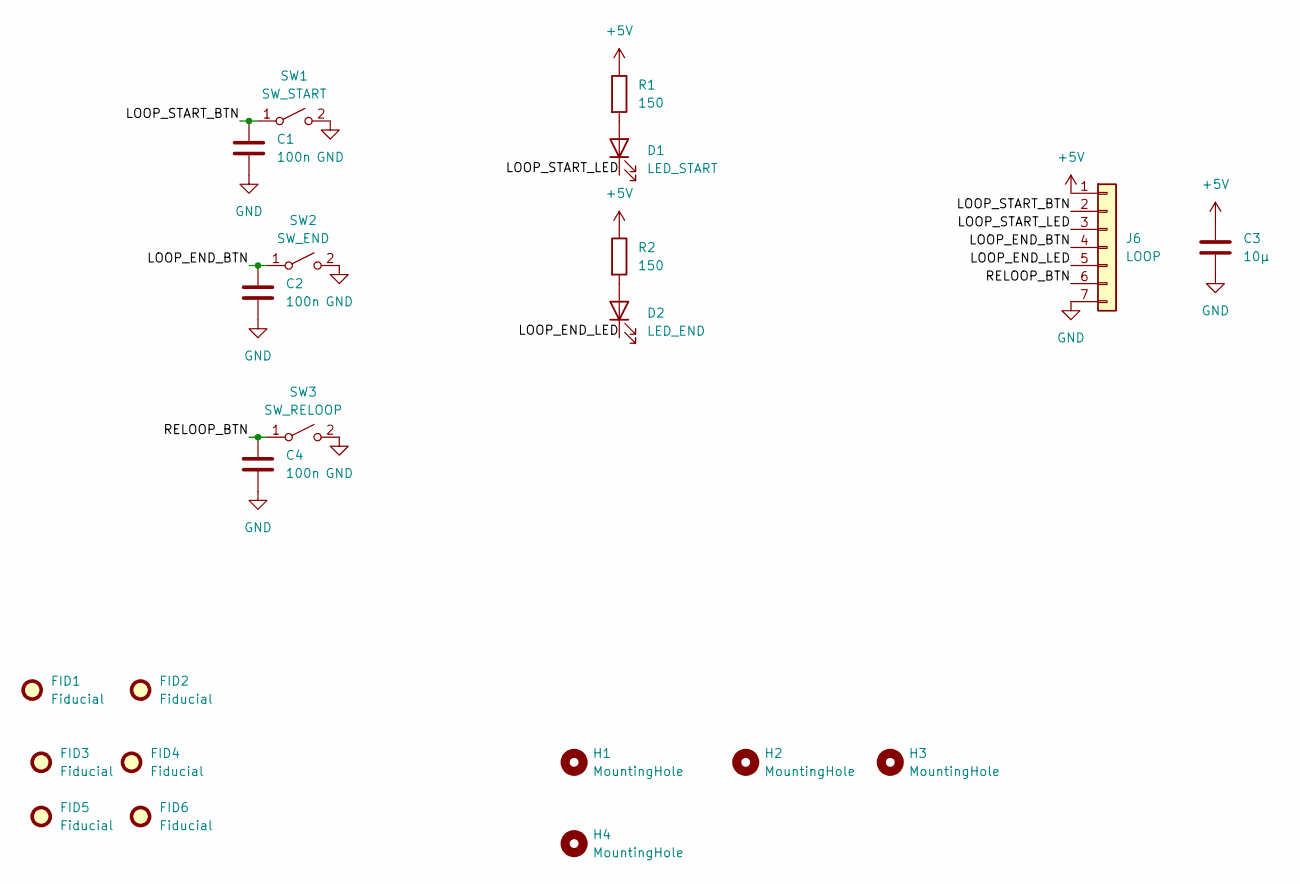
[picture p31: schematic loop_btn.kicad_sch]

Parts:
C1, C2, C4: 100n; C_Disc_D5.0mm_W2.5mm_P5.00mm
C3: 10µ; C_Disc_D5.0mm_W2.5mm_P5.00mm
D1: LED_START; LED_D5.0mm
D2: LED_END; LED_D5.0mm
FID1, FID2, FID3, FID4, FID5, FID6: Fiducial; Fiducial_Cross_1.5mm_Mask2mm
H1, H2, H3, H4: MountingHole; MountingHole_3.2mm_M3
J6: LOOP; JST_XH_B7B-XH-AM_1x07_P2.50mm_Vertical
R1, R2: 150; R_Axial_DIN0207_L6.3mm_D2.5mm_P7.62mm_Horizontal
SW1: SW_START; SW_PUSH_6mm_H4.3mm
SW2: SW_END; SW_PUSH_6mm_H4.3mm
SW3: SW_RELOOP; SW_PUSH_6mm_H4.3mm

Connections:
+5V: C3.1, J6.1, R1.1, R2.1
/LOOP_END_BTN: C2.1, J6.4, SW2.1 (A)
/LOOP_END_LED: D2.1 (K), J6.5
/LOOP_START_BTN: C1.1, J6.2, SW1.1 (A)
/LOOP_START_LED: D1.1 (K), J6.3
/RELOOP_BTN: C4.1, J6.6, SW3.1 (A)
GND: C1.2, C2.2, C3.2, C4.2, J6.7, SW1.2 (B), SW2.2 (B), SW3.2 (B)
unnamed: D1.2 (A), R1.2
unnamed: D2.2 (A), R2.2

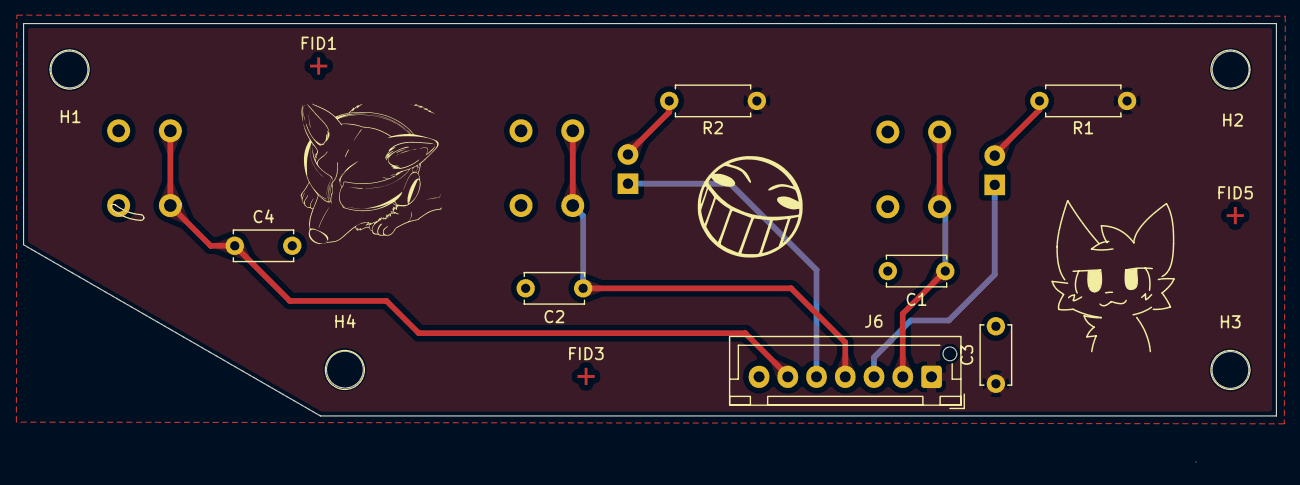
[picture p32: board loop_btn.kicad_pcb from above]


Board: 2 copper layers, 109.0 x 34.1 mm, 22 parts (8 on the bottom side), 9 nets.

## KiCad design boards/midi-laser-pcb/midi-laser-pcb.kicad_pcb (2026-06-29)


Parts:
C1, C2, C3, C4, C5: 100nF; C_Disc_D5.0mm_W2.5mm_P5.00mm
H1, H2, H3, H4: MountingHole; MountingHole_3.2mm_M3
J1: Jogwheel; JST_PH_B5B-PH-K_1x05_P2.00mm_Vertical
J2: UART_PI; JST_PH_B3B-PH-K_1x03_P2.00mm_Vertical
J3: PLAY_CUE; JST_PH_B6B-PH-K_1x06_P2.00mm_Vertical
J4: TRACK_ENCODER; JST_PH_B6B-PH-K_1x06_P2.00mm_Vertical
J5: LOOP_SIZE; JST_PH_B4B-PH-K_1x04_P2.00mm_Vertical
J6: LOOP; JST_PH_B7B-PH-K_1x07_P2.00mm_Vertical
J7: TEMPO; JST_PH_B4B-PH-K_1x04_P2.00mm_Vertical
J8: I2C; JST_PH_B4B-PH-K_1x04_P2.00mm_Vertical
R1, R2, R3, R5: 4.7k; R_Axial_DIN0207_L6.3mm_D2.5mm_P10.16mm_Horizontal
R4, R6: 10k; R_Axial_DIN0207_L6.3mm_D2.5mm_P10.16mm_Horizontal
SW1: Arduino_RST; SW_PUSH_6mm
U1: ProMicro; ArduinoProMicro
U2: MCP23017x-x-SP; DIP-28_W7.62mm

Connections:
+5V: C1.2, C2.2, J1.1, J3.1, J4.1, J5.1, J6.1, J7.1, J8.1, R1.1, R2.1, R5.1, R6.1, U1.21 (VCC), U2.9 (V_{DD})
/BACK_BTN: J4.2, U1.13 (10/PB6)
/BTN_CUE: J3.4, U2.26 (GPA5)
/BTN_PLAY: J3.2, U2.25 (GPA4)
/ENC_CLK: J4.3, U1.7 (4/PD4)
/ENC_DT: J4.4, U1.8 (5/PC6)
/ENC_SW: J4.5, U1.9 (6/PD7)
/I2C_SCL: J8.3, R2.2, U1.6 (3/PD0), U2.12 (SCK)
/I2C_SDA: J8.2, R1.2, U1.5 (2/PD1), U2.13 (SDA)
/JOG1: J1.2, U1.11 (8/PB4)
/JOG2: J1.3, U1.12 (9/PB5)
/LED_CUE: J3.5, U2.4 (GPB3)
/LED_PLAY: J3.3, U2.3 (GPB2)
/LOOP_DBL_BTN: J5.3, U2.24 (GPA3)
/LOOP_END_BTN: J6.4, U2.22 (GPA1)
/LOOP_END_LED: J6.5, U2.2 (GPB1)
/LOOP_HLF_BTN: J5.2, U2.23 (GPA2)
/LOOP_START_BTN: J6.2, U2.21 (GPA0)
/LOOP_START_LED: J6.3, U2.1 (GPB0)
/RELOOP_BTN: J6.6, U2.27 (GPA6)
/TCH: J1.4, R5.2, U1.10 (7/PE6)
/TEMPO_ADCT: C3.2, J7.3, U1.18 (A1/PF6)
/TEMPO_ADIN: C4.2, J7.2, U1.17 (A0/PF7)
/UART_RX_FROM_PI: J2.3, U1.2 (RX1/PD2)
/UART_TX_TO_PI: J2.2, R3.1, R4.1
GND: C1.1, C2.1, C3.1, C4.1, C5.1, J1.5, J2.1, J3.6, J4.6, J5.4, J6.7, J7.4, J8.4, R4.2, SW1.2, U1.3 (GND), U1.4 (GND), U1.23 (GND), U2.10 (V_{SS}), U2.15 (A0), U2.16 (A1), U2.17 (A2)
unnamed: C5.2, SW1.1, U1.22 (RST)
unnamed: R3.2, U1.1 (TX0/PD3)
unnamed: R6.2, U2.18 (~RESET)

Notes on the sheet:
Crossover is IN THE CABLE, NOT THE BOARD!


Board: 2 copper layers, 80.0 x 60.0 mm, 26 parts (0 on the bottom side), 29 nets.

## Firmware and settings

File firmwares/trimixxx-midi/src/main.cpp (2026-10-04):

#include <Arduino.h>
#include <esp_system.h>
#include <string.h>
#include "OneButtonRing.hpp"
#include "PiLink.hpp"
#include "JogWheel.hpp"
#include "TempoFader.hpp"
#include "TrackEncoder.hpp"
#include "PlayCueBoard.hpp"
#include "LoopBoard.hpp"
#include "MidiMap.hpp"

// ===========================================================================
//  TriMixxx S3 master
//
//  UART allocation on the ESP32-S3:
//    UART0 (Serial0) -> Raspberry Pi   (IO43 TX, IO44 RX)  -- MIDI, 3.3V
//    UART1 (Serial1) -> OneButton ring A                   -- 5V, needs shifter
//    UART2 (Serial2) -> OneButton ring B  (IO13 TX, IO12 RX)  -- 5V, needs shifter
//
//  Every control has a driver: ring pads, jog, tempo, track encoder, play/cue,
//  loop. main wires them to MIDI; each module self-tests via debug() (below).
// ===========================================================================

// ===========================================================================
//  DECK_DEBUG: 1 = run each module's self-test in loop() instead of sending
//  MIDI -- ring railroad + magenta, board LED flash (solid while pressed),
//  jog/tempo/encoder serial reports. 0 = normal deck operation.
// ===========================================================================
#define DECK_DEBUG 0

// ---- Ring A ---------------------------------------------------------------
#define RING_A_TX 17
#define RING_A_RX 15
#define RING_A_NODES 50
OneButtonRing ringA(Serial1, RING_A_TX, RING_A_RX, RING_A_NODES, 500000,
                    /*core=*/0); // 500 kbps: MUST match the node firmware

// ---- Ring B (UART2) -------------------------------------------------------
#define RING_B_TX 13
#define RING_B_RX 12
#define RING_B_NODES 50
OneButtonRing ringB(Serial2, RING_B_TX, RING_B_RX, RING_B_NODES, 500000,
                    /*core=*/0); // shares core 0 with ring A; both block on UART + yield
// Ring B pads/LEDs are on the MIDI bus like ring A: pad notes at PAD_B_BASE, and
// RGB via SysEx cmd 0x03. The Mixxx mapping must add matching addresses.

// ---- Pi MIDI link on UART0 ------------------------------------------------
#define PI_TX 43
#define PI_RX 44
PiLink pi(Serial0, PI_TX, PI_RX, 115200);

// ---- Jog wheel (PCNT quad + touch) ----------------------------------------
#define JOG_A 6
#define JOG_B 7
#define JOG_TCH 11
// Touch is active-low (built in). Encoder needs no pull (OPIC drives it);
// set encoderPullup=true only as insurance against phantom counts if the
// jog cable is ever unplugged.
JogWheel jog(JOG_A, JOG_B, JOG_TCH, /*encoderPullup=*/false);

// ---- Tempo fader (ratiometric: center tap + wiper, both ADC1) --------------
// Wired inverted on this deck (high end = slow), so invert=true. Bench-measured
// offsets: top = -1944, bottom = +2150 (center tap is off electrical mid, hence
// the asymmetric per-side spans).
#define TEMPO_ADCT 8
#define TEMPO_ADIN 9
TempoFader tempo(TEMPO_ADCT, TEMPO_ADIN, /*spanToMax=*/1944, /*spanToMin=*/2150, /*invert=*/true);

// ---- Track encoder (KY-040 mechanical: CLK/DT/SW) --------------------------
#define ENC_CLK 33
#define ENC_DT 37
#define ENC_SW 38
TrackEncoder trackEnc(ENC_CLK, ENC_DT, ENC_SW);

// ---- Play/cue + loop boards (direct GPIO; pins baked into the drivers) ------
PlayCueBoard playCue;
LoopBoard    loopBoard;

static bool padPendingOff[RING_A_NODES]  = {false};
static bool padPendingOffB[RING_B_NODES] = {false};

// -------- incoming MIDI from Mixxx -> LEDs (Mixxx owns LED state) ----------
static void onMidiFromMixxx(uint8_t status, uint8_t d1, uint8_t d2, void* ctx) {
    uint8_t type = status & 0xF0;
    if (type == 0x90 && d1 >= midimap::PAD_A_BASE && d1 < midimap::PAD_A_BASE + RING_A_NODES) {
        uint8_t pad = d1 - midimap::PAD_A_BASE;
        ringA.setLed(pad, 0, d2, d2, d2); // velocity = white brightness
        return;
    }
    if (type == 0x90 && d1 >= midimap::PAD_B_BASE && d1 < midimap::PAD_B_BASE + RING_B_NODES) {
        uint8_t pad = d1 - midimap::PAD_B_BASE;
        ringB.setLed(pad, 0, d2, d2, d2); // velocity = white brightness
        return;
    }
    // Play/cue + loop LEDs: Note-On velocity>0 = on, Note-Off (or vel 0) = off.
    if (type == 0x90 || type == 0x80) {
        const bool on = (type == 0x90 && d2 > 0);
        switch (d1) {
        case midimap::NOTE_PLAY: playCue.setLed(PlayCueBoard::PLAY, on); break;
        case midimap::NOTE_CUE: playCue.setLed(PlayCueBoard::CUE, on); break;
        case midimap::NOTE_LOOP_IN: loopBoard.setLed(LoopBoard::LOOP_START, on); break;
        case midimap::NOTE_LOOP_OUT: loopBoard.setLed(LoopBoard::LOOP_END, on); break;
        case midimap::NOTE_RELOOP: loopBoard.setLed(LoopBoard::RELOOP, on); break; // no LED
        default: break;
        }
    }
}

// -------- incoming SysEx from Mixxx ---------------------------------------
//  F0 SYSEX_MFR_ID CMD <args...> F7  (payload here has the markers stripped).
//  See MidiMap.hpp for the layouts. Colour channels arrive as nibble pairs so
//  each one keeps its full 0..255 range despite SysEx's 7-bit data limit.
static inline uint8_t nib(const uint8_t* p) { return (uint8_t)((p[0] << 4) | (p[1] & 0x0F)); }

// Apply a ring-LED SysEx (cmd 0x01 = ring A, 0x03 = ring B) to one ring. args[0]
// = node; then colour nibble-pairs R,G,B -- 6 args = one colour on both LEDs, 12
// = LED0 then LED1 independently. Wrong length or node out of range = ignored.
static void applyRingLed(OneButtonRing& ring, uint8_t maxNodes, const uint8_t* args, uint8_t n) {
    if (n != midimap::SYSEX_RING_LED_ARGS_ONE && n != midimap::SYSEX_RING_LED_ARGS_TWO) return;
    const uint8_t node = args[0];
    if (node >= maxNodes) return;
    const uint8_t r1 = nib(args + 1), g1 = nib(args + 3), b1 = nib(args + 5);
    ring.setLed(node, 0, r1, g1, b1);
    if (n == midimap::SYSEX_RING_LED_ARGS_ONE) ring.setLed(node, 1, r1, g1, b1); // mirror onto LED1
    else ring.setLed(node, 1, nib(args + 7), nib(args + 9), nib(args + 11));
}

// Set by a fader-report SysEx, consumed where the fader is sent. Both run on
// loop()'s thread (pi.poll() delivers SysEx), so a plain flag is enough.
static bool tempoReportRequested = false;

static void onSysExFromMixxx(const uint8_t* payload, uint8_t len, void* ctx) {
    if (len < 2 || payload[0] != midimap::SYSEX_MFR_ID) return; // not ours
    const uint8_t  cmd  = payload[1];
    const uint8_t* args = payload + 2;
    const uint8_t  n    = len - 2;

    switch (cmd) {
    case midimap::SYSEX_CMD_RING_LED: applyRingLed(ringA, RING_A_NODES, args, n); return;
    case midimap::SYSEX_CMD_RING_B_LED: applyRingLed(ringB, RING_B_NODES, args, n); return;
    case midimap::SYSEX_CMD_FADER_REPORT: tempoReportRequested = true; return;
    case midimap::SYSEX_CMD_RESET: {
        // Magic-gated so a stray/corrupt SysEx can never reboot the deck mid-set.
        if (n != sizeof(midimap::SYSEX_RESET_MAGIC)) return;
        if (memcmp(args, midimap::SYSEX_RESET_MAGIC, n) != 0) return;
        Serial.println("SysEx reset -> rebooting");
        Serial.flush();
        Serial0.flush(); // let any in-flight MIDI out before the UART dies
        delay(50);
        esp_restart(); // same effect as the RESET button; does not return
        return;
    }
    default: return;
    }
}

// Periodic button sampling: poll+debounce+latch both boards every BTN_POLL_MS on
// a task pinned to core 1 (off the ring's core 0). Deterministic and independent
// of loop() load; a debounced press is latched so it is never missed.
static constexpr uint32_t BTN_POLL_MS = 2;
static void               buttonPollTask(void*) {
    for (;;) {
        playCue.poll();
        loopBoard.poll();
        vTaskDelay(pdMS_TO_TICKS(BTN_POLL_MS));
    }
}

// The tempo read is ~2ms of oversampled analogRead -- far too heavy for core 1's
// free-running loop, where it throttled the 300us jog to ~2ms. Run it in its own
// task pinned to CORE 0 (the ring's core, which mostly blocks on UART and yields
// every pass) at a priority BELOW the ring (5), so it fills core-0 slack and
// never touches core 1. loop() just consumes the latched value/changed().
static void tempoPollTask(void*) {
    for (;;) {
        tempo.poll();
        vTaskDelay(pdMS_TO_TICKS(4)); // ~6ms cadence (poll ~2ms + 4ms) -- ample for a fader
    }
}

// Ring pads -> MIDI: Note-On on a latched press, Note-Off when released. Nodes
// past the ring's enumerated count read !pressed/!level, so unused pads never
// fire. Shared by both rings; each has its own note base + pending array.
static void ringPadsToMidi(OneButtonRing& ring, uint8_t base, uint8_t count, bool* pending) {
    for (uint8_t i = 0; i < count; i++) {
        const bool held = ring.level(i);
        if (ring.pressed(i)) {
            pi.noteOn(base + i, 127);
            pending[i] = true;
        }
        if (pending[i] && !held) {
            pi.noteOff(base + i);
            pending[i] = false;
        }
    }
}

// Send Note-On on a latched press, Note-Off once the button is no longer held.
// Same never-miss pattern as the ring pads: pressed() is latched by the poll
// task, so even a tap between two loop passes still fires a paired On/Off here.
static void btnToNote(bool press, bool held, uint8_t note, bool& pending) {
    if (press) {
        pi.noteOn(note, 127);
        pending = true;
    }
    if (pending && !held) {
        pi.noteOff(note);
        pending = false;
    }
}

// ===========================================================================
//  Status LED. The on-board LED (GPIO47) is an addressable WS2812, so it can be
//  ANY colour -- the palette below is free to change (0..255 per channel).
//
//    * boot        -> PURPLE flash, in both modes: the deck came up.
//    * DECK_DEBUG  -> ORANGE blink: the module self-tests are running.
//    * normal      -> a PURPLE heartbeat pulse on a fixed beat (deck is alive),
//                     OVERRIDDEN by Pi-link activity: GREEN = TX (deck -> Pi),
//                     YELLOW = RX (Pi -> deck). Under a scratch the jog streams
//                     every JOG_REPORT_US so green stays solid (busy-Ethernet
//                     look), then it falls back to the purple heartbeat.
//
//  Only ONE LED, so the two directions share it: the newest event wins, and TX
//  takes it when both land in the same pass. Under a scratch that means TX
//  mostly masks RX -- unavoidable with a single LED.
//
//  CRITICAL -- rate-limit the WS2812 write. neopixelWrite() on this core is the
//  LEGACY blocking-RMT path (rmtInit/rmtWriteBlocking): each call blocks ~30us
//  with interrupt-sensitive timing. Driving it every pass of the free-running
//  loop hammers that driver -- back-to-back writes when TX/RX flip the colour
//  mask interrupts long enough to trip the INT WDT on core 1 (panic), and the
//  disrupted timing paints cyan instead of green. So we DECIDE the colour every
//  pass (cheap: just a pointer) but only PUSH it to the LED at most every
//  LED_REFRESH_MS, and only when it actually changed. A sustained scratch then
//  costs ZERO writes (colour stable = green), and transitions are capped at
//  ~50 Hz. Keep the levels low -- this LED is glaring near full scale.
// ===========================================================================
static constexpr uint32_t HEARTBEAT_MS   = 500; // DECK_DEBUG blink half-period -> 1 Hz
static constexpr uint32_t ACT_FLASH_MS   = 40;  // hold an activity colour this long
static constexpr uint32_t LED_REFRESH_MS = 20;  // min gap between RMT writes -> 50 Hz cap
static constexpr uint32_t BOOT_FLASH_MS  = 250;
static constexpr uint32_t HB_PERIOD_MS   = 1000; // normal-mode purple heartbeat period
static constexpr uint32_t HB_ON_MS       = 100;  // ... LED lit for this slice of each period

// Dim palette. Yellow is R+G balanced, orange is red-dominant, so the two stay
// clearly distinct despite both being "warm".
static constexpr uint8_t LED_OFF[3]    = {0, 0, 0};
static constexpr uint8_t LED_PURPLE[3] = {16, 0, 16};
static constexpr uint8_t LED_ORANGE[3] = {24, 5, 0};
static constexpr uint8_t LED_GREEN[3]  = {0, 16, 0};
static constexpr uint8_t LED_YELLOW[3] = {14, 14, 0};

// The LOLIN S3 Mini's on-board LED is wired RGB, but neopixelWrite() assumes a
// GRB WS2812 (it sends green first), which swaps red and green on this board --
// bench-confirmed: purple came out cyan and orange came out green. Undo it by
// handing neopixelWrite our GREEN as its "red" arg and our RED as its "green".
static void ledWrite(const uint8_t rgb[3]) {
    neopixelWrite(RGB_BUILTIN, rgb[1], rgb[0], rgb[2]); // logical (R,G,B) -> LED's RGB order
}

// Colour we WANT shown; set every pass, pushed to the LED by ledFlush(). Palette
// arrays are compared by identity, so always assign one of the LED_* arrays.
static const uint8_t* g_ledWant = LED_OFF;

// Push g_ledWant to the WS2812 -- rate-limited and change-only (see the block
// comment). This is the ONLY caller of neopixelWrite() in the running loop.
static void ledFlush() {
    static const uint8_t* shown  = nullptr;
    static uint32_t       lastMs = 0;
    if (g_ledWant == shown) return; // no change -> no write (stable colour is free)
    const uint32_t nowMs = millis();
    if ((uint32_t)(nowMs - lastMs) < LED_REFRESH_MS) return; // cap the RMT write rate
    lastMs = nowMs;
    shown  = g_ledWant;
    ledWrite(shown);
}

// Boot flash. setup() only (before the loop spins), so a blocking write is free.
static void ledBootFlash() {
    ledWrite(LED_PURPLE);
    delay(BOOT_FLASH_MS);
    ledWrite(LED_OFF);
}

static void ledPoll() {
    const uint32_t nowMs = millis();
#if DECK_DEBUG
    static uint32_t lastMs = 0;
    static bool     on     = false;
    if ((uint32_t)(nowMs - lastMs) >= HEARTBEAT_MS) { // unsigned: rollover-safe
        lastMs    = nowMs;
        on        = !on;
        g_ledWant = on ? LED_ORANGE : LED_OFF;
    }
#else
    // Purple heartbeat by default; MIDI activity overrides it for ACT_FLASH_MS.
    // Consume BOTH activity flags every pass (consume-on-read).
    static const uint8_t* actCol   = LED_OFF;
    static uint32_t       actUntil = 0;
    const bool            tx       = pi.tookTx();
    const bool            rx       = pi.tookRx();
    if (tx || rx) {
        actCol   = tx ? LED_GREEN : LED_YELLOW; // TX wins when both land together
        actUntil = nowMs + ACT_FLASH_MS;
    }
    if ((int32_t)(actUntil - nowMs) > 0) {
        g_ledWant = actCol; // an activity flash is still showing
    } else {
        g_ledWant = (nowMs % HB_PERIOD_MS) < HB_ON_MS ? LED_PURPLE : LED_OFF; // heartbeat
    }
#endif
    ledFlush(); // the single rate-limited physical write
}

// ===========================================================================
//  USB-CDC console (normal mode). USB-CDC drops anything printed before the host
//  opens the port, so the boot banner is normally lost -- print it on the CONNECT
//  EDGE instead (when a monitor actually attaches), then low-rate stats. Every
//  console write is gated on (bool)Serial == host attached, so a headless deck
//  prints nothing and the loop never blocks on a full CDC buffer. g_loops counts
//  loop() passes so we can report the free-run rate. All very low priority: it
//  self-gates to STATS_MS and touches only USB-CDC, never the Pi MIDI UART.
// ===========================================================================
static constexpr uint32_t STATS_MS = 2000;
static uint32_t           g_loops  = 0; // ++ every loop() pass; sampled for loop-Hz

static const char* resetReasonStr() {
    switch (esp_reset_reason()) {
    case ESP_RST_POWERON: return "power-on";
    case ESP_RST_SW: return "software";
    case ESP_RST_PANIC: return "PANIC";
    case ESP_RST_INT_WDT: return "INT_WDT";
    case ESP_RST_TASK_WDT: return "TASK_WDT";
    case ESP_RST_BROWNOUT: return "brownout";
    case ESP_RST_DEEPSLEEP: return "deep-sleep";
    default: return "other";
    }
}

static void printWelcome() {
    Serial.println();
    Serial.println("======================================");
    Serial.println("  TriMixxx S3 master -- normal mode");
    Serial.printf("  build : %s %s\n", __DATE__, __TIME__);
    Serial.printf("  reset : %s\n", resetReasonStr());
    Serial.printf("  heap  : %u B free\n", (unsigned)ESP.getFreeHeap());
    Serial.println("======================================");
}

static void serialPoll() {
    if (!(bool)Serial) return; // headless -- or a momentary CDC flap: skip, never block

    // Banner ONCE per boot, latched. HWCDC's "connected" flag flaps (it drops on
    // a TX timeout and re-raises on the next successful send), so edge-triggering
    // the banner reprints it every few seconds -- latch instead of edge-detect.
    static bool welcomed = false;
    if (!welcomed) {
        printWelcome();
        welcomed = true;
    }

    static uint32_t lastMs    = 0;
    static uint32_t lastLoops = 0;
    const uint32_t  nowMs     = millis();
    const uint32_t  dt        = nowMs - lastMs;
    if (dt < STATS_MS) return;
    const uint32_t loops = g_loops - lastLoops;
    lastMs               = nowMs;
    lastLoops            = g_loops;
    Serial.printf("[stat] up=%us loop=%uHz heap=%u min=%u\n", (unsigned)(nowMs / 1000),
                  (unsigned)(dt ? (uint32_t)((uint64_t)loops * 1000 / dt) : 0),
                  (unsigned)ESP.getFreeHeap(), (unsigned)ESP.getMinFreeHeap());
}
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
void loop() {
    g_loops++; // free-run pass counter, reported as loop-Hz by serialPoll()
    ledPoll(); // first, and outside the DECK_DEBUG branch: drives the LED in both modes

#if DECK_DEBUG
    // Each module self-tests; no MIDI is sent.
    ringA.debug();
    ringB.debug();
    playCue.debug();
    loopBoard.debug();
    jog.debug();
    tempo.debug();
    trackEnc.debug();
    delay(2);
    return;
#endif

    pi.poll(); // incoming MIDI -> LEDs; every pass, for the lowest LED latency

    // ---- jog rotation -> relative CC : every JOG_REPORT_US ----
    // readDelta() drains the PCNT hardware accumulator, so no tick is ever lost
    // between reports -- a longer gap just batches more ticks into the same CC.
    // jog.poll() is deliberately NOT called here: it is touch-only, and its
    // debounce counts samples, so polling it at kHz would shrink the touch
    // window from ~6ms to ~1ms. It stays on the CTRL_POLL_MS gate below.
    static uint32_t lastJogUs = 0;
    const uint32_t  nowUs     = micros();
    if ((uint32_t)(nowUs - lastJogUs) >= JOG_REPORT_US) { // unsigned: rollover-safe
        lastJogUs  = nowUs;
        int32_t jd = jog.readDelta();
        while (jd != 0) { // send full delta in <=63 chunks
            int32_t chunk = jd;
            if (chunk > 63) chunk = 63;
            if (chunk < -63) chunk = -63;
            pi.cc(midimap::CC_JOG, (uint8_t)(chunk & 0x7F)); // 7-bit two's complement
            jd -= chunk;
        }
    }

    // ---- everything below is human-scale: every CTRL_POLL_MS ----
    static uint32_t lastCtrlMs = 0;
    const uint32_t  nowMs      = millis();
    if ((uint32_t)(nowMs - lastCtrlMs) < CTRL_POLL_MS) return; // unsigned: rollover-safe
    lastCtrlMs = nowMs;

    // ---- ring pads -> MIDI notes (both rings) ----
    ringPadsToMidi(ringA, midimap::PAD_A_BASE, RING_A_NODES, padPendingOff);
    ringPadsToMidi(ringB, midimap::PAD_B_BASE, RING_B_NODES, padPendingOffB);

    // ---- jog touch -> scratch enable note (sample-count debounce: keep at 2ms) ----
    jog.poll();
    if (jog.touchPressed()) pi.noteOn(midimap::NOTE_JOG_TOUCH, 127);
    if (jog.touchReleased()) pi.noteOff(midimap::NOTE_JOG_TOUCH);

    // ---- tempo fader -> 14-bit absolute CC (MSB + LSB, only on change) ----
    // Polled by tempoPollTask on core 0; here we only consume the latched value.
    // ...or because Mixxx asked where it is (SYSEX_CMD_FADER_REPORT).
    const bool tempoReport = tempoReportRequested;
    tempoReportRequested = false;
    if (tempo.changed() || tempoReport) {
        uint16_t v = tempo.value();                        // 0..16383
        pi.cc(midimap::CC_TEMPO, (uint8_t)(v >> 7));       // high 7 bits (MSB)
        pi.cc(midimap::CC_TEMPO_LSB, (uint8_t)(v & 0x7F)); // low 7 bits (LSB)
    }

    // ---- track encoder -> relative CC (1=up / 127=down) + press note ----
    trackEnc.poll();
    int8_t ed = trackEnc.readDelta();
    for (; ed > 0; ed--) pi.cc(midimap::CC_ENCODER, 1);   // one detent up
    for (; ed < 0; ed++) pi.cc(midimap::CC_ENCODER, 127); // one detent down
    if (trackEnc.switchPressed()) pi.noteOn(midimap::NOTE_ENC_SW, 127);
    if (trackEnc.switchReleased()) pi.noteOff(midimap::NOTE_ENC_SW);

    // ---- play/cue + loop buttons -> MIDI (presses latched by the poll task:
    //      never missed; Note-Off follows the held level). LEDs come back via onMidi.
    static bool pcPend[PlayCueBoard::COUNT] = {};
    btnToNote(playCue.pressed(PlayCueBoard::PLAY), playCue.level(PlayCueBoard::PLAY),
              midimap::NOTE_PLAY, pcPend[PlayCueBoard::PLAY]);
    btnToNote(playCue.pressed(PlayCueBoard::CUE), playCue.level(PlayCueBoard::CUE),
              midimap::NOTE_CUE, pcPend[PlayCueBoard::CUE]);

    static bool lpPend[LoopBoard::COUNT] = {};
    btnToNote(loopBoard.pressed(LoopBoard::LOOP_START), loopBoard.level(LoopBoard::LOOP_START),
              midimap::NOTE_LOOP_IN, lpPend[LoopBoard::LOOP_START]);
    btnToNote(loopBoard.pressed(LoopBoard::LOOP_END), loopBoard.level(LoopBoard::LOOP_END),
              midimap::NOTE_LOOP_OUT, lpPend[LoopBoard::LOOP_END]);
    btnToNote(loopBoard.pressed(LoopBoard::RELOOP), loopBoard.level(LoopBoard::RELOOP),
              midimap::NOTE_RELOOP, lpPend[LoopBoard::RELOOP]);

    serialPoll(); // low-priority: welcome-on-connect + ~2s stats (self-gated, USB-CDC only)
}

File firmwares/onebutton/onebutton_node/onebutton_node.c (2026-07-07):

// onebutton_node.c  -  TriMixxx OneButton ring node (CH32V003F4P6)
// ---------------------------------------------------------------------------
// Cut-through UART ring relay + 2x WS2812 + 1 button, ch32v003fun bare-metal.
//
// Ring:  S3(TX) -> node1.RX ; node1.TX -> node2.RX ; ... ; node50.TX -> S3(RX)
// Whole ring is 5V. USART1: RX = PD6 (DIN), TX = PD5 (DOUT). SWIO=PD1 (leave!).
//
// Every node runs the *identical* binary. Position in the chain is discovered
// at boot (ENUM frame), so there is no per-board config.
//
// Frame formats (fixed length, terminated by an inter-frame IDLE gap):
//
//   DATA  [0]=0xA5  [1]=SEQ  [2..351]=50 slots x 7B  [352]=CRC8 (master only)
//         slot i = R0 G0 B0  R1 G1 B1  BTN     (LEDs master->node, BTN node->master)
//   ENUM  [0]=0x5A  [1]=hopcount        (node takes hop as its index, forwards +1)
//
// The node NEVER buffers the 352B frame and NEVER checks CRC. It relays each
// byte the instant it arrives, editing only the 7 bytes in its own slot. The
// master authors SEQ/CRC and verifies the echo end-to-end.
// ---------------------------------------------------------------------------
#include "ch32fun.h"
#include <stdint.h>

// ==== Pins matched to the OneButton board ==================================
#define BTN_PORT   GPIOC
#define BTN_PIN    1            // PC1: switch to GND, external 10k pull-up + 100nF (HW debounce)
#define WS_PORT    GPIOC
#define WS_PIN     0            // PC0: WS2812 data out (drives both LEDs in series)
// (bit-bang on purpose: PC0 is not an SPI MOSI pin, and refresh runs in the
//  idle gap with IRQs masked, so it's deterministic. Tune nops() on a scope.)
// ===========================================================================

#define BAUD        500000u     // 48e6/500000 = 96 exactly -> 0% baud error
#define BRR_DIV     (48000000u / BAUD)

#define FRAME_DATA  0xA5
#define FRAME_ENUM  0x5A
#define HDR         2           // [type][seq]
#define SLOT        7           // 6 LED + 1 button
#define LEVEL       0x01        // btn bit0: currently held
#define STICKY      0x02        // btn bit1: pressed since last report (latched)

// ---- shared state (ISR <-> main) ------------------------------------------
static volatile uint16_t rxpos      = 0;        // byte index in current frame
static volatile uint8_t  synced     = 1;        // 0 = lost byte alignment, wait for gap
static volatile uint8_t  frame_type = 0;
static volatile uint8_t  enumerated = 0;
static volatile uint16_t led_off    = 0xFFFF;   // my first LED byte offset
static volatile uint16_t btn_off    = 0xFFFF;   // my button byte offset
static volatile uint8_t  ledbuf[6]  = {0};      // R0 G0 B0 R1 G1 B1 (snooped)
static volatile uint8_t  btn_state  = 0;        // LEVEL|STICKY
static volatile uint8_t  refresh    = 0;        // set on DATA-frame boundary

// ---- RISC-V global interrupt enable (mstatus.MIE = bit 3) -----------------
// Plain mask/unmask (never nested in this file), used for two tiny critical
// sections: the WS2812 blast, and the btn_state read-modify-write.
static inline void irq_off(void){ __asm__ volatile ("csrci mstatus, 8"); }
static inline void irq_on (void){ __asm__ volatile ("csrsi mstatus, 8"); }

// ===========================================================================
//  THE CUT-THROUGH RELAY  -  one byte in, one byte out, no frame buffering
// ===========================================================================
void USART1_IRQHandler(void) __attribute__((interrupt));
void USART1_IRQHandler(void)
{
    uint32_t sr = USART1->STATR;

    // ---- a byte arrived (RXNE), or we overran and lost one (ORE) ----------
    if (sr & (USART_STATR_RXNE | USART_STATR_ORE)) {
        uint8_t  in  = USART1->DATAR;   // reading DATAR clears BOTH RXNE and ORE
        uint8_t  out = in;              // default: pass through unchanged
        uint16_t i   = rxpos;

        if (sr & USART_STATR_ORE) {
            // Overrun: at least one byte was missed while we were busy (e.g. the
            // masked LED blast). Our position is now meaningless, so stop
            // snooping/injecting for the rest of this frame. Still relay the
            // byte to keep the line fed; the next IDLE gap re-syncs us.
            synced = 0;
        } else if (synced) {
            if (i == 0) {
                frame_type = in;                    // decide DATA vs ENUM
            } else if (frame_type == FRAME_ENUM) {
                if (i == 1) {                        // this byte = my hop index
                    led_off    = HDR + (uint16_t)in * SLOT;
                    btn_off    = led_off + 6;
                    enumerated = 1;
                    out        = in + 1;             // hand next node its index
                }
            } else { // FRAME_DATA
                if (enumerated) {
                    if (i >= led_off && i < led_off + 6) {
                        ledbuf[i - led_off] = in;    // snoop my LED byte (still relay it)
                    } else if (i == btn_off) {
                        out = btn_state;             // inject my button
                        btn_state &= ~STICKY;        // clear latch: reported once
                    }
                }
            }
        }

        // Bounded spin: RX and TX run the same baud, so by the time a byte has
        // fully arrived the previous one has finished going out. TXE is
        // essentially always ready here; this never blocks more than a bit-time.
        while (!(USART1->STATR & USART_STATR_TXE)) { }
        USART1->DATAR = out;
        rxpos = i + 1;
        return;
    }

    // ---- inter-frame gap = frame boundary, re-arm for next frame ----------
    if (sr & USART_STATR_IDLE) {
        (void)USART1->DATAR;                         // read STATR(above)+DATAR clears IDLE
        if (synced && frame_type == FRAME_DATA && enumerated) refresh = 1;
        synced = 1;                                  // fresh frame: trust offsets again
        rxpos  = 0;
    }
}

// ===========================================================================
//  WS2812 OUTPUT  -  runs only in the idle gap, interrupts masked (see main).
//  Timing is the nop-sled validated on the bench self-test: window 0..16,
//  cliff at 17, sitting at 8; verified glitch-free to 150 C. NOPS(n) emits
//  exactly n nops via the assembler's .rept, so -Os/-flto can't retime it.
//  Order on the wire is GRB; ledbuf holds RGB, so we reorder here.
// ===========================================================================
#define WS0_HIGH  8    // "0" high  -- tuned: window 0..16, cliff at 17, sit at 8
#define WS1_HIGH  30   // "1" high  -- wide margin, kept generous
#define WS0_LOW   24   // low times are non-critical
#define WS1_LOW   18

#define NOPS_(n) __asm__ volatile (".rept " #n "\n\t nop\n\t .endr\n\t")
#define NOPS(n)  NOPS_(n)
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

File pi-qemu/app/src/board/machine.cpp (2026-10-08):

#include "board/machine.h"

#include "board/card.h"
#include "board/firmware.h"
#include "board/link.h"

#include <QDateTime>
#include <QDir>
#include <QFile>
#include <QFileInfo>
#include <QJsonDocument>
#include <QTimer>

#include <fcntl.h>

std::atomic<pid_t> g_qemuPid{0};

// The QOM paths of what QEMU's patched devices expose (qemu/trimixxx-patches.py,
// 18 and 19): the mailbox's reboot flags and the power manager's reset status.
static const char* kPropertyPath = "/machine/soc/peripherals/property";
static const char* kPowerMgtPath = "/machine/soc/peripherals/powermgt";

Machine::Machine(MachineOptions o, QObject* parent) : QObject(parent), m_o(std::move(o)) {
    connect(&m_proc, &QProcess::finished, this, &Machine::onFinished);
    connect(&m_qmp, &QLocalSocket::readyRead, this, &Machine::onQmpBytes);
}

Machine::~Machine() {
    m_stopping = true;
    if (running()) {
        m_proc.terminate();
        m_proc.waitForFinished(3000);
    }
}

QString Machine::s3Socket() const { return QDir(m_o.runDir).filePath("s3.sock"); }

bool Machine::powerOn(QString* error) {
    Card card;
    if (!card.open(m_o.card, error)) return false;
    // QEMU's SD card model only takes power-of-two sizes.
    if (qint64 n = card.size(); n & (n - 1)) {
        *error = QString("%1 is %2 bytes; an emulated SD card must be a power of two "
                         "(truncate -s 8G %1)").arg(m_o.card).arg(n);
        return false;
    }
    FirmwareOptions fo;
    fo.tryboot = m_nextTryboot;
    fo.requestedPartition = m_nextPartition;
    fo.mac = m_o.mac;
    fo.fbWidth = m_o.fbWidth, fo.fbHeight = m_o.fbHeight, fo.fbDepth = m_o.fbDepth;
    fo.dtmerge = m_o.dtmerge;
    fo.runDir = m_o.runDir;
    m_nextTryboot = false; // used once, as the firmware uses them
    m_nextPartition = 0;
    BootPlan p;
    if (!prepareBoot(card, fo, &p, error)) return false;
    for (const QString& note : p.notes) emit status(note);
    emit status(QString("booting partition %1%2").arg(p.partition).arg(fo.tryboot ? " (a trial: tryboot)" : ""));
    if (!p.skipped.isEmpty())
        emit status("not emulated, left out: " + p.skipped.join(", ") + " (the kernel uses the framebuffer)");
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

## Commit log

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2026-03-19 Route the buck and fixed pinout on ethernet and 3D model offsets
    [CDJ-MainBoard.kicad_pcb, Trimixxx_inputs_list.xlsx, hdmi.kicad_sch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]
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2026-07-08 Restructure firmwares/ + fix submodules
    - Move onebutton firmware (.c + docs) into firmwares/onebutton/, add ch32fun Makefiles
    - Add ch32fun and swio-adapter as pinned submodules (stock ch32fun no longer committed)
    - Register orphaned boards/midi-laser-pcb Keebio libs as proper submodules
    - Remove boards/TriMiXxX_Arduino_MIDI_HID
    [TriMiXxX_Arduino_MIDI_HID.kicad_pcb, TriMiXxX_Arduino_MIDI_HID.kicad_sch]
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2026-07-10 Add clang-format + cppcheck tooling and format the tree
    - .clang-format: house style (4-space, attached braces, left pointers,
    aligned declarations/assignments/comments, one-line short functions),
    tuned to match the existing hand-aligned code.
    - platformio.ini: wire `pio check` to cppcheck over src/ + lib/ only,
    with suppressions for third-party headers and the canonical Buxton
    encoder state table.
    - Apply clang-format across all src/ and lib/ sources for a clean baseline.
    - Document both in CLAUDE.md.
    [main.cpp]
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2026-07-10 Tempo fader: 14-bit output, invert, and noise filtering
    - 14-bit high-res output (0..16383, 8192 center) sent as a standard MIDI CC
    MSB/LSB pair: CC_TEMPO (18) + CC_TEMPO_LSB (50 = 18+32). Documented in MidiMap.
    - Fader wired inverted on this deck -> invert=true.
    - Split EMA: heavy smoothing on the ~DC center tap, lighter on the wiper;
    hysteresis raised to 16 units to sit above idle ADC noise (still ~1024 steps).
    - main.cpp: swap the ringA health log for a tempo calibration readout
    (center/wiper/offset/value); add TempoFader center()/wiper()/offset() accessors.
    span still TBD from bench calibration.
    [main.cpp]
2026-07-10 Tempo fader: asymmetric per-side span calibration
    The center tap sits off electrical mid, so travel is asymmetric (bench-measured
    offsets: top -1944, bottom +2150). Scale each direction by its own half-span
    (spanToMax / spanToMin) so both extremes reach the rails, center stays exact,
    and there is no dead travel. Overshoot past a span is clamped at the rail.
    [main.cpp]
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2026-07-12 OneButtonRing: fix baud to 500k, robust enumeration + ring recovery
    - Baud 1000000 -> 500000 to match the CH32V003 node firmware (they were 2x
    apart, so the ring never communicated). Fixed at both ring ctors in main.cpp
    and the OneButtonRing default.
    - enumerateUntilStable(): keep enumerating until two SUCCESSIVE attempts report
    the same non-zero node count, rejecting a mid-boot/settling ring. If the RX is
    silent (nothing returned), retry every 100ms forever -- so a disconnected
    return line parks in enumeration until reconnected. The task blocks here at
    boot before sending any DATA.
    - DATA loop re-enumerates on EITHER trigger: FAIL_REENUM (10) consecutive bad
    frames, or no vali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
    [main.cpp]
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2026-07-13 Add PlayCueBoard + LoopBoard drivers with ISR-latched presses
    Two self-contained drivers for the deck's direct-GPIO boards, pins baked into
    the PCB (verified on the bench). API mirrors OneButtonRing (level/pressed/setLed):
    - Presses are edge-latched by a per-button FALLING-edge GPIO ISR (STICKY-style),
    so a tap shorter than a loop pass is never missed. pressed() consumes the latch
    under a portMUX critical section (atomic vs the ISR); level() is the current
    HW-debounced state. No software debounce -- the 100nF cap + Schmitt input clean
    the edge in hardware.
    - ISRs install on core 1 (attached from setup()), opposite the ring task's core 0.
    - LED polarity handled internally: play/cue M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
    [main.cpp]
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2026-07-13 Per-module debug() self-tests behind one DECK_DEBUG toggle; boards to poll+latch
    - Boards: replace the GPIO edge-ISR latch with a periodic poll+debounce+latch
    driven by a ~2ms task (buttonPollTask) on core 1. Polling is the robust switch
    approach (Ganssle) and avoids the ESP32 edge-interrupt double-fire that a slow
    RC-debounced edge can provoke; the STICKY latch still means no press is missed.
    - Add a debug() self-test to every driver (OneButtonRing railroad+magenta,
    PlayCue/Loop LED flash+solid with reloop lighting both, Jog/Tempo/TrackEncoder
    serial reports). main gains a single DECK_DEBUG toggle that runs them all
    instead of the MIDI loop, replacing the old RING_DEBUG + in-mai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
    [main.cpp]
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2026-07-13 Mixxx mapping: fix jog scratch/direction, widen tempo, track the XML
    - jog: negate the tick delta so scratch and pitch-bend follow platter rotation
    - jog touch: use a hardcoded deck number instead of script.deckFromGroup, so
    scratch no longer depends on Mixxx's bundled common-controller-scripts.js
    (its absence on the Pi silently threw and killed jog-touch); drop that
    scriptfile from the mapping
    - tempo: widen the pitch range to +/-16% from init (stock was +/-8%)
    - track TriMixxx.midi.xml: the monorepo *.xml ignore was swallowing the
    controller mapping; add mixxx/.gitignore to un-ignore Mixxx XML source
    [TriMixxx.scripts.js]
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2026-07-14 Move Mixxx config out of the firmware into repo-root mixxx_config/
    The bridge, controller mapping, skin, systemd unit, Pi config and bench
    tools are Pi/Mixxx-side, not firmware -- relocate the whole mixxx/ folder to
    the monorepo root as mixxx_config/ (git mv, history preserved).
    Fix the references the move breaks: the firmware CLAUDE.md mapping paths and
    the README's relative link to lib/PiLink/MidiMap.hpp.
    [mixxx.cfg]
2026-07-15 mixxx: fix native loop control, quantize by default, rework deck skin
    Controller mapping (TriMixxx.midi.xml + .scripts.js):
    - Map loop_in/loop_out release (Note-Off 0x80), not just press. Mixxx's loop
    slots are held-state (release ends adjust mode); press-only left the control
    stuck at 1 so the jog dragged the loop points around ("banana").
    - Enable quantize by default in init() so loop in/out + cue/hotcues snap to beats.
    - Auto-close the library and return to the waveform on track load.
    Skin (TriMixxx_skin/):
    - Draw hotcue/cue/loop markers on the waveform + overview; the loop is a bright
    orange window while looping, dim amber when saved-but-off, bright on reloop.
    - Fix set-hotcue / a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
    [mixxx.cfg]
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2026-07-16 trimixxx-midi: SysEx RGB LED + remote reset, harden MIDI parser
    Adds SysEx receive to PiLink and two commands on top of it, plus a real
    fix to the incoming MIDI parser.
    Parser hardening (a live bug, not a precaution): the old code cleared
    running status on any byte >= 0xF0, so a single MIDI clock byte from
    Mixxx landing between the data bytes of a message would corrupt it.
    System Real-Time (F8..FF) is now ignored without disturbing the message
    or SysEx in progress, per the MIDI spec. 0xFF is treated as ignorable
    rather than System Reset because ttymidi reserves it for its own comment
    escape and never forwards a reset.
    SysEx commands (F0 7D <cmd> ... F7, 0x7D = reserved non-commercial ID):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
    [main.cpp]
2026-07-17 trimixxx-midi: free-run loop(), report the jog every 300us
    loop() had a blanket delay(2), capping every control -- the jog included --
    at 500Hz with ~2ms latency and tick-quantized jitter. No ticks were lost (PCNT
    accumulates in hardware), but the scratch data Mixxx saw was stale.
    Drop the delay and gate each job on its own deadline:
    - jog rotation: micros() deadline, JOG_REPORT_US=300 (3.3kHz). A jog CC is 3
    bytes (ttymidi decodes no running status) => ~10kB/s ~= 87% of the 115200 8N1
    link; 260us would be 100%. The comment records ~400us (~65%) as the fallback
    if the 128-byte TX FIFO ever fills and stalls the loop.
    - pads, jog touch, tempo, encoder, buttons: unchanged, on a 2ms milli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
    [main.cpp]
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2026-07-17 mixxx_config: lint the controller scripts with ESLint
    Rules and globals are mirrored from Mixxx's own eslint.config.cjs -- these
    are Mixxx controller scripts, so upstream's house style is the one to match.
    Its typescript-eslint/jsdoc/diff plugins are dropped: they exist to police a
    200-mapping tree and are dead weight for two files.
    No Prettier, deliberately. It collapses the aligned `=` columns used across
    this codebase and has no option to preserve them; ESLint was upstream's
    choice for controller scripts and leaves them alone (note the absence of
    no-multi-spaces). `npm run format` is layout-only so it can never touch code,
    with `npm run fix` kept separate for the var -> const/let sweep.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
    [PiMidiDaemon.scripts.js, TriMixxx.scripts.js]
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2026-07-17 trimixxx-midi: status LED, USB console, tempo ADC on its own core-0 task
    Status LED (on-board WS2812): purple heartbeat when idle, green=TX /
    yellow=RX on Pi-link activity, orange in DECK_DEBUG, purple boot flash. The
    WS2812 write is rate-limited to ~50Hz and change-only -- driving the legacy
    blocking-RMT neopixelWrite every free-run pass tripped the core-1 INT WDT. R and
    G are swapped in one helper because this board's LED is wired RGB, not GRB.
    USB-CDC console (normal mode): a welcome banner latched once per boot (HWCDC's
    connected flag flaps, so edge-triggering reprinted it) plus ~2s stats (uptime,
    loop-Hz, heap). All gated on (bool)Serial, so a headless deck stays silent and
    never block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
    [main.cpp]
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2026-07-18 Add notes and update schematic for main board ESD Schotky fix jog tch
    [midi_s3_mini.kicad_sch]
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2026-07-29 trimixxx-midi: add ring B on UART2 (self-test + full MIDI)
    Second OneButton ring on UART2 (Serial2, IO13 TX / IO12 RX), mirroring ring A:
    its own core-0 task, self-test in DECK_DEBUG, and on the MIDI bus in normal mode --
    pad presses -> Note-On/Off at PAD_B_BASE (notes 67+), Note-On velocity -> white LED,
    and RGB via a new SysEx cmd 0x03. Pad->note and ring-LED SysEx are factored into
    shared helpers (ringPadsToMidi / applyRingLed) so both rings run the same code, and
    PAD_BASE/PAD_COUNT are renamed to PAD_A_BASE/PAD_A_COUNT to mirror B.
    Also moves the jog-touch pin 14 -> 11 (the original IO14 was ESD-damaged). Mixxx
    mapping still needs the matching ring-B addresses (notes 67+, SysEx 0x03).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
    [main.cpp]
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2026-07-29 mixxx: map ring A/B buttons with coloured LED indicators
    Ring A/B stop being a play-position indicator and become the deck's function
    buttons, wired in TriMixxx.midi.xml + .scripts.js:
    A1 tempo range (cycle +/-6/10/16/Wide), A2 master tempo (keylock), A3/A4 8/4-beat
    loop, A5/A6 loop double/halve, A7 back (library view/focus); B1-B4 hotcues,
    B5 slip, B6 key-sync (output-only, LAN later).
    LED indicators are driven as COLOURED SysEx from the script (ledConnect/paintAll),
    not Note-On outputs: tempo-range green/yellow/orange/red by range, keylock red,
    loops orange, back dim white, slip solid->flashing red, hotcues in their own Mixxx
    colour. The startup intro now ends by painting the real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
    [TriMixxx.scripts.js]
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2026-07-30 mixxx: hotcue colour sequence + encoder waveform zoom
    - Hotcues are script-bound (TriMixxx.hotcue): creating one on an empty slot
    colours it from a fixed sequence (red/yellow/green/blue/magenta), while a
    loaded track's own hotcue colours are left untouched. LED shows hotcue_N_color.
    - Track encoder in the playing view (library hidden) now zooms the waveform
    (waveform_zoom_up/down) instead of only browsing.
    [TriMixxx.scripts.js]
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2026-07-30 mixxx_config: enable the ProLink sidebar feature on the deck
    [Library]/ShowProLinkLibrary defaults to off in the code, since binding a
    port and watching a network is not something to start doing to a user who
    has not asked for it. The deck has asked, so turn it on here -- this file
    is deployed to ~/.mixxx by mixxx_config/upload.sh, which makes enabling
    it a versioned one-liner rather than an undocumented ssh edit.
    Also bumps the mixxx submodule to the discovery increment: the Kaitai
    DJ-Link parser, ProLinkDevice/ProLinkDiscovery/ProLinkNetworkService on a
    dedicated network thread, and ProLinkFeature listing players in the
    sidebar.
    The feature is passive -- it transmits nothing on any Pro D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
    [mixxx.cfg]
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2026-07-30 mixxx_config: content-width library sidebar, and ship the UI font with it
    Sidebar column. Width is no longer the flat 240: `p` (Preferred) lets it ask
    for the sizeHint the fork now reports, capped at 341 = 1024/3, past which it
    would be eating the track list to show folder names and scrolls sideways
    instead. The search box is `i` (Ignored) so a wide-ish line edit is not what
    decides how wide the MENU is.
    Both scrollbars go to zero size rather than being switched off by policy.
    Qt derives scroll RANGE from content, not from whether the bar is drawn, so
    a 0px bar still scrolls under program control -- and it has to, because the
    sidebar now scrolls itself sideways to follow the selection.
    Scro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
    [mixxx.cfg]
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2026-07-30 config: Camelot key notation, 6% default pitch range, fix cfg deploy order
    Key notation goes to Lancelot, which is Mixxx's name for Camelot. That is
    also what makes Key *sorting* come out 1A, 1B, 2A rather than 1A, 10A,
    11A: the sort is a CASE over key_id built from the notation preference, so
    the display format and the sort order are the same setting.
    Default pitch range to 6%. It lives in the controller script, not the
    config: TriMixxx.RATE_RANGE is written to the deck at boot and overrode
    whatever the preference said.
    And upload.sh copied mixxx.cfg *before* restarting Mixxx, so the outgoing
    instance wrote its own state over ours on the way out and the new one read
    that. Stop first, then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
    [mixxx.cfg]
2026-07-30 Library sort on A2, and a condensed header
    A2 does the job of whatever is on screen: keylock over the deck, SORT over
    the library, where there is no track to lock the key of and no other way
    to sort without a keyboard. Press cycles BPM, Genre, Artist, Key, each
    ascending then descending; hold clears it. The LED is the column's colour,
    dim ascending and bright descending, off when nothing is sorted. A clear
    remembers where the cycle was, so pressing again resumes rather than
    starting over.
    Re-applying the sort when the library reappears is not belt and braces:
    moving between features rebuilds the track model and the sort goes with
    it, so the light would otherwise claim a sort no longer in ef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
    [TriMixxx.scripts.js]
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2026-07-30 Sort: drive the toggle Mixxx actually has, and let go on navigation
    **sort_column is not a setter.** It forwards straight to
    sort_column_toggle, which flips the direction when the id matches the
    column already sorted on and forces *ascending* when it does not. Setting
    sort_order alongside it never survived: a new column reset it, the same
    column ignored it. That is why the Rekordbox USB behaved differently from
    everywhere else -- its view already had an Artist sort running, so the ids
    collided differently there than on a freshly opened list. The cycle now
    drives the toggle and reads sort_order back rather than assuming a write
    landed.
    And moving to another section drops the sort, per the ne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
    [TriMixxx.scripts.js]
2026-07-30 Sort: hold no longer cycles, and focus leaving the list ends the sort
    **A hold cycled before it cleared.** Acting on the press gave instant
    feedback but made a long press impossible to distinguish from a short one
    until after it had already done the short one's job. Nothing happens on the
    press now; the release cycles and the hold timer clears. The press-side
    version only existed because the release was not reaching the script at
    all, and that turned out to be the unmapped B6 note rather than anything
    about timing.
    **Focus returning to the tree ends the sort**, rather than waiting for a
    section to be chosen. Scrolling the sidebar left the button lit over a list
    the DJ had already left.
    **A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
    [TriMixxx.scripts.js]
2026-07-30 Sort: set the column, then the direction
    Direction worked on the Rekordbox list and not on the local one because
    the two-toggle approach depended on the *global* sort_column matching what
    the visible model is actually sorted by, and after switching between two
    lists with different sorts it does not: the toggle then flipped where it
    should have selected, and the compensating second hit flipped it back.
    sort_column still is not a setter -- it forwards to sort_column_toggle,
    which decides a direction of its own -- so that decision has to be
    overwritten afterwards rather than before. Writing sort_order last works
    because WTrackTableView watches that control in its own right and re-sorts
    on any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
    [TriMixxx.scripts.js]
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2026-08-01 launcher: pi-midi-daemon becomes the deck's launch manager
    Something has to decide what the deck IS at boot, and the decision is made
    by holding a button, which arrives as MIDI. This daemon already spoke MIDI,
    already ran as root, and its readiness gate was already what releases
    getty@tty1 and therefore the app -- one step from being the launch manager,
    so it is one. Renamed with it; the virtual MIDI port keeps the old name
    because mixxx.cfg binds controller mappings by device name and renaming it
    would silently orphan the skin's power menu.
    Modes are mixxx, doom and debug, written to /run/trimixxx/mode -- tmpfs on
    purpose, so a wedged Doom or a botched experiment cannot survive a power
    cyc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
    [PiMidiDaemon.scripts.js]
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2026-08-03 deck: the skin and the mapping drive the browser
    skin.xml swaps the sidebar-and-table for a single <DeckBrowser>, hides the
    header while browsing so the browser owns all 600 px, and drops the POWER
    button -- it is a root-menu row now, raising the same confirmation overlay.
    TriMixxx.scripts.js stops reasoning about panes. There is one focus and one
    selection, so browse/push/back become [Browser] move/select/back, and SORT's
    short and long presses become sort_menu and info_toggle. The old sort cycle
    and its LED bookkeeping go with them.
    dj-usb writes the volume label at mount time. It already runs blkid for the
    filesystem type, and the slot a stick lands in says nothing about which stick
    it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
    [TriMixxx.scripts.js]
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2026-08-03 deck: long-press BACK returns to the deck, keeping your place
    Short BACK still pops one level. Held past LONG_PRESS_MS it leaves the browser
    entirely -- which is the one a DJ actually reaches for mid-set: four levels
    into a stick, the track running out, wanting the waveform without losing where
    they were. Nothing tells the browser to unwind, so the menu stack survives and
    re-opening lands exactly where it left.
    Opening still acts on the PRESS rather than waiting for the release: there is
    no second meaning to disambiguate, and making someone hold a button to see the
    library would be absurd.
    Plus the stylesheet for the new info panel.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
    [TriMixxx.scripts.js]
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2026-08-03 config: the sidebar features are off, and were costing us the network
    The browser replaced the sidebar, so Banshee, Rekordbox, Traktor and
    ProLink have had nowhere to draw for a while. ProLink was not merely
    idle: enabling it built a second ProLinkNetworkService, which bound the
    same sockets and entered the same claim chain as the browser's, so the
    deck competed with itself for a player number and one of the two ended up
    unable to serve or be browsed.
    [mixxx.cfg]
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2026-08-03 A dead LED must not take the whole mapping down with it
    engine.makeConnection returns undefined for a control that does not
    exist, ledConnect stored it anyway, and paintAll then dereferenced it --
    which Mixxx reports as "the mapping for your controller is not working
    properly" and answers by refusing to run the script at all.
    That is every button on the deck going dead, mid-set, because one LED
    was wired to a control name that was not there. Seen once on the deck, as
    a modal dialog over the browser.
    Failed connections are no longer stored, the name is printed, and
    paintAll guards anyway: it runs from a timer callback, where an exception
    is one the script cannot recover from.
    Co-Authored-B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
    [TriMixxx.scripts.js]
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2026-08-03 config: no key or loudness analysis, and the logs rotate
    The key comes from rekordbox, is what the browser sorts and colours by,
    and is what every CDJ on the network is showing. Detecting it again
    costs a full decode of the track on a Pi to arrive at a second opinion
    nothing reads. Same for loudness: there is no ReplayGain in a rekordbox
    export and no fader on this deck that uses one.
    The logs rotate on each start, keeping one previous run. --log-level
    debug writes tens of megabytes an hour onto the SD card and stderr.log
    had reached 200 MB before anyone looked. Rotating at startup rather than
    trimming on a timer keeps the log covering a crash whole, which is
    exactly when it is worth readin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
    [mixxx.cfg]
2026-08-04 The third hardware round: four faults that were about time
    Two races and two stale answers nobody had asked to be refreshed. Each looked
    like a feature that had simply not been finished, and none of them was.
    The deck header's artwork appeared on the second load and never the first. The
    phase meter marched on for a CDJ that had stopped. A CDJ could not take tempo
    master back, because our handover named no successor -- the grant is byte 0x9f
    of the holder's status, not the absence of byte 0x9e, and the same file
    implements that rule correctly for the deck *asking*. A protocol rule learned
    in one direction is worth checking in the other.
    And the sort menu had stopped answering touch entirely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
    [TriMixxx.scripts.js]
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2026-08-11 An input on the deck, and the manual that says what will arrive on it
    The Xone:92 is a purely additive send/return -- it has no wet/dry control
    anywhere, so the main mix is a plain sum and bringing a return up never takes
    the dry away. That is why the Boss pedal doubles the track: through INPUT A it
    returns dry + wet, and the mixer adds a dry it is already carrying. The fix
    has to be at the device, and the device is now this deck.
    docs/xone92-send-return.md is read off the Mk2 user guide, including the block
    diagram, which answers two things the prose does not: the Xone:VCF filters sit
    after the aux taps, so a filter sweep never reaches the send, and there is no
    aux master level at all -- t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
    [mixxx.cfg]
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2026-08-11 Four things have to be true for the pedal bus to make a sound
    None of them Mixxx does on its own, and every one fails silently:
    main_mix is not persisted and EngineAux's constructor turns it off on every
    start, so mixxx.cfg cannot carry it. The effect slot has to be enabled, and
    StandardEffectChain is the only chain type that does not enable its slots
    after loading -- effects.xml cannot carry that either, EffectPreset has no
    enabled field. An effect has to be loaded WITH its parameters, and a preset
    whose <Parameters> list is empty maps none at all, because loadEffectInner
    clears m_loadedParameters and then fills it from the preset: empty in, empty
    out, and a reverb sitting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
    [TriMixxx.scripts.js]
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
